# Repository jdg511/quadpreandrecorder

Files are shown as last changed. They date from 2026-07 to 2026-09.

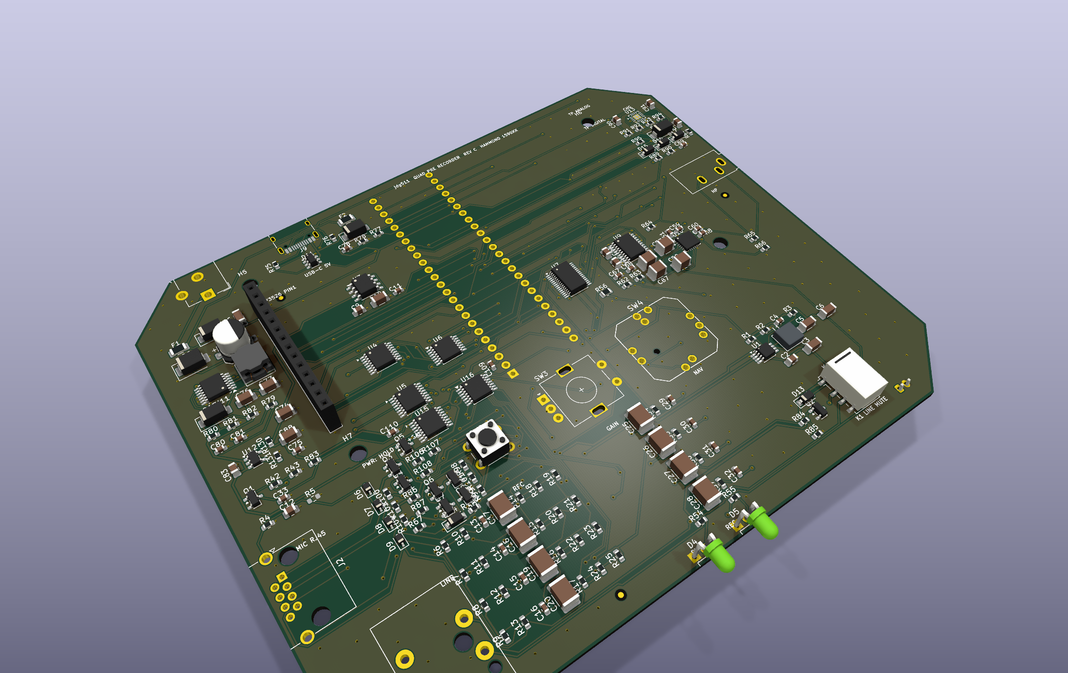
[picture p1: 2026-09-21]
hardware/exports/QuadPreRecorder-isometric.png

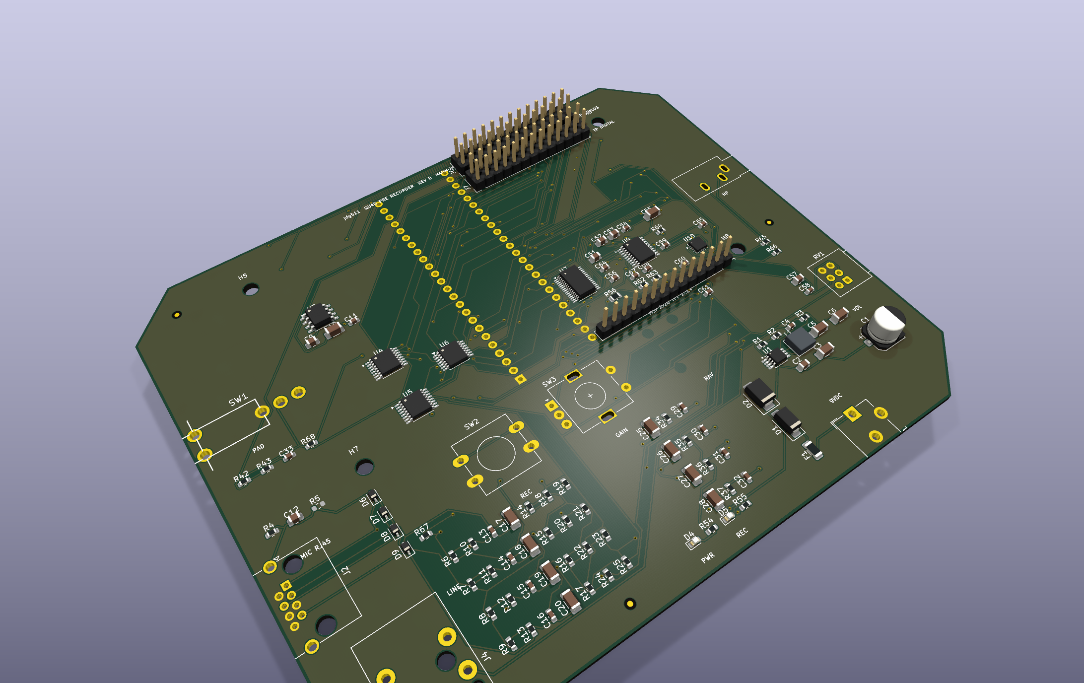
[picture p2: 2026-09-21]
hardware/review_outputs/noSW4-iso.png

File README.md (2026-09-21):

# Quad Preamp and Recorder

Compact four-channel ambisonic electret preamp, 192 kHz/24-bit recorder,
real-time binaural monitor, and touchscreen controller.

The hardware is derived from
[jdg511/Quadelectretpre](https://github.com/jdg511/Quadelectretpre) and is
redesigned as a mixed-signal two-layer PCB in a Hammond 1590XX enclosure.

## Project layout

- `hardware/` — KiCad project, fabrication package, design notes, and reviews.
- `tools/` — reproducible schematic, PCB, and fabrication-generation scripts.
- `firmware/` — recorder/DSP interface, pin map, file-naming rules, and
  implementation requirements. Production firmware is not included in Rev A.

## Revision status

The current design is **Rev C** (2026-09-08), routed for the compact
**Hammond 1590XX** (138 x 114 mm board, 145 x 121 x 39 mm enclosure). Rev C
takes the Rev B board and:

- adds a **USB-C** receptacle (J9) on the rear wall — 5 V power from any
  charger, power bank or computer port (TPS61175 boost + ADP7142 low-noise
  LDO make the 9 V analog rail), SD-card file transfer (MTP) and firmware
  updates; the 9 V barrel (J1) stays as an alternative input and moved to the
  rear-left wall;
- mutes the 1/4-inch line out with a signal relay (K1) while a computer is
  attached (ground-loop protection, on-screen warning with override);
- replaces the headphone pot with a **TPA6130A2** I2C-volume headphone amp
  (encoder / touchscreen control) and the pad toggle with a GPIO-driven
  level shifter (pad is a touchscreen control);
- changes the display to the LCDWiki **MSP3526** 3.5-inch IPS module with
  FT6336U **capacitive** touch (the MSP3520 named in Rev B is resistive).
- adds an internal **LiPo battery** (5000 mAh, 6-7 h) with a BQ24074 USB
  charger and a two-button soft-power gesture (hold RECORD + encoder push).

Walls: rear = SD slot + 9 V + USB-C, left = mic RJ45 (Amphenol RJHSE-5380),
right = headphones, front = line out; lid = display, record button, gain
encoder. Rev C3 (2026-09-12) removed the J6/J7 test headers (probe at
component pads or the TP3-TP14 pads), moved to a 4-layer SIG/GND/GND/SIG
stack, and made the mic input switchable from the screen: electret bias
off / 5 V / 9 V (one setting for all four channels) and, with the bias off,
the four RJ45 pairs become true balanced inputs for dynamic microphones
(two-op-amp instrumentation stage, +20.1 dB, SPICE-checked CMRR 58-67 dB
worst case across the audio band). The 9 V analog LDO is an ADP7142
(the TPS7A4701 it replaces had no distributor depth) and every BOM line
was re-checked for stock and price the same day. See
`hardware/reviews/audio-rules-check-revC3-fixes.md`, `hardware/mechanical.md`,
`hardware/connector-pinout.md` and `firmware/docs/REV-C-CONTROL-MODEL.md`.

ERC is clean and DRC (`--all-track-errors --schematic-parity
--severity-error`) reports 0 violations, 0 unconnected pads, 0 parity issues
on the routed board. The Gerbers, drills, BOM, placement CSVs, STEP and PDFs
in `hardware/manufacturing/` are regenerated from it
(`QuadPreRecorder-RevC-PCBWay-handoff.zip`). Rev B outputs are archived in
`hardware/manufacturing/revb-archive/`.

Still a human check before ordering: the physical Hammond 1590XX fit (wall
cutouts, button/shaft reach, the purchased MSP3526 module) — see
`hardware/enclosure-1590XX-desk-study.md` and
`hardware/reviews/rev-c-preorder-review.md`.

This is still new mixed-signal hardware, not a bench-proven production
revision. Read the prototype confirmations in `hardware/requirements.md` and
the order/bring-up notes in `hardware/manufacturing/README.md` before ordering.

## Rebuild

- `tools/route_pcb.ps1` regenerates the schematic/footprints/placement, runs
  Freerouting 1.9.0 (`tools/cache/freerouting19.jar`, single-threaded — the
  2.2.4 jar drops nets from its session export on this board), imports the
  route, adds the GND pours, and checks DRC. Allow ~35-60 minutes.
- `python tools/build_manufacturing.py` regenerates the complete PCBWay handoff
  with KiCad 10's command-line tools.

The checked-in routed board is the release artifact; rerouting is not required
to order it.

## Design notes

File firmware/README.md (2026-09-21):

# QuadPreRecorder firmware

**Illicit Apothecary** — firmware for the four-channel ambisonic electret
preamp and 192 kHz recorder.

Four electret capsules in a vertical tetrahedron → OPA1654 preamps → PCM1864
ADC → Teensy 4.1 → four mono 24-bit WAV files on microSD, plus a real-time
binaural monitor out of a PCM5102A.

---

## If you have never touched this before, read this bit

There are two things in this folder:

1. **The firmware** — C++ that runs on the Teensy 4.1 on your board.
2. **A simulator** — Python that runs on your computer and lets you *hear* the
   binaural monitor before the board exists.

You do not need to understand the C++ to use either one.

### Hearing the monitor today, with no hardware

```
cd sim
python3 simulate_binaural.py --scene orbit --out orbit.wav
```

Put on headphones and play `orbit.wav`. A click train circles your head twice.
That is the exact decode and HRTF maths the Teensy will run — same
coefficients, same sample rates. If you want to change how it sounds, change
it here first, where you get an answer in half a second instead of a reflash.

Other scenes: `--scene flyover`, `--scene corners`, `--scene static`.

### Running the firmware without a board

```
cd test/host
python3 run_tests.py
```

This compiles the **real firmware source** — the DSP and the recorder,
unmodified — for your computer and runs it. It checks that the monitor DSP
produces the same audio as the Python model (sample for sample), and that the
four-stream recorder survives a simulated microSD stall without losing
sample-alignment between the channels. See [test/README.md](test/README.md).

It cannot test anything electrical. That is what `bringup/` is for.

### Putting firmware on the board

Install [VS Code](https://code.visualstudio.com/) and the **PlatformIO IDE**
extension, then open this folder. The blue bar at the bottom has an
environment picker and an upload arrow. Pick an environment, press the arrow.

From a terminal instead:

```
pio run -e app -t upload      # the real firmware
pio device monitor            # watch what it says
```

**On a brand new board, do not flash `app` first.** Flash the bring-up tests
in order — `t01_power`, `t02_i2c`, `t03_controls`, `t04_sdbench`,
`t05_display`, `t06_audio` — and read [docs/BRINGUP.md](docs/BRINGUP.md).
Each test proves one subsystem and tells you, in plain language, which
component to look at when it fails. Debugging a bad solder joint through the
full firmware is miserable; debugging it through a fifty-line test is not.

---

## Environments

| Environment | What it is |
|---|---|
| `app` | The firmware. 192 kHz, four channels, dual-line I2S. |
| `app_96k_tdm` | Same firmware at 96 kHz over single-line TDM. Fallback if the 192 kHz path misbehaves on real silicon. |
| `t01_power` | Boots, blinks, checks every control pin's idle level. |
| `t02_i2c` | Scans I2C, configures the PCM1864, verifies registers. |
| `t03_controls` | Button, encoder direction and detents, pad switch. |
| `t04_sdbench` | **Run this before trusting any card.** Sustained four-stream write test with worst-case stall reporting. |
| `t05_display` | TFT colour/orientation, touch calibration targets. |
| `t06_audio` | Clocks, ADC lock, live four-channel levels, test tone, live monitor. |

## Layout

```
platformio.ini          build configuration, one environment per target
src/main.cpp            the application
bringup/                six standalone hardware tests
lib/qpr_board/          pin map (from the netlist) and build-time config
lib/qpr_pcm1864/        PCM1864 ADC driver
lib/qpr_sai/            SAI1 four-channel capture, SAI2 monitor output
lib/qpr_recorder/       four-stream WAV writer
lib/qpr_dsp/            decimator, ambisonic decode, binaural render, meters
lib/qpr_dsp/qpr_coeffs.h  GENERATED — do not edit, run sim/build_hrtf.py
lib/qpr_ui/             display, touch, front-panel controls
sim/                    the Python simulator and coefficient generator
test/host/              host test harness: runs the real firmware natively
docs/                   bring-up runbook, architecture, calibration
```

## Using it

**Front panel (Rev C board — see `docs/REV-C-CONTROL-MODEL.md`)**

- **RECORD button** — short press starts/stops. Long press (when stopped)
  clears the meters.
- **Encoder** — turn for gain, 1 dB per detent, all four channels together.
  By default that is all it does; Settings > Encoder can also enable
  **HP volume** and **Line trim** modes, which a short press then cycles
  through (long press = back to gain). Turning HP volume below the bottom
  step powers the headphone amp down (HP icon shows OFF).
- **PAD** — on-screen toggle, −9.7 dB ahead of the preamps (Rev C removed the
  panel switch). Folded into the displayed total gain and applied before the
  outputs un-mute at boot.
- **Touchscreen** — RECORD/STOP, HP on/off + volume, output trim ±, PAD,
  settings. Tapping the meters clears the peak holds.
- **Power** — on battery, hold RECORD and the encoder push together for
  2 s to switch on or off. Plugging in USB-C or the 9 V adapter switches it
  on by itself (the combo then puts it in standby). The screen shows the
  battery gauge, a plug when external power is present and a bolt while the
  internal LiPo is charging (USB only; about 7 h from empty).
- **USB-C** — powers the unit from any 5 V source, exposes the SD card to a
  computer (MTP) and takes firmware updates. While a *computer* is attached
  the 1/4-inch line out is muted by relay K1 and a banner explains why
  (ground loop); tap it to override. Chargers and power banks never mute.

**Both outputs are binaural.** There is one DSP chain and one DAC; the signal
splits in the analog domain after the reconstruction filter — one copy through
the mute relay to the 1/4 inch line jack, the other into the TPA6130A2
headphone amplifier (I2C volume, -59.5..+4 dB) and out the 1/8 inch jack. The
`OUT` trim on screen is digital and therefore moves both; HP volume moves only
the headphones. Press `o` on the serial console for a 1 kHz reference tone at
a known voltage to set line levels by.

**Serial console** (115200 baud) has everything the panel does, plus `s` for
a full status dump and `c` for the ADC's own view of the clocks. Press `?`.

**Files** land on the card as `FLU001.WAV`, `FRD001.WAV`, `BLD001.WAV`,
`BRU001.WAV` — one take, four mono 24-bit files at the capture rate. The next
take number is one higher than the highest number found on *any* of the four
prefixes, so an interrupted set can never be overwritten.

## Rev C3 hardware notes

The PCM1864's MICBIAS pin (5) is left unconnected and
its 1 uF cap is gone (capsules are biased from +9V_MIC). The driver should
power the mic bias down: page 3, register 0x15 (MIC_BIAS_CTRL), PDZ bit = 0.

## Mic mode (Rev C3, 2026-09-12): bias off / 5 V / 9 V and balanced inputs

Three Teensy GPIOs, all OUTPUT, all LOW at boot (the board defaults are
chosen so a Teensy that has not booted yet is safe):

| Pin | Net | High means |
|---:|---|---|
| 0 | MIC5_CTRL | +5V rail onto the mic bias filter (about 4.7 V at the capsules) |
| 1 | MIC9_CTRL | +9V rail onto the mic bias filter (9 V at the capsules) |
| 41 | COLD_CTRL | cold legs released into the differential stage (dynamic / balanced mode) |

The bias is one setting for all four channels. Settings > Microphone offers
exactly three choices and the firmware must drive the pins as a set:

| Setting | MIC5_CTRL | MIC9_CTRL | COLD_CTRL | PAD |
|---|---|---|---|---|
| Electret 9 V (default) | 0 | 1 | 0 | allowed |
| Electret 5 V | 1 | 0 | 0 | allowed |
| Dynamic (bias off, balanced) | 0 | 0 | 1 | forced OFF, greyed out |

Rules the firmware has to keep:

* Never set MIC5_CTRL and MIC9_CTRL high together (D24 would only protect
  the +5V rail; the 5 V FET would fight the 9 V one). Drive the new state
  as: both bias pins low, wait 50 ms, then raise the wanted one.
* Never set COLD_CTRL high while a bias pin is high, and never raise a bias
  pin while COLD_CTRL is high. Order when going to Dynamic: bias pins low,
  wait 200 ms for C66 (100 uF) to bleed through R104, then COLD_CTRL high.
  Order when leaving Dynamic: COLD_CTRL low first, wait 20 ms, then bias.
* The pad (Q1 / PAD_CTRL) only attenuates the hot leg. In Dynamic mode the
  cold leg is live, so an engaged pad would unbalance the pair by 9.7 dB
  and wreck the CMRR: force PAD off and disable the control while Dynamic
  is selected. Restore the user's pad choice when leaving Dynamic.
* Dynamic mics are 20-30 dB quieter than the electret capsules. Offer the
  gain range with an extra +20 dB of PGA (PCM1864 page 0, 0x01-0x04) in
  Dynamic mode and remember the two gain settings separately.
* Mute the outputs (DAC_MUTE, HP amp) for 300 ms around any mode change;
  the 4.7 uF input caps re-settle when the cold legs are switched.
* Store the mode in EEPROM with the other settings and re-apply it in the
  same order at boot, after the ADC is configured and before un-muting.

## The numbers that matter

| | |
|---|---|
| Capture | 192 kHz, 24-bit, 4 simultaneous channels |
| File payload | 2.304 MB/s total (576 kB/s per channel) |
| SD buffer slack | 128 ms per channel (3 × 24 KiB rings) |
| Monitor | 48 kHz stereo, exactly capture ÷ 4, no resampling |
| Binaural | 8 FIRs × 128 taps, ~25% of one Cortex-M7 |
| Clock source | one 786.432 MHz audio PLL feeds both SAI blocks |
| Gain range | −2 dB to +52 dB total (pad in), +8 to +52 dB (pad out); Dynamic mode adds +20 dB of PGA |

The capture and monitor rates come from the same PLL with integer dividers, so
the monitor is exactly one quarter of the capture rate forever. There is no
asynchronous sample-rate conversion anywhere and nothing to drift.

## What has and has not been proven

**Verified here, by running the actual code:**

- Every environment compiles clean for Teensy 4.1 and fits in flash and RAM.
- The real `qpr_dsp.cpp` was run natively and produces the same audio as the
  Python model to 4.5e-07, correlation 1.000000000 — both linear and 12 dB
  into the limiter. So tuning on the desktop describes the box.
- The real `qpr_recorder.cpp` was run against injected microSD stalls. A
  100 ms stall is absorbed at 78% buffer; a 400 ms stall loses exactly 273 ms
  (400 − 128) and loses it **collectively**, leaving all four files the same
  length and sample-aligned end to end.
- Everything it wrote opens in ffprobe as `pcm_s24le, 192000 Hz, mono`.
- The ambisonic maths passes its own self-test suite. The simulator produces
  correct localisation cues — ILD +7.4 dB, ITD 354 µs for a hard-left source.
- Every PCM1864 register value was checked against the TI datasheet.

Those tests found three real bugs: stale take numbering after `stop()`, and
the limiter's release coefficient losing precision in float32. Both fixed.

**Not verified, because it needs the board:** everything electrical — SAI
registers, eDMA, clock generation, I2C to the ADC, the display, the analog
path. The SAI sequences follow PJRC's proven IMXRT paths but with the sample
rate, word width and DMA element size changed, and no oscilloscope has been
near them. The 96 kHz TDM fallback is the least-exercised path in the project;
its frame-sync polarity is a judgement call, flagged in the source.

Read [docs/BRINGUP.md](docs/BRINGUP.md) before you power the board.

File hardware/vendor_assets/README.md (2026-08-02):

# Vendor CAD / mechanical assets

These files are third-party manufacturer or CAD-library assets collected for the
QuadPreRecorder KiCad mechanical-footprint pass. Keep the original vendor ZIPs
alongside extracted STEP/PDF files so the source package remains traceable.

| Ref | Project part | Files | Source / note |
| --- | --- | --- | --- |
| J1 | Same Sky / CUI Devices PJ-102AH | `PJ-102AH.step`, `PJ-102AH.pdf`, `PJ-102AH_SameSky_STEP_AP203.zip` | Same Sky official STEP generator and datasheet. The user-supplied SnapMagic ZIP `DCJ200-10-A-K1-K` is a GCT alternate, not the selected PJ-102AH part. |
| J4 | Neutrik NRJ6HF | `NRJ6HF.stp`, `NRJ6HF_datasheet.pdf` | Neutrik official product downloads. |
| J5 | Same Sky / CUI Devices SJ1-3533NG | `SJ1-3533NG.step`, `SJ1-353XNG.pdf`, `SJ1-3533NG_SameSky_STEP_AP203.zip` | Same Sky official STEP generator and SJ1-353XNG series datasheet. |
| RV1 | Alps Alpine RK097 family / RK0971221-F15-C0-A103 target | `RK0971221Z0X.step`, `RK0971221Z0X_reference_drawing.pdf`, `RK0971221Z0X_catalog.pdf`, `RK0971221Z0X_3dcad.zip` | Alps official RK0971221Z0X 3D CAD/reference package. Treat as family/base mechanical reference unless exact `RK0971221-F15-C0-A103` CAD is later obtained. |
| SW2 | Omron B3F-4050 | `B3F-4050.step`, `B3F_datasheet.pdf` | STEP downloaded from SnapMagic logged-in page; datasheet from Omron B3F series datasheet. |
| SW3 | Alps Alpine EC11E15244G1 | `EC11E15244G1.step`, `EC11E15244G1_reference_drawing.pdf`, `EC11E15244G1_catalog.pdf`, `EC11E15244G1_3dcad.zip` | Alps official EC11E15244G1 3D CAD/reference package. |

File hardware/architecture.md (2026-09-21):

# Hardware architecture

```mermaid
%%{init: {"flowchart": {"useMaxWidth": false, "nodeSpacing": 70, "rankSpacing": 110, "padding": 24}, "themeVariables": {"fontSize": "64px"}}}%%
flowchart LR
    MIC["RJ45/CAT6: four electret pairs + shield"] --> BIAS["Bias, RF protection, DC blocking"]
    BIAS --> PAD["Ganged four-channel -10 dB pad"]
    PAD --> PRE["OPA1654 quad JFET preamp, +20 dB"]
    PRE --> ADC["PCM1864 4-channel ADC/PGA, 192 kHz/24-bit"]
    ADC --> MCU["Teensy 4.1: meters, SDIO WAV writer, ambisonic DSP"]
    MCU --> SD["microSD: FLU/FRD/BLD/BRU numbered mono WAV files"]
    MCU --> TFT["2.8-inch ILI9341/FT6336G capacitive touchscreen"]
    MCU --> DAC["PCM5102A stereo DAC"]
    DAC --> LINE["1/4-inch binaural line out"]
    LINE -- "amplified duplicate" --> VOL["Dual audio-taper headphone volume"]
    VOL --> HP["TPA6132A2 + 1/8-inch binaural headphone out"]
```

## Throughput budget

Four packed 24-bit channels at 192 kHz require 18.432 Mbit/s, or 2.304 MB/s,
before filesystem overhead. Storing 32-bit words for DMA alignment increases
the internal/write-side stream to 3.072 MB/s. The Teensy 4.1 native SDIO port
has ample interface bandwidth, but the firmware must use large aligned buffers,
preallocation, and a qualified microSD card to avoid write-latency dropouts.

## Gain budget

The OPA1654 stage provides 20.1 dB. The PCM1864 PGA is set identically on all
four channels from -12 dB to +32 dB, producing 8 dB to 52 dB total gain. The
single encoder is digital, which avoids the tracking mismatch of a four-gang
analog potentiometer. The -10 dB pad shifts the effective range to -2 dB to
42 dB when enabled.

## Clock and data partition

- ADC: 192 kHz on two I2S data lines (PCM1864 DOUT + DOUT2 into Teensy SAI1
  quad input, 12.288 MHz BCK per line); single-line 256-BCK TDM is only
  viable at 96 kHz and remains the fallback mode.
- Monitor DSP: decimate to 48 kHz, apply calibrated tetrahedral decode and
  binaural FIR filters, then limit before DAC output.
- DAC: independent 48 kHz stereo I2S transmitter.
- Display/touch: SPI, updated below audio/SD interrupt priority.
- Control: I2C for PCM1864 registers; GPIO for record, pad sense, encoder, and
  headphone-amplifier enable.

## Grounding and shielding

The RJ45/CAT6 jack's metal shell is `CHASSIS`. It bonds directly to the metal
enclosure at the connector. `CHASSIS` couples to circuit ground through a
parallel 1 nF capacitor and 1 MOhm bleed resistor, with an optional 0 Ohm link
for EMC testing. Capsule returns are not tied to the cable jacket in the cable;
they join the quiet analog ground region on the PCB.

The two-layer layout uses a nearly continuous bottom ground plane. Switching
power, Teensy, display, and SD currents stay away from the input/preamp corner.
The ADC bridges the analog and digital placement regions without splitting its
ground reference plane.

The PCM1864 is the only variable-gain element. This is intentional: one encoder
changes a common digital register value, so the four channels do not suffer the
tracking error of a four-gang analog potentiometer.

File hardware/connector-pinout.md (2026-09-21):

# Connector pinout (Rev C, 2026-09-08)

Rev C changes from Rev B: an internal LiPo battery (J10) with a USB charger and a two-button soft-power latch; the 9 V barrel moved from the front wall to the
REAR-LEFT wall; a USB-C receptacle (J9) was added on the rear wall for 5 V
power, SD-card file transfer and firmware updates; the pad toggle (SW1) and
the headphone volume pot (RV1) are gone (both are screen/firmware controls
now); the display is the LCDWiki **MSP3526** 3.5-inch capacitive module; the
line output passes through a mute relay (K1). Everything else is unchanged.

## J2 — ambisonic microphone RJ45/CAT6 jack (left wall)

Shielded 8P8C jack, Amphenol RJHSE-5380. The mating cable is a standard
shielded CAT6 cord with an 8P8C plug. Viewed looking into the jack:

| Pin | Net | Cable function |
|---:|---|---|
| 1 | FLU_RAW | Front-left-up hot (signal, carries the bias) |
| 2 | FLU_RAWC | Front-left-up cold (return / balanced minus) |
| 3 | FRD_RAW | Front-right-down hot |
| 6 | FRD_RAWC | Front-right-down cold |
| 4 | BLD_RAW | Back-left-down hot |
| 5 | BLD_RAWC | Back-left-down cold |
| 7 | BRU_RAW | Back-right-up hot |
| 8 | BRU_RAWC | Back-right-up cold |
| SH (shell) | CHASSIS | Cable shield; bonds to the metal shell at both ends |

Rev C3 (2026-09-12): the four cold pins are no longer hard-wired to GND.
Each pair now lands on its own input (RAW = hot, RAWC = cold), both legs get
the same 100R / 100 pF / PESD12VL1BA RF protection, and a CD4053 switch
(U4/U5 spare section, U15) decides what the cold leg does:

* **Electret mode** (bias set to 5 V or 9 V, the power-up default): the
  switch grounds the cold leg on the board, so the capsule's bias current
  has a low-impedance return exactly as in Rev C. The bias rides on the
  hot leg through 4.7k.
* **Dynamic / balanced mode** (bias off): the switch opens and the cold leg
  feeds the second half of a two-op-amp instrumentation stage (U16 + the
  existing U6 unit), so the pair is a true balanced input: +20.1 dB, CMRR
  (SPICE, worst-case 0.1 % resistors, 300 ohm source) 67 dB from 100 Hz to
  1 kHz, 58 dB at 20 kHz, 56 dB at 50 Hz with the coupling caps at their
  10 % limits; input noise 18.8 nV/sqrt(Hz), EIN -109 dBu. Any passive dynamic mic wired pin
  2 hot / pin 3 cold onto one pair works; nothing on the board applies a
  voltage in this mode.

The mic bias itself is one global setting for all four channels (off, 5 V
or 9 V from the touchscreen; Q6/Q8 high-side switches into the R67/C66
filter). Never choose 5 V or 9 V with a dynamic mic plugged in.

Do not tie the shield to any cold leg inside the microphone. The PCB couples
CHASSIS to circuit ground through 1 MOhm and 1 nF; `R5` (DNP) can bond it
directly if EMC testing calls for it.

## J1 — 9 V DC barrel (rear-left wall)

CUI PJ-102AH, 5.5 x 2.1 mm, centre positive, regulated 9 V / 1 A adapter.
Pin 1 = +9V_IN, pins 2/3 = GND. Protected by a 750 mA PTC and OR'd with the
USB input through a Schottky. Either input alone runs the unit; with both
connected the barrel supplies the load.

## J9 — USB-C (rear wall)

HRO TYPE-C-31-M-12 16-pin USB 2.0 receptacle. 5 V only: CC1/CC2 carry 5.1 k
pull-downs (a 5 V sink), so any charger, power bank or computer port works
and no PD negotiation is needed. The board boosts 5 V to 10.45 V and then
regulates a clean 9 V analog rail, so the recorder runs fully from USB
(about 400-450 mA at 5 V).

| Pin(s) | Net | Function |
|---|---|---|
| A4, A9, B4, B9 | VBUS | 5 V in, 1.1 A PTC (F2) then OR-ing Schottky (D10) |
| A5 / B5 | USB_CC1 / USB_CC2 | 5.1 k to GND each |
| A6, B6 | USB_DP | D+ (through USBLC6-2SC6 ESD) to TP1 |
| A7, B7 | USB_DM | D- (through USBLC6-2SC6 ESD) to TP2 |
| A8, B8 | — | SBU, no connect |
| A1, A12, B1, B12 | GND | |
| SH | CHASSIS | Shell; same 1 MOhm / 1 nF bond as the RJ45 shell |

**Data path.** The Teensy 4.1's USB-device D+/D- are only available on its
micro-B connector and on two small pads on its underside (PJRC pinout card,
"USB Device": VUSB, D-, D+, next to pins 0/GND). Rev C brings J9's D+/D- to
two 2 mm pads on the board's BOTTOM side (TP1 = D+, TP2 = D-, just west of the
Teensy socket, about 18 mm from the SD end) so that two short wires (aim for
under 20 mm, kept together) join them to the Teensy pads before the Teensy is
plugged into its sockets. GND is shared through the socket pins. Never plug a
cable into the Teensy's own micro-B while J9 is in use — they are the same
two signals. Cut the Teensy's VIN-VUSB link (the board powers VIN from +5V).

**Firmware behaviour.** VBUS_SENSE (Teensy pin 15, 100 k / 47 k divider,
1.6 V at 5 V) tells the screen which supply is present. When the Teensy
enumerates as a USB device (a computer, not a charger, is attached) the
firmware energises the line-out mute relay K1 and shows a warning, because
computer ground + line-out ground = ground loop; a charger or power bank
never mutes. The user can override on screen. USB also carries MTP (SD card
appears as a drive) and Teensy Loader firmware updates.

## J3 — LCDWiki MSP3526 TFT / capacitive-touch socket

1 x 14 female socket (Sullins PPTC141LFBN-RC, 8.5 mm). The module's own male
header plugs into it; the module rides on 11 mm M3 standoffs (socket 8.5 mm
+ header body 2.5 mm — measure the real module before ordering standoffs).
Pin 1 is at the REAR end of the socket (board Y = 19.24), pin 14 toward the
front (Y = 52.26), socket at X = 25.0.

| Pin | Module name | Net | Pin | Module name | Net |
|---:|---|---|---:|---|---|
| 1 | VCC | +5V | 8 | LED | TFT_LED (100 Ohm from +5V) |
| 2 | GND | GND | 9 | SDO (MISO) | SPI_MISO |
| 3 | LCD_CS | TFT_CS (Teensy 10) | 10 | CTP_SCL | I2C_SCL (Teensy 19) |
| 4 | LCD_RST | TFT_RST (Teensy 7) | 11 | CTP_RST | CTP_RST (Teensy 14) |
| 5 | LCD_RS (D/C) | TFT_DC (Teensy 9) | 12 | CTP_SDA | I2C_SDA (Teensy 18) |
| 6 | SDI (MOSI) | SPI_MOSI (Teensy 11) | 13 | CTP_INT | TOUCH_IRQ (Teensy 22) |
| 7 | SCK | SPI_SCK (Teensy 13) | 14 | SD_CS | no connect |

Module facts (LCDWiki spec CR2023-MI2434 V1.0): 3.5-inch IPS 320 x 480,
ST7796U over 4-wire SPI, FT6336U capacitive touch over I2C, VCC 5.0 V with
on-board level conversion (3.3 V logic OK), backlight 95 mA, PCB 98.0 x 55.5
mm, mounting holes 92.0 x 49.5 mm (3.0 mm in from each edge, 3.2 mm), header
2.0 mm in from the left short edge. Verify the purchased module against this
before drilling the lid.

## J10 — battery (bottom side, front-right)

JST PH 2-pin (B2B-PH-K-S), pin 1 = VBAT (+), pin 2 = GND. Mates a 3.7 V
1S LiPo pouch, 906090 size (9 × 60 × 90 mm, 5000 mAh) **with its own
protection circuit (PCM)** and a JST-PH pigtail — check the pigtail's polarity
against the pin-1 marking, vendors are not consistent. The pouch lies on the
box floor under the right half of the board (x 80–140, y 15–105), clear of
the Teensy, held with foam tape. Charged from USB-C only (BQ24074, 0.74 A,
~7 h); the 9 V barrel runs the unit but does not charge. Runtime about
6–7 hours per charge at full brightness.

Power gesture on battery: hold RECORD + encoder push 2 s (on and off).

## TP1 / TP2 — USB data wire pads (bottom side)

TP1 = USB_DP, TP2 = USB_DM. 2.0 mm square pads at (56.5, 18.0) and
(56.5, 21.5), bottom side. Wire to the Teensy 4.1 underside "USB Device" D+
and D- pads (see J9).

## J6 / J7 test headers: removed in Rev C3 (2026-09-12)

The Rev B 2x13 analog and digital test headers are gone. They sat 6.5 mm apart
on the rear edge and forced all 20 analog stage nets and all 21 clock/bus nets
to cross the board side by side (audio-rule audit, check 2:
`hardware/reviews/audio-rules-check-revC2.md`). Probe any stage at its
component pads instead; every stage node has at least one 0603/1812 pad on
the top side of the channel rows. R68 (the 1 k PAD_DBG series protector)
went with them.

## TP3-TP14 probe pads (Rev C3, bottom side, 1.5 mm bare copper)

| Ref | Net | Position (mm) |
|---|---|---|
| TP8 | GND | 81.0, 36.5 |
| TP3 | ADC_MCLK | 84.5, 36.5 |
| TP4 | ADC_BCLK | 88.0, 36.5 |
| TP5 | ADC_LRCLK | 91.5, 36.5 |
| TP6 | ADC_TDM | 95.0, 36.5 |
| TP7 | ADC_DOUT2 | 98.5, 36.5 |
| TP13 | GND | 82.5, 42.2 |
| TP9 | DAC_BCLK | 86.5, 42.2 |
| TP10 | DAC_LRCLK | 90.5, 42.2 |
| TP11 | DAC_DIN | 94.5, 42.2 |
| TP12 | +3V3_DC | 84.0, 63.0 |
| TP14 | GND | 81.0, 59.5 |

The battery pouch lies under the right half of the board (x 80-140), so lift
it (or probe before fitting it) to reach the ADC and DAC rows.

## Teensy 4.1 pin map (Rev C)

| Pin | Net | Pin | Net |
|---:|---|---:|---|
| 2 | DAC_DIN | 22 | TOUCH_IRQ |
| 3 | DAC_LRCLK | 23 | ADC_MCLK |
| 4 | DAC_BCLK | 28 | REC_BUTTON |
| 5 | LINE_MUTE (K1 relay, high = mute) | 29 | GAIN_A |
| 6 | ADC_DOUT2 | 30 | GAIN_B |
| 7 | TFT_RST | 31 | GAIN_PUSH |
| 8 | ADC_TDM | 32 | PAD_CTRL (high = pad in) |
| 9 | TFT_DC | 33 | HP_ENABLE |
| 10 | TFT_CS | 34 | DAC_MUTE |
| 11 | SPI_MOSI | 35 | REC_LED |
| 12 | SPI_MISO | 36-40 | NAV_UP/DOWN/LEFT/RIGHT/PUSH (SW4, internal) |
| 13 | SPI_SCK | 14 | CTP_RST |
| 18 | I2C_SDA | 15 | VBUS_SENSE (analog, 1.6 V at 5 V) |
| 19 | I2C_SCL | 20 | ADC_LRCLK |
| 21 | ADC_BCLK | 24 | KEEP_ON (soft-power hold) |
| 16 | BAT_SENSE (VBAT/2) | 17 | CHG_STAT_N (charger /CHG) |
| 25 | PGOOD_N (charger /PGOOD) | 0 | MIC5_CTRL (high = 5 V mic bias) |
| 1 | MIC9_CTRL (high = 9 V mic bias) | 41 | COLD_CTRL (high = cold legs released, balanced/dynamic mode) |
| 26, 27 | unused | | |

I2C addresses on the shared bus: PCM1864 (ADR pin), FT6336U 0x38, TPA6130A2
0x60.

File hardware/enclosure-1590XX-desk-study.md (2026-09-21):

# Hammond 1590XX desk study — Rev B (2026-09-06), updated for Rev C (2026-09-08)

**Rev C update:** the 9 V barrel moved to the REAR-LEFT wall, a USB-C
receptacle sits on the REAR wall, the pad toggle (left) and volume pot
(right) are gone, and the display is the MSP3526 capacitive module on 11 mm
standoffs with its touch lens inside the lid window. The §3/§4 tables carry
the Rev C values; the Rev B rows are struck where they changed.

No 1590XX box was on hand when the Rev B board went order-ready, so this is
the paper half of the enclosure check, done against Hammond's dimensioned
drawing (`https://www.hammfg.com/files/parts/pdf/1590XX.pdf`) and the part
heights already established in the retired 1590F study
(`enclosure-stackup-and-templates.md`, same jacks / pot / switches). It is
enough to release the PCB; wall drilling still needs the real box and the
real parts.

## 1. Enclosure facts (Hammond 1590XX drawing)

- Outside 145.2 x 121.2 x 39.3 mm assembled; lid 2.0 mm thick with 4 x
  Ø4.1 screw holes. (The INSIDE LID view carries 137.07 / 121.78 and 97.7 /
  112.78 dimensions for the lid's inner rim and gasket land — use the box
  dimensions, not the lid, for anything that touches the PCB.)
- Cavity: 139.0 x 115.0 at the floor, drafting to 140.7 x 116.7 at the lid
  opening (~0.05 mm per side per mm of height). Inside height 35.2 mm floor
  to lid underside. Hammond's "max PCB 138 x 114" is the floor cavity minus
  1 mm.
- Four lid screws, 6-32 UNC, on a 135.0 x 111.0 pattern (5.1 mm in from the
  outer edges). Clear floor between the corner posts: 126.0 x 102.0. Post
  depth is not dimensioned — treat them as full-height columns until measured.
- No PCB standoffs or bosses. The board is carried by its wall hardware,
  which is what `tools/generate_pcb.py` assumes (no H1-H4).

## 2. Board outline vs the cavity and the posts

- 138 x 114 board: 0.5 mm per side at the floor, ~0.85 mm per side at the
  height it actually sits (section 3). OK.
- Corner posts: 135 x 111 screw pattern with 126 x 102 clear floor means each
  post is a ~Ø9 column (r ≈ 4.5) whose centre is ~1.5 mm inboard of the
  board edge in both axes. Distance from that centre to a 45° chamfer of
  size c is (c − 3)/√2:

  | Chamfer | Post-to-board clearance |
  |---|---|
  | 9 mm (as designed 2026-07-25) | **−0.26 mm** (interferes if posts are full height) |
  | 10 mm | +0.45 mm |
  | 11 mm | +1.16 mm (paper) / +0.5 mm measured on the STEP |
  | **12 mm (adopted 2026-09-06)** | **+1.0 mm measured on the STEP** |

  **Measured on Hammond's own STEP model (2026-09-06, later):** the posts
  are full height and their material ends **5.0 mm** along the board's
  corner diagonal, so 9 mm (clears to 4.5) interfered by 0.5 mm and 11 mm
  cleared by only 0.5 mm. `CORNER` in `tools/generate_pcb.py` is now
  **12.0** (1.0 mm clearance); 13 mm would clip J4's mounting pin at the
  front-left corner. The existing route needed no change (DRC 0/0/0 after
  re-import). Model probing also confirmed floor thickness 2.05 mm (inner
  floor at −33.15 from the rim), lid underside at +2.1, inside height 35.25.
  Interactive model: `enclosure-1590XX-fit-viewer.html` (Hammond STEP +
  board STEP + dimensioned placeholders for the parts without 3D models);
  Hammond's STEP is in `vendor_assets/Hammond-1590XX.step`. Nothing else lives in the corners — the nearest items are
  FID1/FID4 at (10, 8)/(12, 8) and J4's body at 8.3 mm from the left edge,
  which stays ~2.7 mm clear of the front-left post.

## 3. Height stack

Constraints (all heights above the board's top surface unless noted):

| Item | Height | Source |
|---|---|---|
| Teensy 4.1 (TEENSY41_PINS) in 2x Samtec SLW-124-01-G-S sockets, bottom side | ~11.7 mm below the board (4.57 socket + ~2.5 pin-header plastic + 1.6 PCB + ~2.9 tallest Teensy part); 13.0 if standard 8.5 mm sockets are used instead | Samtec / PJRC |
| C66 6.3 x 5.8 electrolytic, bottom | 5.8 below | BOM |
| J2 RJHSE-5380 RJ45 body | 13.7 above (tallest wall part) | Amphenol |
| SW3 EC11E15244G1 encoder, "H20mm" footprint | shaft tip ~20 above | KiCad footprint / Alps H dim — **verify** |
| SW2 B3F-5150 | plunger **7.3** above (CORRECTED 2026-09-09: this table and the schematic both said 17.5, which is wrong; the B3F-5xxx 12 mm series is a single 7.3 mm height) | Omron drawing |
| SW4 RKJXT1F42001 nav (Rev C2) | 17 x 17 x 10.5 mm body, shaft above that - **measure the real part**; replaced the SKQUCAA010 on 2026-09-11 | Alps / LCSC C160841 |
| TFT MSP3526 in the J3 socket on 11 mm standoffs (Rev C) | module PCB bottom 11.0 above (8.5 socket + 2.5 header body); lens top ≈ 11 + 1.6 + 2.5 + 0.5 + 0.8 ≈ 16.4-16.9 above — **verify** on the purchased module | LCDWiki spec V1.0 |
| USB-C J9 receptacle (Rev C) | 3.2 above, face 0.55 inside the board edge | HRO drawing |
| LiPo 906090 pouch on the floor (Rev C battery) | 9 mm above the floor under the RIGHT half (x 80..140, y 15..105); board underside is ~18.4 above the floor and the Teensy stack (x 58..79) reaches down to ~6.7 — the pouch must stay east of x 80 | pack drawing |
| J10 JST-PH (bottom, 121, 109.5) | 6 mm below the board; pouch lead exits toward it | JST |

With inside height 35.2:

- Bottom clearance ≥ 14 mm (Teensy + 1 mm) ⇒ board top ≥ 15.6 mm above the
  floor.
- RJ45 body must stay ≥ 1 mm under the lid underside ⇒ board top ≤ 20.5 mm
  above the floor.
- **Working window: board top 19.5-20 mm above the floor = 15-16 mm below
  the lid underside.** This is essentially the 1590F study's "15 mm below the
  rim" recipe, so its control-reach fixes carry over.

Reach vs a lid underside 15.5 mm above the board (2.0 mm lid):

| Part | Result | Action |
|---|---|---|
| J2 RJ45 (13.7) | 1.8 mm under the lid underside | OK; the wall cutout is a 16.5 x 13.5-ish rectangle — measure the real jack |
| SW2 B3F-5150 (**7.3**, corrected) | **8.2 mm SHORT of the underside**, not proud of it | The old "fit a ~4 mm keycap" plan was built on the wrong 17.5 mm figure and does not work. Options: a tall plunger cap, a lid-mounted button wired down to the pads, or a panel-mount switch. See `reviews/rev-c2-sourcing-report.md` section 3. |
| SW4 RKJXT1F42001 (Rev C2) | body 10.5, shaft above that | **The 2026-09-06 "no lid hole for SW4" decision is withdrawn.** That was forced by the SKQUCAA010's short stem with no knob available. The RKJXT has a proper knob shaft plus a rotary encoder, so it gets a lid hole after all: Ø8-9 at (91, 73.5), with a ~9-11 mm knob chosen once the real part is measured against the 15.5 mm lid gap. |
| SW3 encoder H20 | shaft ends ~2.5 mm outside the lid face — **too short for a knob set-screw** | swap to the 25 or 30 mm total-height EC11E variant (same footprint, BOM change only) or use a shaft extension. Confirm the H dimension on the Alps drawing for EC11E15244G1 first |
| TFT lens on 11 mm standoffs (≈16.4-16.9, Rev C) | 0.9-1.4 mm proud of the lid underside — i.e. inside the 2 mm lid window, lens face 0.6-1.1 mm below the outer lid face | intentional: near-flush touch surface. The lid window must clear the lens outline (85.5 x 56.0 cut for the 84.96 x 55.5 lens); the module PCB (98 x 55.5) stays 2.65 mm under the lid. Everything under the module must be < 11 mm: the tallest are the barrel jack (11.0, but it is outside the module's X range) and C1 (5.8) |
| Teensy stack | 19.5 − 1.6 − 11.7 ≈ 6 mm floor clearance | OK |
| microSD access | Teensy card slot is at the rear wall (design intent, `SD CARD SLOT THIS EDGE`); card plane ≈ 9-10 mm below the board underside ≈ 8-9 mm above the floor | cut a rear-wall slot at X ≈ 69; verify finger reach with the real Teensy — the card sits nearly flush with the Teensy edge, ~3.7 mm inside the wall's inner face. The Adafruit 6070 round extender needs a Ø30 mm hole and cannot fit a 35 mm-tall box with the PCB across it; if the direct slot is unreachable, use a slim flat-ribbon microSD extender through a rectangular rear-wall cutout |

## 4. Wall cutouts — what to transfer when the box arrives

Lateral positions come straight from the routed board (print
`exports/QuadPreRecorder-top.pdf` / `-bottom.pdf` at 100%, check the scale bar,
and transfer the real part centres — bushing/shell centres, not footprint
anchors; the July study lists which parts had that trap). Heights are board
top + the part's centreline height from its datasheet, with board top set
19.5-20 mm above the floor:

| Wall | Part | Board X or Y of the feature | Centreline above board (datasheet — **measure the real part**) |
|---|---|---|---|
| Left (x=0) | J2 RJ45 port | Y ≈ 69.3-85.8 fab extent, centre ≈ 77.5 | port spans ~1.5 to ~12 |
| ~~Left~~ | ~~SW1 toggle~~ | removed in Rev C (pad is on screen) | — |
| ~~Right~~ | ~~RV1 pot~~ | removed in Rev C (HP volume is on the encoder/screen) | — |
| Right (x=138) | J5 SJ1-3533NG nose | Y ≈ 41 | ~2.5-3 |
| Rear (y=0) | J1 PJ-102AH barrel (Rev C) | X ≈ 17.5 | ~6.5 (Ø ~6.5-7 hole; body 13-22 in X sits between the corner post and the display standoff H5) |
| Rear (y=0) | J9 USB-C (Rev C) | X ≈ 40 | centre ~1.6 above the board top; cut ~9.5 x 4.0 rounded (receptacle 8.94 x 3.26 face) |
| Front | J4 NRJ6HF bushing | X ≈ 16.2 | ~7.5-8.9 |
| Rear (y=0) | Teensy microSD slot | X ≈ 69 (below the board) | board underside − ~10 |
| Lid | SW2 / SW3 / SW4 / TFT window | (47, 73.5) / (69, 73.5) / **(91, 73.5), Ø8-9 for the RKJXT knob** / lens window 85.5 x 56.0 centred on (72.0, 35.75) | — |

Drill pilots first; open to final size only after a dry fit with the real
board and parts.

## 5. Physical checklist (with the box in hand)

1. Confirm the posts are full height (Hammond's STEP says they are) and that
   the bare board drops to ~15.5 mm below the rim without touching; the 12 mm
   chamfer should leave ~1 mm at each post.
2. Verify the 100 mm scale bar on the printed templates.
3. Dry-fit the bare PCB at depth; transfer any deviation to all wall heights.
4. Compare the purchased MSP3526 against its drawing (hole pattern 92.0 x
   49.5, header 2.0 mm from the left edge, pin length, lens 84.96 x 55.5,
   stack thickness) before cutting the lid window or buying standoffs.
5. Confirm the encoder height variant and how SW2 reaches the lid (its plunger
   is 7.3 mm, not the 17.5 mm this study used to claim, so it falls 8.2 mm
   short) before final lid drilling. SW4 DOES get a lid hole now that it is the
   RKJXT1F42001: size it to the knob, not the shaft.
6. Re-measure J4's bushing X on the current board before drilling the front
   wall. Rev C2 moved J4's anchor from x=22 to x=26 to clear the front-left
   corner post, so the "X ≈ 16.2" figure in section 4 predates that move.
7. Rev C: check the USB-C plug overmold clears the wall cutout (plug shells
   are ~6.5 mm long; the receptacle face is ~4 mm behind the outer wall
   face) and that a barrel plug seats fully at the rear-left corner.

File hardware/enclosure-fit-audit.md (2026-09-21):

**Rev C (2026-09-08) supersedes the wall table below:** SW1 (pad toggle) and
RV1 (volume pot) were removed; J1 (9 V barrel) moved to the REAR-LEFT wall at
X=17.5; J9 (USB-C) was added on the REAR wall at X=40; the display is the
MSP3526 (holes 92.0 x 49.5, socket J3 at X=25, Y 19.24-52.26). Current
positions: `mechanical.md`; enclosure reasoning: `enclosure-1590XX-desk-study.md`.

# Enclosure and panel-fit audit

Status: **Rev B / Hammond 1590XX — fully routed, DRC clean (2026-09-06).**
The design moved from the Hammond 1590F mechanical-fit prototype (Rev A) to
the compact 1590XX layout (Rev B) that `tools/generate_pcb.py` had carried
since 2026-07-25. On 2026-09-06 the last routing blocker was fixed (U7 moved
out of the Teensy socket's pin columns), the board was re-routed with
Freerouting 1.9.0, the GND pours were re-attached to the `GND` net, and the
PCBWay package was regenerated. What remains is the **physical** check
against a real 1590XX box — nothing below has been test-fitted yet.

Checked: 2026-09-06 (supersedes the 2026-07-24 1590F audit)

## Selected enclosure

Target metal enclosure: Hammond 1590XX.

- Official outside size: 145 x 121 x 39 mm.
- Official maximum PCB envelope: 138 x 114 mm.
- Rev B PCB outline: 138.0 x 114.0 mm — matches the 1590XX's PCB envelope
  exactly, with 12 mm chamfers cut at all four corners for the lid-screw
  posts.
- Reason: on 2026-09-05 the target enclosure was changed from the much
  larger 1590F (188 x 188 x 67 mm, 174 x 174 mm PCB envelope) to the compact
  1590XX. The generator script already had this Rev B layout built and dated
  2026-07-25; it just hadn't been reflected in any documentation or
  reconciled as the active design until now.

Reference:

- https://www.hammfg.com/part/1590XX

## Selected TFT

Target capacitive TFT module: LCDWiki MSP3520, 3.5-inch SPI module (ILI9341
or compatible controller) with FT6336G capacitive touch. (The 1590F-era
audit this replaces targeted the smaller 2.8-inch MSP2834 — Rev B uses the
larger 3.5-inch module instead.)

- Display: 3.5 inch, module 98.3 x 56.34 mm.
- Touch: capacitive, FT6336G over I2C.
- Mounting hole pattern: 93.3 x 51.34 mm at H5-H8, centered under the module.
- Connector: 14-pin, 2.54 mm header (J3).

Reference:

- https://www.lcdwiki.com/

## Current PCB panel-fit findings

Board outline: X=0.0 to 138.0 mm, Y=0.0 to 114.0 mm, corners chamfered 12 mm
(raised from 9 mm on 2026-09-06 after the desk study in
`enclosure-1590XX-desk-study.md`).
Positions below are read directly from the routed `QuadPreRecorder.kicad_pcb`
(2026-09-06); wall assignment is the design intent in `tools/generate_pcb.py`.

| Ref | Current routed placement | Status before physical stackup check |
|---|---|---|
| J2, ambisonic mic RJ45 (RJHSE-5380) | X=4.00, Y=74.00, Left wall, port ~flush | Present in copper, BOM and CPL. Re-audit clearance and shell/mating-plug fit against the real RJHSE-5380 part. |
| SW1, PAD -10dB toggle | X=2.20, Y=40.00, Left wall | Directionally correct; verify toggle bushing clearance against wall thickness. |
| RV1, dual-gang headphone volume | X=132.00, Y=82.00, Right wall | Directionally correct; verify shaft length and knob clearance. |
| J5, 1/8in headphone out | X=133.50, Y=41.00, Right wall | Directionally correct; verify jack nose and plug clearance. |
| J1, 9V barrel DC input | X=108.00, Y=105.80, Front wall | Directionally correct; verify barrel opening against wall thickness/cutout. |
| J4, 1/4in binaural line out | X=22.00, Y=97.00, Front wall, top side | Directionally correct; verify jack body and cable clearance. |
| J6 / J7 test headers | removed in Rev C3 (2026-09-12) | Nothing to fit. |
| SW2, record pushbutton | X=40.75, Y=71.00, top-mounted | Verify plunger height against lid standoffs. |
| SW3, master gain encoder | X=61.50, Y=71.00, top-mounted | Verify shaft length, nut/washer stack, and knob clearance. |
| SW4, TFT menu 5-way nav | X=91.00, Y=73.50, top-mounted, **internal only** | 2026-09-06: no lid hole — the 10 mm SKQU stem cannot reach the lid in the 1590XX and no extension is available; navigation is by the touch TFT + SW3 push. Reachable with the lid off. |
| TFT | H5-H8 at 93.3 x 51.34 mm pattern; J3 header at X=113.35, Y=63.00 | Verify the purchased MSP3520 module's mechanical drawing (or a physical sample) before drilling. |
| U8, Teensy 4.1 | X=60.00, Y=62.50, bottom side | SD/USB access at rear wall near X=69; verify clearance. |

Rev B has no H1-H4 board-mounting holes — the board is carried by its own
wall-mounted connectors and switches, not corner screws.

## KiCad validation after the Rev B re-route (2026-09-06)

- ERC: 0 errors, 0 warnings.
- DRC (`--all-track-errors --schematic-parity --severity-error`): 0
  violations, **0 unconnected pads**, 0 schematic-parity issues.
- Same-side courtyard overlaps: 0 (generator check).
- Panel orientation check (`tools/check_panel_orientation.py`): all pass.
- GND pours on both layers are on net `GND` (they were un-netted floating
  copper from 2026-09-05 to 2026-09-06 because `import_route.py` looked up
  `/GND`; fixed).
- Routing history: the 2026-09-05 board had 17 unconnected pads because U7
  (PCM1864) sat inside the Teensy socket's two THT pin columns; moving it to
  (83.5, 49.5) over its own decoupling caps cleared 16 of them, and switching
  from Freerouting 2.2.4 (whose .ses silently drops some nets) to 1.9.0
  cleared the rest.

## Remaining physical checks before manufacture

1. Import `manufacturing/QuadPreRecorder-RevB.step` into a mechanical CAD
   model of the Hammond 1590XX, or print `exports/QuadPreRecorder-top.pdf`
   and `-bottom.pdf` at 100% and test-fit the paper in the real box.
3. Confirm wall cutout centers and dimensions for J1, J2, J4, J5, and RV1
   using the real connector bodies, and the toggle bushing clearance for
   SW1.
4. Confirm lid standoff height so SW2, SW3, and the TFT reach through
   the top panel without being crushed.
5. Confirm the purchased MSP3520 module revision uses the expected 14-pin
   order and the 93.3 x 51.34 mm mounting pattern.
6. (J6/J7 test headers removed in Rev C3; nothing to route.)
7. Only then treat `manufacturing/QuadPreRecorder-RevB-PCBWay-handoff.zip`
   (regenerated 2026-09-06 from this board) as the order — see
   `manufacturing/README.md` and `reviews/rev-b-preorder-review.md`.

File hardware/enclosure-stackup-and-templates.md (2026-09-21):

# Hammond 1590F stackup study and drill templates — Rev A

**SUPERSEDED 2026-09-06.** The target enclosure changed from the Hammond 1590F to the compact Hammond 1590XX (Rev B), and the board outline changed from 174 x 174 mm to 138 x 114 mm with an entirely different wall layout (see `mechanical.md` and `enclosure-fit-audit.md` for the current Rev B placement). Everything below is a real physical stackup study done against an actual Hammond 1590F box and its drill templates — none of these measurements, corrections, or the companion PDF apply to the 1590XX. They are kept here only as a record of the method used, and as a reminder that a new stackup study against a real 1590XX box (with new drill templates) is required before drilling anything for Rev B. Do not use the `QuadPreRecorder-1590F-drill-templates.pdf` file for the current board.

---

## Original 1590F study (historical, retired 2026-09-06)

Date: 2026-07-25 (templates Rev 2, post-reroute). Companion file:
`QuadPreRecorder-1590F-drill-templates.pdf` (four 1:1 pages: left wall, right
wall, bottom wall, lid).

**TEMPLATES REV 2 — IMPORTANT.** Rev 1 of the PDF placed several wall features
on their footprint *anchor* (pin 1) instead of the true bushing/shell center,
and drew the bottom wall un-mirrored. Discard any Rev 1 prints. Corrections,
measured from the routed board's fab geometry: J2 DE-9 shell center 61.46 (was
67.0) — **NOTE: this is the OLD D-sub footprint; J2 is being replaced with an
Amphenol RJHSE-5380 shielded RJ45/CAT6 jack per the schematic, so this entire
J2 measurement is void until the PCB is regenerated with the new footprint and
re-measured against the RJHSE-5380's real shell geometry.** J6/J7 DB-25 shell
centers 138.38/48.38 (were 155/65 — 16.6 mm off),
RV1 shaft 164.5 (was 162.0), J4 bushing axis at board X 132.23 (was drawn at
the pad column, 7.2 mm off). The bottom wall now also carries J1 (9 V power,
moved off the left wall), and the left wall carries SW1, the pad toggle. The
lid pad-slide slot is gone.

**TEMPLATES REV 3 (2026-07-25, later the same day).** The record button (SW2)
and gain encoder (SW3) moved from the board's north edge to a control row
directly BELOW the TFT, and a new **SW4 ALPS SKQUCAA010 5-way navigation
switch** (TFT menus, Teensy pins 36–40) joined the row. Lid page 4 is redrawn
with true actuator centers measured from the routed board — Rev 2's lid page
had drawn SW2/SW3 on their footprint anchors (~6–7 mm off). Lid centers are
now: SW2 record (63.25, 95.5), SW3 gain (82.5, 95.5), SW4 nav (114.0, 95.5),
all Ø as printed. SW4's stem tops out ~6.5 mm below the lid; the plan of
record is a ~6.5 mm glued/3D-printed extension cap on its 3.2 mm square stem
(same reach-fix philosophy as the B3F-5150). Walls (pages 1–3) are unchanged.

**TEMPLATES REV 4 — external microSD access (no PCB change).** The recorder
writes to the Teensy 4.1's own card slot, which is buried under the board.
Plan of record: an **Adafruit 6070 round panel-mount microSD extender**
(~$9.50) — its 18 cm flex plugs into the Teensy's slot and its threaded
socket mounts through the **bottom wall at template u = 96.0, 34.0 mm below
the rim** (below the board, between J1 and J4). The 6070 accepts panels up to
16 mm; the wall is ~7.8 mm there. The template marks a pilot cross with a
NOMINAL Ø25 dashed circle — measure the real barrel before final drilling.
Two firmware notes: (1) cap the SDIO clock in SdFat if the extender is
marginal at full speed — even half speed leaves ~4x margin over the
3.07 MB/s recording budget; (2) card swaps are not hot-detected through the
extender, so re-mount the card from a menu action or on record-arm. Add the
6070 to the order list as an off-board part (it is not on the PCB BOM).

This is the desk-study half of the "physical enclosure stackup check" required
by `requirements.md` and `enclosure-fit-audit.md`. It uses the official Hammond
1590F drawing, the MSP2834 factory drawing, and manufacturer drawings for every
panel part. It does NOT replace holding the real box: the checklist at the end
still requires physical confirmation before drilling or ordering.

## 1. Enclosure facts (Hammond 1590F drawing, hammfg.com)

- Outer 188.0 x 188.0 mm, assembled height 67.0 (body 63.0 + lid stack 4.0).
- Floor thickness 2.5. Inside depth floor-to-rim ~60.5; floor-to-lid-underside
  62.0 (the lid underside sits ~1.5 above the rim plane).
- The cavity is heavily drafted: 178.5 sq at the rim tapering to 167.43 sq at
  the floor (~0.09 mm per side per mm of depth). Wall is ~4.75 thick at the rim
  and thickens toward the floor.
- 8 lid screws (6-32 UNC), centers 5.0 mm in from the outer edges (4 corners +
  4 mid-sides). They thread into bosses that intrude into the cavity; at the
  mouth the mid-side bosses narrow the opening to ~172.03 mm. Boss depth is not
  dimensioned by Hammond — measure it on the real box.

## 2. Where the 174.0 mm board can sit

Cavity width vs depth d below the rim: `W(d) = 178.5 − 0.183·d`.

| Side clearance | Max board-top depth |
|---|---|
| 0 (touching) | 24.6 mm |
| 0.25 mm | 21.9 mm |
| 0.50 mm | 19.1 mm |

So the board lives only in the top ~20 mm of the box. **Boss interference:**
the board (174.0) is wider than the mid-side boss opening (~172.03) and its
corners fall inside the corner-boss radius, so wherever bosses exist at board
depth the board needs four mid-side notches (~12 x 2 mm) and four corner
notches (~R6), OR the board must sit below the bosses. Measure how far the
bosses extend down; a 1/2-inch lid screw needs roughly 8–12 mm of boss.

## 3. Recommended stackup (board top 15.0 mm below the rim)

- Cavity width at board level 175.76 → 0.88 mm clearance per side.
- Board-top to lid-underside gap: **16.5 mm**.
- Floor standoffs under H1–H4: **43.9 mm** (stack spacers; H1–H4 land on the
  floor with ~3.7 mm margin to the sloped wall).
- TFT module standoffs (module-PCB underside above main-board top): **10.6 mm**
  puts the touch lens flush with the lid underside; window cut in the lid.
- If you change the 15.0 depth, every wall-template depth shifts by the same
  amount — the templates say this on each page.

Reach vs the lid underside (16.5 above the board):

| Part | Height above board | Result |
|---|---|---|
| SW3 EC11E encoder shaft tip | 24.5 | +8.0 through the lid — good for a knob (Ø8 hole; plain bushing, no nut) |
| SW3 bushing top | 11.5 | stays 5.0 below the lid — only the shaft penetrates |
| SW2 B3F-4050 plunger | 7.3 | **9.2 mm short — cannot be pressed** (finding C — RESOLVED: BOM is now B3F-5150, 17.5 mm plunger, ~1 mm into the Ø9 lid hole) |
| SW1 OS102011 slide actuator | 7.5 | **9.0 mm short — cannot be reached** (finding D — RESOLVED: SW1 is now an E-Switch 100SP1T1B1M7 toggle through the LEFT WALL, not the lid) |
| TFT lens on 10.6 standoffs | 16.5 | flush with lid underside |
| SW4 SKQUCAA010 nav stem tip | 10.0 | 6.5 short of the lid — fit a ~6.5 mm stem-extension cap through the Ø8 lid hole (Rev 3) |

## 4. Findings that needed action BEFORE ordering the PCB — ALL RESOLVED 2026-07-25

Status: **A, B, C and D are all fixed in the generators, the BOM, and the
rerouted board** (DRC clean, panel-orientation checker 8/8). The original
findings are kept below for the record; E and F remain bench checks.

**A (RESOLVED — H5–H8 now at 76.08 x 44.0 on the routed board).** The MSP2834 factory
drawing (QDtech V1.0) gives the module hole pattern as **76.08 x 44.0 mm**,
Ø3.2, with the pattern NOT vertically symmetric on the module (top holes 3.0
from the top edge, bottom holes 6.92 from the bottom edge). The board's H5–H8
are at **78 x 42** — off by ~1.9/2.0 mm, more than the screw slack. Move H5–H8
(and re-check J3's position/wiring to the module header) before ordering.

**B (SUPERSEDED — J2 is no longer a DE-9 at all).** This EU-vs-US DE-9 part-number
question (LD09S13A4GV00LF vs LD09S33E4GV00LF) is now moot: J2 has been changed to
a shielded 8P8C RJ45/CAT6 jack, Amphenol RJHSE-5380, per the schematic. The PCB
still has the old DSUB-9 footprint routed and must be regenerated with the
RJHSE-5380 footprint before ordering; new drill-template measurements for J2 are
needed once that's done, since the RJ45 jack's shell size/protrusion differs from
the D-sub.

**C (RESOLVED — BOM is now Omron B3F-5150).** The B3F-4050 plunger tops out
7.3 mm above the board against a 16.5 mm gap. Cleanest fix: swap SW2 to a
tall-plunger 12 mm switch in the same B3F family — **B3F-5150 (17.5 mm)** pokes
~1 mm into the Ø9 lid hole; add a keycap. Same footprint, no PCB change.

**D (RESOLVED — SW1 is now an E-Switch 100SP1T1B1M7REH right-angle toggle
through the left wall at board Y 96, with a custom project footprint; the lid
slot is deleted from the templates).** The old slide could not reach (7.5 vs 16.5 mm). Options:
treat the pad as a set-and-forget internal switch (open the lid to change it);
replace with a panel-mount mini toggle flown to the SW1 pads; or respin with a
tall-actuator slide. The lid template marks the slot DO-NOT-CUT.

**E. Board outline vs bosses** — see section 2; possible notches (PCB change if
the real box's bosses reach board depth).

**F. J3-to-module interconnect.** J3 is a male pin header and the MSP2834
ships with a male header (11.17 mm, on the module's back). Two males don't
mate, and at the 10.6 mm TFT standoff a soldered module header would collide
with the main board (−0.57 mm). Plan the interconnect explicitly: either fit
the module unpopulated and solder it onto J3's pins, or put a 14-pin female
socket on the board and check the mated stack height against 10.6 mm.

## 5. Findings to verify at the bench (no PCB change expected)

- **J4 nut engagement:** NRJ6HF bushing 8.9 long vs ~6.9 wall → ~2 mm of
  thread. Spot-face the wall outside ~1 mm if the nut won't seat, or run
  nutless (PCB-anchored).
- **D-sub shells:** mating shell projects 6.17 forward of the flange; with a
  ~5.5 mm wall the shells end near-flush with the outer face. Confirm cable
  plugs seat and jackscrews reach (2x Ø4 clearance holes are on the templates).
- **Barrel/phone jack recess:** J1 nose ends ~2 mm inside the wall — check the
  9 V plug seats; J5 nose ends ~1.5 mm inside — check headphone plugs seat.
- **RV1:** M7 bushing (5 mm) stays inside the wall — no nut, PCB-anchored;
  ~7 mm of shaft protrudes for the knob (Ø8 hole).

## 6. Physical checklist before drilling (with the real box in hand)

1. Verify the 100 mm calibration bar on every printed template page.
2. Measure boss depth below the rim at a corner and a mid-side; confirm the
   bare board drops to 15 mm depth without touching (notch if not).
3. Confirm rim-to-lid-underside offset (~1.5 mm) with the lid held on.
4. Dry-fit the bare PCB at depth; transfer any deviation to all wall depths.
5. Compare the purchased MSP2834 against the drawing (holes 76.08 x 44, lens
   69.2 x 50, thickness 5.9) before cutting the lid window.
6. Drill pilot holes first; open to final size only after re-checking against
   the assembled board.

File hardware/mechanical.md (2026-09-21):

# Mechanical reference (Rev C, 2026-09-08)

Everything below describes **Rev C**: the 138 x 114 mm two-layer board in the
**Hammond 1590XX** with 12 mm corner chamfers for the lid-screw posts
(validated against Hammond's STEP, see `enclosure-1590XX-desk-study.md`).
Rev C moved the 9 V barrel to the rear wall, added a USB-C receptacle on the
rear wall, removed the pad toggle (left wall) and the volume pot (right
wall), and changed the display to the LCDWiki MSP3526 capacitive module, and added an internal LiPo battery with USB charging and a two-button soft-power latch.

Coordinates use the KiCad datum at the board's upper-left as `(0, 0)`, X to
the right, Y downward. Frame convention: Y=0 faces the REAR wall (SD slot,
9 V barrel, USB-C), Y=114 the FRONT wall (line out), X=0 the LEFT wall
(mic), X=138 the RIGHT wall (phones).

The board has no corner mounting holes — it is carried by its wall-mounted
connectors (RJ45, 1/4-inch jack, 3.5 mm jack) and sits 19.5-20 mm above the
box floor (see the desk study for the height stack).

## Wall parts

| Ref | X (mm) | Y (mm) | Rot | Wall | Function |
|---|---:|---:|---:|---|---|
| J2 | 4.00 | 74.00 | 270 | Left | Ambisonic mic RJ45 (Amphenol RJHSE-5380), port ~flush with the wall |
| J5 | 133.50 | 41.00 | 270 | Right | 1/8 in binaural headphone out (CUI SJ1-3533NG) |
| J4 | 22.00 | 97.00 | 270 | Front (top side) | 1/4 in binaural line out (Neutrik NRJ6HF) |
| J1 | 17.50 | 8.20 | 180 | Rear-left | 9 V DC barrel (CUI PJ-102AH), nose 5.5 mm past the board edge |
| J9 | 40.00 | 4.20 | 180 | Rear | USB-C receptacle (HRO TYPE-C-31-M-12), face 0.55 mm inside the board edge, 3.2 mm tall |
| U8 | 60.00 | 62.50 | 0 | Bottom side | Teensy 4.1 on sockets (rows x = 60.0 and 75.24, 15.24 mm apart, corrected 2026-09-15); body x 58.7 to 76.5; SD slot + (unused) micro-B at the rear edge near X=68 |

Wall cutout centres are the part centres in the table plus the board's
height; see the desk-study wall-cutout table for sizes.

## Lid parts

| Ref | X (mm) | Y (mm) | Rot | Function |
|---|---:|---:|---:|---|
| SW2 | 40.75 | 71.00 | 0 | Record start/stop pushbutton (Omron B3F-5150), plunger at (47, 73.5) |
| SW3 | 61.50 | 71.00 | 0 | Gain encoder (Alps EC11E), shaft at (69, 73.5) — use the 25/30 mm-height variant |
| SW4 | 91.00 | 73.50 | 0 | 5-way nav (Alps SKQUCAA010), stem at (91, 73.5); internal only, no lid hole |
| Display | 23.0-121.0 | 8.0-63.5 | — | MSP3526 module envelope (98.0 x 55.5); touch lens 84.96 x 55.5 centred on the module |

## TFT mounting holes (M3, 3.2 mm)

| Ref | X (mm) | Y (mm) |
|---|---:|---:|
| H5 | 26.00 | 11.00 |
| H6 | 118.00 | 11.00 |
| H7 | 26.00 | 60.50 |
| H8 | 118.00 | 60.50 |

Pattern 92.0 x 49.5 mm, module centre (72.0, 35.75). The module plugs into
the J3 socket at X = 25.0, Y 19.24 (pin 1, rear) .. 52.26 (pin 14) and rides
on 11 mm standoffs (8.5 mm socket + 2.5 mm header body). With the board top
at 20 mm above the floor the touch lens ends ~36.9 mm up, i.e. inside the
2 mm lid window (lid underside 35.25, lid face 37.25) — a near-flush touch
surface. Verify the real module (pin length, hole pattern) before drilling.

## Internal parts worth knowing about

| Ref | X (mm) | Y (mm) | Side | Function |
|---|---:|---:|---|---|
| J3 | 25.00 | 19.24 | Top | Display socket 1x14 (pin 1) |
| TP1 / TP2 | 56.50 | 18.0 / 21.5 | Bottom | USB D+ / D- wire pads to the Teensy underside pads |
| U11 / L2 | 9.5 / 18.0 | 31.5 | Top | TPS61175 boost + 10 uH (left strip) |
| U12 | 9.50 | 50.50 | Top | ADP7142 9 V analog LDO (TSOT-23-5; was TPS7A4701 until 2026-09-12) |
| K1 | 113.00 | 103.50 | Top | Line-out mute relay (Omron G6K-2F-Y), front-right strip |
| U13 | 129.50 | 16.50 | Top | BQ24074 battery charger (rear-right strip) |
| J10 | 121.00 | 109.50 | Bottom | JST-PH battery connector, front-right |
| Q3 / Q4 | 30.00 | 67 / 71 | Top | Soft-power latch MOSFETs (RECORD + encoder push) |
| Battery | 80–140 | 15–105 | Box floor | 906090 LiPo pouch, 9 mm thick, under the right half (Teensy stack occupies x 58-77) |
| U10 | 112.00 | 56.00 | Top | TPA6130A2 headphone amp (I2C volume) |

Before drilling the Hammond box, print the top and bottom PDFs at 100%, fit
the bare PCB, and transfer the actual connector centres. The Rev C STEP
(`manufacturing/QuadPreRecorder-RevC.step`) is the source for CAD
interference checks; this table is not a panel template.

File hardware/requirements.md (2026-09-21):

# Requirements and assumptions (Rev C, 2026-09-08)

## Required behavior

- Capture four two-terminal electret capsules arranged as a vertical first-order
  ambisonic tetrahedron.
- Bring four signal/return pairs and one overall cable shield into one
  board-mounted 9-contact connector.
- Apply one matched -10 dB pad to all four channels, switched from the
  touchscreen/firmware (Rev C; Rev A/B used a panel toggle).
- Provide matched low-noise JFET-input gain with a maximum total gain between
  40 dB and 60 dB. One knob changes all four channels together.
- Convert four channels simultaneously at 192 kHz and 24 bits or better.
- Record four mono WAV files to microSD. Recording set `n` is named
  `FLUn.wav`, `FRDn.wav`, `BLDn.wav`, and `BRUn.wav`.
- Display four input meters and recorder state on a small TFT touchscreen.
- Decode the four-channel vertical-tetrahedral signal to stereo binaural audio
  in real time.
- Provide a board-mounted 1/4-inch stereo line output (with a relay mute
  that engages while a USB host is attached, to break ground loops) and a
  board-mounted 1/8-inch stereo headphone output with a digitally controlled
  headphone volume (encoder / touchscreen).
- Fit a standard Hammond enclosure on a two-layer PCB with board-mounted user
  connectors and controls.
- Run from either a 9 V barrel adapter or 5 V USB-C; expose the SD card over
  USB (MTP) and accept firmware updates over the same USB-C port.
- Run 5–6 hours from an internal rechargeable battery, charged over USB-C,
  switched on and off by holding RECORD and the encoder push together.
- Provide two internal test headers (analog and digital/control) for bench
  debugging. (Rev A specified these as panel-mounted DB-25 sockets; Rev B
  replaced them with internal 2x13, 2.54 mm headers — see the Rev B note
  below.)

## Decisions (Rev C column supersedes)

| Item | Rev A implementation |
|---|---|
| Microphone connector | Shielded 8P8C (RJ45/CAT6) jack, Amphenol RJHSE-5380, four twisted pairs plus shell |
| RJ45 pinout | Pins 1/2 FLU signal/return, 3/6 FRD signal/return, 4/5 BLD signal/return, 7/8 BRU signal/return; shell = CHASSIS (shield) |
| Capsule bias | Individually filtered +9 V bias through 4.7 kOhm; returns join quiet analog ground at the input |
| Pad | Four matched 68 kOhm/33 kOhm dividers selected by two CD4053B triple SPDT analog muxes; 9.7 dB nominal. Rev C: PAD_SELECT (0/9 V) driven by a 2N7002 level shifter from Teensy GPIO with a 10 k pull-up so power-up = direct |
| JFET stage | One OPA1654 quad FET-input op amp, 20 dB fixed analog gain |
| Gain control | PCM1864 four-channel PGA, programmed equally from one EC11 encoder; total range 8 dB to 52 dB including ADC PGA and fixed stage |
| ADC | PCM1864, four simultaneous channels, 192 kHz, 24-bit TDM output |
| Controller | Teensy 4.1 module, 600 MHz Cortex-M7, native 4-bit SDIO microSD, two I2S/TDM ports |
| DAC | PCM5102A stereo I2S DAC, operated at 48 kHz or higher |
| Headphones | Rev C: TPA6130A2 DirectPath stereo amplifier with I2C volume (-59.5..+4 dB, 64 steps) and software mute, fed from LINE_L/R; no pot. (Rev A/B: TPA6132A2 after a dual 10 kOhm pot) |
| Display | Rev C: LCDWiki MSP3526 3.5-inch IPS 320x480, ST7796U over SPI, FT6336U capacitive touch over I2C, 14-pin 2.54 mm header into a female socket on the board, 11 mm standoffs. (Rev B specified the MSP3520, whose touch is actually resistive/XPT2046) |
| Debug connectors | None (Rev C3). The Rev B internal 2x13 test headers J6/J7 were removed because they dragged every analog node across the board beside every clock; probe at component pads |
| Power | Rev C: 9 VDC centre-positive barrel (rear wall) OR 5 V USB-C (rear wall), Schottky OR'd into a TPS61175 boost (10.45 V, 1.2 MHz) feeding a TPS7A4701 ultralow-noise LDO for the 9 V analog rail and the TPS62160 5 V buck; low-noise 3.3 V analog LDO unchanged. USB draw ~400-450 mA at 5 V |
| Battery | 1S LiPo 906090 5000 mAh pouch with PCM on J10 (JST-PH), on the box floor under the right half. BQ24074 linear power-path charger from USB only: 0.74 A charge (ISET 1.2 k), 1.5 A input limit (ILIM 1.1 k, VIN-DPM), TS 10 k, no safety timer, thermal throttling. Battery feeds the boost through D14; ~6-7 h runtime |
| Soft power | RECORD + encoder push held together enable the TPS61175 (Q3/Q4 P-MOSFETs in series from VBAT to BOOST_EN); firmware latches KEEP_ON (Teensy 24) after 2 s; USB (D16) or barrel (D17) force the boost on. Switch nets are isolated from the Teensy inputs by D18/D19 so an unpowered Teensy cannot hold the latch |
| Line-out mute | Omron G6K-2F-Y DPDT signal relay between the reconstruction filter and J4; de-energised = audio passes, energised = jack grounded. Firmware mutes only while a USB host is enumerated (ground-loop protection) and shows a warning with an override |
| USB data | J9 D+/D- wired (two short wires) to the Teensy 4.1 underside USB-Device pads via TP1/TP2; MTP exposes the SD card, Teensy Loader updates firmware |
| Enclosure | Hammond 1590XX (since Rev B); Rev C walls: rear = SD slot + 9 V barrel + USB-C, left = mic RJ45, right = phones, front = line out; lid = display, record button, gain encoder |
| PCB | 138.0 x 114.0 mm, matching the 1590XX's official max PCB envelope, 12 mm corner chamfers; two copper layers; 1.6 mm FR-4; 1 oz copper; 0.20 mm minimum track; 0.15 mm minimum clearance; 0.40 mm finished via drill |

## Signal convention

The channel names are treated as physical capsule identities, not Ambisonic
B-format channels:

- `FLU`: front-left-up
- `FRD`: front-right-down
- `BLD`: back-left-down
- `BRU`: back-right-up

The exact tetrahedral A-format-to-B-format matrix, microphone polarity, capsule
azimuth/elevation, equalization, and binaural HRTF set are firmware calibration
data. Rev A preserves channel identity and simultaneous sampling so those
coefficients can be corrected without changing the PCB.

## Prototype confirmations required

- Confirm the microphone really presents four independent two-wire electret
  capsules. A balanced capsule or shared-return microphone requires a different
  input and bias network.
- Confirm each capsule's permitted bias voltage/current and polarity before
  connecting the microphone.
- Confirm the purchased LCDWiki MSP3526 display's 14-pin order, header
  position, pin length and 92.0 x 49.5 mm mounting-hole pattern before
  drilling the enclosure and ordering standoffs.
- Verify the soft-power latch: with no external power the unit must stay
  off until both buttons are held, and the BQ24074 case temperature while
  charging in the closed box.
- Verify the relay K1 NC/NO sense at bring-up (line out must pass audio with
  the coil de-energised) and the TPS61175 compensation with a load step.
- Confirm the two USB D+/D- wires to the Teensy underside pads enumerate at
  480 Mbit/s (fall back to full-speed in firmware if not).
- Confirm the mating CAT6 cable/plug (shielded, 8P8C) against the RJHSE-5380 jack before ordering the board.
- Benchmark the selected microSD card at four simultaneous 192 kHz/24-bit
  streams before a long recording session.
- Validate the real microphone geometry and binaural decoder with acoustic
  measurements; no fixed generic HRTF can guarantee an individualized result.

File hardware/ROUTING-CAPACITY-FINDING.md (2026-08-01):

# Rev 3 -> 4-layer conversion: status

**Date:** 2026-08-01

## Result

`QuadPreRecorder_rev3_4layer_routed.kicad_pcb` is a **4-layer board with 17 of
18 nets routed**, verified by `kicad-cli` DRC:

| Check | Result |
|---|---|
| Unconnected items | **1** (was 16) |
| DRC violations | 63 -- **all severity `warning`, zero errors** |
| Schematic parity | clean |
| Stackup (from pcbnew) | F.Cu / In1.Cu / In2.Cu / B.Cu |

The 63 warnings are 58 cosmetic silkscreen items and 2 hole-to-hole that were
already in the Rev 3 baseline, plus 3 `track_dangling` stubs left by the rip-up.

## Stackup

- **F.Cu** - signal (all original routing preserved)
- **In1.Cu** - solid GND plane
- **In2.Cu** - routing layer + GND pour
- **B.Cu** - signal (all original routing preserved)

Placement, footprints, board outline, Hammond 1590F fit and the Cat 6 jack (J2)
are **unchanged**. Only the stackup and the 18 nets differ.

## Why this was worth doing

On the 2-layer board these nets were forced into enormous detours. Same nets,
same placement, after adding the two inner layers:

| Net | 2-layer | 4-layer |
|---|---|---|
| ADC_TDM (192 kHz data) | 109.3 mm, 10 vias | **29.2 mm, 0 vias** |
| ADC_BCLK_IC | 108.5 mm, 9 vias | **49.3 mm, 2 vias** |
| ADC_DOUT2_IC | 103.7 mm, 9 vias | **49.9 mm, 2 vias** |
| ADC_MCLK_IC (24.6-49.2 MHz) | ~110 mm, 9 vias | **45.1 mm, 2 vias** |
| ADC_LDO | 126.2 mm, 9 vias | **23.8 mm, 2 vias** |
| GAIN_B | 116.9 mm, 5 vias | **47.2 mm, 1 via** |

Total: **847.5 mm over 17 nets with 34 vias**, versus roughly 1.6 m and ~120
vias on 2 layers. Every clock and data line now has a solid ground plane
directly beneath it.

## Cuts made (8 segments)

Two pads were physically stranded -- their only escape corridor was occupied by
another net, leaving 0.165 mm / 0.152 mm where 0.5 mm is required. Inner layers
do not help, because a 0.8 mm via cannot fit beside the pad either; the track
must escape laterally on the outer layer first.

- `+3V3_A` x=64.135 wall (1 seg) -- frees **U7.11 ADC_LDO**
- `HP_CPN` escape up the east side of U10 (4 segs) -- frees **U10.11 HP_CPP**
- `GND` diagonal at the U7 west neck (3 segs) -- safe, GND is carried by pours
  on F.Cu/B.Cu **and** the new solid In1.Cu plane

`HP_CPN` was rerouted (7.6 mm) and DRC confirms GND remains fully connected.

## The one open item: +3V3_A (U7 pin 8)

**This needs about a minute of hand-routing in KiCad.**

U7 pin 8 (`+3V3_A`) must run north-south past pin 11 (`ADC_LDO`), which must
escape west. **The two traces have to cross**, so one of them must change layer
in a ~1 mm corridor beside a 0.5 mm-pitch TSSOP. Only one via fits there, and
ADC_LDO has taken it.

Exhaustive search confirms no legal path for +3V3_A at 0.05 mm grid resolution
under a strict 0.15 mm clearance model. The margins are thin enough (a few
hundredths of a millimetre) that KiCad's interactive push-and-shove router,
which can place a via off-grid and nudge neighbours, will very likely succeed
where the grid-based search does not.

**To finish it:** open the board, select `+3V3_A`, and route from **U7 pin 8**
to the existing +3V3_A trace at **(64.294, 53.962)** -- about 3.7 mm south --
dropping to **In2.Cu** to cross under ADC_LDO's escape at y approximately 51.5.
Then re-run DRC; it should report 0 unconnected.

The 3 `track_dangling` warnings will also clear once this is routed (two of them
are the +3V3_A stubs themselves); the third is a 5.8 mm HP_CPN tail that can be
trimmed.

## Reproducing

`tools/autoroute/` contains the router (`arlib.py`), per-net driver (`step.py`),
exact analytic clearance validator (`validate.py`), minimal-cut search
(`autocut.py`) and the cut list (`ripup.py`). The geometry model was validated
against KiCad before use: pad positions 19/19 exact, board area exact, and net
connectivity reproducing KiCad's island count on all 16 nets.

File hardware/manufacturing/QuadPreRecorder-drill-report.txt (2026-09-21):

Drill report for QuadPreRecorder.kicad_pcb
Created on 2026-09-15T16:10:11

Copper Layer Stackup:
    =============================================================
    L1 :  F.Cu                      front
    L2 :  In1.Cu                    in1
    L3 :  In2.Cu                    in2
    L4 :  B.Cu                      back

Drill file 'QuadPreRecorder-PTH.drl' contains
    plated through holes:
    =============================================================
    T1  0.300mm  0.0118"  (185 holes))
    T2  0.400mm  0.0157"  (338 holes))
    T3  0.600mm  0.0236"  (4 holes)  (with 4 slots)
    T4  0.750mm  0.0295"  (2 holes))
    T5  0.890mm  0.0350"  (8 holes))
    T6  0.900mm  0.0354"  (4 holes))
    T7  1.000mm  0.0394"  (70 holes)  (with 3 slots)
    T8  1.100mm  0.0433"  (4 holes))
    T9  1.200mm  0.0472"  (10 holes))
    T10  1.500mm  0.0591"  (8 holes)  (with 2 slots)
    T11  1.570mm  0.0618"  (2 holes))
    T12  1.600mm  0.0630"  (3 holes))

    Total plated holes count 638

Drill file 'QuadPreRecorder-NPTH.drl' contains
    unplated through holes:
    =============================================================
    T1  0.650mm  0.0256"  (2 holes))
    T2  1.300mm  0.0512"  (1 hole)
    T3  2.000mm  0.0787"  (2 holes))
    T4  3.000mm  0.1181"  (1 hole)
    T5  3.200mm  0.1260"  (4 holes))
    T6  3.250mm  0.1280"  (2 holes))

    Total unplated holes count 12

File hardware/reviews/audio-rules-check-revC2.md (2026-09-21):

# Rev C2 audio-rule check against the routed board

Date: 2026-09-11
Board: `hardware/QuadPreRecorder.kicad_pcb` (Rev C2, routed, DRC 0 / ERC 0)
Tools: `tools/audio_audit.py`, `audio_audit2.py`, `audio_audit3.py`
Origin: the four checks raised by the pcbparts `misc/audio.md` design rules

## Verdict at a glance

| # | Check | Result |
|---|---|---|
| 1 | AGND / DGND pin handling on the three audio ICs | **PASS**, one layout defect (U10 exposed pad) |
| 2 | Clock / serial-audio to analog-signal separation | **FAIL**, and it is the worst problem on the board |
| 3 | Converter digital-rail filtering and decoupling | **FAIL**, decouplers are 2.4 to 11.7 mm from their pins, no ferrite beads anywhere |
| 4 | C0G in the signal path | **PARTIAL**, 12 signal-path caps are X7R or unspecified |

Nothing here is a reason to panic. Items 1, 3 and 4 are local edits. Item 2 is
the one that needs a real decision before anything gets fabricated.

---

## Check 1: AGND / DGND. PASS

Pin names confirmed from the symbol libraries, not assumed:

* PCM1864 (U7): pin 7 = AGND, pin 12 = DGND. Both on net `GND`.
* PCM5102A (U9): pin 3 = CPGND, pin 9 = AGND, pin 19 = DGND. All on net `GND`.
* TPA6130A2 (U10): pins 3, 9, 10, 13, 19 = GND, pin 21 = EP. All on net `GND`.
  Pins 15/16 = CPVSS correctly go to `HP_VSS`, not to ground.

This is exactly what the rule asks for: the pin labels describe blocks inside
the die, and every one of them returns to the single In1.Cu plane. No split,
no ground potential to worry about, no ESD-structure risk.

Plane access measured as distance from each ground pad to its nearest ground via:

```
U7   PCM1864       4 GND pads, worst 1.26 mm
U9   PCM5102A      7 GND pads, worst 0.96 mm
U10  TPA6130A2     6 GND pads, worst 2.55 mm   <-- the exposed pad
U2   TPS7A2033     1 GND pad,  0.88 mm
U3   TLE2426       1 GND pad,  1.20 mm
```

### Defect 1.1: U10's exposed pad has zero vias in it

The TPA6130A2 EP is 2.70 x 2.70 mm at (112.000, 56.000). Vias inside it: **0**.
The nearest ground via is 2.55 mm from the pad centre, which is 1.2 mm outside
the pad entirely.

On a WQFN DirectPath amp the exposed pad is both the main ground return for
the output stage and the only heat path off the die. Leaving it with no vias
means the amp's ground current has to leave sideways through the paste joint
and the pad's own copper, and the die runs hot into a 16 ohm load.

**Fix:** a 3x3 array of 0.30 mm drill / 0.60 mm annulus vias on a 0.9 mm pitch
centred on (112.0, 56.0). Cheap, no fab surcharge at that drill size, and
tented from the bottom so paste does not wick away. Nine vias is the usual
count for a 2.7 mm pad.

---

## Check 2: clock to analog separation. FAIL

This is the finding that matters.

### What was measured

Every routed segment on the 21 clock / serial-audio nets was compared against
every routed segment on the 38 analog nets. Perpendicular crossings were
discarded (they couple almost nothing); only runs within 25 degrees of parallel
were counted. The stackup matters here:

```
F.Cu      signal      0.21 mm to In1.Cu (a solid plane)   -> well referenced
In1.Cu    solid GND
In2.Cu    signal      1.07 mm to In1.Cu (across the core) -> poorly referenced
B.Cu      signal      0.21 mm to In2.Cu (a SIGNAL layer)  -> couples to In2
```

Because In1.Cu sits between them, F.Cu is shielded from both inner layers.
The exposed pair is **In2.Cu against B.Cu**, 0.21 mm apart with nothing in
between, and In2.Cu carries more routing than any other layer (41.8%).

### Result

```
total parallel clock-over-analog length, In2/B broadside : ~2100 mm
total parallel clock-to-analog length,   same layer      :  ~230 mm
366 parallel clock/analog net pairs
```

(The totals sum every overlapping segment pair, so they over-count where several
short segments track the same run. Treat them as a severity index, not a
literal length. The individual pairs below are the ones that matter.)

Worst offenders:

```
par_mm   gap_mm   aggressor      victim        mode
43.1     0.152    DAC_DIN        BLD_AC        same-layer
40.4     ~0.21    ADC_DOUT2      BLD_RAW       broadside In2/B
36.1     ~0.21    ADC_DOUT2      BRU_PRE       broadside In2/B
35.2     ~0.21    ADC_DOUT2      FRD_RAW       broadside In2/B
35.0     ~0.21    DAC_BCLK       FRD_RAW       broadside In2/B
33.6     0.202    DAC_DIN        FRD_ADC       same-layer
24.1     0.152    ADC_TDM_IC     BRU_ADC       same-layer
```

Also, on B.Cu the `ADC_LRCLK` track runs directly over the PCM1864's own
analog input pads (U7.1 through U7.6, including `ADC_MICBIAS` and `ADC_VREF`).
Those are shielded by In1.Cu so it is not fatal, but it is not where you want
the word clock.

### Why this is bad, in numbers

The victim nodes are high impedance. `_RAW` sits behind a 4.7k electret bias
resistor, so a few kilohms. `_AC` is loaded by the 1M bias resistor and the
68k/33k pad divider, so roughly 64k. Against that, 40 mm of 0.2 mm track
stacked 0.21 mm above another 0.2 mm track is on the order of 1.5 to 2 pF of
coupling.

Against maybe 10 pF of node capacitance to ground, a 3.3 V logic edge puts
roughly 2/(2+10) x 3.3 V, several hundred millivolts, onto a node carrying a
few millivolts of microphone signal. Even allowing a factor of ten for the
partial shielding from the In2.Cu ground pour and for my coupling estimate
being pessimistic, that is tens of millivolts of 12.288 MHz hash arriving at
the PGA input. A 192 kHz sampler folds that straight back into the audio band.

### The actual root cause: J6 and J7

The analog nets are absurdly long for what they are:

```
BRU_PRE  223.1 mm      BLD_RAW  196.8 mm
FRD_PRE  220.4 mm      BRU_ADC  181.6 mm
BRU_RAW  215.4 mm      FRD_AC   178.1 mm
BRU_AC   212.9 mm      FRD_RAW  176.9 mm
```

`BRU_PRE` is an op-amp output. It should be a few millimetres. It is 223 mm.

The reason is `J6`, the 2x13 analog test header at (82.0, 6.0). It brings all
five stages of all four channels (20 analog nets) to the top edge of the board,
while the analog circuitry lives at x 40 to 56, y 44 to 56. Every analog node
therefore makes a round trip across the board to reach it.

And `J7`, the digital test header carrying all 21 clock and bus nets, sits at
(82.0, 12.5): **6.5 mm away from J6**.

So the two headers force every sensitive analog node and every digital node
into the same corner, and make them travel the length of the board side by
side to get there. The analog nets span x 1.7 to 120.1 and y 1.1 to 108.2,
which is essentially the whole 138 x 114 mm board. Freerouting did not do
anything unreasonable; it was handed a netlist that demands this.

### Options, cheapest first

**A. Replace J6 with local test pads. Recommended.**
Drop the header and put a 1.5 mm test pad at each node, right where the node
already is. Zero added trace length, still probeable with a scope hook, and
roughly 1.9 m of analog copper disappears from the board. Cost: nothing, and
it frees the routing budget that option D below needs.

**B. Keep J6 but move it into the analog block** (somewhere around x 45, y 75,
under U4/U5/U6) and move J7 over to the digital side near the Teensy. Keeps
the convenience of one connector per domain, cuts most of the length, and puts
real distance between the two headers.

**C. Keep J6 where it is and isolate it.** Put a 1k series resistor in each of
the 20 test-point nets so the long run becomes a stub hanging off 1k instead
of part of the live node. 20 extra 0402s, roughly $0.60 in parts. This fixes
the antenna effect but not the fact that 20 analog runs still cross the board
alongside 21 digital ones, so it is a partial fix only.

**D. Make In2.Cu a solid ground plane and route on F.Cu and B.Cu only.**
This is the textbook mixed-signal 4-layer: SIG / GND / GND / SIG. Every trace
then has a reference plane 0.21 mm away, and there is no signal-to-signal
broadside adjacency anywhere on the board. It also fixes the separate problem
that In2.Cu currently has no usable reference plane at all (1.07 mm across
the core).

Feasibility: current routing is F 4.36 m, In2 5.01 m, B 2.62 m, total 12.0 m.
Two layers would need about 6 m each. B.Cu is only 21.9% utilised so there is
headroom, and doing option A first removes roughly 1.9 m of demand. Tight but
plausible. Worth one trial run of the pipeline before committing.

**E. Six layers.** Worth being straight with you here: when you asked about
going to 6 layers for AGND/DGND, the answer was no, and that is still correct,
splitting the ground plane would make things worse. But this measurement found
a *different* stackup problem, and 6 layers does address that one. A
SIG/GND/SIG/SIG/GND/SIG build gives all four signal layers a plane within
0.1 to 0.2 mm and puts the inner signal pair about 0.7 mm apart across the
centre core, instead of 0.21 mm.

Cost: 4-layer at this size is roughly $20 to $40 for five pieces from JLCPCB
or PCBWay. Six-layer is roughly $90 to $150 for the same five, with a longer
lead time and a stackup change that reopens the enclosure fit work.

My read: do A, then try D. If D will not route, then E is a legitimate
purchase rather than an over-spend. But do not buy layers before fixing J6,
because J6 is what is consuming them.

---

## Check 3: converter digital rails. FAIL

### 3.1 Decoupling capacitors are nowhere near their pins

Distance from each supply pin to the centre of its nearest same-net capacitor:

```
pin      net       function                nearest    distance
U7.8     +3V3_A    PCM1864 AVDD            C42 10uF     2.41 mm    (C41 100nF is 6.4 mm)
U7.13    +3V3_D    PCM1864 DVDD            C44 100nF    4.76 mm
U7.14    +3V3_D    PCM1864 IOVDD           C44 100nF    4.35 mm
U7.11    ADC_LDO   PCM1864 LDO out         C43 100nF    2.77 mm
U9.1     +3V3_A    PCM5102A AVDD           C54 100nF    5.77 mm
U9.8     +3V3_A    PCM5102A AVDD           C64 100nF    7.23 mm
U9.20    +3V3_D    PCM5102A DVDD           C63 100nF   11.72 mm
U9.18    DAC_LDO   PCM5102A LDOO           C53 1uF      7.56 mm
U10.12   +5V       TPA6130A2 VDD           C65 1uF      5.04 mm
U10.20   +5V       TPA6130A2 VDD_CP        C65 1uF      5.61 mm
```

The target is under 1.5 mm for a 100 nF, with its own via right beside the pad.
Every single one of these misses, and the DAC's DVDD pin misses by 8x.

Two things go wrong at that distance. The loop inductance roughly triples,
which drops the decoupler's series-resonant frequency and makes its impedance
climb steeply above about 20 MHz, so the IC's fast transient current is no
longer supplied locally. And that current instead travels several millimetres
through the rail and the plane, which is precisely the noise that check 2 is
already struggling to keep out of the analog nodes.

Also note U7.8: the 10 uF bulk cap is closer to the pin than the 100 nF. That
ordering should be reversed; small cap nearest, bulk behind it.

**Fix:** reposition each decoupler to within 1.5 mm of its pin, on the bottom
side directly beneath where possible, with its ground via at the cap pad. The
exact pad coordinates are now known and in `tools/audio_audit2.py` output, so
this can be scripted against `generate_pcb.py` rather than dragged by hand.

### 3.2 There is not a single ferrite bead on the board

`generate_schematic.py` defines an `FB` symbol at line 568 and never
instantiates it. Grep confirms zero bead parts in the BOM.

More to the point, `+3V3_D` is **the Teensy 4.1's own on-board 3.3 V
regulator output** (`3V3A`/`3V3B` on the module). That single rail feeds:

* the i.MX RT1062 running at 600 MHz
* the PCM1864's DVDD and IOVDD
* the PCM5102A's DVDD
* the I2C pull-ups and every button pull-up (R50, R51-53, R70-74, R94-97)

So the two converters' digital sections are hanging directly off the noisiest
node in the system, with no filtering at all between them.

`+3V3_A` is in much better shape: buck U1 to +5V, then LDO U2 (TPS7A2033) to
+3V3_A. That is the right topology and it should stay.

**Fix, in order of value:**

1. A ferrite bead in series with `+3V3_D` at each converter, with the 100 nF on
   the IC side of the bead. Something like a Murata BLM18PG221SN1D (220 ohm at
   100 MHz, 1.6 A, 0603), about $0.10 each. Two beads, one for U7 and one for
   U9. This alone confines each converter's switching loop to its own local cap.
2. Better still, feed both converters' digital rails from their own small LDO
   off +5V rather than from the Teensy. A second TPS7A2033 in SOT-23-5 plus two
   caps is about $1.20 and roughly 30 mm2. Given that this is a recorder whose
   entire reason to exist is the noise floor, that is cheap.

---

## Check 4: signal-path dielectrics. PARTIAL

Correct already:

```
C13-C16   100pF C0G    _MIC to CHASSIS        RF bypass
C21-C24   22pF  C0G    _PRE to _FB            op-amp feedback
C29-C32   10nF  C0G    _ADC to GND            anti-alias
C67 C68   2.2nF C0G    LINE_L/R to GND        reconstruction filter
```

Needs attention:

```
ref        value        path                        note
C17-C20    4.7uF 16V    _MIC -> _AC                 input coupling, dielectric unspecified
C25-C28    4.7uF 16V    _PRE -> _ADC_SRC            output coupling, dielectric unspecified
C57 C58    2.2uF X7R    LINE_L/R -> HP_IN_L/R       headphone input coupling
C86 C87    2.2uF X7R    HP_INP_L/R -> GND           headphone input reference
```

C17-C20 and C25-C28 are listed only as "4.7uF 16V" size 1206. At that value
and package they will be ordered as X5R or X7R by default, which is worth
fixing deliberately rather than by accident.

The real-world position: a 2.2 or 4.7 uF C0G does not exist in any sane package,
so C0G is not the answer here. What matters is how much signal voltage appears
*across* the cap, because Class II ceramic distortion scales with that. Three
practical routes:

1. **Oversize the ceramic.** Going from 4.7 uF to 22 uF X7R drops the signal
   voltage across the cap by about 5x at the low end, and distortion drops
   faster than linearly with it. Costs about $0.15 each and one package size.
   This is the lazy-but-effective option.
2. **PPS film.** Panasonic ECH-U or similar, 2.2 uF PPS is roughly $1.20 each
   and physically large (about 7 x 6 mm). Essentially zero voltage coefficient
   and no piezoelectric behaviour. Eight of these is about $10 and a real
   amount of board area you do not currently have.
3. **Bipolar electrolytic.** Nichicon MUSE ES 4.7 uF, about $0.50, small,
   well-behaved for coupling. The usual audio compromise.

For C57/C58/C86/C87 in the headphone path: the TPA6130A2's input impedance is
around 10k, so 2.2 uF gives a 7 Hz corner. Bumping those to 10 uF X7R (about
$0.10 each) puts the corner at 1.6 Hz and cuts the signal voltage across the
dielectric by more than 4x. Cheapest meaningful improvement in this section.

For C9/C10/C11 (the TLE2426 VREF rail) and C38/C39/C40 (MICBIAS and VREF):
these are bias rails, not signal path, so X7R is fine. They should still be
specified explicitly rather than left blank.

---

## Recommended order of work

1. **Decide the J6 question.** Everything in check 2 flows from it. Option A
   (local test pads) is my recommendation.
2. Reposition the decouplers (check 3.1). Scriptable against the pad
   coordinates now in hand.
3. Add the nine EP vias under U10 (check 1.1).
4. Add the two ferrite beads, or the dedicated digital LDO (check 3.2).
5. Specify the coupling-cap dielectrics (check 4).
6. Re-run the full pipeline, then re-run these three audit scripts and confirm
   the parallel-run numbers actually came down.

Steps 1 through 5 are all edits to `generate_schematic.py` and
`generate_pcb.py`, so they land in one rebuild.

## What is NOT wrong

Worth stating plainly, because the board is in good shape otherwise:

* Ground topology is correct. One net, one solid plane, 174/174 pads in a
  single connected cluster, per-pad fanout vias.
* AGND/DGND handling matches the rule exactly.
* The analog supply chain (buck to +5V, LDO to +3V3_A) is the right topology.
* PCM5102A configuration pins are all set correctly: SCK low for internal PLL,
  FMT low for I2S, DEMP low, FLT low.
* Series termination resistors (33R) are present on every clock and data line.
* DRC 0, ERC 0, 0 unconnected, 0 schematic parity issues.

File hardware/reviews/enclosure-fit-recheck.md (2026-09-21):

# Enclosure fit recheck, Rev C2 — 2026-09-11

Every part that penetrates a wall or the lid, measured off the routed board
rather than the hand-entered figures in `enclosure-1590XX-desk-study.md`, and
checked against real manufacturer drawings.

## The datum everything hangs off

From Hammond's STEP (see [[enclosure-fit-findings]]): cavity 139 x 115 at the
floor opening out to 140.7 x 116.7 at the rim over 33.15 mm. The board is
138 x 114 and sits 19.5-20 mm above the floor.

At that height the cavity is **140.0 mm wide**, so:

| | |
|---|---|
| board edge to INNER wall face | **1.00 mm** |
| wall thickness at board height | **2.60 mm** |
| **board edge to OUTER wall face** | **3.60 mm** |
| board top to LID UNDERSIDE | **15.50 mm** |
| board top to OUTER LID FACE | **17.50 mm** |

Positions below are board coordinates, read from `QuadPreRecorder.kicad_pcb`
by `tools/penetration_audit.py` and `tools/max_outward_move.py`.

## Verdict table

| Ref | What | Measured | Verdict |
|---|---|---|---|
| J1 | 9 V barrel, rear | mouth 5.50 mm past the board edge = **1.90 mm proud** of the outer wall | **FITS** |
| J2 | RJ45, left | face 4.25 mm past the edge = **0.65 mm proud** | **FITS** (see cutout note) |
| J4 | 1/4 in jack, front | nose 8.90 mm past the edge = **5.30 mm proud** | **FITS, but the nut does not** |
| J5 | 3.5 mm jack, right | nose 1.20 mm past the edge = **2.40 mm RECESSED** | **RISKY** |
| J9 | USB-C, rear | face 0.55 mm inside the edge = **4.15 mm RECESSED** | **FAILS** |
| SW2 | record button, lid | 7.3 mm vs 15.5 mm needed | **FAILS** |
| SW3 | gain encoder, lid | **24.5 mm** total = 7.0 mm of D-shaft proud | **FITS** (old study was wrong) |
| SW4 | 5-way nav encoder, lid | **17.4 mm** total, tip 0.1 mm below the outer lid face | **FAILS for a knob** |
| J3 | TFT lens, lid | 16.4-16.9 mm = 0.9-1.4 mm into the 2 mm lid window | **FITS** |
| D4/D5 | indicator LEDs, lid | 0603 flat on the board, 15.5 mm below the lid | **FAILS** (never solved) |
| U8 | Teensy microSD, rear | card plane ~9-10 mm below the board underside | needs a rear slot, unchanged |

## 1. J9 USB-C — the serious one

The receptacle's mating face sits 0.55 mm INSIDE the rear board edge, so it is
**4.15 mm behind the outer wall face**. A USB-C plug shell is ~6.5 mm long and
the receptacle cavity is 6.20 mm deep, so the shell has to travel 4.15 + 6.20 =
**10.35 mm** from the outer face. It only has 6.5 mm. **A cable cannot seat.**

Moving it out does not fix it on its own: the binding constraint is the
connector's own through-hole shield tabs (SH pads at y = 3.15, ø0.60 drill),
which allow a maximum outward move of **2.05 mm** before they run out of edge
clearance. That puts the face 2.10 mm behind the outer face — still short.

**Fix (verified, no collisions): move J9 -2.05 mm in y AND open the rear-wall
cutout to about 13 x 7.5 mm** instead of the 9.5 x 4.0 in the old study.
With the face 2.10 mm in, the shell needs 8.30 mm of travel, is 6.5 mm long,
so the plug's overmold (~12.4 x 6.65 mm) must enter **1.80 mm**. The wall is
2.60 mm thick, so it fits with 0.8 mm to spare.

If a big rectangular hole is unacceptable cosmetically, the alternative is a
panel-mount USB-C on a short pigtail to a header, which decouples the port
from the board entirely.

## 2. SW2 record button — no Omron fix exists

B3F-5150 is **7.3 mm** and that is the tallest 12 mm B3F Omron makes. The
tallest cap, B32-16x0, adds 4.2 mm for **11.5 mm total** — still 4.0 mm short
of the lid underside. The Omron family cannot reach; it has to be replaced.

The part must land 15-17 mm above the board. Options, cheapest first:

| Part | Mfr | Height | Life | Stock | Price 1/100 |
|---|---|---|---|---|---|
| **TS02-66-150-BK-160-LCR-D** | Same Sky | **15.0 mm** | 80 k | 3,418 Mouser | $0.13 / $0.097 |
| TL1105YF160Q | E-Switch | 16.3 mm | - | 33,463 Mouser | $0.31 / $0.234 |
| SKHHDHA010 | Alps Alpine | 17.0 mm | **500 k** | 1,958 Mouser | $0.35 |
| KH-6X6X17H-TJ | Kinghelm | 17.0 mm | - | 18,463 LCSC | $0.025 |
| 5ETH935 + 1SS09-16.0 | APEM/MEC | 16.0 mm | 10 M, IP67 | in stock | ~$3.70 |

All of the 6 x 6 parts share the standard 4-pin 6.5 x 4.5 mm grid on ø1.0 mm
holes, which is KiCad's `Button_Switch_THT:SW_PUSH_6mm` — one footprint covers
every height, so the choice can change late.

**Recommended: Same Sky TS02-66-150-BK-160-LCR-D.** Named manufacturer with a
real datasheet, 15.0 mm leaves 0.5 mm of over-travel under the lid, and it is
1/38th the cost of the APEM combination.

**Verified placement:** footprint `SW_PUSH_6mm` anchored at **(43.75, 71.25)**
puts the plunger at exactly **(47.00, 73.50)**, on the existing control-row
line with SW3 and SW4, and collides with nothing.

**Do guide the stem through the lid hole** (drill ~ø3.6-3.8 mm). A 15 mm stem
on four 1 mm pins is a lever; let the lid take the side load, not the solder
joints. That is the only thing the expensive APEM part really buys you.

## 3. SW3 gain encoder — a false alarm, it was always fine

The old study said the shaft ends ~2.5 mm outside the lid and was "too short
for a knob set-screw", and recommended buying a 25 or 30 mm variant.
**That was wrong and no part change is needed.**

`EC11E15244G1` is **24.5 mm above the PCB seating plane** (body 4.5 + boss 7 +
shaft 13), which leaves **7.0 mm of shaft proud of the outer lid face**. The
shaft is ø6 mm with a single flat, 4.5 mm across the flat, and the flat starts
14.5 mm above the board — 1 mm below the lid underside — so the whole exposed
7 mm is D-flatted. Any 6 mm D-bore or set-screw knob fits.

The "H20mm" in the KiCad footprint name is Alps' *actuator length* column, not
a height above the board. That is where the bad number came from.

## 4. SW4 nav encoder — fits the hole, but there is nothing to hold

Total height **17.4 mm**, so the shaft tip finishes **0.1 mm below the outer
lid face**. It fills the hole and stops. The shaft is ø2.5 mm with a 1.8 mm
flat and only ~6.9 mm of it stands above the body.

There is no taller variant. **RKJXT1F42002 does not exist** — checked against
Alps' product page, the Alps multi-control catalog, the RKJXT datasheet,
Mouser, DigiKey, LCSC and Octopart. It has been removed from the BOM, where
this file previously listed it as an alternate. Alps publishes no knob for
this part either; no catalogue knob goes below a ø3 mm bore.

**Fix: a custom cap.** ø2.5 mm bore with a 1.8 mm flat, ~5 mm of engagement on
the shaft, a disc or dome top 8-10 mm across standing 2-4 mm proud. 3D printed
is fine. That restores all three functions — tilt, press and twist — because
twisting the cap twists the shaft.

**Lid hole ~ø5.5 mm.** The lever tilts 9 degrees about the top of the body, so
at the lid (7 mm of lever arm) the shaft sweeps 7 x sin(9 deg) = 1.10 mm each
way. ø2.5 + 2 x 1.10 + clearance.

Worth noting: SW4's rotary ring duplicates SW3's, so even if the cap is only
ever used as a thumb pad, no function is lost.

## 5. J5 3.5 mm headphone jack — recessed, and it is not a panel part

The nose tip sits **2.40 mm behind the outer wall face**, so a plug gives away
2.4 mm of its travel before it even reaches the jack. The SJ1-3533NG has no
thread and no bushing — Same Sky does not list it as panel-mountable — so
there is nothing to clamp and nothing to take the insertion force but the
solder joints.

This is the classic cause of a plug that clicks into its detent but lands the
tip contact on the wrong conductor: intermittent, mono, or swapped channels,
and it varies by plug brand because moulded consumer plugs have fatter,
more sharply stepped handles than a slim Neutrik/Rean barrel.

**Fix (verified, no collisions): move J5 +2.40 mm in x.** The nose then
finishes flush with the outer wall face. Its binding pad allows up to 3.30 mm,
so there is margin. Wall hole ø6.5-7.0 mm to clear the ø6.00 mm nose.

## 6. J4 1/4 in jack — the jack fits, the nut does not

The nose stands 5.30 mm proud of the outer wall, which is plenty of 3/8-32
thread for a nut. The problem is what the nut has to clamp.

The bushing shoulder sits at the board edge, and from there to the outer wall
face is 1.00 mm of air plus 2.60 mm of wall = **3.60 mm**. Neutrik specifies
a **maximum panel thickness of < 3.0 mm**. Tightening a nut on that stack
either exceeds the spec or pulls the jack outward against its solder joints.

**Fix (verified, no collisions): move J4 +1.00 mm in y.** The bushing shoulder
then seats against the inner wall face and the nut clamps only the 2.60 mm
wall, inside spec, with the wall properly carrying plug insertion force
instead of the PCB. Its binding pad allows 2.50 mm, so 1.00 mm is safe.

Also note: **the nut is not supplied.** Order one — NRJ-NUT-B (plastic hex),
NRJ-NUT-MK (knurled ring), NRJ-NUT-MS (ring) or NRJ-NUT-MN (metal hex).
Panel hole is 11.2 mm per Neutrik, though that does not reconcile with a
3/8-32 thread (9.53 mm major) and is worth confirming before drilling.

## 7. D4/D5 indicator LEDs — never solved, and 0603 cannot be made to work

Two 0603 top-firing chip LEDs lie flat on the board 15.5 mm below the lid with
nothing between them and it. As drawn they are invisible from outside. There
is no mention of light pipes anywhere in the design.

**0603 is too small to couple into any light pipe long enough to cross the
gap.** Every rigid board-mount pipe in that length class is specified for a
PLCC-2 class emitter: VCC VBL wants 3.0 x 3.0 x 2.0 mm, Dialight 515 VBM wants
PLCC-2/PLCC-4, Bivar LPV3 has a 3.8 mm square window. Feeding a 3 mm entrance
face from a 1.3 mm2 emitter over 15 mm of polycarbonate gives a dim dot.

Three honest options, none free:

1. **3 mm THT LEDs in Bivar LTM-600 spacers (15.24 mm).** Cheapest optically
   and mechanically; the spacer uses the LED's own two lead holes so no extra
   mounting holes are needed. Lid drilled ~ø3.6 mm. LTM-600 was 0 stock at
   Mouser on 2026-09-11; LTM-500 (12.7 mm) is 5,365 in stock.
2. **Stay SMD: PLCC-2 LEDs + VCC VBL3D0700C (17.78 mm, $0.51/100).** Keeps the
   board reflow-only. Requires changing both LED footprints AND adding the
   pipe's press-fit holes.
3. **Move the indicators to the front wall** alongside J4, using right-angle
   THT LEDs. Avoids the lid entirely.

**All three need local re-placement.** D4/D5 sit in a tight cluster with R37,
R54, R55 and C28; a 3 mm THT LED at either position overlaps its own series
resistor. This is a small placement job plus a re-route, not a drop-in.

## 8. Build-sequence issue worth thinking about before drilling

Five of the six wall connectors protrude past the board edge by more than the
1.00 mm of clearance to the inner wall: J4 by 8.90, J1 by 5.50, J2 by 4.25,
J5 by 1.20 (2.40 after the fix above), J9 by 1.50 after its fix. That means
**the board cannot be lowered straight down into the box** with closed holes on
four walls — the connectors have to pass through as it descends.

The usual answers are to file the tall cutouts open to the rim on one wall, or
to make them generous and tilt the board in. Worth settling before any metal
is cut, because it changes how the holes are shaped.

## Change list

Board changes, all verified collision-free against the routed board:

| Ref | Change |
|---|---|
| J9 | move -2.05 mm in y; rear cutout becomes ~13 x 7.5 mm |
| J5 | move +2.40 mm in x |
| J4 | move +1.00 mm in y |
| SW2 | footprint 12 mm -> `Button_Switch_THT:SW_PUSH_6mm`, anchor (43.75, 71.25); part -> Same Sky TS02-66-150-BK-160-LCR-D |
| D4/D5 | LED package change plus local re-placement of R37/R54/R55/C28 |

No change: J1, J2, SW3, SW4 (part), J3.

Buy list additions: a Neutrik NRJ-NUT-x, a custom cap for SW4, LED spacers or
pipes, and the new SW2.

Lid drilling: SW2 ~ø3.6-3.8, SW4 ~ø5.5, SW3 per the knob, LEDs per the option
chosen. The J4 front-wall X in the desk study predates the Rev C2 move and
must be re-measured.

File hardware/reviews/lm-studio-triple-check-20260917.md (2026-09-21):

# Triple check by a local model (LM Studio), 2026-09-17

Jason asked for an independent look at the layout and components by the local model in LM Studio. This note records how it was run, everything the model raised that was worth checking, and what the real schematic and board data say about each item. Nothing here changes the board; two wording fixes went into the dossier and two items were added to the Rev D list.

## How it was run

Model: `qwen/qwen3.8-27b` on the StudioA machine, called through LM Studio's local API (the bridge tool's 60 s limit is too short). The model was given 17 packets cut from the review dossier (power tree and rail membership, set-point arithmetic, each IC's pin table, transistors and diodes, connectors, the Teensy map, the analog channel, decoupling and net lengths, the board and DRC, the BOM) and asked for ranked findings, with the instruction not to recall pinouts from memory because the pin tables had already been checked against the datasheets. Its thinking mode had to be bypassed (with it on, the 27B model spent its whole budget reasoning and never answered; `openai/gpt-oss-20b` answered fast but generically). Raw answers: `review_outputs/lm/out/*.txt`. Each run took 1 to 2.5 minutes per packet.
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

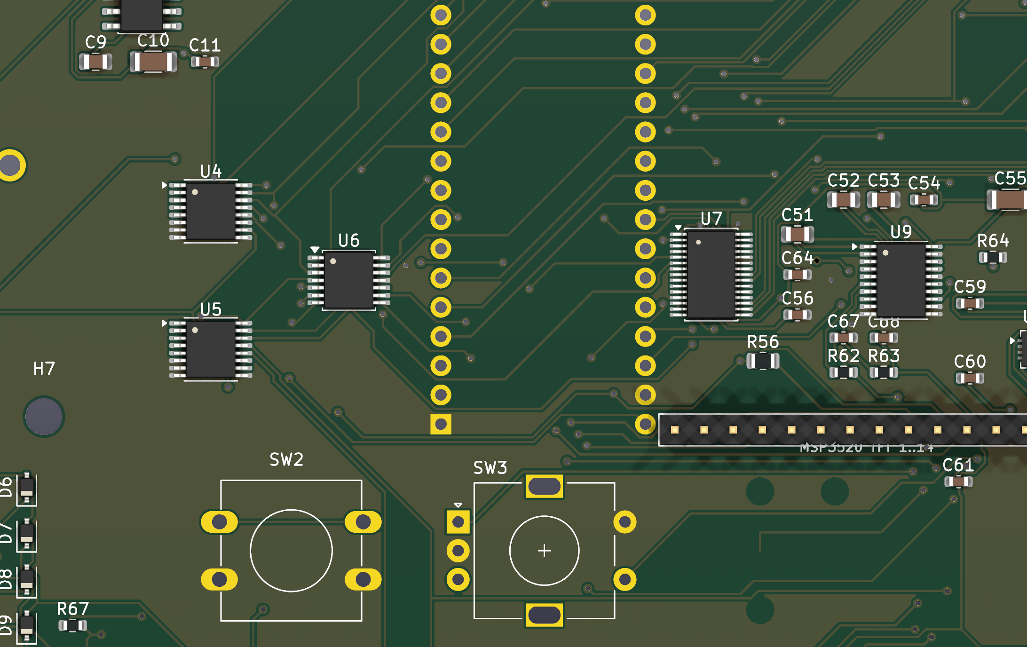
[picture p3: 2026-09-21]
hardware/review_outputs/noSW4-controlrow.png

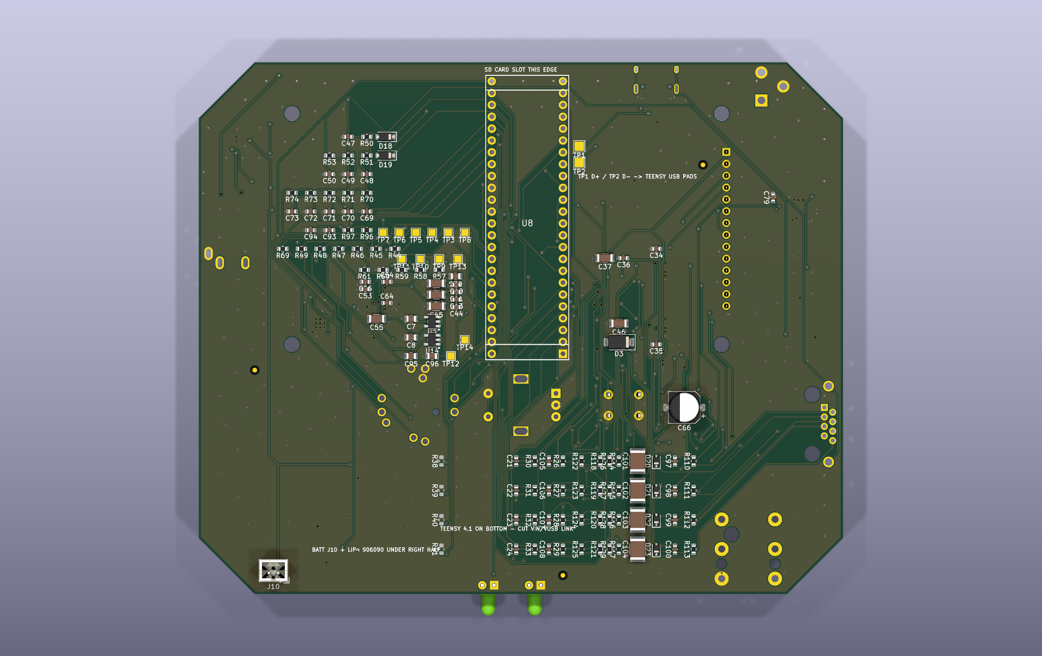
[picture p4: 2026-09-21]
hardware/exports/QuadPreRecorder-bottom.png

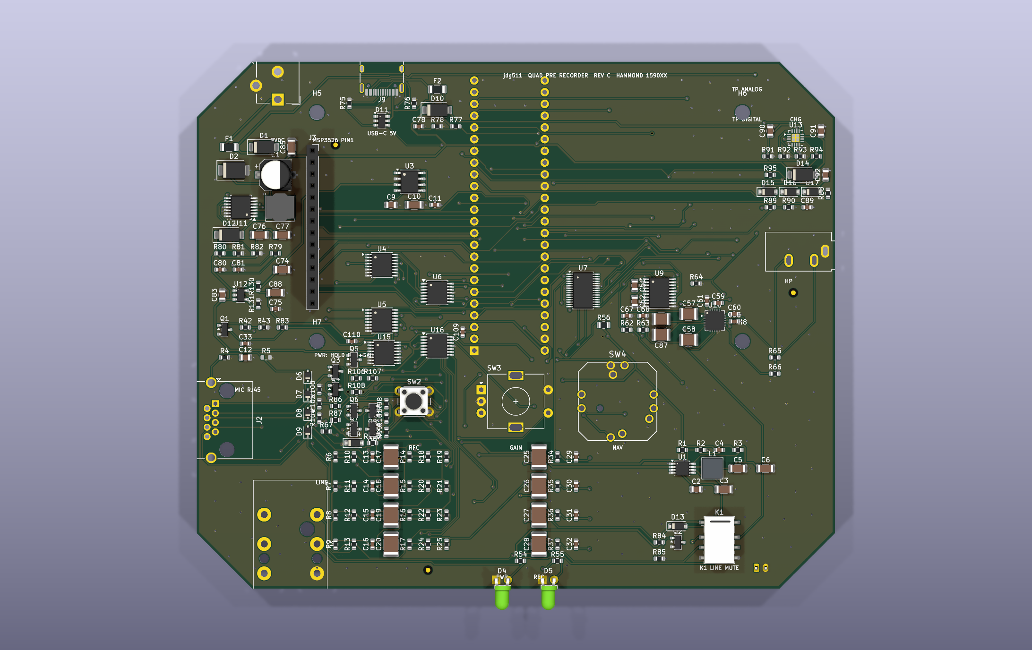
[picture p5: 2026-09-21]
hardware/exports/QuadPreRecorder-top.png

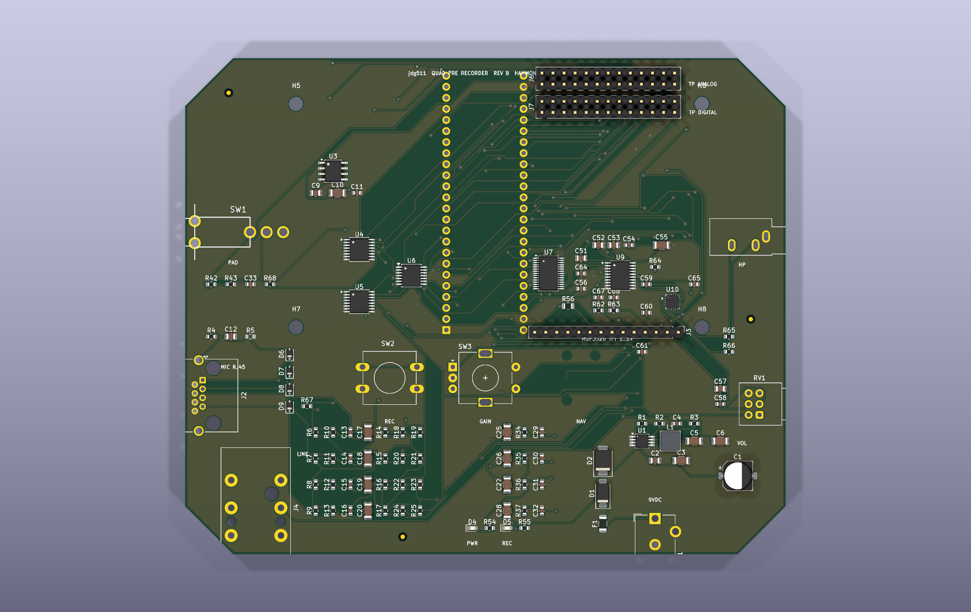
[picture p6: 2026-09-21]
hardware/review_outputs/noSW4-top.png

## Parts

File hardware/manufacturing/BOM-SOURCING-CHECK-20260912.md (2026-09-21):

# BOM sourcing check, Rev C3 mic-mode board (2026-09-12)

> **Update, same day (board `revc3mic4`).** Everything below section 0 is
> the morning check that found the problems; section 0 is what was done
> about them. The BOM now on disk already carries the new part numbers.

## 0. What changed after this check

**U12 is no longer the TPS7A4701.** The 9 V analog LDO is now the Analog
Devices **ADP7142AUJZ-R7** (TSOT-23-5, 200 mA, 11 uVrms, PSRR 88 dB at
10 kHz): Mouser 11 473 in stock at $4.17 (1) / $3.16 (10), LCSC C514356
4 725 at $3.20 (1) / $2.71 (10). The rail draws 25-40 mA, so the 1 A part
was never needed. Feedback divider R130 130k / R131 20k (new lines, both
deep-stock Yageo), C83 changed to 2.2 uF X7R on the LDO input. The
board was re-placed and re-routed for the new footprint; DRC/ERC clean.
Mouser tags the ADP7142 "Restricted Availability", which on that site
means export paperwork on large orders, not a stock problem; LCSC has
no such flag. Note for the parts drawer: a TPS7A4700RGWT bought earlier
only fits the old VQFN footprint, not this board.

**Every dead or zero-stock MPN in sections 2-3 was replaced in the
generators** (`tools/passive_catalog.py`, `generate_schematic.py`), so
PCBWay gets numbers that exist rather than a substitution list:

| Line | Was | Now (in stock 2026-09-12) |
|---|---|---|
| 100 nF 0603 (24 pcs) | Murata GRM188R71H104KA93D | Samsung CL10B104KB8NNNC (LCSC C1591, Basic, 1.06 M at $0.011; Mouser 0 today, Yageo CC0603KRX7R9BB104 is the listed alternate) |
| 100 nF 0805 (C2) | Murata GRM21BR71H104KA01L | Samsung CL21B104KCFNNNE (LCSC 599 k) |
| 1 uF 0805 (C7, C9, C39, C95) | Murata GRM21BR71H105KA12L | Yageo CC0805KKX7R9BB105 (Mouser 295 k, LCSC 807 k) |
| 1 uF 0603 (C53, C59-C61, C65) | Murata GRM188R71E105KA12D | Yageo CC0603KRX7R8BB105 (LCSC 120 k) |
| 10 nF 0603 X7R | Murata GRM188R71H103KA01D | Samsung CL10B103KB8NNNC (Mouser 833 k, LCSC 2.5 M) |
| 10 nF C0G (C29-C32) | Murata GRM1885C1H103JA01D | TDK C1608C0G1H103JT000N (LCSC 16 k; the Murata J successor is the alternate) |
| 2.2 nF C0G (C67, C68) | Murata GRM1885C1H222JA01D | Samsung CL10C222JB8NNNC (LCSC 17 k) |
| 10 uF 1206 (12 pcs) | Samsung CL31B106KAHNNNE (0 at Mouser) | unchanged: LCSC has 976 k of it; Murata GRM31CR71E106KA12L (LCSC 199 k) is the alternate, both are 0 at Mouser |
| 10 uF 0805 (C90-C92) | Samsung CL21B106KAYQNNE | Murata GRM21BZ71E106KE15L (LCSC 93 k; 25 V) |
| 47 uF 1206 (C10) | Murata GRM31CR61A476ME15L | Taiyo Yuden EMK316BBJ476ML-T (Mouser 208 k, LCSC 119 k) |
| 2N7002 (5 pcs) | Nexperia 2N7002,215 | Nexperia 2N7002NXAKR (Mouser 672 k) |
| BAT54 (D24) | Nexperia BAT54,215 | Diodes BAT54-7-F (Mouser 90 k) |
| SS14 (D3) | Diodes SS14-13-F | onsemi SS14 (Mouser 190 k) |
| 2 A PTC (F2) | Littelfuse 1206L200/12WR | Littelfuse 1206L200PR (Mouser 9 k) |
| LEDs D4 / D5 | Gui guang / Everlight | Kingbright WP7113QBC/D (blue) / WP7113ID (red) |

The 33k 0.1 % (R19-R25) stays Yageo RT0603BRD0733KL: 133 k at LCSC
(C705768), and the catalog now names Vishay TNPW060333K0BEEA (188 k at
Mouser) as the alternate.

**Best price, line by line.** `QuadPreRecorder-best-source-20260912.csv`
lists, for every BOM line, the cheaper of Mouser and LCSC at the 5-board
quantity with live stock. Summary: LCSC wins on 60 lines (every
capacitor and resistor, the film caps, the 0.1 % sets, the small diodes,
TPS7A2033, AO3401A, USB-C, and the ICs U1, U7, U9, U10, U11, U13, the
OPA1654s and the ADP7142 are all 10-60 % cheaper there); Mouser is
cheaper or the only stockist on 30 lines (connectors, relay, encoders,
switches, inductors, the SMA/SMB diodes, the two LEDs, the 33k 0.1 %
alternate). Parts total for five boards at the best source: about
**$405** ($229 LCSC + $175 Mouser, K1 included), plus five Teensy 4.1
(~$32-34 each), five displays (~$18) and batteries. Buying everything at
Mouser instead would be about $920 for the lines it stocks, $442 of that
being the film caps ($59 at LCSC). Three lines are neither: J3 (Sullins
socket, DigiKey only, any 1x14 female header will do), K1 (Mouser has it
under the hyphenated number G6K-2F-Y-DC5) and U8 (PJRC / SparkFun).
PCBWay sources from both, so the note in `PCBWAY-ORDER-NOTES-REVC.txt`
tells them which lines to take from LCSC.

Thin spots worth a spare order: U7 PCM1864DBTR has 100 at LCSC (25
needed; Mouser 1 856 as fallback), the 2.2 uF PMLCAP has 429 (20 needed),
the 22 pF C0G Murata GCM1885C2A220JA16D has 370 at Mouser (LCSC 52 k).

Checked every MPN in `QuadPreRecorder-BOM.csv` against Mouser (live API,
exact-MPN match, stock and unit price at the 5-board quantity) and
cross-checked the risky lines against LCSC/JLC and DigiKey. Per-line results
are in `QuadPreRecorder-BOM-stock-check-20260912.csv`. The 4 new 100k
resistors (R126-R129) added after this check use the same Yageo
RC0603FR-07100KL line that is already in the BOM (3.7 M in stock).

## Verdict

Nothing blocks a PCBWay turnkey order, but one part is thin everywhere and a
handful of MPNs are dead numbers that PCBWay would have to substitute. The
order notes already allow generic R/C substitutes; the specific asks below
keep them from guessing.

## 1. The one real risk: U12 TPS7A4701RGWR (9 V analog LDO)

| Source | Stock | Price |
|---|---|---|
| Mouser | 0 (RGWT tube version also 0) | $5.92 |
| DigiKey | full reel only (3000 min), no cut tape shown | $5.95 |
| LCSC | 48 pcs | $12.28 |

It is TI's low-noise 1 A LDO and it has been supply-constrained for a while.
For 5 boards LCSC's 48 pieces are enough, but they can vanish in a week.
Options, best first: (a) buy 6 from LCSC now (~$75) and tell PCBWay U12 is
consigned; (b) let PCBWay source it and accept a possible hold; (c) a
drop-in does not exist in this footprint; the nearest electrical equivalents
(LT3045, TPS7A49) are different packages and would be a re-spin.

## 2. Dead or unavailable MPNs on generic lines (let PCBWay substitute)

These are all commodity parts. Mouser lists the exact numbers as obsolete or
zero stock; equivalents are everywhere. Add the substitutes to the BOM before
upload so PCBWay does not ask.

| Line | BOM MPN | Problem | Use instead |
|---|---|---|---|
| 100 nF 0603 (24 pcs) | Murata GRM188R71H104KA93D | obsolete, 0 | any 0.1 uF 50 V X7R 0603 (e.g. Samsung CL10B104KB8NNNC, Yageo CC0603KRX7R9BB104) |
| 100 nF 0805 (C2) | Murata GRM21BR71H104KA01L | obsolete | any 0.1 uF 50 V X7R 0805 |
| 1 uF 0805 (C7, C9, C39, C95) | Murata GRM21BR71H105KA12L | obsolete | any 1 uF 50 V X7R 0805 |
| 1 uF 0603 (C53, C59-C61, C65, C83) | Murata GRM188R71E105KA12D | obsolete | any 1 uF 25 V X7R 0603 (C59-C61 are U10's charge-pump caps: keep 25 V or better) |
| 10 nF 0603 (C48, C49, C93, C94) | Murata GRM188R71H103KA01D | factory special order | any 10 nF 50 V X7R 0603 |
| 10 nF C0G (C29-C32, ADC inputs) | Murata GRM1885C1H103JA01D | 0 | Murata GRM1885C1H103JA01J (21 k in stock, $0.13); must stay C0G |
| 2.2 nF C0G (C67, C68, DAC filter) | Murata GRM1885C1H222JA01D | 0 | Murata GRM1885C1H222JA01J (28 k, $0.10); must stay C0G |
| 2.2 uF 0805 (C51, C52) | Murata GRM21BR71E225KE11L | 0 | Murata GRM21BR71E225KE11K (16 k, $0.15) |
| 47 uF 1206 (C10, VREF) | Murata GRM31CR61A476ME15L | 0 | GRM31CR61A476ME15K (11 pcs) or any 47 uF 10 V X5R 1206 |
| 10 uF 1206 (12 pcs) | Samsung CL31B106KAHNNNE | 0 at Mouser | CL31B106KAHNNNF or any 10 uF 25 V X7R 1206 |
| 10 uF 0805 (C90-C92) | Samsung CL21B106KAYQNNE | 0 at Mouser | CL21B106KOQNNNE (134 k, $0.30) |
| 33k 0.1 % (R19, R21, R23, R25) | Yageo RT0603BRD0733KL | 0 at Mouser, 142 k at LCSC | fine via LCSC; Vishay TNPW060333K0BEEA (188 k at Mouser) if not. Keep 0.1 %, keep the four from one lot |
| 10R, 5.1k 0603 | Yageo RC0603FR-0710RL / -075K1L | 0 at Mouser | any 1 % 0603 |
| 2N7002 (Q1, Q2, Q5, Q7, Q9) | Nexperia 2N7002,215 | 0 at Mouser | Nexperia 2N7002NXAKR (672 k) or Diodes 2N7002-7-F |
| BAT54 (D24) | Nexperia BAT54,215 | 0 at Mouser | Diodes BAT54-7-F (90 k, $0.19) |
| PESD12VL1BA (D6-D9, D20-D23) | Nexperia PESD12VL1BA,115 | "restricted" at Mouser, 20 k at LCSC | fine via LCSC. If substituted, insist on <= 30 pF: the UMW/BORN clones on LCSC are 30 pF, acceptable; do not accept a generic 12 V TVS |
| SS14 (D3) | Diodes SS14-13-F | not at Mouser | onsemi SS14 (190 k) or Vishay SS14-E3/61T |
| 2 A PTC (F2) | Littelfuse 1206L200/12WR | number not found | Littelfuse 1206L200PR (9 k, $0.65) |
| LEDs D4, D5 | Gui guang 3A4BUD / Everlight 1254-10SURT | obscure / 3000 min | any blue and any red LED of the same footprint; allow substitutes |
| 9 V barrel J1 | CUI PJ-102AH | 0 at Mouser, 1.7 k at LCSC | fine via LCSC |
| 22 pF C0G (C4, C21-C24, C105-C108) | Murata GCM1885C2A220JA16D | 370 left at Mouser | enough for 5 boards (45 needed); GCM1885C2A220JA16J is the successor |

## 3. Parts PCBWay can only get from LCSC (fine, but say so)

| Line | MPN | LCSC | Stock | Price |
|---|---|---|---|---|
| C17-C20, C25-C28, C101-C104 (4.7 uF 35 V PMLCAP 1812) | Rubycon 35MU475KC44532 | C3778321 | 8264 | $1.05 (Mouser: 0 stock and $7.37) |
| C57, C58, C86, C87 (2.2 uF 25 V PMLCAP 1210) | Rubycon 25MU225MB23225 | C3778570 | 429 | $0.75 (Mouser: 0 and $5.38) |
| J9 USB-C | HRO TYPE-C-31-M-12 | C165948 | 245 k | $0.19 |
| U2, U14 TPS7A2033PDBVR | TI | C2862740 | 47 k | $0.22 (Mouser 0) |
| Q3, Q4, Q6, Q8 AO3401A | AOS | C15127 (basic) | 597 k | $0.09 |
| U4, U5, U15 CD4053BPWR | TI | C106760 | 876 | $0.43 (Mouser 3184, $0.67 either way) |

The film caps are the biggest single cost line on the board (60 pieces for
5 boards, about $63 from LCSC versus $442 if someone bought them at Mouser).
Make sure the quote shows them sourced from LCSC.

## 4. Key ICs, all available

| Ref | MPN | Mouser stock | Mouser unit (qty 5-10) | LCSC |
|---|---|---|---|---|
| U7 | PCM1864DBTR | 1856 | $6.32 | 100 |
| U9 | PCM5102APWR | 69 | $3.81 | 8916 |
| U10 | TPA6130A2RTJR | 265 | $1.24 | 2870 |
| U11 | TPS61175PWPR | 53 | $4.49 | 7886 |
| U13 | BQ24074RGTR | 1342 | $2.43 | 720 |
| U6, U16 | OPA1654AIPWR | 1335 | $2.75 | 1182 |
| U3 | TLE2426IDR | 1886 | $2.87 | not stocked (SOIC-8 only at Mouser/DigiKey) |
| U1 | TPS62160DGKR | 163 | $1.80 | 1240 |
| K1 | Omron G6K-2F-Y DC5 | 3464 (as "G6K-2F-Y-DC5") | $4.98 | |
| SW3, SW4 | Alps EC11E15244G1 / RKJXT1F42001 | 785 / 1258 | $4.91 / $9.05 | |
| J2, J4, J5 | Amphenol RJHSE-5380 / Neutrik NRJ6HF / Same Sky SJ1-3533NG | 6190 / 11473 / 7539 | $1.66 / $0.90 / $1.68 | |
| U8 | PJRC Teensy 4.1 | not at Mouser (SparkFun DEV-20360 = Teensy 4.1 w/ headers, 40 in stock, $33.60) | | |

## 5. Cost picture (5 boards, parts only)

Mouser extended price on the lines it could quote: about $910, but $550 of
that is the film caps at Mouser's price; buying those from LCSC brings the
parts total to roughly $420-450 for five boards, i.e. $85-90 per board
before the Teensy (~$32), display (~$18) and battery. Add PCBWay's board,
stencil and assembly charges (rough guess $250-350 for five two-sided
boards) and the five populated units land somewhere around $900-1100 all
in. Treat that as a sanity number, not a quote.

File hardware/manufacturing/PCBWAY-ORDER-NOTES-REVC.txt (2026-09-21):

=============================================================
PCBWAY ORDER - PASTE-READY NOTES  (Rev C3, Hammond 1590XX, 4-layer)
Generated 2026-09-15 from the re-routed board (DRC 0/0/0, ERC 0/0; final
pre-order check and the Teensy socket correction are in
reviews/audio-rules-check-revC3-fixes.md Addenda 5 and 6, the full review
in reviews/QuadPreRecorder-RevC3-review-dossier.md). Any package dated
2026-09-13 or earlier is VOID: its Teensy socket footprint was wrong.
The Gerber set has all FOUR copper layers (F, In1, In2, B).
=============================================================

Upload file:
  hardware\manufacturing\QuadPreRecorder-RevC-PCBWay-handoff.zip
  (or just QuadPreRecorder-RevC-Gerbers.zip for a bare-board quote)

Use the "Quick Order (Upload files & checkout)" button on the PCB
Instant Quote page. The zip auto-detects 4 layers and 138 x 114 mm.

-------------------------------------------------------------
AFTER UPLOAD, CHECK / CHANGE THESE
-------------------------------------------------------------
  Layers .................. 4  (F.Cu signal / In1 GND plane / In2 GND plane / B.Cu signal)
  Stackup ................. PCBWay standard 4-layer 1.6 mm: 35 um Cu,
                            ~0.21 mm prepreg / ~1.07 mm core / ~0.21 mm prepreg.
                            No impedance control needed. The board file
                            carries this stackup explicitly.
  Size .................... 138 x 114 mm (12 mm chamfered corners)
  Quantity ................ 5 (PCBWay minimum for assembly)
  Material / thickness .... FR-4, 1.6 mm
  Copper .................. 1 oz outer, 1 oz inner (planes)
  Min track / spacing ..... 8 / 6 mil is plenty (board is 0.20 / 0.15 mm;
                            supply rails 0.30 mm)
  Min hole ................ 0.3 mm (185 vias are 0.60 mm pad / 0.30 mm drill:
                            the decoupling, thermal and escape vias; the
                            other 338 are 0.80/0.40)
  Solder mask / silk ...... Green / white
  Surface finish .......... HASL lead-free (defaults to leaded) or ENIG
  Via process ............. Tenting vias (default). PLEASE keep the 0.3 mm
                            vias inside the exposed pads of U10 (nine), U11
                            (five) and U13 (two) tented on the BOTTOM side
                            only (paste side open). A handful more 0.3 mm vias
                            sit inside 0603 capacitor pads next to U7 and
                            U9 (decoupling fanout): same treatment, bottom
                            tented, no plugging needed.
  Assembly Service ........ tick the checkbox
     - Turnkey (PCBWay supplies parts by MPN)
     - Board type: Single pieces
     - Assembly side(s): BOTH SIDES   <- defaults to Top only!
     - Quantity: 5
     - "Accept alternatives/substitutes?" -> NO for the ICs
       (U1, U4-U7, U9-U16) and the relay K1; generic R/C
       substitutes are fine, EXCEPT the 0.1 % resistors (R18-R33,
       R118-R125) which set the balanced-input CMRR

-------------------------------------------------------------
PASTE INTO "Detailed information of assembly"
-------------------------------------------------------------
Two-sided assembly, 293 placements (180 top, 113 bottom), mixed SMT
and through-hole. BOM and centroid files: QuadPreRecorder-BOM.csv and
QuadPreRecorder-CPL-PCBWay.csv (KiCad coordinate convention, Y negative
= downward). DNP: R5, R38-R41 (listed in BOM as DNP, not in CPL).

U8 (BOTTOM side) is a socketed sub-assembly - see
QuadPreRecorder-BOM-extras.csv: solder TWO Samtec SLW-124-01-G-S
low-profile 1x24 female socket strips into the U8 footprint (the two
24-pin rows, 15.24 mm apart; corrected 2026-09-15, the earlier package had them 17.78 mm apart), then plug a PJRC TEENSY41_PINS (Teensy
4.1 with pins pre-soldered) into the sockets with its microSD slot
toward the board edge marked "SD CARD SLOT THIS EDGE". BEFORE plugging
it in: (a) cut the small VIN-VUSB link pad on the Teensy's underside,
(b) solder two ~20 mm wires from the Teensy's underside "USB Device"
D+ and D- pads to the board's bottom-side pads TP1 (D+) and TP2 (D-)
next to the socket. If you cannot source PJRC parts, quote the
sockets only and we will supply and wire the Teensy ourselves.
TEENSY41_NE_PINS (no Ethernet chip) is acceptable.

J3 is a 1x14 2.54 mm FEMALE socket (Sullins PPTC141LFBN-RC) - do NOT
solder a display to it. We would like you to quote and ship LOOSE
(not fitted) the off-board items in QuadPreRecorder-BOM-extras.csv:
LCDWiki MSP3526 3.5in CAPACITIVE-touch IPS TFT module (not the
resistive MSP3520), 4x M3x11 standoffs + screws, a 9 VDC 1 A regulated
adapter with 5.5x2.1 mm CENTER-POSITIVE plug (US), a USB-C cable, one
push-on knob for a 6 mm 18-spline knurled shaft, and one Omron B32
keycap for the B3F-5150. If any of these are unavailable, quote the
rest and we will supply them.

J9 is an HRO TYPE-C-31-M-12 USB-C receptacle (16-pin, through-hole
shell tabs) - equivalent 16-pin TYPE-C-31-M-12 style parts are fine.
K1 is an Omron G6K-2F-Y DC5 signal relay - please do not substitute a
different pinout. J10 is a JST B2B-PH-K-S battery connector on the
BOTTOM side; the LiPo battery itself is customer-supplied (do not
fit). U13 (BQ24074) and U10 (TPA6130A2) have exposed pads - please reflow, not hand-solder; U10's pad has a 3x3 via array
(tent the bottom). C17-C20, C25-C28, C101-C104 (Rubycon 35MU475KC44532) and C57/C58/C86/C87 (Rubycon 25MU225MB23225) are PMLCAP
film chips, NOT ceramics: do not substitute MLCCs. They are cheapest from LCSC (C3778321 / C3778570); the 16 V siblings
16MU475MC14532 / 16MU225MB23225 are acceptable alternates. Please do not
substitute the electret ESD diodes with high-capacitance TVS parts,
and do not substitute the Neutrik, Alps, CUI or Amphenol connectors/
controls with look-alikes ("accept substitutes" = NO for those);
generic R/C substitutes of equal value/package/rating are fine.
Keep each four-resistor 0.1% set (matched channel resistors) from one
lot. Verify pin-1 orientation of U1, U4-U7, U9-U12 and the relay K1
polarity (coil pin 1 = +) against the assembly PDFs
(QuadPreRecorder-assembly-top.pdf / -bottom.pdf).
Fiducials: three 1 mm fiducials per side (not in BOM/CPL).

Sourcing notes (checked 2026-09-12, see BOM-SOURCING-CHECK-20260912.md
and QuadPreRecorder-best-source-20260912.csv for the cheapest in-stock
source of every line): every MPN in this BOM was in stock at Mouser
and/or LCSC on that date, none is a reel-only or end-of-life number.
U12 is now the Analog Devices ADP7142AUJZ-R7 (TSOT-23-5; Mouser 11k,
LCSC C514356) - the old TPS7A4701 is gone from this revision. Please buy
the Rubycon PMLCAP film caps, the Yageo 0.1 % resistors and the
TPS7A2033 / AO3401A / USB-C parts from LCSC (C3778321, C3778570, C705768,
C2862740, C15127, C165948 etc.); the ICs U7, U9, U11, U13 and the OPA1654s
are also cheaper at LCSC than at Mouser. For the C0G lines (C29-C32
10 nF, C67/C68 2.2 nF, 22 pF lines) any substitute must also be C0G/NP0.
D4/D5 (Kingbright 3 mm LEDs) may be swapped for any blue / red LED in
the same footprint.

REMINDERS: Assembly side(s) = BOTH SIDES (form defaults to Top only).
Assembly minimum is 5 boards - the quote is for five populated units.

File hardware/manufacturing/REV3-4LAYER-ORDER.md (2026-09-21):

# Rev 3 (4-layer) — PCBWay order package

**Date:** 2026-08-01 (BOM MPN fix: 2026-08-23)
**Upload this:** `manufacturing/QuadPreRecorder-Rev3-4Layer-PCBWay-v2.zip`
**Board source:** `hardware/QuadPreRecorder_rev3_4layer_routed.kicad_pcb`

## 2026-08-23 — BOM MPN fix (PCBWay request)

PCBWay support (Aug 9) rejected the quote because the MPN column in the BOM
was blank on the generic-passive lines. Every BOM line now carries a specific,
verified, in-production manufacturer part number:

- **1% resistors** → Yageo RC0603FR-07 series (exact per-value MPNs).
- **0.1% precision resistors** (R18–R33 gain set) → Vishay TNPW0603...BEEA
  thin-film, 25 ppm/°C — confirmed in stock at Mouser.
- **MLCCs** → Samsung CL-series X7R/C0G (several legacy Murata GRM parts are
  now factory-obsolete), plus Murata GRM1885C1H103JA01D (10nF C0G),
  Murata GRM188Z71E225KE43D (2.2uF 0603), TDK C2012X7R1H684K125AB (680nF
  0805), Yageo CC0603KRX7R8BB684 (680nF 0603).
- **Electrolytics** → Panasonic EEE-FK1E101P (C1, 100uF 25V) and
  EEE-FK1C101P (C66, 100uF 16V), both low-ESR FK series.
- **J6/J7 debug headers** → Sullins PRPC013DAAN-RC (2x13, 2.54 mm, THT).

Two documented spec deviations (noted in the BOM Description column):

1. **C12** (1nF 1kV, 0805): specified C0G, supplied as **X7R**
   (KEMET C0805C102KDRACTU). 1 kV C0G is not manufactured in 0805 by anyone;
   X7R is the industry standard at this rating. EMI/chassis cap, not in the
   audio path.
2. **C10** (47uF 10V, 1206): specified X7R, supplied as **X5R**
   (Samsung CL31A476MPHNNNE, JLC basic part). X7R does not exist at
   47uF/1206; X5R is standard for bulk rail decoupling.

DNP alignment: the PCBWay-format BOM now matches the KiCad export —
**R5, R38–R41 are DNP** (do not populate).

The audio-critical constraints are unchanged: C0G stays C0G everywhere else,
and the 0.1% gain-set resistors remain 0.1% thin-film.

## Verification status

| Check | Result |
|---|---|
| Unconnected items | **0** |
| DRC errors | **0** |
| DRC warnings | 59 — 58 silkscreen (cosmetic), 1 dangling track stub |
| ERC | **0 violations** |
| Schematic parity | **clean** |
| Copper layers (from gerber job) | **4** — L1 Top / L2 In1 / L3 In2 / L4 Bot |
| Drill | 381 holes, 14 tool sizes, 0.30–3.25 mm |
| Placement | 180 components — 113 top, 67 bottom |
| BOM | 74 line items, **every line has a specific MPN** |

The one remaining warning is a 5.8 mm dangling tail on `HP_CPN`. It is
load-bearing — removing it splits the net — so it stays. Electrically it is a
short stub on the headphone charge-pump net and is harmless.

## Stackup

- **L1 F.Cu** — signal
- **L2 In1.Cu** — solid GND plane (unbroken)
- **L3 In2.Cu** — signal + GND pour
- **L4 B.Cu** — signal

Placement, board outline, Hammond 1590F fit and the Cat 6 jack (J2) are
unchanged from the mechanical work already validated.

## PCBWay order settings

| Setting | Value |
|---|---|
| Layers | **4** |
| Material | FR-4 |
| Board size | 138.15 × 114.15 mm |
| Thickness | 1.6 mm |
| Copper weight | 1 oz outer / 1 oz inner |
| Min track / clearance | 0.20 mm / 0.15 mm |
| Min via | 0.80 mm pad / 0.30 mm drill |
| Surface finish | HASL lead-free (or ENIG if you want flatter pads for the QFNs) |
| Solder mask / silkscreen | your choice |
| Assembly | **two-sided full SMT** |

**Do not use** `QuadPreRecorder-RevA-PCBWay-handoff.zip`, the 2-layer
`rev3-gerbers`, or the original `QuadPreRecorder-Rev3-4Layer-PCBWay.zip`
(blank MPNs) — all predate the v2 package.

## Flag on the order

`EC11E15244G1` (gain encoder) was 0-stock at Mouser. Let PCBWay source it, or
approve an EC11E-family substitute with the same footprint.

## Two things to confirm with PCBWay

1. **Stackup.** The gerbers declare 4 copper layers but not layer thicknesses —
   PCBWay will apply their standard 1.6 mm 4-layer stackup. That is fine here;
   nothing in this design is impedance-controlled.
2. **Mixed plating.** The drill file is tagged `MixedPlating,1,4` (all holes
   plated through, no blind/buried vias). Standard 4-layer process.

## Fixed during this pass

A pre-existing fabrication hazard was found and removed: a 0.30 mm via had been
placed **inside** J7 pad 23's 1.00 mm drill hole (same net, so the via was
redundant — the through-hole pad already connects all layers). Overlapping
drills risk drill breakage and would likely have been queried by the fab.

Three GND stitching vias were added at (70.85, 48.70), (69.40, 47.00) and
(67.55, 49.55), tying U7's ground pins to the In1 plane — one of them sits
0.20 mm from U7 pin 26. This replaces a GND trace that had to be cut to free the
ADC's pin escapes, and is a lower-impedance ground than the trace it replaces.

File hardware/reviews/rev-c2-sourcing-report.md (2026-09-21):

# Rev C2 sourcing and control-height report

2026-09-08. Sources: LCSC/JLCPCB parametric DB, Mouser API, DigiKey API, manufacturer
datasheets. Prices USD, qty 1 unless noted.

---

## 0. STATUS 2026-09-09: both blocking footprint errors are FIXED

Verified after the change: **ERC 0 violations, DRC 0 violations, 0 schematic
parity issues.** Board otherwise unchanged.

**D1, D10, D12, D14** — was `SS34-E3/57T`, which is SMC/DO-214AB on an SMA
footprint. Now **Diodes Inc B340A-13-F**, a genuine 40 V 3 A Schottky in
DO-214AC/SMA. Active, 28,006 in stock at Mouser, $0.51 qty1 / $0.241 qty10.
Alternate: LangJie SS34 in SMA (LCSC C7450457, 16k stock, $0.029).
Note: I also checked ROHM RB050L-60TE25 as a candidate and rejected it — it is
NRND with zero stock.

**D15-D19** — was `BAT54W-7-F`, a 3-lead SC-70/SOT-323 part on a 2-lead SOD-123
footprint, and down to ~65 pieces in stock worldwide against 5 per board.
Now **1N4148W-7-F**. This is not merely a package fix; silicon is the better
part for this circuit, for three reasons:

1. **Leakage.** D18/D19 block VBAT (3.7 V) from an unpowered Teensy pin through
   a 1 M pull-up, and D15-D17 feed BOOST_EN through the 1 M pull-down R88. A
   Schottky leaks about 1 uA, which across 1 M is roughly a volt of error and
   can hold the soft-power latch on. Silicon leaks about 25 nA, some 40x
   better, so the unit actually powers off.
2. **Isolation margin.** An unpowered Teensy clamps its pins to ~0.5 V. A
   Schottky's 0.3 V drop can begin conducting at that clamp voltage. Silicon's
   higher drop cannot.
3. **Forward drop is irrelevant here.** These carry microamps into a
   high-impedance enable pin. Even at 0.45 V of drop, BOOST_EN still reaches
   ~2.85 V against a ~1.3 V threshold.

It also consolidates with D13, which was already a 1N4148W. Alternate:
ST(Semtech) 1N4148W (LCSC C81598, Basic library, 3.5 M stock).

---

## 1. HISTORICAL: the two footprint mismatches (now fixed, see section 0)

These are wrong in the schematic today. Parts ordered against them will not fit the board.

### 1.1 D1, D10, D12, D14 (4 placements) - SS34 in the wrong package

- BOM says `SS34-E3/57T` (Vishay). That part is **SMC / DO-214AB**.
- Board footprint is `Diode_SMD:D_SMA` (**DO-214AC**).
- Confirmed against both DigiKey and LCSC (C13354, "SMC(DO-214AB)").
- Fix: change the MPN to an SMA-package SS34, or change the footprint. An SMA SS34
  is abundant, e.g. LCSC C8678 (MDD, SMA/DO-214AC, $0.035, 5.2M stock, JLC Basic).

### 1.2 D15, D16, D17, D18, D19 (5 placements) - BAT54W wrong package AND wrong pin count

- BOM says `BAT54W-7-F`. That part is **SC-70 / SOT-323, 3 leads**.
- Board footprint is `Diode_SMD:D_SOD-123`, **2 leads**.
- This is a lead-count mismatch, not just a size difference.
- Also genuinely scarce: 65 at Mouser, 0 at DigiKey (3,000 min order), 92 at LCSC,
  and the design needs 5 per board.
- Fix: re-select the part outright. A 2-lead SOD-123 Schottky is the obvious swap.

These five diodes are the soft-power latch isolation diodes, which are exactly the
part the whole two-button power-on scheme depends on. Worth getting right.

---

## 2. Parts that are obsolete, restricted, or unbuyable

| Ref | Part | Status |
|---|---|---|
| SW4 | Alps SKQUCAA010 | **OBSOLETE.** Zero stock, no price, not in the JLCPCB library. Must be replaced. |
| D6-D9 | Nexperia PESD12VL1BA,115 | **"The factory is currently not accepting orders for this product."** Restricted availability, zero stock. SOD-323 second sources exist on LCSC (UMW C2687119, $0.033, 58k stock) but verify clamping/capacitance, these sit on the mic inputs. |
| U12 | TI TPS7A4701RGWR | Zero stock at Mouser, not in the JLCPCB library at all. Single-sourced. This is the ultra-low-noise analog LDO, so substitution is not casual. |
| Q1, Q2 | Nexperia 2N7002,215 | Zero stock at Mouser for that orderable code. Trivially second-sourced (JLC C8545 Basic, 2.1M stock). |
| J6, J7 | "2x13 0.1in pin header", mfr "Generic" | That is a description, not a part number. Nothing can be ordered against it. |
| D3 | SS14-13-F | Could not verify on any distributor through these tools. Well-formed Diodes Inc code, so likely a coverage gap rather than a bad MPN, but unconfirmed. |
| F2 | 1206L200/12WR | Could not verify. Note 2 A hold in a 1206 body is at the top of the 1206L family range, so confirm the code exists. |

Low-stock-at-Mouser but fine at LCSC: U2 (0 vs 53k), U11 (58 vs 7.9k), U9 (69 vs 9.4k),
U1 (163 vs 980). Buy those three from LCSC.

---

## 3. The control height problem, solved

### The geometry

Board top sits 19.5-20 mm above the enclosure floor. Inside height is 35.25 mm.

- Board top to lid **underside**: **15.5 mm**
- Board top to lid **outer face**: **17.5 mm** (lid is 2.0 mm)

### The documentation was wrong

`enclosure-1590XX-desk-study.md` states SW2 (Omron B3F-5150) has a "plunger 17.5 mm
above" the board and is therefore flush with the outer lid face. **It is 7.3 mm.**
Confirmed on Mouser and on the Omron B3F datasheet. The real B3F-5150 falls 8.2 mm
short of even touching the lid underside. Correct that document.

### The root finding

**No tactile switch and no 5-way switch on the market puts its actuator 15.5 mm above
a PCB.** Surveyed the entire LCSC tactile catalogue (12,685 parts): the tallest is
8.5 mm. Omron's tallest 12x12 (B3F-4055) is 7.3 mm, same as the current part.

The ONLY board-mounted control that natively spans this gap is a **long-shaft rotary
encoder**. Everything else needs a cap, a knob, or a lid-mounted carrier.

That reframes the question. The three controls cannot all be solved by picking taller
switches, because taller switches do not exist. They are solved by deciding how to
bridge 15.5 mm.

### Recommended set

**SW3 + SW4 collapse into ONE part.**

| | Part | Detail |
|---|---|---|
| **SW3+SW4** | **Alps RKJXT1F42001** | 4-direction stick + centre push + **rotary encoder**, all in one. 17.0 x 17.0 x 10.5 mm. 30 detents / 15 pulses. Centre push travel 0.3 mm. 9 deg stick throw. THT. **$9.05 qty1, $8.60 qty10, 1,280 in stock at Mouser, Active.** LCSC C160841, 4,832 in stock, $5.21. |

This is literally the "5-way encoder/controller" originally asked for. It replaces the
obsolete SW4 and the $4.91 EC11E15244G1 with a single active, well-stocked part at
roughly the same combined cost, frees board area, and removes one panel hole.

It stands 10.5 mm tall, so it needs a knob about 9-11 mm tall to reach and pass the
lid. Alps designs this family expecting a customer knob, which is how it works in car
head units. 3D printed is fine for a prototype.

**Alternative if you want the encoder and the nav kept separate:**

| | Part | Detail |
|---|---|---|
| SW3 | **Bourns PEC11R-4220F-S0024** | 20 mm flatted 6 mm shaft, with push switch. Body 10 mm above PCB. **$2.29 qty1, $1.85 qty10, 11,274 in stock, Active.** Mouser 652-PEC11R-4220F-S24. Half the price of the Alps EC11E and 10x the stock. Shaft clears the lid with room for a standard knob. Family offers 12.5 / 15 / 17.5 / 20 / 25 mm shafts, so the height can be tuned exactly. |
| SW4 | Alps SKRHACE010 | 4-direction + centre push, 7.5 x 7.5 mm SMD, 1M cycles, $3.44 qty1, 1,287 Mouser / 1,176 LCSC. Short, so still needs a knob or a lid carrier. |

**SW2 (record button)** needs a bridge either way:
- Omron **B3F-4055**, 12 x 12 mm, 7.3 mm, **1,000,000 cycles** (vs 100k on most),
  $0.50 Mouser / $0.129 LCSC, 163k stock. Then a ~10 mm cap.
- Or a lid-mounted panel momentary, wired to the board. More robust, looks right on
  audio gear, no custom cap needed.

### The option worth considering instead

Put all three controls on a **small carrier PCB mounted to the lid underside**, ribbon
to the main board. Every height problem disappears at once, because each switch then
only has to clear 2 mm of lid instead of 15.5 mm. It also lets you use cheap, short,
in-stock parts for everything. Costs one extra small PCB (about $5 for five at PCBWay)
plus a ribbon cable. This is how commercial gear solves exactly this gap.

---

## 4. RESOLVED 2026-09-08: every passive now has an exact MPN plus an alternate

**Before: 54 lines / 184 placements unorderable (77% of the board). Now: 0.**

95 of 97 BOM lines carry a real primary MPN, a second-source AltMPN from a
different manufacturer, and an LCSC code. The only two blanks are TP1/TP2,
which are bare copper test pads, not purchasable parts.

How it was done, so it stays fixed: the placeholders came from three generic
helper functions in `tools/generate_schematic.py`, not from per-part data, so
editing the `.kicad_sch` would have been wiped on the next regeneration. The
fix is a new **`tools/passive_catalog.py`** holding 45 entries (19 resistor 1%,
4 resistor 0.1%, 20 ceramic, 2 electrolytic), each with primary, alternate and
LCSC code. The helpers now look up that table and **raise on an unknown value**
rather than falling back to a placeholder, so a newly added part can never
silently reintroduce an unorderable line.

`Part` gained `alt_mpn` and `lcsc` fields, emitted as AltMPN and LCSC schematic
properties. Hand-off file: `hardware/manufacturing/QuadPreRecorder-BOM-with-alternates.csv`.

Verified after the change: ERC 0 violations, DRC 0 violations, 0 schematic
parity issues, board unchanged.

### Four entries needed an engineering judgement call. Please confirm each.

1. **C12, "1nF 1kV C0G" 0805 — no manufacturer makes this.** Primary keeps the
   1 kV rating and accepts X7R (Yageo CC0805KRX7RCBB102). If C0G matters more
   than 1 kV, use CC0805JKNPOBBN102 (500 V NP0). Genuine 1 kV C0G exists only
   in 1206, which needs a footprint change.
2. **C5/C6, "22uF 10V" 1206 — now the 16 V part** (Taiyo Yuden EMK316BB7226ML-T).
   X7R 22 µF in 1206 tops out at 10 V from Murata, and 10 V is not enough
   headroom if these sit near the boost or battery node.
3. **C10, "47uF 10V" 1206 is X5R, not X7R.** No X7R 47 µF exists in 1206 from
   anyone. Tolerance is also +/-20%.
4. **R30-R33, 90.9k 0.1% — buy from Mouser/DigiKey, not LCSC.** Thinnest line
   on the board. Do NOT accept 91k as a substitute, it is a different value.

Also fixed: **J6/J7** had manufacturer "Generic" and MPN "2x13 0.1in pin
header", which is a description. Now CONNFLY DS1021-2x13SF11-B (LCSC C7430409)
with HCTL PZ254-2-13-Z-8.5 as the alternate.

---

## 4b. Original finding (historical): 54 lines, 184 placements, none orderable

Every resistor and capacitor on the board carries a placeholder, not a part number:
"GRM series X7R/C0G", "RC0603FR series, 1%", "TNPW0603 series, 0.1%", "EEE-FK series".
That is 77% of all placements. PCBWay turnkey sources by MPN, so as written they cannot
quote most of the board. Full resolved table is in the session notes; highlights:

**Errors found while resolving:**

- **C1 placeholder family is wrong.** Panasonic EEE-FK has no 100uF/25V in a 6.3 mm
  can at all; the FK part is an 8.0 mm can with an 8.3 x 8.3 mm land and does not fit
  the `CP_Elec_6.3x5.8` footprint. Use **EEE-FT1E101AP** (FT series, genuinely
  6.3 x 5.8 mm, lower ESR).
- **C12 "1nF 1kV C0G 0805" cannot exist.** No manufacturer makes that combination in
  0805. Pick one: keep 1 kV and accept X7R (Yageo CC0805KRX7RCBB102, $0.054, 310k
  stock), keep C0G and drop to 500 V, or move to 1206.
- **C10 "47uF 10V 1206" must be X5R.** No X7R 47uF exists in 1206 from anyone.
- **C5/C6 22uF at exactly 10 V.** If these sit near the boost or battery node, 10 V is
  not enough headroom. 16 V versions exist.
- **C4/C21-C24**: the canonical Murata 22pF part is NRND. Use GCM1885C2A220JA16D.

**Cost concentration:** twelve 1206 10uF caps are $3.75 of the $11.46 passive total
(33%), and the sixteen 0.1% resistors are $2.65 (23%).

**Cost-optimised passive set: $8.13/board instead of $11.46**, with no spec loss:
swap the Vishay TNPW 0.1% set to the Yageo RT0603BRD 0.1% set (better ratio tracking
too, since all four values then come from one family) and the Murata 1206 10uF to
Samsung CL31B106KAHNNNE.

---

## 5. Not on the BOM at all

None of these appear in the BOM, and several are the most expensive items on the build.

| Item | Est. cost | Note |
|---|---|---|
| Teensy 4.1 | ~$31.50 | Largest single line item. PJRC direct, no distributor carries it under that MPN. |
| MSP3526 3.5in capacitive TFT module | ~$20-30 | LCDWiki / import. Still unverified against the design. |
| LiPo pouch, 3500 mAh class, flat, with PCM | ~$16 | Must be a flat pouch. |
| Hammond 1590XX enclosure | ~$25-30 | |
| Knob for the encoder / multi-control | ~$2-8 | Or printed. |
| Cap for the record button | ~$1 | Or printed. |
| 11 mm standoffs + M3 hardware for the TFT | ~$4 | |
| CAT6 cable and plug for the ambisonic mic | ~$5-10 | The mic side of J2. Nothing on the BOM covers it. |
| Stencil | ~$7 | Order with the PCBs. |
| 4-layer PCB, 138 x 114 mm, qty 5 | ~$60-110 | Needs a real PCBWay quote. |

---

## 6. Cost summary

| Group | Per board |
|---|---|
| Priced BOM lines with real MPNs (34 of 41) | $60.22 qty1 / $46.50 qty10 |
| Passives (54 placeholder lines resolved) | $11.46, or $8.13 optimised |
| Teensy 4.1 | ~$31.50 |
| **Board electronics subtotal** | **~$103 qty1, ~$86 qty10** |
| Plus TFT, battery, enclosure, hardware, cable | ~$75-95 |
| **Rough all-in per unit, qty 1** | **~$180-200** |

Not included: the 7 unpriced lines, PCB fabrication, PCBWay assembly labour and their
sourcing markup.

Caveats: LCSC-sourced lines are reel-break prices, not true one-off quotes. The D1/D10/
D12/D14 and D15-D19 costs are against parts that do not fit the current footprints.

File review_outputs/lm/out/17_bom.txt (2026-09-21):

BLOCKER: U8 Teensy 4.1 stock is 0 at the listed source (PJRC/Mouser/SparkFun). The BOM lists 1 unit per board, so 5 boards require 5 units. If stock is truly zero, the build cannot proceed. Verify current PJRC stock or switch to a distributor with inventory.

SHOULD FIX: J3 MSP3526 TFT socket has empty Unit $ and Stock fields in the table. The off-board extras list an "LCDWiki MSP3526 module" but the BOM row for J3 (the socket) is incomplete. If the socket is not purchased, the display cannot be installed. Confirm if J3 is populated or if the module plugs directly into a different connector.

SHOULD FIX: C17-C20, C25-C28, C101-C104 (12x 4.7uF 35V Film) have only 6901 stock at LCSC. For 5 boards, you need 60 units. Stock is sufficient, but the margin is low if there are returns or defects. Consider sourcing from a second distributor if possible.

NOTE: R5 (0R Chassis Link) and R38-R41 (100k) are marked DNP. Ensure the assembly house knows to skip these. No cost impact, but prevents confusion during pick-and-place.

NOTE: U13 BQ24074RGT (Battery Charger) has 417 stock at LCSC. For 5 boards, you need 5 units. Stock is sufficient.

NOTE: U7 PCM1864DBT (DAC) has 100 stock at LCSC. For 5 boards, you need 5 units. Stock is sufficient.

NOTE: K1 G6K-2F-Y 5VDC Relay has 3464 stock at Mouser. For 5 boards, you need 5 units. Stock is sufficient.

NOTE: SW4 TFT Menu Nav Encoder has 1258 stock at Mouser. For 5 boards, you need 5 units. Stock is sufficient.

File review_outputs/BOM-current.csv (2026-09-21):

Reference | Value | Footprint | Manufacturer | MPN | AltMPN | LCSC
C1 | 100uF 25V | Capacitor_SMD:CP_Elec_6.3x5.8 | Panasonic | EEE-FT1E101AP | Lelon VZS101M1ETR-0606 | C178590
C2 | 100nF 25V | Capacitor_SMD:C_0805_2012Metric | Murata | GRM21BR71H104KA01L | Samsung CL21B104KCFNNNE | C77082
C3,C76,C77,C85 | 10uF 25V | Capacitor_SMD:C_1206_3216Metric | Samsung | CL31B106KAHNNNE | Murata GRM31CR71E106KA12L | C14860
C4,C21-C24 | 22pF C0G | Capacitor_SMD:C_0603_1608Metric | Murata | GCM1885C2A220JA16D | FOJAN FCC0603N220J500CT | C408549
C5,C6 | 22uF 10V | Capacitor_SMD:C_1206_3216Metric | Taiyo Yuden | EMK316BB7226ML-T | Murata GRM31CZ71C226ME15L | C385906
C7,C9 | 1uF 10V | Capacitor_SMD:C_0805_2012Metric | Murata | GRM21BR71H105KA12L | Yageo CC0805KKX7R9BB105 | C77083
C8 | 4.7uF 10V | Capacitor_SMD:C_0805_2012Metric | Murata | GRM21BZ71E475KE15L | Samsung CL21B475KAFNNNE | C437556
C10 | 47uF 10V | Capacitor_SMD:C_1206_3216Metric | Murata | GRM31CR61A476ME15L | Taiyo Yuden EMK316BBJ476ML-T | C94034
C11,C33-C36,C40,C41,C43,C44,C47,C50,C54,C56,C63,C64,C69-C73,C75,C78,C89 | 100nF | Capacitor_SMD:C_0603_1608Metric | Murata | GRM188R71H104KA93D | Samsung CL10B104KB8NNNC | C77055
C12 | 1nF 1kV C0G | Capacitor_SMD:C_0805_2012Metric | Yageo | CC0805KRX7RCBB102 | Murata GRM31C5C3A102JWA3L | C309495
C13-C16 | 100pF C0G | Capacitor_SMD:C_0603_1608Metric | Murata | GRM1885C1H101JA01D | Samsung CL10C101JB8NNNC | C71664
C17-C20,C25-C28 | 4.7uF 16V | Capacitor_SMD:C_1206_3216Metric | Murata | GRM31CR71H475KA12L | Samsung CL31B475KBHNNNE | C77096
C29-C32 | 10nF C0G | Capacitor_SMD:C_0603_1608Metric | Murata | GRM1885C1H103JA01D | TDK C1608C0G1H103JT000N | C85973
C37,C74,C88 | 10uF 16V | Capacitor_SMD:C_1206_3216Metric | Samsung | CL31B106KAHNNNE | Murata GRM31CR71E106KA12L | C14860
C38,C39,C53 | 1uF | Capacitor_SMD:C_0805_2012Metric | Murata | GRM21BR71H105KA12L | Yageo CC0805KKX7R9BB105 | C77083
C42,C45,C46,C55,C62 | 10uF | Capacitor_SMD:C_1206_3216Metric | Samsung | CL31B106KAHNNNE | Murata GRM31CR71E106KA12L | C14860
C48,C49,C93,C94 | 10nF | Capacitor_SMD:C_0603_1608Metric | Murata | GRM188R71H103KA01D | Samsung CL10B103KB8NNNC | C77053
C51,C52 | 2.2uF | Capacitor_SMD:C_0805_2012Metric | Murata | GRM21BR71E225KE11L | Samsung CL21B225KAFNNNE | C77081
C57,C58,C86,C87 | 2.2uF X7R | Capacitor_SMD:C_0805_2012Metric | Murata | GRM21BR71E225KE11L | Samsung CL21B225KAFNNNE | C77081
C59-C61,C65 | 1uF | Capacitor_SMD:C_0603_1608Metric | Murata | GRM188R71E105KA12D | Yageo CC0603KRX7R8BB105 | C86020
C66 | 100uF 16V | Capacitor_SMD:CP_Elec_6.3x5.8 | Panasonic | EEE-FK1C101P | Lelon VZL101M1CTR-0606 | C128532
C67,C68 | 2.2nF C0G | Capacitor_SMD:C_0603_1608Metric | Murata | GRM1885C1H222JA01D | Samsung CL10C222JB8NNNC | C77033
C79 | 47nF | Capacitor_SMD:C_0603_1608Metric | Yageo | CC0603KRX7R9BB473 | Samsung CL10B473KB8NNNC | C107093
C80 | 4.7nF C0G | Capacitor_SMD:C_0603_1608Metric | Murata | GRM1885C1H472JA01D | TDK CGA3EAC0G2A472JT000E | C85980
C81 | 47pF C0G | Capacitor_SMD:C_0603_1608Metric | Murata | GCM1885C2A470JA16D | FH 0603CG470J500NT | C126580
C83 | 1uF 16V | Capacitor_SMD:C_0603_1608Metric | Murata | GRM188R71E105KA12D | Yageo CC0603KRX7R8BB105 | C86020
C90-C92 | 10uF 10V | Capacitor_SMD:C_0805_2012Metric | Samsung | CL21B106KAYQNNE | Murata GRM21BZ71E106KE15L | C3039694
D1,D10,D12,D14 | B340A 40V 3A | Diode_SMD:D_SMA | Diodes Incorporated | B340A-13-F | LangJie SS34 SMA | C7450457
D2 | SMBJ12A | Diode_SMD:D_SMB | Littelfuse | SMBJ12A
D3 | SS14 | Diode_SMD:D_SMA | Diodes Incorporated | SS14-13-F
D4 | POWER BLUE | LED_SMD:LED_0603_1608Metric | Lite-On | LTST-C190TBKT
D5 | RECORD RED | LED_SMD:LED_0603_1608Metric | Lite-On | LTST-C190KRKT
D6-D9 | PESD12VL1BA | Diode_SMD:D_SOD-323 | Nexperia | PESD12VL1BA,115
D11 | USBLC6-2SC6 | Package_TO_SOT_SMD:SOT-23-6 | STMicroelectronics | USBLC6-2SC6
D13,D15-D19 | 1N4148W | Diode_SMD:D_SOD-123 | Diodes Incorporated | 1N4148W-7-F | ST(Semtech) 1N4148W | C81598
F1 | 750mA PTC | Fuse:Fuse_1206_3216Metric | Littelfuse | 1206L075/13.2WR
F2 | 2A PTC | Fuse:Fuse_1206_3216Metric | Littelfuse | 1206L200/12WR
J1 | 9V DC IN | Connector_BarrelJack:BarrelJack_CUI_PJ-102AH_Horizontal | CUI Devices | PJ-102AH
J2 | AMBISONIC MIC RJ45 | Connector_RJ:RJ45_Amphenol_RJHSE5380 | Amphenol ICC | RJHSE-5380
J3 | MSP3526 TFT 3.5IN 14PIN SOCKET | Connector_PinSocket_2.54mm:PinSocket_1x14_P2.54mm_Vertical | Sullins Connector Solutions | PPTC141LFBN-RC
J4 | 1/4in BINAURAL LINE OUT | Connector_Audio:Jack_6.35mm_Neutrik_NRJ6HF_Horizontal | Neutrik | NRJ6HF
J5 | 1/8in BINAURAL HEADPHONE OUT | Connector_Audio:Jack_3.5mm_CUI_SJ1-3533NG_Horizontal | CUI Devices | SJ1-3533NG
J6 | ANALOG TEST HEADER 2x13 | Connector_PinHeader_2.54mm:PinHeader_2x13_P2.54mm_Vertical | CONNFLY | DS1021-2x13SF11-B | HCTL PZ254-2-13-Z-8.5 | C7430409
J7 | DIGITAL TEST HEADER 2x13 | Connector_PinHeader_2.54mm:PinHeader_2x13_P2.54mm_Vertical | CONNFLY | DS1021-2x13SF11-B | HCTL PZ254-2-13-Z-8.5 | C7430409
J9 | USB-C POWER + DATA | Connector_USB:USB_C_Receptacle_HRO_TYPE-C-31-M-12 | HRO | TYPE-C-31-M-12
J10 | BATTERY 1S LiPo | Connector_JST:JST_PH_B2B-PH-K_1x02_P2.00mm_Vertical | JST | B2B-PH-K-S
K1 | G6K-2F-Y 5VDC | Relay_SMD:Relay_DPDT_Omron_G6K-2F-Y | Omron | G6K-2F-Y DC5
L1 | 2.2uH 1.5A | Inductor_SMD:L_Abracon_ASPIAIG-F4020 | Abracon | ASPIAIG-F4020-2R2M-T
L2 | 10uH 2A | Inductor_SMD:L_Bourns_SRN6045TA | Bourns | SRN6045TA-100M
Q1,Q2 | 2N7002 | Package_TO_SOT_SMD:SOT-23 | Nexperia | 2N7002,215
Q3,Q4 | AO3401A | Package_TO_SOT_SMD:SOT-23 | Alpha & Omega | AO3401A
R1 | 680k | Resistor_SMD:R_0603_1608Metric | Yageo | RC0603FR-07680KL | UNI-ROYAL 0603WAF6803T5E | C25822
R2 | 130k | Resistor_SMD:R_0603_1608Metric | Yageo | RC0603FR-07130KL | UNI-ROYAL 0603WAF1303T5E | C22795
R3,R38-R41,R43,R64,R77,R85,R94,R95 | 100k | Resistor_SMD:R_0603_1608Metric | Yageo | RC0603FR-07100KL | UNI-ROYAL 0603WAF1003T5E | C25803
R4,R14-R17,R86-R90 | 1M | Resistor_SMD:R_0603_1608Metric | Yageo | RC0603FR-071ML | UNI-ROYAL 0603WAF1004T5E | C22935
R5 | 0R CHASSIS LINK | Resistor_SMD:R_0603_1608Metric | Yageo | RC0603FR-070RL | UNI-ROYAL 0603WAF0000T5E | C21189
R6-R9 | 4.7k ELECTRET BIAS | Resistor_SMD:R_0603_1608Metric | Yageo | RC0603FR-074K7L | UNI-ROYAL 0603WAF4701T5E | C23162
R10-R13 | 100R RF | Resistor_SMD:R_0603_1608Metric | Yageo | RC0603FR-07100RL | UNI-ROYAL 0603WAF1000T5E | C22775
R18,R20,R22,R24 | 68k 0.1% | Resistor_SMD:R_0603_1608Metric | Yageo | RT0603BRD0768KL | Panasonic ERA3AEB683V | C705793
R19,R21,R23,R25 | 33k 0.1% | Resistor_SMD:R_0603_1608Metric | Yageo | RT0603BRD0733KL | Vishay TNPW060333K0BEEA | C705768
R26-R29 | 10k 0.1% | Resistor_SMD:R_0603_1608Metric | Yageo | RT0603BRD0710KL | Vishay TNPW060310K0BEEA | C95204
R30-R33 | 90.9k 0.1% | Resistor_SMD:R_0603_1608Metric | Yageo | RT0603BRD0790K9L | Vishay TNPW060390K9BEEA | C728600
R34-R37,R42,R61,R84 | 100R | Resistor_SMD:R_0603_1608Metric | Yageo | RC0603FR-07100RL | UNI-ROYAL 0603WAF1000T5E | C22775
R44,R45 | 4.7k | Resistor_SMD:R_0603_1608Metric | Yageo | RC0603FR-074K7L | UNI-ROYAL 0603WAF4701T5E | C23162
R46-R49,R57-R59,R69 | 33R | Resistor_SMD:R_0603_1608Metric | Yageo | RC0603FR-0733RL | UNI-ROYAL 0603WAF330JT5E | C23140
R50-R53,R60,R70-R74,R79,R81,R83,R96,R97 | 10k | Resistor_SMD:R_0603_1608Metric | Yageo | RC0603FR-0710KL | UNI-ROYAL 0603WAF1002T5E | C25804
R54 | 2.2k | Resistor_SMD:R_0603_1608Metric | Yageo | RC0603FR-072K2L | UNI-ROYAL 0603WAF2201T5E | C4190
R55,R68 | 1k | Resistor_SMD:R_0603_1608Metric | Yageo | RC0603FR-071KL | UNI-ROYAL 0603WAF1001T5E | C21190
R56 | 100R TFT BACKLIGHT | Resistor_SMD:R_0805_2012Metric | Yageo | RC0805FR-07100RL
R62,R63 | 470R | Resistor_SMD:R_0603_1608Metric | Yageo | RC0603FR-13470RL | UNI-ROYAL 0603WAF4700T5E | C23179
R65,R66 | 10R | Resistor_SMD:R_0603_1608Metric | Yageo | RC0603FR-0710RL | FOJAN FRC0603F10R0TS | C2906983
R67 | 100R MIC BIAS FILTER | Resistor_SMD:R_0603_1608Metric | Yageo | RC0603FR-07100RL | UNI-ROYAL 0603WAF1000T5E | C22775
R75,R76 | 5.1k | Resistor_SMD:R_0603_1608Metric | Yageo | RC0603FR-075K1L | UNI-ROYAL 0603WAF5101T5E | C23186
R78 | 47k | Resistor_SMD:R_0603_1608Metric | Yageo | RC0603FR-0747KL | UNI-ROYAL 0603WAF4702T5E | C25819
R80 | 75k | Resistor_SMD:R_0603_1608Metric | Yageo | RC0603FR-0775KL | UNI-ROYAL 0603WAF7502T5E | C23242
R82 | 80.6k | Resistor_SMD:R_0603_1608Metric | Yageo | RC0603FR-0780K6L | Panasonic ERJ3EKF8062V | C403361
R91 | 1.1k ILIM | Resistor_SMD:R_0603_1608Metric | Yageo | RC0603FR-071K1L | UNI-ROYAL 0603WAF1101T5E | C22764
R92 | 1.2k ISET | Resistor_SMD:R_0603_1608Metric | Yageo | RC0603FR-071K2L | UNI-ROYAL 0603WAF1201T5E | C22765
R93 | 10k TS | Resistor_SMD:R_0603_1608Metric | Yageo | RC0603FR-0710KL | UNI-ROYAL 0603WAF1002T5E | C25804
SW2 | RECORD START/STOP | Button_Switch_THT:SW_PUSH-12mm | Omron | B3F-5150
SW3 | MASTER GAIN | Rotary_Encoder:RotaryEncoder_Alps_EC11E-Switch_Vertical_H20mm | Alps Alpine | EC11E15244G1
SW4 | TFT MENU NAV | QuadPreRecorder:SW_Nav5_ALPS_RKJXT1F42001 | Alps Alpine | RKJXT1F42001 |  | C160841
TP1 | USB D+ WIRE TO TEENSY | TestPoint:TestPoint_Pad_2.0x2.0mm
TP2 | USB D- WIRE TO TEENSY | TestPoint:TestPoint_Pad_2.0x2.0mm
U1 | TPS62160DGK | Package_SO:VSSOP-8_3x3mm_P0.65mm | Texas Instruments | TPS62160DGKR
U2 | TPS7A2033PDBV | Package_TO_SOT_SMD:SOT-23-5 | Texas Instruments | TPS7A2033PDBVR
U3 | TLE2426ID | Package_SO:SOIC-8_3.9x4.9mm_P1.27mm | Texas Instruments | TLE2426IDR
U4,U5 | CD4053BPW | Package_SO:TSSOP-16_4.4x5mm_P0.65mm | Texas Instruments | CD4053BPWR
U6 | OPA1654 | Package_SO:TSSOP-14_4.4x5mm_P0.65mm | Texas Instruments | OPA1654AIPWR
U7 | PCM1864DBT | Package_SO:TSSOP-30_4.4x7.8mm_P0.5mm | Texas Instruments | PCM1864DBTR
U8 | Teensy 4.1 | QuadPreRecorder:Teensy41_Socket | PJRC | TEENSY41
U9 | PCM5102A | Package_SO:TSSOP-20_4.4x6.5mm_P0.65mm | Texas Instruments | PCM5102APWR
U10 | TPA6130A2RTJ | Package_DFN_QFN:WQFN-20-1EP_4x4mm_P0.5mm_EP2.7x2.7mm | Texas Instruments | TPA6130A2RTJR
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

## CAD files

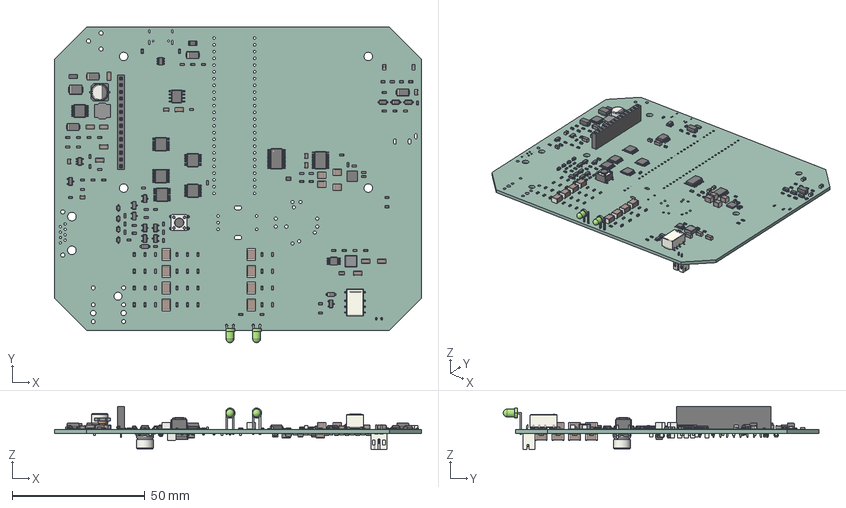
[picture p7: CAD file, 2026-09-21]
hardware/manufacturing/QuadPreRecorder-RevC.step
138.0 x 118.7 x 16.2 mm
R_0603_1608Metric x 122
C_0603_1608Metric x 59
SOT-23 x 9
SOIC-8_3.9x4.9mm_P1.27mm
LED_D3.0mm_Horizontal_O1.27mm_Z6.0mm x 2
C_0805_2012Metric x 14
WQFN-20-1EP_4x4mm_P0.5mm_EP2.7x2.7mm
SW_PUSH_6mm
TSSOP-14_4.4x5mm_P0.65mm x 2
C_1812_4532Metric x 12
Relay_DPDT_Omron_G6K-2F-Y
TSSOP-16_4.4x5mm_P0.65mm x 3
C_1206_3216Metric x 15
D_SOD-323 x 8
Fuse_1206_3216Metric x 2
D_SOD-123 x 7
CP_Elec_63x58 x 2
D_SMA x 5
PinSocket_1x14_P2.54mm_Vertical
SOT-23-6
TSSOP-30_4.4x7.8mm_P0.5mm
L_Bourns_SRN6045TA
C_1210_3225Metric x 4
TSOT-23-5
TSSOP-20_4.4x6.5mm_P0.65mm
L_Abracon_ASPIAIG-F4020
VSSOP-8_3x3mm_P0.65mm
D_SMB
Texas_HTSSOP-14-1EP_4.4x5mm_P0.65mm_EP3.4x5mm_Mask3.155x3.255mm
R_0805_2012Metric
SOT-23-5 x 2
JST_B2B_PH_K
QuadPreRecorder_PCB

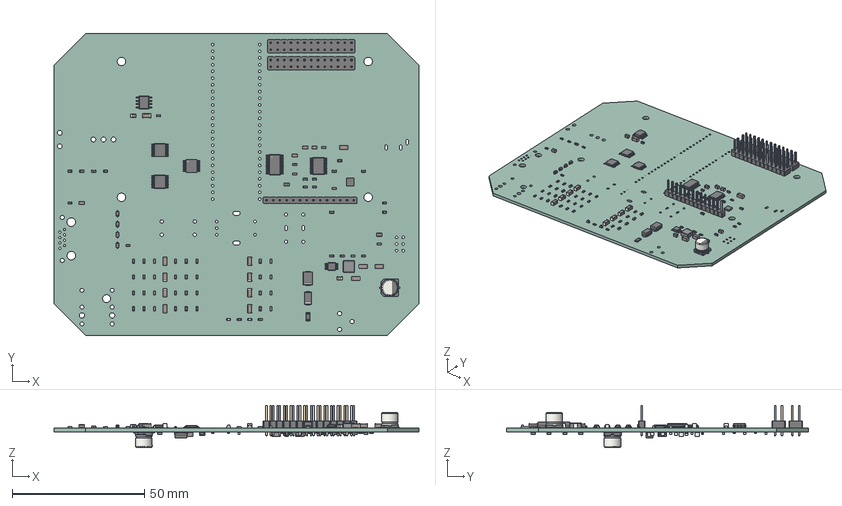
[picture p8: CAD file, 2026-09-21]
hardware/review_outputs/QuadPreRecorder-RevB-12mm.step
138.0 x 114.0 x 16.0 mm
R_0603_1608Metric x 68
D_SOD-323 x 4
C_1206_3216Metric x 18
C_0805_2012Metric x 11
D_SMB
C_0603_1608Metric x 42
SOIC-8_3.9x4.9mm_P1.27mm
TSSOP-30_4.4x7.8mm_P0.5mm
LED_0603_1608Metric x 2
VSSOP-8_3x3mm_P0.65mm
TSSOP-16_4.4x5mm_P0.65mm x 2
CP_Elec_63x58 x 2
WQFN_16_1EP_3x3mm_P05mm_EP16x16mm
TSSOP-14_4.4x5mm_P0.65mm
L_Abracon_ASPIAIG-F4020
PinHeader_1x14_P254mm_Vertical
PinHeader_2x13_P254mm_Vertical x 2
Fuse_1206_3216Metric
R_0805_2012Metric
D_SMA x 2
TSSOP-20_4.4x6.5mm_P0.65mm
SOT-23-5
QuadPreRecorder_PCB

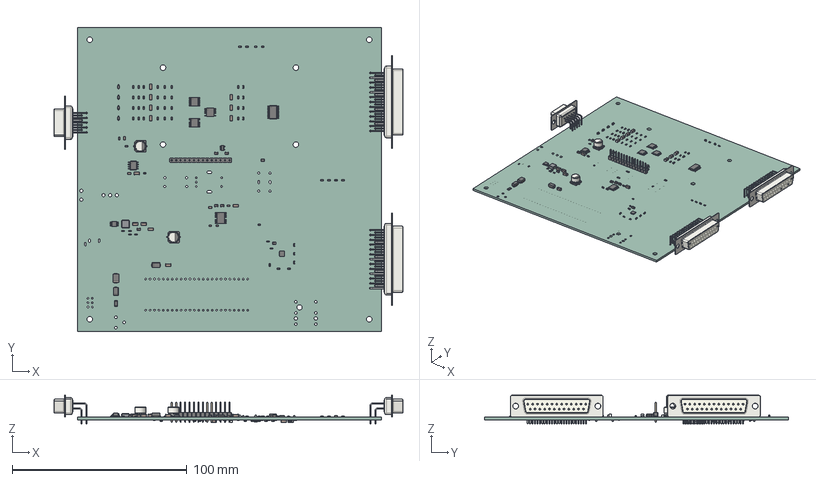
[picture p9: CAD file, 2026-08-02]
hardware/snapshots/hardware_snapshot_step1_before_via_resize_20260801_083059/manufacturing/QuadPreRecorder-RevA.step
199.8 x 174.0 x 16.4 mm
C_1206_3216Metric x 18
R_0603_1608Metric x 68
PinHeader_1x14_P254mm_Vertical
C_0603_1608Metric x 42
D_SOD-323 x 4
R_0805_2012Metric
D_SMB
DSUB-25_Socket_Horizontal_P2.77x2.84mm_EdgePinOffset9.40mm x 2
CP_Elec_63x58 x 2
C_0805_2012Metric x 11
LED_0603_1608Metric x 2
D_SMA x 2
TSSOP-30_4.4x7.8mm_P0.5mm
Fuse_1206_3216Metric
TSSOP-16_4.4x5mm_P0.65mm x 2
SOIC-8_3.9x4.9mm_P1.27mm
WQFN_16_1EP_3x3mm_P05mm_EP16x16mm
TSSOP-14_4.4x5mm_P0.65mm
SOT-23-5
DSUB-9_Socket_Horizontal_P2.77x2.84mm_EdgePinOffset9.40mm
VSSOP-8_3x3mm_P0.65mm
TSSOP-20_4.4x6.5mm_P0.65mm
L_Abracon_ASPIAIG-F4020
QuadPreRecorder_PCB

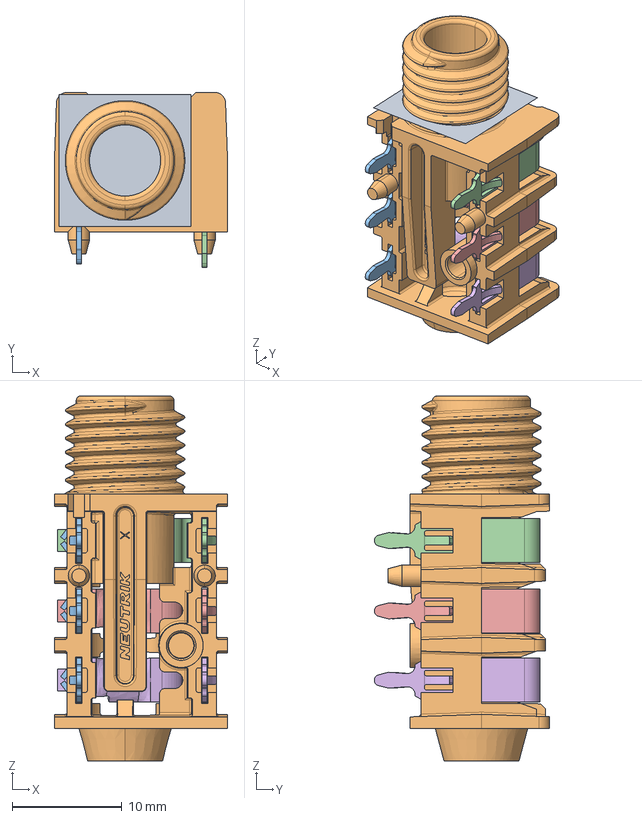
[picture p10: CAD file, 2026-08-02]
hardware/snapshots/hardware_snapshot_step1_before_via_resize_20260801_083059/vendor_assets/NRJ6HF.stp
15.8 x 16.0 x 33.2 mm

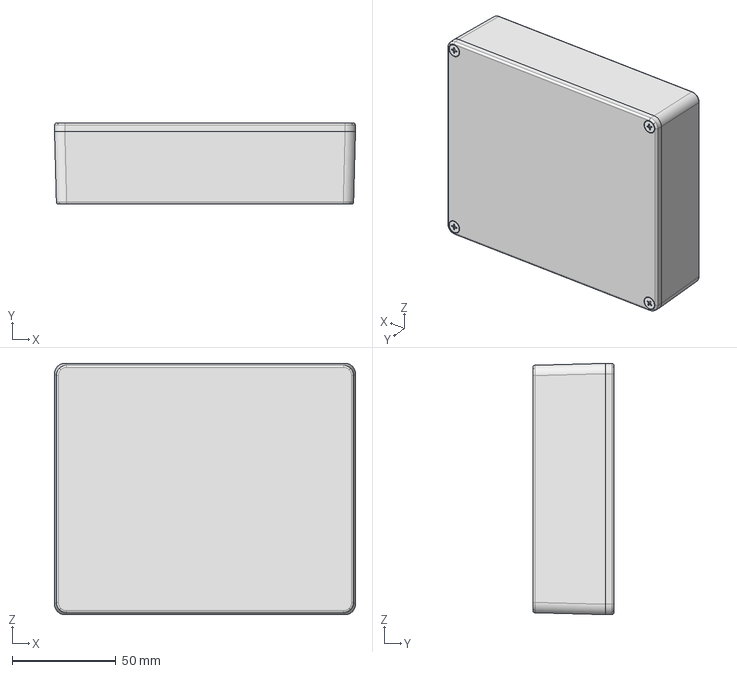
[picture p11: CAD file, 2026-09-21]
hardware/vendor_assets/Hammond-1590XX.step
145.2 x 39.3 x 121.2 mm

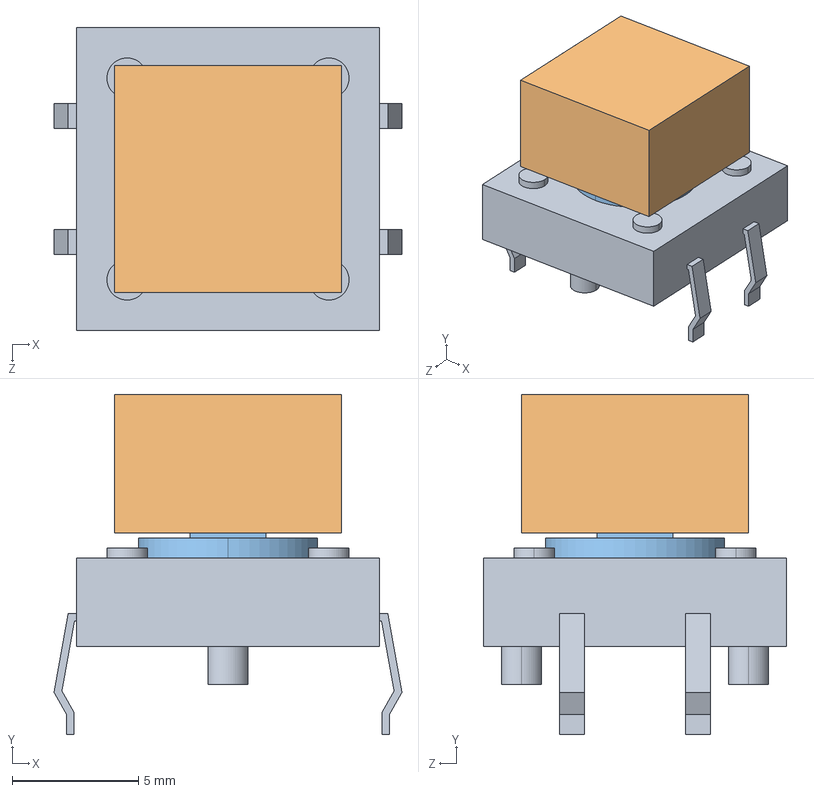
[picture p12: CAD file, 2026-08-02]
hardware/snapshots/hardware_snapshot_step1_before_via_resize_20260801_083059/vendor_assets/B3F-4050.step
13.8 x 13.5 x 12.0 mm
B3F_4050_BASE
B32_1200
B3F_4050_BUTTON

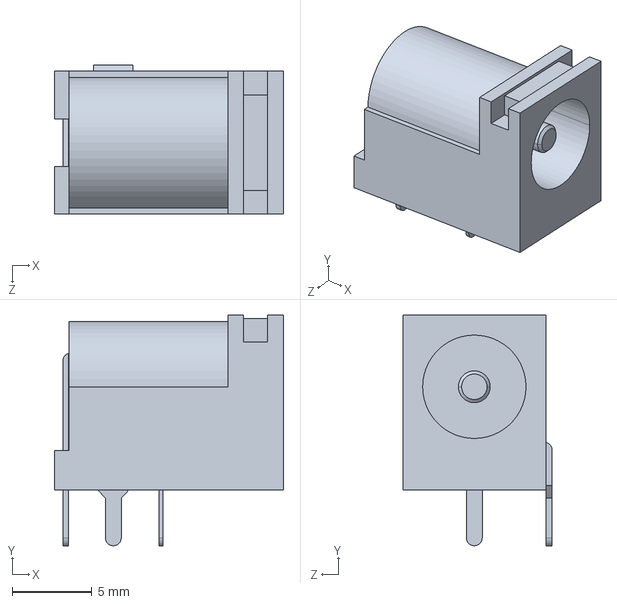
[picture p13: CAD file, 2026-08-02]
hardware/snapshots/hardware_snapshot_step1_before_via_resize_20260801_083059/vendor_assets/PJ-102AH.step
14.4 x 14.5 x 9.40 mm

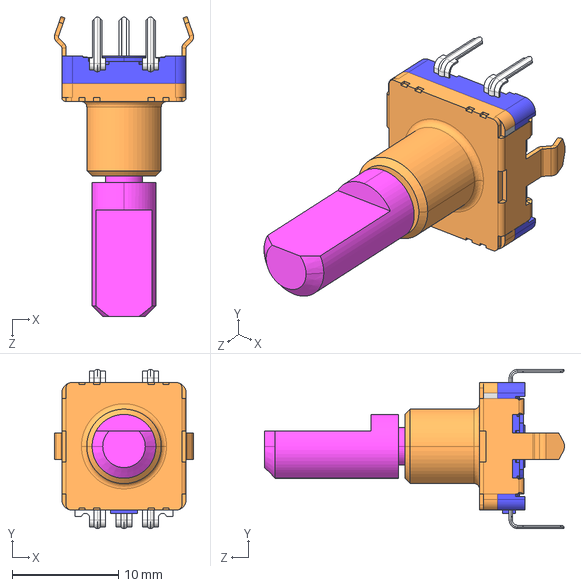
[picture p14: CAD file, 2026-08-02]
hardware/snapshots/hardware_snapshot_step1_before_via_resize_20260801_083059/vendor_assets/EC11E15244G1.step
13.1 x 15.0 x 28.2 mm

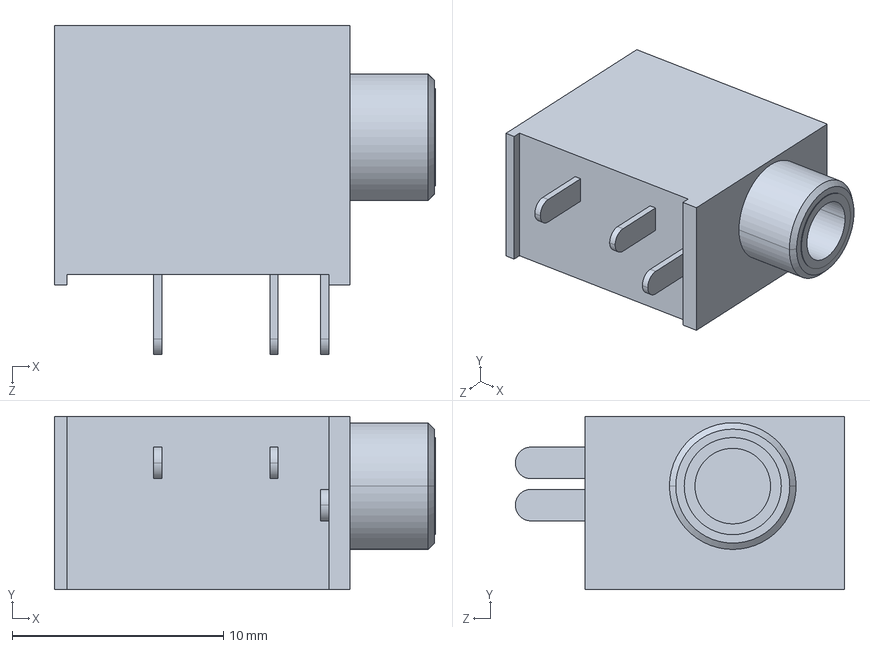
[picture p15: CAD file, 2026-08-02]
hardware/snapshots/hardware_snapshot_step1_before_via_resize_20260801_083059/vendor_assets/SJ1-3533NG.step
18.1 x 8.20 x 15.6 mm

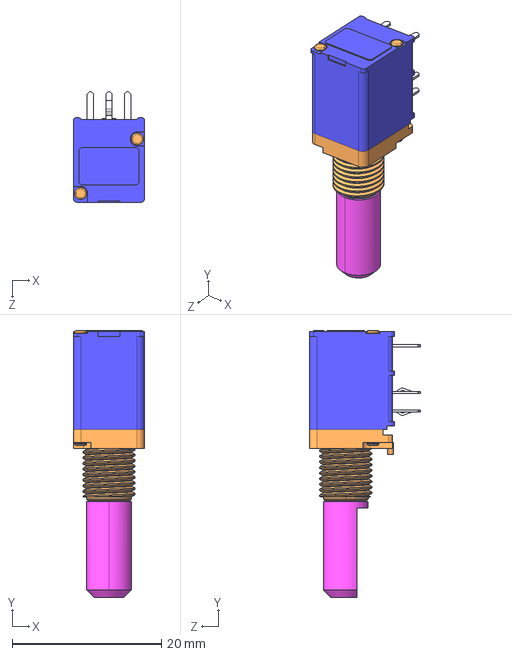
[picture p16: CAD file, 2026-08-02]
hardware/vendor_assets/RK0971221Z0X.step
9.50 x 35.8 x 14.8 mm

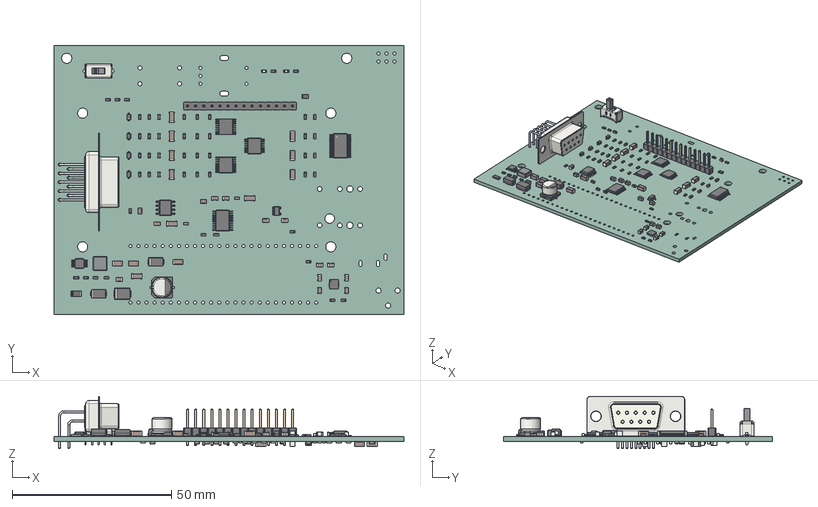
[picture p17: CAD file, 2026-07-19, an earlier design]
hardware/manufacturing/QuadPreRecorder-RevA.step
110.0 x 84.5 x 16.4 mm
R_0603_1608Metric x 64
D_SMA x 2
Fuse_1206_3216Metric
C_0603_1608Metric x 30
SOT-23-5
TSSOP-14_4.4x5mm_P0.65mm
LED_0603_1608Metric x 2
C_1206_3216Metric x 18
R_0805_2012Metric
TSSOP-20_4.4x6.5mm_P0.65mm
PinHeader_1x14_P254mm_Vertical
WQFN_16_1EP_3x3mm_P05mm_EP16x16mm
C_0805_2012Metric x 16
TSSOP-30_4.4x7.8mm_P0.5mm
D_SOD-323 x 4
SOIC-8_3.9x4.9mm_P1.27mm
DSUB-9_Socket_Horizontal_P2.77x2.84mm_EdgePinOffset9.40mm
VSSOP-8_3x3mm_P0.65mm
D_SMB
TSSOP-16_4.4x5mm_P0.65mm x 2
SW_Slide_SPDT_Straight_CK_OS102011MS2Q
CP_Elec_63x58
L_Abracon_ASPIAIG-F4020
QuadPreRecorder_PCB

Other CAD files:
hardware/manufacturing/revb-archive/QuadPreRecorder-RevB.step

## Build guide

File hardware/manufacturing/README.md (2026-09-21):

# PCBWay handoff — QuadPreRecorder Rev C3 (Hammond 1590XX, 4 layers)

Package regenerated 2026-09-12 from the fully routed Rev C3 board with
`tools/build_manufacturing.py` (KiCad 10.0.4 CLI). ERC: 0 errors / 0
warnings. DRC (`--all-track-errors --schematic-parity --severity-error`):
**0 violations, 0 unconnected pads, 0 schematic-parity issues.**

Rev C = Rev B + USB-C power/data (J9, rear wall), 9 V barrel moved to the
rear-left wall (J1), boost + low-noise LDO analog supply (U11/U12), relay
line-out mute (K1), TPA6130A2 I2C headphone amp (U10, no pot), GPIO-driven
pad (Q1, no toggle), the LCDWiki **MSP3526 capacitive** display in a
socket (J3), and an internal LiPo battery (J10, BQ24074 charger U13) with a
two-button soft-power latch (Q3/Q4). Rev B outputs are archived in `revb-archive/`.

Rev C2 (2026-09-08/11) made it a 4-layer board and fixed the enclosure fit.
Rev C3 (2026-09-12) is the audio-audit fix pass
(`../reviews/audio-rules-check-revC3-fixes.md`): the J6/J7 test headers are
gone, In2.Cu is a second solid GND plane (SIG/GND/GND/SIG), the converters'
digital rail has its own LDO (U14, +3V3_DC), every converter decoupler sits
under its pin, U10's exposed pad has its via array, and the eight
channel-coupling caps plus the four headphone-input caps are Rubycon PMLCAP
film instead of X7R.

What is still a **human** check before you click order: the board has never
been test-fitted in a real 1590XX box, and three Rev C circuits want a bench
look (see "Before ordering" at the end and
`../reviews/rev-c-preorder-review.md`).

## Order configuration

| Setting | Value |
|---|---|
| Board size | 138.0 x 114.0 mm, 12 mm corner chamfers (Hammond 1590XX max PCB envelope) |
| Layers | 4: F.Cu signal / In1.Cu solid GND / In2.Cu solid GND / B.Cu signal |
| Stackup | Standard 1.6 mm 4-layer: 35 um Cu, ~0.21 mm prepreg / ~1.07 mm core / ~0.21 mm prepreg (written into the board file; no impedance control) |
| Material | FR-4 |
| Finished thickness | 1.6 mm |
| Copper | 1 oz outer and inner |
| Minimum track / clearance (actual) | 0.20 mm / 0.15 mm (supply rails 0.30 mm) — PCBWay standard floor is 0.10 / 0.10 |
| Minimum via (actual) | 0.60 mm pad / 0.30 mm drill (0.15 mm annular) for the 185 decoupling/thermal/escape vias; 0.80 / 0.40 elsewhere (338); PCBWay floor 0.30 / 0.15 / 0.15 |
| Copper-to-edge | ≥ 0.65 mm (rule-area keepouts; PCBWay asks ≥ 0.30 mm) |
| Surface finish | Lead-free HASL for lowest cost; ENIG is an acceptable upgrade |
| Solder mask / silkscreen | Green / white |
| Assembly | Two-sided mixed SMT and through-hole: 293 placements (180 top, 113 bottom) |
| Stencil | Both sides — U8 (Teensy 4.1 sockets), TP1/TP2 and the bottom-side passives are on the back |

Upload `QuadPreRecorder-RevC-Gerbers.zip` as the PCB file (or the full
`QuadPreRecorder-RevC-PCBWay-handoff.zip`). Upload `QuadPreRecorder-BOM.csv`
and `QuadPreRecorder-CPL-PCBWay.csv` to the assembly quote, and attach
`QuadPreRecorder-BOM-extras.csv` (the U8 socket sub-assembly, the USB wire
step, and the loose off-board parts you want PCBWay to quote and ship with
the boards). `PCBWAY-ORDER-NOTES-REVC.txt` has the paste-ready order text.

The Gerber archive includes top/bottom paste layers, an IPC-D-356 electrical
netlist, Excellon PTH/NPTH drills with maps, and the job file. Three 1 mm
global fiducials are present on each assembly side and intentionally omitted
from the BOM/CPL. Placement CSVs use KiCad's coordinate convention (Y grows
downward, so "Mid Y" is negative) — PCBWay's importer handles this; confirm
the placement preview during quoting.

## Assembly instructions

- `R5` is DNP (do not populate). It is the optional direct CHASSIS-to-GND link.
- `R38`-`R41` are DNP.
- `U8` (Teensy 4.1) is on the bottom. `J4` (6.35 mm line jack) is on the
  **top** side at the front wall.
- `U8` is a **socketed sub-assembly** (see `QuadPreRecorder-BOM-extras.csv`):
  solder two Samtec **SLW-124-01-G-S** low-profile 1x24 sockets into the U8
  footprint (bottom side, rows 15.24 mm apart; corrected 2026-09-15), then plug a PJRC
  **TEENSY41_PINS** (Teensy 4.1 with the outer 2x24 pins pre-soldered) into
  them, microSD slot toward the rear wall (Y=0 edge, silkscreen "SD CARD SLOT
  THIS EDGE"). **Before** plugging it in: cut the Teensy's underside VIN-VUSB
  link pad, and solder two ~20 mm wires from the Teensy's underside "USB
  Device" D+ / D- pads to the board's bottom-side pads **TP1 (D+)** and **TP2
  (D-)** next to the socket. The Teensy is customer-supplied if PCBWay cannot
  source PJRC parts.
- `J3` is a 1x14, 2.54 mm **female socket** (Sullins PPTC141LFBN-RC). The
  LCDWiki **MSP3526** module plugs into it later, on 11 mm M3 standoffs over
  H5-H8; it is requested from PCBWay as a **loose, off-board** part. Do not
  solder a display at assembly.
- `J9` is an HRO TYPE-C-31-M-12 USB-C receptacle (16-pin, through-hole shell
  tabs). `K1` is an Omron G6K-2F-Y DC5 signal relay — keep the exact part
  (pinout and coil polarity matter; coil pin 1 = +).
- `J10` (JST-PH, bottom side) takes the customer-supplied 3.7 V 5000 mAh
  906090 LiPo pouch (with PCM). Do not fit a battery at assembly. `U13`
  (BQ24074, QFN with exposed pad) is the charger.
- There are no test headers (J6/J7 were removed in Rev C3). Twelve bare 1.5 mm probe pads `TP3`-`TP14` sit on the **bottom** (ADC clocks at x=124, DAC clocks north of R57-R59, +3V3_DC and three grounds); they are not in the BOM or CPL.
- `U10` (TPA6130A2, WQFN) has a 3x3 array of 0.3 mm vias in its exposed pad. Keep them tented on the bottom side so paste does not wick through.
- `C17`-`C20`, `C25`-`C28`, `C57`, `C58`, `C86`, `C87` are Rubycon **PMLCAP film** chips (1812 / 1210), not MLCCs. Do not substitute ceramics. LCSC C3778321 / C3778570 are the cheap source; the 16 V siblings (16MU475MC14532 / 16MU225MB23225, DigiKey/Mouser) are acceptable alternates.
- Through-hole panel parts: J1 (CUI PJ-102AH barrel, rear-left), J2 (RJHSE-5380
  RJ45, left), J4 (Neutrik NRJ6HF, front), J5 (CUI SJ1-3533NG, right), SW2
  (12 mm tactile), SW3 (Alps EC11E encoder), SW4 (Alps SKQUCAA010 5-way nav,
  internal only).
- Use the exact listed ICs (U1, U4-U7, U9-U13). Generic resistors/capacitors
  may be substituted with the same value, package, voltage rating, dielectric
  and tolerance. Keep each four-part 0.1% resistor set from one lot.
- Do not substitute the electret ESD parts with high-capacitance TVS diodes.
- Verify pin 1/orientation for U1, U4-U7, U9-U13 and K1 before reflow.
- The STEP export uses the stock KiCad 3D models; several connectors have no
  model and appear as bare footprints. Check the real panel parts during
  enclosure layout.

## Parts not standardized by the PCB

- Display: LCDWiki MSP3526 (ST7796U + FT6336U capacitive, 5 V). H5-H8 are on
  the 92.0 x 49.5 mm pattern from the LCDWiki drawing; the socket J3 sits
  2.0 mm inside the module's left edge. Compare the purchased module (pin
  order, header position, pin length, hole pattern) before drilling the lid
  or buying standoffs.
- The board targets the Hammond 1590XX (138 x 114 mm PCB envelope). Check
  `QuadPreRecorder-RevC.step` against the real box before drilling any wall
  (`../enclosure-1590XX-desk-study.md`, `../enclosure-1590XX-fit-viewer.html`).
- The mating microphone cable is a shielded CAT6 cord with an 8P8C (RJ45)
  plug; it must preserve the pinout in `connector-pinout.md`.
- A metal enclosure must bond to the RJ45 jack shell (SH pin) and the USB-C
  shell (both on the CHASSIS net) at the connector.

## Power and safety note

Power from a regulated centre-positive 9 VDC / 1 A barrel supply, a 5 V USB-C
source (any charger, power bank or computer port; ~450 mA plus up to 0.74 A
of battery charging), or the internal 1S LiPo (6-7 h). Any combination may
be connected at once; only USB charges the battery. On battery, hold RECORD
and the encoder push for 2 s to switch on or off. Use only a pouch with its
own protection circuit and check the pigtail polarity against J10 pin 1. The Teensy's VIN-VUSB link **must** be cut (the board
powers VIN). Never plug a cable into the Teensy's own micro-B while J9 is in
use — they carry the same D+/D-.

## Required Rev C bring-up

1. Power from the barrel without U8, TFT or microphone: verify VBOOST_IN,
   +10.45 V (U11), +9 V (U12), +5 V, +3.3 V analog and the 4.5 V reference.
   Scope the 10.45 V rail with a 0 → 200 mA load step (no ringing).
2. Repeat from USB-C 5 V only (a charger). Check the input current (~450 mA
   without a battery). Then plug in the LiPo: VBAT rises, /CHG low, U13 warm
   but not hot (it throttles at 125 °C junction); unplug USB and confirm the
   unit stays up on the battery only while RECORD + encoder push are held
   (until firmware asserts KEEP_ON).
3. Fit U8 (wires to TP1/TP2, VUSB link cut) and verify the +3.3 V digital
   rail, I2C to U7 (ADC), U10 (0x60) and the touch controller (0x38), and USB
   enumeration through J9.
4. Configure U7 for four-channel TDM and verify all clocks (192 kHz 4-ch TDM
   pushes BCK to 49.152 MHz; 96 kHz TDM or 192 kHz via 2x I2S are the safe
   modes — `../reviews/rev-a-final-review.md`, A.1).
5. Confirm relay K1: line out passes audio with the coil OFF and is silent
   with LINE_MUTE high. Confirm PAD_CTRL high inserts the pad (−9.7 dB).
6. Inject the same low-level sine into all four inputs; measure gain, pad,
   polarity, noise, crosstalk and clipping.
7. Verify sustained four-file SD writes on the exact microSD card, then MTP
   access to the same card from a computer over J9.
8. Fit the headphone path: TPA6130A2 volume steps, mute, /SD, into a dummy
   load first.
9. Only then connect the electret microphone after confirming its bias
   polarity and current.

## Before ordering — open items (2026-09-08)

1. **Physical 1590XX fit has not been checked.** Print
   `../exports/QuadPreRecorder-top.pdf` / `-bottom.pdf` at 100%, sit the paper
   in the real box, and check the J1/J9 (rear), J2 (left), J5 (right), J4
   (front) wall positions, the lid window for the MSP3526 lens, SW2/SW3
   reach (SW4 gets no lid hole), and the SD slot at the rear wall.
2. Confirm the purchased MSP3526 module (pin order, header position, pin
   length → standoff height, 92.0 x 49.5 holes).
3. Confirm the CAT6 cable/plug against the RJHSE-5380 jack.
4. Decide surface finish and quantity; get the assembly quote. PCBWay turnkey
   buys by MPN from global distributors, so the Neutrik, Alps, CUI, Amphenol,
   Omron and HRO parts are normally sourceable — keep "accept substitutes"
   set to NO for them.
5. microSD access: the Teensy's own slot faces the rear wall; if it is not
   finger-reachable through the wall slot, files can also be pulled over
   USB-C (MTP) — the extender is no longer needed.

Pre-order review: `../reviews/rev-c-preorder-review.md`.

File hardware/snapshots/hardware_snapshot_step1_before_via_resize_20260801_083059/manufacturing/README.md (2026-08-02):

# PCBWay handoff — QuadPreRecorder Rev A

Mechanical note: this handoff targets a Hammond 1590F mechanical-fit prototype.
The board-mounted panel parts have been moved to real board edges, but the
physical enclosure stackup still needs a human check against the STEP export,
the actual Hammond box, the connector shells, the lid standoffs, and the
purchased TFT module before ordering.

## Order configuration

| Setting | Value |
|---|---|
| Board size | 174.0 x 174.0 mm |
| Layers | 2 |
| Material | FR-4 |
| Finished thickness | 1.6 mm |
| Copper | 1 oz outer layers |
| Minimum track / clearance | 0.20 mm / 0.15 mm |
| Minimum finished via drill | 0.40 mm |
| Surface finish | Lead-free HASL for lowest cost; ENIG is an acceptable upgrade |
| Solder mask / silkscreen | Green / white |
| Assembly | Two-sided mixed SMT and through-hole assembly |
| Stencil | Both sides if PCBWay assembles U8 and J4 on the bottom |

Upload `QuadPreRecorder-RevA-Gerbers.zip` as the PCB file. Upload
`QuadPreRecorder-BOM.csv` and `QuadPreRecorder-CPL-PCBWay.csv` to the assembly
quote.

Current export caveat: after the Hammond 1590F mechanical-fit rework, the
Gerbers, drills, BOM, placement CSVs, schematic PDF, assembly PDFs, STEP,
connector pinout, mechanical notes, ERC/DRC reports, and
`QuadPreRecorder-RevA-PCBWay-handoff.zip` were refreshed from the corrected
KiCad board with KiCad 10.0.4 CLI. ERC is clean. DRC has no shorts, no
clearance/edge/hole/mask errors, no unconnected pads, and no schematic-parity
issues.

The Gerber archive also includes top/bottom paste layers and an IPC-D-356
electrical netlist. Three 1 mm global fiducials are present on each assembly
side and intentionally omitted from the BOM/CPL.

## Assembly instructions

- `R5` is DNP (do not populate). It is the optional direct CHASSIS-to-GND link.
- `U8` (Teensy 4.1) and `J4` (6.35 mm line jack) are mounted on the bottom.
- `U8` must be a genuine PJRC Teensy 4.1. It may be customer-supplied to PCBWay.
  If serviceability is preferred, install two low-profile 1x24 female headers
  instead and insert the module after assembly; record that substitution on the
  order because the CPL lists the module itself.
- `J3` is only the 1x14, 2.54 mm display header. The target module is the
  LCDWiki MSP2834 ILI9341/FT6336G capacitive-touch TFT, user-supplied and
  installed after the exact module revision and pin order are verified.
- `J6` and `J7` are right-angle DB-25 external debug sockets. `J6` carries
  analog stage nodes; `J7` carries clocks, serial buses, and control/status
  signals. Pin 25 is an extra ground/reference pin on both connectors.
- Use the exact listed ICs. Generic resistors/capacitors may be substituted with
  the same value, package, voltage rating, dielectric, and tolerance. Keep each
  four-part 0.1% resistor set from one manufacturer lot.
- Do not substitute the electret ESD parts with high-capacitance TVS diodes.
- Verify pin 1/orientation for U1, U4-U7, U9, and U10 before reflow.
- The PCB has intentional dense silkscreen. PCBWay may clip ink away from pads;
  use the assembly PDFs for reference designators.
- The STEP export includes the local vendor models for J1, J4, J5, RV1, SW2,
  and SW3. Still check those real parts directly during enclosure layout,
  especially the panel protrusion and cable-clearance geometry.

## Parts not standardized by the PCB

- The display mounting pattern is a nominal 78 x 42 mm rectangle. Low-cost
  2.8-inch TFT modules vary; compare the purchased module before drilling.
- The board targets Hammond 1590F, not the original 1590BB2-sized envelope.
  Check the STEP file and the real DB-25 cable exit path before drilling.
- The DE-9 cable plug must mate with the board's female socket and preserve the
  exact pinout in `../connector-pinout.md`.
- A metal enclosure must bond to the DE-9 shell/pin 5 at the connector. The four
  capsule returns are circuit ground, not shield conductors.

## Power and safety note

Use a regulated, center-positive 9 VDC supply rated for at least 1 A. Do not
connect the 9 V barrel input and Teensy USB power at the same time unless the
Teensy VIN-to-VUSB link is cut. USB data remains usable after that separation.

## Required Rev A bring-up

1. Power without U8, TFT, or microphone and verify +5 V, +3.3 V analog, and the
   4.5 V virtual reference.
2. Fit U8 and verify the +3.3 V digital rail and I2C communication with U7.
3. Configure U7 for four-channel, 192 kHz, 24-bit, 4-slot TDM and verify all
   clocks with an oscilloscope.
4. Inject the same low-level sine into all four inputs; measure gain, pad amount,
   polarity, noise, crosstalk, and clipping.
5. Verify sustained four-file SD writes on the exact microSD card.
6. Fit the DAC/headphone path, verify mute/enable sequencing, and test first
   into a dummy load.
7. Only then connect the electret microphone after confirming its bias polarity
   and current.

Rev A has clean automated ERC/parity reports and DRC is electrically and
fabrication clean. (An earlier note about headphone-cluster courtyard overlaps
referred to the pre-1590F compact layout; the current board was re-checked on
2026-07-25 and has zero courtyard overlaps.) It has not yet completed this
physical validation — see `../enclosure-stackup-and-templates.md` for the
desk-study results, the required PCB/BOM changes (H5-H8 TFT hole pattern, J2
DE-9 part number, SW2/SW1 lid reach), and the printable drill templates.

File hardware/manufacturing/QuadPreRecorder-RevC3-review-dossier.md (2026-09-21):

# QuadPreRecorder Rev C3 (board `revc3teensy-final`, 2026-09-15): design review dossier

Generated 2026-09-15 from the exact files in the PCBWay handoff zip of 2026-09-15 (`hardware/QuadPreRecorder.kicad_sch` and `.kicad_pcb`, backup `QuadPreRecorder.kicad_pcb.revc3teensy-final-20260915`; the 2026-09-13 board and zip are void, see section 4). Every table below is read straight out of those files by the analyzers, then cross-checked against the board's pad-to-net data, so what you are reviewing is what will be built.

## 0. How to use this

The document is long on purpose. Sections 1 to 3 are the design as intended (in words and numbers), sections 4 to 9 are the design as drawn (every pin of every IC, transistor, diode and connector with the net it lands on and what is at the other end of that net), sections 10 to 13 are the arithmetic (set points, corners, currents), and sections 14 to 19 are the board, the checks, the parts and the bring-up list. If you only have an hour: read section 1, then check sections 4, 6 and 10 against the datasheets. Those are where a wrong pin or a wrong resistor would hide.

Files that go with this dossier: `QuadPreRecorder-schematic.pdf` (the schematic as drawn), `QuadPreRecorder-assembly-top.pdf` / `-bottom.pdf` (reference designators on the board), `QuadPreRecorder-top.png` / `-bottom.png` / `-isometric.png` (renders), and the PCBWay files delivered on 2026-09-15 (the 2026-09-13 set is void: it carried the wrong Teensy socket).

## 1. What the board is, in one page

A four-channel ambisonic microphone preamplifier and 192 kHz / 24-bit recorder for a Hammond 1590XX box. Four capsules (electret with on-board bias, or dynamic/balanced with the bias off) come in on one shielded RJ45. Each channel is a two-op-amp instrumentation stage (OPA1654, +20.1 dB, switchable -9.7 dB pad) into a PCM1864 four-channel ADC. A Teensy 4.1 records four mono WAVs to microSD over native SDIO, drives a 3.5-inch capacitive touch TFT, and decodes a real-time binaural monitor mix out of a PCM5102A DAC to a relay-muted 1/4-inch line jack and a TPA6130A2 I2C-volume headphone amp. Power is 9 V barrel, USB-C 5 V, or an internal 1S LiPo (BQ24074 charger), all boosted to 10.45 V and then regulated to a low-noise 9 V analog rail, a 5 V buck rail and two 3.3 V LDO rails for the converters.

| Item | Value |
|---|---|
| Board | 138.0 x 114.0 mm, 12 mm chamfered corners, 4 layers (F.Cu signal / In1.Cu GND / In2.Cu GND / B.Cu signal), 1.6 mm FR-4 |
| Schematic | 312 components, 93 unique parts, 213 nets, 1 DNP line, 0 missing MPN |
| PCB | 322 footprints (188 top / 134 bottom), 292 SMD + 12 THT, 523 vias, 3050 track segments, 10.6 m of track, 20 zones |
| Assembly | 293 placements (180 top, 113 bottom); BOM 95 lines, all with manufacturer part numbers; DNP R5, R38-R41 |
| Checks | ERC 0 errors / 0 warnings. DRC 0 violations / 0 unconnected / 0 parity at error severity; 220 cosmetic warnings (section 15). GND: 184 pads, one cluster |
| Firmware pins | Teensy 4.1: see section 8 |

## 2. Power tree (design intent, with the numbers to check)

```
J1 9 V barrel --F1 750 mA PTC--> +9V_FUSED --D1 B340A--+
                                                       |
J9 USB-C VBUS --F2 2 A PTC--> VBUS_FUSED --D10 B340A---+--> VBOOST_IN (5..9 V) --> U11 TPS61175 boost --> +10V5 (10.45 V)
                    |                                  |                                                   |
                    +--> U13 BQ24074 charger --> BAT_SYS --D14 B340A--+                +----------------------+----------------------+
                             |                                                         |                                             |
                    J10 1S LiPo (VBAT) ---> U13 (power path)                U12 ADP7142 LDO --> +9V (9.0 V analog)      U1 TPS62160 buck --> +5V (5.0 V)
                                                                                       |                                    |         |         |
                                                                          preamps U6/U16, U3 VREF (4.5 V),     U2 TPS7A2033 --> +3V3_A   U14 TPS7A2033 --> +3V3_DC   D3 SS14 --> TEENSY_VIN
                                                                          CD4053 U4/U5/U15, Q6 9 V mic bias     (PCM1864 AVDD, PCM5102A AVDD)  (PCM1864 DVDD/IOVDD, PCM5102A DVDD)  (Teensy 4.1, whose own
                                                                          +9V_MIC (R67/C66 filter)             Q8 5 V mic bias, TPA6130A2, relay K1, TFT VCC/backlight   regulator makes +3V3_D)
```

| Rail | Source | Set by | Nominal | Feeds |
|---|---|---|---|---|
| VBOOST_IN | D1 / D10 / D14 OR-ing (barrel, USB, battery) | diodes | 4.4 to 8.7 V | U11 boost only (plus D2 SMBJ12A clamp, C1 100 uF, C85 10 uF) |
| +10V5 | U11 TPS61175 boost | R80 75k / R81 10k on 1.229 V ref | 10.45 V | U12 LDO input, U1 buck input |
| +9V | U12 ADP7142 LDO | R130 130k / R131 20k on 1.2 V ref | 9.00 V | U6, U16 (op-amps), U3 (VREF), U4/U5/U15 (CD4053), Q6 (9 V mic bias), R106/R83 pull-ups |
| VREF | U3 TLE2426 rail splitter from +9V | fixed 1/2 | 4.50 V | analog mid-rail for every channel (1M, 33k, 90.9k, 100k returns) |
| +9V_MIC | Q6 (9 V) or Q8+D24 (5 V) into R67 100R / C66 100 uF | firmware | 9.0 / ~4.7 / 0 V | R6-R9 4.7k electret bias per channel, R104 100k bleed |
| +5V | U1 TPS62160 buck from +10V5 | R1 680k / R2 130k on 0.8 V ref | 4.98 V | U2, U14, D3 -> Teensy VIN, U10 headphone amp, K1 relay, Q8 5 V bias, J3 TFT VCC, R56 backlight, D4 power LED |
| +3V3_A | U2 TPS7A2033 (fixed 3.3 V) from +5V | fixed | 3.30 V | PCM1864 AVDD (pin 8), PCM5102A AVDD (pins 1, 8) |
| +3V3_DC | U14 TPS7A2033 (fixed 3.3 V) from +5V | fixed | 3.30 V | PCM1864 DVDD/IOVDD (13, 14), PCM5102A DVDD (20), TP12 |
| +3V3_D | Teensy 4.1 on-module regulator | Teensy | 3.30 V | every pull-up to the Teensy (I2C, buttons, nav, charger status) |
| TEENSY_VIN | +5V through D3 SS14 | diode | ~4.7 V | Teensy VIN (its VIN-VUSB link must be CUT) |
| ADC_LDO, DAC_LDO, ADC_VREF | PCM1864 / PCM5102A internal regulators | chips | 1.8 V class | decoupling only (C43/C62, C53, C39/C40) |
| VBAT / BAT_SYS | J10 battery / U13 power-path output | charger | 3.0-4.2 V / 4.4 V | U13, D14, R89/R90 gauge, Q3/Q4 soft-power latch |

## 3. Rail membership, as drawn

Every component pin that touches each supply rail, from the schematic netlist. Use this to spot a part on the wrong rail.

- **+10V5** (11 pins): C2.1, C3.1, C76.1, C77.1, C83.1, D12.1, R80.1, U1.2/3, U12.1/3
- **+9V** (21 pins): C34.1, C35.1, C36.1, C37.1, C74.1, C75.1, C88.1, C109.1, C110.1, Q6.2, R83.1, R98.1, R106.1, R130.1, U3.3, U4.16, U5.16, U6.4, U12.5, U15.16, U16.4
- **VREF** (27 pins): C10.1, C11.1, C105.2, C106.2, C107.2, C108.2, R14.2, R15.2, R16.2, R17.2, R19.2, R21.2, R23.2, R25.2, R114.2, R115.2, R116.2, R117.2, R122.2, R123.2, R124.2, R125.2, R126.2, R127.2, R128.2, R129.2, U3.1
- **+9V_MIC** (7 pins): C66.1, R6.1, R7.1, R8.1, R9.1, R67.2, R104.1
- **+5V** (25 pins): C4.1, C5.1, C6.1, C7.1, C61.1, C65.1, C95.1, D3.2, D13.1, J3.1, K1.1, L1.2, Q8.2, R1.1, R3.1, R54.1, R56.1, R101.1, U1.6, U2.1/3, U10.20/12, U14.1/3
- **+3V3_A** (10 pins): C8.1, C41.1, C42.1, C54.1, C55.1, C64.1, U2.5, U7.8, U9.1/8
- **+3V3_DC** (9 pins): C44.1, C45.1, C56.1, C96.1, TP12.1, U7.13/14, U9.20, U14.5
- **+3V3_D** (16 pins): R44.1, R45.1, R50.1, R51.1, R52.1, R53.1, R70.1, R71.1, R72.1, R73.1, R74.1, R94.1, R95.1, R96.1, R97.1, U8.3V3A
- **TEENSY_VIN** (3 pins): C46.1, D3.1, U8.VIN
- **VBOOST_IN** (8 pins): C1.1, C85.1, D1.1, D2.1, D10.1, D14.1, L2.1, U11.3
- **VBUS** (7 pins): D11.5, F2.1, J9.A4/A9/B4/B9, R77.1
- **VBUS_FUSED** (6 pins): C90.1, D10.2, D16.2, F2.2, U13.5/13
- **VBAT** (8 pins): C92.1, J10.1, Q3.2, R86.1, R87.1, R89.1, U13.2/3
- **BAT_SYS** (4 pins): C91.1, D14.2, U13.10/11
- **CHASSIS** (21 pins): C12.1, C13.2, C14.2, C15.2, C16.2, C97.2, C98.2, C99.2, C100.2, D6.2, D7.2, D8.2, D9.2, D20.2, D21.2, D22.2, D23.2, J2.SH, J9.SH, R4.1, R5.1

- **GND**: 183 pins on 137 components (not listed).

## 4. Integrated circuits, pin by pin

For every pin: the schematic net, what else sits on that net, and the net the PCB pad actually carries. The two net columns must agree on every row (they do: the parity check passed). The notes give the datasheet pin function to compare against; where I was not certain of a datasheet pin name I said so rather than guess.

### U11 TPS61175PWP (TPS61175PWPR) - Texas_HTSSOP-14-1EP_4.4x5mm_P0.65mm_EP3.4x5mm_Mask3.155x3.255mm

*TPS61175PWP boost. Datasheet (TI SLVS892): 1/2 SW, 3 VIN, 4 EN (abs max 20 V, VIH 1.2 V), 5 SS, 6 SYNC (tie to AGND when unused), 7 AGND, 8 COMP, 9 FB (1.229 V), 10 FREQ, 11 NC (must be grounded), 12-14 PGND, pad = AGND. As wired: every row matches; SYNC and NC are grounded as the datasheet asks.*

| Pin | Symbol pin name | Schematic net | Other ends of that net | PCB pad net |
|---:|---|---|---|---|
| 1 | SW | BOOST_SW | D12.2 (A), L2.2 | BOOST_SW |
| 2 | SW | BOOST_SW | D12.2 (A), L2.2 | BOOST_SW |
| 3 | VIN | VBOOST_IN | C1.1, C85.1, D1.1 (K), D2.1 (A1), D10.1 (K), D14.1 (K), L2.1 | VBOOST_IN |
| 4 | EN | BOOST_EN | D15.1 (K), D16.1 (K), D17.1 (K), Q4.3 (D), R88.1 | BOOST_EN |
| 5 | SS | BOOST_SS | C79.1 | BOOST_SS |
| 6 | SYNC | GND | C1.2, C2.2, C3.2, C5.2, C6.2, C7.2, C8.2, C9.2, C10.2, C11.2, C12.2, C29.2, C30.2, C31.2, ... (+162 more) | GND |
| 7 | AGND | GND | C1.2, C2.2, C3.2, C5.2, C6.2, C7.2, C8.2, C9.2, C10.2, C11.2, C12.2, C29.2, C30.2, C31.2, ... (+162 more) | GND |
| 8 | COMP | BOOST_COMP | C81.1, R79.1 | BOOST_COMP |
| 9 | FB | BOOST_FB | R80.2, R81.1 | BOOST_FB |
| 10 | FREQ | BOOST_FREQ | R82.1 | BOOST_FREQ |
| 11 | NC | GND | C1.2, C2.2, C3.2, C5.2, C6.2, C7.2, C8.2, C9.2, C10.2, C11.2, C12.2, C29.2, C30.2, C31.2, ... (+162 more) | GND |
| 12 | PGND | GND | C1.2, C2.2, C3.2, C5.2, C6.2, C7.2, C8.2, C9.2, C10.2, C11.2, C12.2, C29.2, C30.2, C31.2, ... (+162 more) | GND |
| 13 | PGND | GND | C1.2, C2.2, C3.2, C5.2, C6.2, C7.2, C8.2, C9.2, C10.2, C11.2, C12.2, C29.2, C30.2, C31.2, ... (+162 more) | GND |
| 14 | PGND | GND | C1.2, C2.2, C3.2, C5.2, C6.2, C7.2, C8.2, C9.2, C10.2, C11.2, C12.2, C29.2, C30.2, C31.2, ... (+162 more) | GND |
| 15 | EP | GND | C1.2, C2.2, C3.2, C5.2, C6.2, C7.2, C8.2, C9.2, C10.2, C11.2, C12.2, C29.2, C30.2, C31.2, ... (+162 more) | GND |

### U12 ADP7142AUJZ (ADP7142AUJZ-R7) - TSOT-23-5

*ADP7142AUJZ LDO. Datasheet (ADI, Table 5): 1 VIN, 2 GND, 3 EN (may be tied to VIN), 4 SENSE/ADJ, 5 VOUT; VOUT = 1.2 V x (1 + R130/R131) = 9.00 V; 2.2 uF in/out minimum (C83 in, C74/C88 out). Matches.*

| Pin | Symbol pin name | Schematic net | Other ends of that net | PCB pad net |
|---:|---|---|---|---|
| 1 | VIN | +10V5 | C2.1, C3.1, C76.1, C77.1, C83.1, D12.1 (K), R80.1, U1.2 (VIN), U1.3 (EN) | +10V5 |
| 2 | GND | GND | C1.2, C2.2, C3.2, C5.2, C6.2, C7.2, C8.2, C9.2, C10.2, C11.2, C12.2, C29.2, C30.2, C31.2, ... (+168 more) | GND |
| 3 | EN | +10V5 | C2.1, C3.1, C76.1, C77.1, C83.1, D12.1 (K), R80.1, U1.2 (VIN), U1.3 (EN) | +10V5 |
| 4 | SENSE/ADJ | LDO_FB | R130.2, R131.1 | LDO_FB |
| 5 | VOUT | +9V | C34.1, C35.1, C36.1, C37.1, C74.1, C75.1, C88.1, C109.1, C110.1, Q6.2 (S), R83.1, R98.1, R106.1, R130.1, ... (+6 more) | +9V |

### U1 TPS62160DGK (TPS62160DGKR) - VSSOP-8_3x3mm_P0.65mm

*TPS62160DGK buck. Datasheet (TI SLVSAM2): 1 PGND, 2 VIN, 3 EN, 4 AGND, 5 FB (0.8 V), 6 VOS (output sense), 7 SW, 8 PG. As wired: EN tied to VIN (always on), VOS to +5V, FB from R1/R2. Matches. Note: the part has an internal 25 pF feed-forward cap VOS-FB; the external C4 22 pF across R1 is extra and harmless.*

| Pin | Symbol pin name | Schematic net | Other ends of that net | PCB pad net |
|---:|---|---|---|---|
| 1 | PGND | GND | C1.2, C2.2, C3.2, C5.2, C6.2, C7.2, C8.2, C9.2, C10.2, C11.2, C12.2, C29.2, C30.2, C31.2, ... (+167 more) | GND |
| 2 | VIN | +10V5 | C2.1, C3.1, C76.1, C77.1, C83.1, D12.1 (K), R80.1, U12.1 (VIN), U12.3 (EN) | +10V5 |
| 3 | EN | +10V5 | C2.1, C3.1, C76.1, C77.1, C83.1, D12.1 (K), R80.1, U12.1 (VIN), U12.3 (EN) | +10V5 |
| 4 | AGND | GND | C1.2, C2.2, C3.2, C5.2, C6.2, C7.2, C8.2, C9.2, C10.2, C11.2, C12.2, C29.2, C30.2, C31.2, ... (+167 more) | GND |
| 5 | FB | BUCK_FB | C4.2, R1.2, R2.1 | BUCK_FB |
| 6 | VOS | +5V | C4.1, C5.1, C6.1, C7.1, C61.1, C65.1, C95.1, D3.2 (A), D13.1 (K), J3.1 (Pin_1), K1.1, L1.2, Q8.2 (S), R1.1, ... (+10 more) | +5V |
| 7 | SW | BUCK_SW | L1.1 | BUCK_SW |
| 8 | PG | BUCK_PG | R3.2 | BUCK_PG |

### U2 TPS7A2033PDBV (TPS7A2033PDBVR) - SOT-23-5

*TPS7A2033PDBV 3.3 V LDO. Datasheet (TI): 1 IN, 2 GND, 3 EN (may be tied to IN), 4 NC, 5 OUT. Matches; 1 uF in (C7), 4.7 uF out (C8).*

| Pin | Symbol pin name | Schematic net | Other ends of that net | PCB pad net |
|---:|---|---|---|---|
| 1 | IN | +5V | C4.1, C5.1, C6.1, C7.1, C61.1, C65.1, C95.1, D3.2 (A), D13.1 (K), J3.1 (Pin_1), K1.1, L1.2, Q8.2 (S), R1.1, ... (+9 more) | +5V |
| 2 | GND | GND | C1.2, C2.2, C3.2, C5.2, C6.2, C7.2, C8.2, C9.2, C10.2, C11.2, C12.2, C29.2, C30.2, C31.2, ... (+168 more) | GND |
| 3 | EN | +5V | C4.1, C5.1, C6.1, C7.1, C61.1, C65.1, C95.1, D3.2 (A), D13.1 (K), J3.1 (Pin_1), K1.1, L1.2, Q8.2 (S), R1.1, ... (+9 more) | +5V |
| 4 | NC | NO_CONNECT | (nothing else: single-pin net) | - |
| 5 | OUT | +3V3_A | C8.1, C41.1, C42.1, C54.1, C55.1, C64.1, U7.8 (AVDD), U9.1 (CPVDD), U9.8 (AVDD) | +3V3_A |

### U14 TPS7A2033PDBV (TPS7A2033PDBVR) - SOT-23-5

*Same part as U2 for the converter digital rail. Matches; C95 in, C96 out.*

| Pin | Symbol pin name | Schematic net | Other ends of that net | PCB pad net |
|---:|---|---|---|---|
| 1 | IN | +5V | C4.1, C5.1, C6.1, C7.1, C61.1, C65.1, C95.1, D3.2 (A), D13.1 (K), J3.1 (Pin_1), K1.1, L1.2, Q8.2 (S), R1.1, ... (+9 more) | +5V |
| 2 | GND | GND | C1.2, C2.2, C3.2, C5.2, C6.2, C7.2, C8.2, C9.2, C10.2, C11.2, C12.2, C29.2, C30.2, C31.2, ... (+168 more) | GND |
| 3 | EN | +5V | C4.1, C5.1, C6.1, C7.1, C61.1, C65.1, C95.1, D3.2 (A), D13.1 (K), J3.1 (Pin_1), K1.1, L1.2, Q8.2 (S), R1.1, ... (+9 more) | +5V |
| 4 | NC | NO_CONNECT | (nothing else: single-pin net) | - |
| 5 | OUT | +3V3_DC | C44.1, C45.1, C56.1, C96.1, TP12.1, U7.13 (DVDD), U7.14 (IOVDD), U9.20 (DVDD) | +3V3_DC |

### U3 TLE2426ID (TLE2426IDR) - SOIC-8_3.9x4.9mm_P1.27mm

*TLE2426ID rail splitter. Datasheet: 1 OUT, 2 COMMON, 3 IN, 4-7 NC, 8 NR (noise-reduction cap C9 1 uF). Matches.*

| Pin | Symbol pin name | Schematic net | Other ends of that net | PCB pad net |
|---:|---|---|---|---|
| 1 | OUT | VREF | C10.1, C11.1, C105.2, C106.2, C107.2, C108.2, R14.2, R15.2, R16.2, R17.2, R19.2, R21.2, R23.2, R25.2, ... (+12 more) | VREF |
| 2 | COMMON | GND | C1.2, C2.2, C3.2, C5.2, C6.2, C7.2, C8.2, C9.2, C10.2, C11.2, C12.2, C29.2, C30.2, C31.2, ... (+168 more) | GND |
| 3 | IN | +9V | C34.1, C35.1, C36.1, C37.1, C74.1, C75.1, C88.1, C109.1, C110.1, Q6.2 (S), R83.1, R98.1, R106.1, R130.1, ... (+6 more) | +9V |
| 4 | NC | NO_CONNECT | (nothing else: single-pin net) | - |
| 5 | NC | NO_CONNECT | (nothing else: single-pin net) | - |
| 6 | NC | NO_CONNECT | (nothing else: single-pin net) | - |
| 7 | NC | NO_CONNECT | (nothing else: single-pin net) | - |
| 8 | NOISE_REDUCTION | VREF_NR | C9.1 | VREF_NR |

### U13 BQ24074RGT (BQ24074RGTR) - VQFN-16-1EP_3x3mm_P0.5mm_EP1.68x1.68mm

*BQ24074RGT charger. Datasheet (TI, RGT): 1 TS, 2/3 BAT, 4 CE (low = charging enabled), 5 EN2, 6 EN1, 7 /PGOOD, 8 VSS, 9 /CHG, 10/11 OUT, 12 ILIM, 13 IN, 14 TMR (GND = safety timers off), 15 ITERM (open = 10 %), 16 ISET, pad VSS. As wired: CE = GND (charging on), EN2 = VBUS_FUSED (high when USB present), EN1 = GND -> input limit set by R91 (1610/1.1k = 1.46 A), TMR = GND, ITERM open, ISET R92 1.2k -> 890/1.2k = 0.74 A. Matches the design intent exactly.*

| Pin | Symbol pin name | Schematic net | Other ends of that net | PCB pad net |
|---:|---|---|---|---|
| 1 | TS | CHG_TS | R93.1 | CHG_TS |
| 2 | BAT | VBAT | C92.1, J10.1 (Pin_1), Q3.2 (S), R86.1, R87.1, R89.1 | VBAT |
| 3 | BAT | VBAT | C92.1, J10.1 (Pin_1), Q3.2 (S), R86.1, R87.1, R89.1 | VBAT |
| 4 | ~{CE} | GND | C1.2, C2.2, C3.2, C5.2, C6.2, C7.2, C8.2, C9.2, C10.2, C11.2, C12.2, C29.2, C30.2, C31.2, ... (+164 more) | GND |
| 5 | EN2 | VBUS_FUSED | C90.1, D10.2 (A), D16.2 (A), F2.2 | VBUS_FUSED |
| 6 | EN1 | GND | C1.2, C2.2, C3.2, C5.2, C6.2, C7.2, C8.2, C9.2, C10.2, C11.2, C12.2, C29.2, C30.2, C31.2, ... (+164 more) | GND |
| 7 | ~{PGOOD} | PGOOD_N | R95.2, U8.25 (D25) | PGOOD_N |
| 8 | VSS | GND | C1.2, C2.2, C3.2, C5.2, C6.2, C7.2, C8.2, C9.2, C10.2, C11.2, C12.2, C29.2, C30.2, C31.2, ... (+164 more) | GND |
| 9 | ~{CHG} | CHG_STAT_N | R94.2, U8.17 (D17) | CHG_STAT_N |
| 10 | OUT | BAT_SYS | C91.1, D14.2 (A) | BAT_SYS |
| 11 | OUT | BAT_SYS | C91.1, D14.2 (A) | BAT_SYS |
| 12 | ILIM | CHG_ILIM | R91.1 | CHG_ILIM |
| 13 | IN | VBUS_FUSED | C90.1, D10.2 (A), D16.2 (A), F2.2 | VBUS_FUSED |
| 14 | TMR | GND | C1.2, C2.2, C3.2, C5.2, C6.2, C7.2, C8.2, C9.2, C10.2, C11.2, C12.2, C29.2, C30.2, C31.2, ... (+164 more) | GND |
| 15 | ITERM | NO_CONNECT | (nothing else: single-pin net) | - |
| 16 | ISET | CHG_ISET | R92.1 | CHG_ISET |
| 17 | VSS | GND | C1.2, C2.2, C3.2, C5.2, C6.2, C7.2, C8.2, C9.2, C10.2, C11.2, C12.2, C29.2, C30.2, C31.2, ... (+164 more) | GND |

### U6 OPA1654 (OPA1654AIPWR) - TSSOP-14_4.4x5mm_P0.65mm

*OPA1654 quad, TSSOP-14: 1 OUT A, 2 -IN A, 3 +IN A, 4 V+, 5 +IN B, 6 -IN B, 7 OUT B, 8 OUT C, 9 -IN C, 10 +IN C, 11 V-, 12 +IN D, 13 -IN D, 14 OUT D. Hot-leg amplifiers (A2). Units A/B/C/D = FLU/FRD/BLD/BRU. Matches.*

| Pin | Symbol pin name | Schematic net | Other ends of that net | PCB pad net |
|---:|---|---|---|---|
| 1 |  | FLU_PRE | C21.1, C25.1, R30.1 | FLU_PRE |
| 2 | - | FLU_FB | C21.2, R26.1, R30.2 | FLU_FB |
| 3 | + | FLU_PAD | U4.14 (A) | FLU_PAD |
| 4 | V+ | +9V | C34.1, C35.1, C36.1, C37.1, C74.1, C75.1, C88.1, C109.1, C110.1, Q6.2 (S), R83.1, R98.1, R106.1, R130.1, ... (+6 more) | +9V |
| 5 | + | FRD_PAD | U4.15 (B) | FRD_PAD |
| 6 | - | FRD_FB | C22.2, R27.1, R31.2 | FRD_FB |
| 7 |  | FRD_PRE | C22.1, C26.1, R31.1 | FRD_PRE |
| 8 |  | BLD_PRE | C23.1, C27.1, R32.1 | BLD_PRE |
| 9 | - | BLD_FB | C23.2, R28.1, R32.2 | BLD_FB |
| 10 | + | BLD_PAD | U5.14 (A) | BLD_PAD |
| 11 | V- | GND | C1.2, C2.2, C3.2, C5.2, C6.2, C7.2, C8.2, C9.2, C10.2, C11.2, C12.2, C29.2, C30.2, C31.2, ... (+168 more) | GND |
| 12 | + | BRU_PAD | U5.15 (B) | BRU_PAD |
| 13 | - | BRU_FB | C24.2, R29.1, R33.2 | BRU_FB |
| 14 |  | BRU_PRE | C24.1, C28.1, R33.1 | BRU_PRE |

### U16 OPA1654 (OPA1654AIPWR) - TSSOP-14_4.4x5mm_P0.65mm

*OPA1654 quad, same pinout. Cold-leg amplifiers (A1), units A/B/C/D = FLU/FRD/BLD/BRU. Matches.*

| Pin | Symbol pin name | Schematic net | Other ends of that net | PCB pad net |
|---:|---|---|---|---|
| 1 |  | FLU_CPRE | R26.2, R118.2 | FLU_CPRE |
| 2 | - | FLU_CFB | C105.1, R118.1, R122.1 | FLU_CFB |
| 3 | + | FLU_ACC | C101.2, R114.1, R126.1 | FLU_ACC |
| 4 | V+ | +9V | C34.1, C35.1, C36.1, C37.1, C74.1, C75.1, C88.1, C109.1, C110.1, Q6.2 (S), R83.1, R98.1, R106.1, R130.1, ... (+6 more) | +9V |
| 5 | + | FRD_ACC | C102.2, R115.1, R127.1 | FRD_ACC |
| 6 | - | FRD_CFB | C106.1, R119.1, R123.1 | FRD_CFB |
| 7 |  | FRD_CPRE | R27.2, R119.2 | FRD_CPRE |
| 8 |  | BLD_CPRE | R28.2, R120.2 | BLD_CPRE |
| 9 | - | BLD_CFB | C107.1, R120.1, R124.1 | BLD_CFB |
| 10 | + | BLD_ACC | C103.2, R116.1, R128.1 | BLD_ACC |
| 11 | V- | GND | C1.2, C2.2, C3.2, C5.2, C6.2, C7.2, C8.2, C9.2, C10.2, C11.2, C12.2, C29.2, C30.2, C31.2, ... (+168 more) | GND |
| 12 | + | BRU_ACC | C104.2, R117.1, R129.1 | BRU_ACC |
| 13 | - | BRU_CFB | C108.1, R121.1, R125.1 | BRU_CFB |
| 14 |  | BRU_CPRE | R29.2, R121.2 | BRU_CPRE |

### U4 CD4053BPW (CD4053BPWR) - TSSOP-16_4.4x5mm_P0.65mm

*CD4053B triple SPDT. Datasheet (TI): 1 BY, 2 BX, 3 CY, 4 C common, 5 CX, 6 INH, 7 VEE, 8 VSS, 9 sel C, 10 sel B, 11 sel A, 12 AX, 13 AY, 14 A common, 15 B common, 16 VDD. Common connects to Y when the select is HIGH, X when LOW. As wired: A: common 14 = FLU_PAD, AY 13 = FLU_AC (direct, select high = default), AX 12 = FLU_ATT (pad). B: common 15 = FRD_PAD, BY 1 = FRD_AC, BX 2 = FRD_ATT. C: common 4 = FLU_MICC, CY 3 = GND (grounded when COLD_SEL high = electret default), CX 5 = NC (released). INH, VEE = GND, VDD = +9V. Matches.*

| Pin | Symbol pin name | Schematic net | Other ends of that net | PCB pad net |
|---:|---|---|---|---|
| 1 | B1 | FRD_AC | C18.2, R15.1, R20.1 | FRD_AC |
| 2 | B0 | FRD_ATT | R20.2, R21.1 | FRD_ATT |
| 3 | C1 | GND | C1.2, C2.2, C3.2, C5.2, C6.2, C7.2, C8.2, C9.2, C10.2, C11.2, C12.2, C29.2, C30.2, C31.2, ... (+165 more) | GND |
| 4 | C | FLU_MICC | C97.1, C101.1, R110.2 | FLU_MICC |
| 5 | C0 | NO_CONNECT | (nothing else: single-pin net) | - |
| 6 | INH | GND | C1.2, C2.2, C3.2, C5.2, C6.2, C7.2, C8.2, C9.2, C10.2, C11.2, C12.2, C29.2, C30.2, C31.2, ... (+165 more) | GND |
| 7 | VEE | GND | C1.2, C2.2, C3.2, C5.2, C6.2, C7.2, C8.2, C9.2, C10.2, C11.2, C12.2, C29.2, C30.2, C31.2, ... (+165 more) | GND |
| 8 | VSS | GND | C1.2, C2.2, C3.2, C5.2, C6.2, C7.2, C8.2, C9.2, C10.2, C11.2, C12.2, C29.2, C30.2, C31.2, ... (+165 more) | GND |
| 9 | S3 | COLD_SEL | Q5.3 (D), R106.2, U5.9 (S3), U15.9 (S3), U15.10 (S2) | COLD_SEL |
| 10 | S2 | PAD_SELECT | C33.1, Q1.3 (D), R83.2, U5.10 (S2), U5.11 (S1) | PAD_SELECT |
| 11 | S1 | PAD_SELECT | C33.1, Q1.3 (D), R83.2, U5.10 (S2), U5.11 (S1) | PAD_SELECT |
| 12 | A0 | FLU_ATT | R18.2, R19.1 | FLU_ATT |
| 13 | A1 | FLU_AC | C17.2, R14.1, R18.1 | FLU_AC |
| 14 | A | FLU_PAD | U6.3 (+) | FLU_PAD |
| 15 | B | FRD_PAD | U6.5 (+) | FRD_PAD |
| 16 | VDD | +9V | C34.1, C35.1, C36.1, C37.1, C74.1, C75.1, C88.1, C109.1, C110.1, Q6.2 (S), R83.1, R98.1, R106.1, R130.1, ... (+6 more) | +9V |

### U5 CD4053BPW (CD4053BPWR) - TSSOP-16_4.4x5mm_P0.65mm

*Second CD4053B: A = BLD pad, B = BRU pad, C = BLD cold-leg ground. Matches the same pattern.*

| Pin | Symbol pin name | Schematic net | Other ends of that net | PCB pad net |
|---:|---|---|---|---|
| 1 | B1 | BRU_AC | C20.2, R17.1, R24.1 | BRU_AC |
| 2 | B0 | BRU_ATT | R24.2, R25.1 | BRU_ATT |
| 3 | C1 | GND | C1.2, C2.2, C3.2, C5.2, C6.2, C7.2, C8.2, C9.2, C10.2, C11.2, C12.2, C29.2, C30.2, C31.2, ... (+165 more) | GND |
| 4 | C | BLD_MICC | C99.1, C103.1, R112.2 | BLD_MICC |
| 5 | C0 | NO_CONNECT | (nothing else: single-pin net) | - |
| 6 | INH | GND | C1.2, C2.2, C3.2, C5.2, C6.2, C7.2, C8.2, C9.2, C10.2, C11.2, C12.2, C29.2, C30.2, C31.2, ... (+165 more) | GND |
| 7 | VEE | GND | C1.2, C2.2, C3.2, C5.2, C6.2, C7.2, C8.2, C9.2, C10.2, C11.2, C12.2, C29.2, C30.2, C31.2, ... (+165 more) | GND |
| 8 | VSS | GND | C1.2, C2.2, C3.2, C5.2, C6.2, C7.2, C8.2, C9.2, C10.2, C11.2, C12.2, C29.2, C30.2, C31.2, ... (+165 more) | GND |
| 9 | S3 | COLD_SEL | Q5.3 (D), R106.2, U4.9 (S3), U15.9 (S3), U15.10 (S2) | COLD_SEL |
| 10 | S2 | PAD_SELECT | C33.1, Q1.3 (D), R83.2, U4.10 (S2), U4.11 (S1) | PAD_SELECT |
| 11 | S1 | PAD_SELECT | C33.1, Q1.3 (D), R83.2, U4.10 (S2), U4.11 (S1) | PAD_SELECT |
| 12 | A0 | BLD_ATT | R22.2, R23.1 | BLD_ATT |
| 13 | A1 | BLD_AC | C19.2, R16.1, R22.1 | BLD_AC |
| 14 | A | BLD_PAD | U6.10 (+) | BLD_PAD |
| 15 | B | BRU_PAD | U6.12 (+) | BRU_PAD |
| 16 | VDD | +9V | C34.1, C35.1, C36.1, C37.1, C74.1, C75.1, C88.1, C109.1, C110.1, Q6.2 (S), R83.1, R98.1, R106.1, R130.1, ... (+6 more) | +9V |

### U15 CD4053BPW (CD4053BPWR) - TSSOP-16_4.4x5mm_P0.65mm

*Third CD4053B: B section grounds FRD_MICC (common 15, BY 1 = GND, BX 2 = NC, sel B 10 = COLD_SEL), C section grounds BRU_MICC (common 4, CY 3 = GND, CX 5 = NC, sel C 9 = COLD_SEL). A section unused (sel A = GND, AY = GND, AX/common NC). Matches.*

| Pin | Symbol pin name | Schematic net | Other ends of that net | PCB pad net |
|---:|---|---|---|---|
| 1 | B1 | GND | C1.2, C2.2, C3.2, C5.2, C6.2, C7.2, C8.2, C9.2, C10.2, C11.2, C12.2, C29.2, C30.2, C31.2, ... (+162 more) | GND |
| 2 | B0 | NO_CONNECT | (nothing else: single-pin net) | - |
| 3 | C1 | GND | C1.2, C2.2, C3.2, C5.2, C6.2, C7.2, C8.2, C9.2, C10.2, C11.2, C12.2, C29.2, C30.2, C31.2, ... (+162 more) | GND |
| 4 | C | BRU_MICC | C100.1, C104.1, R113.2 | BRU_MICC |
| 5 | C0 | NO_CONNECT | (nothing else: single-pin net) | - |
| 6 | INH | GND | C1.2, C2.2, C3.2, C5.2, C6.2, C7.2, C8.2, C9.2, C10.2, C11.2, C12.2, C29.2, C30.2, C31.2, ... (+162 more) | GND |
| 7 | VEE | GND | C1.2, C2.2, C3.2, C5.2, C6.2, C7.2, C8.2, C9.2, C10.2, C11.2, C12.2, C29.2, C30.2, C31.2, ... (+162 more) | GND |
| 8 | VSS | GND | C1.2, C2.2, C3.2, C5.2, C6.2, C7.2, C8.2, C9.2, C10.2, C11.2, C12.2, C29.2, C30.2, C31.2, ... (+162 more) | GND |
| 9 | S3 | COLD_SEL | Q5.3 (D), R106.2, U4.9 (S3), U5.9 (S3) | COLD_SEL |
| 10 | S2 | COLD_SEL | Q5.3 (D), R106.2, U4.9 (S3), U5.9 (S3) | COLD_SEL |
| 11 | S1 | GND | C1.2, C2.2, C3.2, C5.2, C6.2, C7.2, C8.2, C9.2, C10.2, C11.2, C12.2, C29.2, C30.2, C31.2, ... (+162 more) | GND |
| 12 | A0 | NO_CONNECT | (nothing else: single-pin net) | - |
| 13 | A1 | GND | C1.2, C2.2, C3.2, C5.2, C6.2, C7.2, C8.2, C9.2, C10.2, C11.2, C12.2, C29.2, C30.2, C31.2, ... (+162 more) | GND |
| 14 | A | NO_CONNECT | (nothing else: single-pin net) | - |
| 15 | B | FRD_MICC | C98.1, C102.1, R111.2 | FRD_MICC |
| 16 | VDD | +9V | C34.1, C35.1, C36.1, C37.1, C74.1, C75.1, C88.1, C109.1, C110.1, Q6.2 (S), R83.1, R98.1, R106.1, R130.1, ... (+6 more) | +9V |

### U7 PCM1864DBT (PCM1864DBTR) - TSSOP-30_4.4x7.8mm_P0.5mm

*PCM1864DBT ADC. Datasheet (TI): 1 VINL2, 2 VINR2, 3 VINL1, 4 VINR1, 5 MICBIAS (may be left open), 6 VREF (1 uF), 7 AGND, 8 AVDD (0.1 + 10 uF), 9 XO, 10 XI (crystal/1.8 V clock, unused), 11 LDO (0.1 + 10 uF), 12 DGND, 13 DVDD, 14 IOVDD, 15 SCKI (3.3 V master clock), 16 LRCK, 17 BCK, 18 DOUT, 19 GPIO3, 20 GPIO2, 21 GPIO1, 22 GPIO0 (DOUT2 in I2C mode), 23 SDA, 24 SCL, 25 MS/AD (I2C address), 26 MD0 (low = I2C), 27 VINL4, 28 VINR4, 29 VINL3, 30 VINR3. As wired: channel map is ADC1-L = FLU, ADC1-R = FRD, ADC2-L = BLD, ADC2-R = BRU; AD and MD0 low = I2C mode, address 0x4A. Matches.*

| Pin | Symbol pin name | Schematic net | Other ends of that net | PCB pad net |
|---:|---|---|---|---|
| 1 | VINL2/VIN1M | BLD_ADC | C31.1, R36.2, R40.1 | BLD_ADC |
| 2 | VINR2/VIN2M | BRU_ADC | C32.1, R37.2, R41.1 | BRU_ADC |
| 3 | VINL1/VIN1P | FLU_ADC | C29.1, R34.2, R38.1 | FLU_ADC |
| 4 | VINR1/VIN2P | FRD_ADC | C30.1, R35.2, R39.1 | FRD_ADC |
| 5 | Mic_Bias | NO_CONNECT | (nothing else: single-pin net) | - |
| 6 | VREF | ADC_VREF | C39.1, C40.1 | ADC_VREF |
| 7 | AGND | GND | C1.2, C2.2, C3.2, C5.2, C6.2, C7.2, C8.2, C9.2, C10.2, C11.2, C12.2, C29.2, C30.2, C31.2, ... (+165 more) | GND |
| 8 | AVDD | +3V3_A | C8.1, C41.1, C42.1, C54.1, C55.1, C64.1, U2.5 (OUT), U9.1 (CPVDD), U9.8 (AVDD) | +3V3_A |
| 9 | XO | NO_CONNECT | (nothing else: single-pin net) | - |
| 10 | XI | NO_CONNECT | (nothing else: single-pin net) | - |
| 11 | LDO | ADC_LDO | C43.1, C62.1 | ADC_LDO |
| 12 | DGND | GND | C1.2, C2.2, C3.2, C5.2, C6.2, C7.2, C8.2, C9.2, C10.2, C11.2, C12.2, C29.2, C30.2, C31.2, ... (+165 more) | GND |
| 13 | DVDD | +3V3_DC | C44.1, C45.1, C56.1, C96.1, TP12.1, U9.20 (DVDD), U14.5 (OUT) | +3V3_DC |
| 14 | IOVDD | +3V3_DC | C44.1, C45.1, C56.1, C96.1, TP12.1, U9.20 (DVDD), U14.5 (OUT) | +3V3_DC |
| 15 | SCKI | ADC_MCLK_IC | R46.2 | ADC_MCLK_IC |
| 16 | LRCK | ADC_LRCLK_IC | R47.2 | ADC_LRCLK_IC |
| 17 | BCK | ADC_BCLK_IC | R48.2 | ADC_BCLK_IC |
| 18 | DOUT | ADC_TDM_IC | R49.1 | ADC_TDM_IC |
| 19 | GPIO3/INTC | NO_CONNECT | (nothing else: single-pin net) | - |
| 20 | GPIO2/INTB/DMCLK | NO_CONNECT | (nothing else: single-pin net) | - |
| 21 | GPIO1/INTA/DMIN | NO_CONNECT | (nothing else: single-pin net) | - |
| 22 | MISO/GPIO0/DMIN2 | ADC_DOUT2_IC | R69.1 | ADC_DOUT2_IC |
| 23 | MOSI/SDA | I2C_SDA | J3.12 (Pin_12), R44.2, U8.18 (D18/SDA), U10.7 (SDA) | I2C_SDA |
| 24 | MC/SCL | I2C_SCL | J3.10 (Pin_10), R45.2, U8.19 (D19/SCL), U10.8 (SCL) | I2C_SCL |
| 25 | MS/AD | GND | C1.2, C2.2, C3.2, C5.2, C6.2, C7.2, C8.2, C9.2, C10.2, C11.2, C12.2, C29.2, C30.2, C31.2, ... (+165 more) | GND |
| 26 | MD0 | GND | C1.2, C2.2, C3.2, C5.2, C6.2, C7.2, C8.2, C9.2, C10.2, C11.2, C12.2, C29.2, C30.2, C31.2, ... (+165 more) | GND |
| 27 | VINL4/VIN4M | NO_CONNECT | (nothing else: single-pin net) | - |
| 28 | VINR4/VIN3M | NO_CONNECT | (nothing else: single-pin net) | - |
| 29 | VINL3/VIN4P | NO_CONNECT | (nothing else: single-pin net) | - |
| 30 | VINR3/VIN3P | NO_CONNECT | (nothing else: single-pin net) | - |

### U9 PCM5102A (PCM5102APWR) - TSSOP-20_4.4x6.5mm_P0.65mm

*PCM5102A DAC. Datasheet (TI): 1 CPVDD, 2 CAPP, 3 CPGND, 4 CAPM, 5 VNEG, 6 OUTL, 7 OUTR, 8 AVDD, 9 AGND, 10 DEMP, 11 FLT, 12 SCK, 13 BCK, 14 DIN, 15 LRCK, 16 FMT, 17 XSMT, 18 LDOO, 19 DGND, 20 DVDD. As wired: DEMP = GND (off), FLT = GND (normal latency), SCK = GND (no master clock: the chip runs its BCK PLL, which TI allows when SCK is grounded), FMT = GND (I2S), XSMT from Teensy 34 with 10k pull-down, CAPP-CAPM 2.2 uF, VNEG 2.2 uF, LDOO 1 uF. Matches.*

| Pin | Symbol pin name | Schematic net | Other ends of that net | PCB pad net |
|---:|---|---|---|---|
| 1 | CPVDD | +3V3_A | C8.1, C41.1, C42.1, C54.1, C55.1, C64.1, U2.5 (OUT), U7.8 (AVDD) | +3V3_A |
| 2 | CAPP | DAC_CAPP | C51.1 | DAC_CAPP |
| 3 | CPGND | GND | C1.2, C2.2, C3.2, C5.2, C6.2, C7.2, C8.2, C9.2, C10.2, C11.2, C12.2, C29.2, C30.2, C31.2, ... (+162 more) | GND |
| 4 | CAPM | DAC_CAPM | C51.2 | DAC_CAPM |
| 5 | VNEG | DAC_VNEG | C52.1 | DAC_VNEG |
| 6 | OUTL | DAC_L | R62.1 | DAC_L |
| 7 | OUTR | DAC_R | R63.1 | DAC_R |
| 8 | AVDD | +3V3_A | C8.1, C41.1, C42.1, C54.1, C55.1, C64.1, U2.5 (OUT), U7.8 (AVDD) | +3V3_A |
| 9 | AGND | GND | C1.2, C2.2, C3.2, C5.2, C6.2, C7.2, C8.2, C9.2, C10.2, C11.2, C12.2, C29.2, C30.2, C31.2, ... (+162 more) | GND |
| 10 | DEMP | GND | C1.2, C2.2, C3.2, C5.2, C6.2, C7.2, C8.2, C9.2, C10.2, C11.2, C12.2, C29.2, C30.2, C31.2, ... (+162 more) | GND |
| 11 | FLT | GND | C1.2, C2.2, C3.2, C5.2, C6.2, C7.2, C8.2, C9.2, C10.2, C11.2, C12.2, C29.2, C30.2, C31.2, ... (+162 more) | GND |
| 12 | SCK | GND | C1.2, C2.2, C3.2, C5.2, C6.2, C7.2, C8.2, C9.2, C10.2, C11.2, C12.2, C29.2, C30.2, C31.2, ... (+162 more) | GND |
| 13 | BCK | DAC_BCLK_IC | R57.2 | DAC_BCLK_IC |
| 14 | DIN | DAC_DIN_IC | R58.2 | DAC_DIN_IC |
| 15 | LRCK | DAC_LRCLK_IC | R59.2 | DAC_LRCLK_IC |
| 16 | FMT | GND | C1.2, C2.2, C3.2, C5.2, C6.2, C7.2, C8.2, C9.2, C10.2, C11.2, C12.2, C29.2, C30.2, C31.2, ... (+162 more) | GND |
| 17 | XSMT | DAC_MUTE_IC | R60.1, R61.2 | DAC_MUTE_IC |
| 18 | LDOO | DAC_LDO | C53.1 | DAC_LDO |
| 19 | DGND | GND | C1.2, C2.2, C3.2, C5.2, C6.2, C7.2, C8.2, C9.2, C10.2, C11.2, C12.2, C29.2, C30.2, C31.2, ... (+162 more) | GND |
| 20 | DVDD | +3V3_DC | C44.1, C45.1, C56.1, C96.1, TP12.1, U7.13 (DVDD), U7.14 (IOVDD), U14.5 (OUT) | +3V3_DC |

### U10 TPA6130A2RTJ (TPA6130A2RTJR) - WQFN-20-1EP_4x4mm_P0.5mm_EP2.7x2.7mm

*TPA6130A2RTJ headphone amp. Datasheet (TI): 1 LEFTINM, 2 LEFTINP, 3 GND, 4 RIGHTINP, 5 RIGHTINM, 6 /SD (active low, VIH 1.3 V, 5 V tolerant), 7 SDA, 8 SCL (5 V tolerant, work with 3.3 V pull-ups), 9/10 GND, 11 HPRIGHT, 12 VDD, 13 GND, 14 HPLEFT, 15/16 CPVSS, 17 CPN, 18 CPP, 19 GND, 20 VDD, pad GND. I2C address 0x60. As wired: single-ended drive into INM with INP AC-grounded through matched caps, 1 uF charge-pump caps, SD from Teensy 33 with 100k pull-down. Matches.*

| Pin | Symbol pin name | Schematic net | Other ends of that net | PCB pad net |
|---:|---|---|---|---|
| 1 | LEFTINM | HP_IN_L | C57.2 | HP_IN_L |
| 2 | LEFTINP | HP_INP_L | C86.1 | HP_INP_L |
| 3 | GND | GND | C1.2, C2.2, C3.2, C5.2, C6.2, C7.2, C8.2, C9.2, C10.2, C11.2, C12.2, C29.2, C30.2, C31.2, ... (+163 more) | GND |
| 4 | RIGHTINP | HP_INP_R | C87.1 | HP_INP_R |
| 5 | RIGHTINM | HP_IN_R | C58.2 | HP_IN_R |
| 6 | ~{SD} | HP_ENABLE | R64.1, U8.33 (D33) | HP_ENABLE |
| 7 | SDA | I2C_SDA | J3.12 (Pin_12), R44.2, U7.23 (MOSI/SDA), U8.18 (D18/SDA) | I2C_SDA |
| 8 | SCL | I2C_SCL | J3.10 (Pin_10), R45.2, U7.24 (MC/SCL), U8.19 (D19/SCL) | I2C_SCL |
| 9 | GND | GND | C1.2, C2.2, C3.2, C5.2, C6.2, C7.2, C8.2, C9.2, C10.2, C11.2, C12.2, C29.2, C30.2, C31.2, ... (+163 more) | GND |
| 10 | GND | GND | C1.2, C2.2, C3.2, C5.2, C6.2, C7.2, C8.2, C9.2, C10.2, C11.2, C12.2, C29.2, C30.2, C31.2, ... (+163 more) | GND |
| 11 | HPRIGHT | HP_OUT_R | R66.1 | HP_OUT_R |
| 12 | VDD | +5V | C4.1, C5.1, C6.1, C7.1, C61.1, C65.1, C95.1, D3.2 (A), D13.1 (K), J3.1 (Pin_1), K1.1, L1.2, Q8.2 (S), R1.1, ... (+9 more) | +5V |
| 13 | GND | GND | C1.2, C2.2, C3.2, C5.2, C6.2, C7.2, C8.2, C9.2, C10.2, C11.2, C12.2, C29.2, C30.2, C31.2, ... (+163 more) | GND |
| 14 | HPLEFT | HP_OUT_L | R65.1 | HP_OUT_L |
| 15 | CPVSS | HP_VSS | C60.1 | HP_VSS |
| 16 | CPVSS | HP_VSS | C60.1 | HP_VSS |
| 17 | CPN | HP_CPN | C59.2 | HP_CPN |
| 18 | CPP | HP_CPP | C59.1 | HP_CPP |
| 19 | GND | GND | C1.2, C2.2, C3.2, C5.2, C6.2, C7.2, C8.2, C9.2, C10.2, C11.2, C12.2, C29.2, C30.2, C31.2, ... (+163 more) | GND |
| 20 | VDD_CP | +5V | C4.1, C5.1, C6.1, C7.1, C61.1, C65.1, C95.1, D3.2 (A), D13.1 (K), J3.1 (Pin_1), K1.1, L1.2, Q8.2 (S), R1.1, ... (+9 more) | +5V |
| 21 | EP | GND | C1.2, C2.2, C3.2, C5.2, C6.2, C7.2, C8.2, C9.2, C10.2, C11.2, C12.2, C29.2, C30.2, C31.2, ... (+163 more) | GND |

### U8 Teensy 4.1 (TEENSY41) - Teensy41_Socket

*Teensy 4.1 module (socketed). Pin map in section 8.*

| Pin | Symbol pin name | Schematic net | Other ends of that net | PCB pad net |
|---:|---|---|---|---|
| 0 | D0/RX1 | MIC5_CTRL | R102.1 | MIC5_CTRL |
| 1 | D1/TX1 | MIC9_CTRL | R99.1 | MIC9_CTRL |
| 2 | D2/OUT2 | DAC_DIN | R58.1, TP11.1 | DAC_DIN |
| 3 | D3/LRCLK2 | DAC_LRCLK | R59.1, TP10.1 | DAC_LRCLK |
| 4 | D4/BCLK2 | DAC_BCLK | R57.1, TP9.1 | DAC_BCLK |
| 5 | D5 | LINE_MUTE | R84.1 | LINE_MUTE |
| 6 | D6 | ADC_DOUT2 | R69.2, TP7.1 | ADC_DOUT2 |
| 7 | D7/OUT1A | TFT_RST | J3.4 (Pin_4) | TFT_RST |
| 8 | D8/IN1 | ADC_TDM | R49.2, TP6.1 | ADC_TDM |
| 9 | D9 | TFT_DC | J3.5 (Pin_5) | TFT_DC |
| 10 | D10/CS | TFT_CS | J3.3 (Pin_3) | TFT_CS |
| 11 | D11/MOSI | SPI_MOSI | J3.6 (Pin_6) | SPI_MOSI |
| 12 | D12/MISO | SPI_MISO | J3.9 (Pin_9) | SPI_MISO |
| 13 | D13/SCK | SPI_SCK | J3.7 (Pin_7) | SPI_SCK |
| 14 | D14 | CTP_RST | J3.11 (Pin_11) | CTP_RST |
| 15 | D15 | VBUS_SENSE | C78.1, R77.2, R78.1 | VBUS_SENSE |
| 16 | D16 | BAT_SENSE | C89.1, R89.2, R90.1 | BAT_SENSE |
| 17 | D17 | CHG_STAT_N | R94.2, U13.9 (~{CHG}) | CHG_STAT_N |
| 18 | D18/SDA | I2C_SDA | J3.12 (Pin_12), R44.2, U7.23 (MOSI/SDA), U10.7 (SDA) | I2C_SDA |
| 19 | D19/SCL | I2C_SCL | J3.10 (Pin_10), R45.2, U7.24 (MC/SCL), U10.8 (SCL) | I2C_SCL |
| 20 | D20/LRCLK1 | ADC_LRCLK | R47.1, TP5.1 | ADC_LRCLK |
| 21 | D21/BCLK1 | ADC_BCLK | R48.1, TP4.1 | ADC_BCLK |
| 22 | D22 | TOUCH_IRQ | J3.13 (Pin_13) | TOUCH_IRQ |
| 23 | D23/MCLK1 | ADC_MCLK | R46.1, TP3.1 | ADC_MCLK |
| 24 | D24 | KEEP_ON | D15.2 (A) | KEEP_ON |
| 25 | D25 | PGOOD_N | R95.2, U13.7 (~{PGOOD}) | PGOOD_N |
| 26 | D26 | NAV_ENC_A | C93.1, R96.2, SW4.8 (E_A) | NAV_ENC_A |
| 27 | D27 | NAV_ENC_B | C94.1, R97.2, SW4.7 (E_B) | NAV_ENC_B |
| 28 | D28 | REC_BUTTON | C47.1, D18.2 (A), R50.2 | REC_BUTTON |
| 29 | D29 | GAIN_A | C48.1, R51.2, SW3.A (A) | GAIN_A |
| 30 | D30 | GAIN_B | C49.1, R52.2, SW3.B (B) | GAIN_B |
| 31 | D31 | GAIN_PUSH | C50.1, D19.2 (A), R53.2 | GAIN_PUSH |
| 32 | D32 | PAD_CTRL | R42.1 | PAD_CTRL |
| 33 | D33 | HP_ENABLE | R64.1, U10.6 (~{SD}) | HP_ENABLE |
| 34 | D34 | DAC_MUTE | R61.1 | DAC_MUTE |
| 35 | D35 | REC_LED | R55.1 | REC_LED |
| 36 | D36 | NAV_UP | C69.1, R70.2, SW4.C (C/UP) | NAV_UP |
| 37 | D37 | NAV_DOWN | C70.1, R71.2, SW4.A (A/DOWN) | NAV_DOWN |
| 38 | D38 | NAV_LEFT | C71.1, R72.2, SW4.D (D/LEFT) | NAV_LEFT |
| 39 | D39 | NAV_RIGHT | C72.1, R73.2, SW4.B (B/RIGHT) | NAV_RIGHT |
| 40 | D40 | NAV_PUSH | C73.1, R74.2, SW4.5 (PUSH) | NAV_PUSH |
| 41 | D41 | COLD_CTRL | R107.1 | COLD_CTRL |
| 3V3A | 3V3 | +3V3_D | R44.1, R45.1, R50.1, R51.1, R52.1, R53.1, R70.1, R71.1, R72.1, R73.1, R74.1, R94.1, R95.1, R96.1, ... (+1 more) | +3V3_D |
| 3V3B | 3V3 | NO_CONNECT | (nothing else: single-pin net) | - |
| GND1 | GND | GND | C1.2, C2.2, C3.2, C5.2, C6.2, C7.2, C8.2, C9.2, C10.2, C11.2, C12.2, C29.2, C30.2, C31.2, ... (+166 more) | GND |
| GND2 | GND | GND | C1.2, C2.2, C3.2, C5.2, C6.2, C7.2, C8.2, C9.2, C10.2, C11.2, C12.2, C29.2, C30.2, C31.2, ... (+166 more) | GND |
| GND3 | GND | GND | C1.2, C2.2, C3.2, C5.2, C6.2, C7.2, C8.2, C9.2, C10.2, C11.2, C12.2, C29.2, C30.2, C31.2, ... (+166 more) | GND |
| VIN | VIN | TEENSY_VIN | C46.1, D3.1 (K) | TEENSY_VIN |

### Datasheet cross-check summary

Pin functions were compared against the current manufacturer datasheets on 2026-09-15 (TI: TPS61175, TPS62160, TPS7A20, BQ24074, PCM1864, PCM5102A, TPA6130A2, CD4053B; ADI: ADP7142). Every power, ground, feedback, enable, mode and I/O pin of U1, U2, U3, U4, U5, U7, U9, U10, U11, U12, U13, U14, U15 lands where the datasheet says it should; the CD4053 common/X/Y assignment and select polarity give 'direct' and 'cold leg grounded' as the power-up defaults; the BQ24074 strapping (CE low, EN2 high, EN1 low, TMR low, ITERM open) implements the 0.74 A / 1.46 A / no-timer intent in the design notes; PCM5102A mode pins give I2S, normal filter, no de-emphasis, BCK-PLL clocking; PCM1864 is in I2C mode at 0x4A with GPIO0 as the second data line. OPA1654 units use the standard quad pinout. Transistor and diode pin orders are checked in section 5. **The Teensy 4.1 socket footprint (U8) failed this check** and is the one real error the review found; see the box below and section 16.

> **Teensy 4.1 socket, found 2026-09-15 (this is what stopped the order).** The project footprint `Teensy41_Socket` was compared against PJRC's dimension drawing (`dimensions_teensy41.png`), the PJRC pinout card and the XenGi `Teensy4.1` symbol (pins 1-48 numbered DIP-style). Two errors, both dating from Rev B, never caught because no board was built: (1) the two socket rows were drawn 17.78 mm apart; the module's rows are 15.24 mm (0.6 in) apart on a 17.78 mm wide body, so the module could not have been plugged in; (2) the right row, USB end first, was drawn VIN, GND, 23 ... 13, 41 ... 33, GND, 3V3 but the module is VIN, GND, **3V3**, 23 ... 13, **GND**, 41 ... 33, so 22 of the 24 right-row pads sat one position off: ADC_MCLK would have landed on the Teensy's 3.3 V pin, every right-side signal on the neighbouring pin, and +3V3_D on I/O 33. The left row (GND, 0 to 12, 3V3, 24 to 32) was correct. The schematic, netlist and BOM are unaffected: only pad positions changed. Fix: `tools/generate_footprints.py` corrected (rows 15.24 mm, right order VIN GND 3V3B 23-13 GND3 41-33, outline 17.78 wide), the second 3.3 V pin (3V3B) made a no-connect in `tools/generate_schematic.py` (both 3.3 V pins are the same regulator output inside the module), and the board fully re-routed through the Rev C3 pipeline (`tools/full_route_body.ps1`, Freerouting 1.9) because moving the right pin row 2.54 mm inward took away the corridor six long control lines used; then the Rev C3 post passes, DRC at every severity, audio audits and a rebuilt fab package. Sections 8 and 13 below describe the corrected board.

## 5. Transistors and diodes

SOT-23 pin order matters: KiCad's 2N7002 symbol is 1 = G, 2 = S, 3 = D, and the AO3401A symbol is 1 = G, 2 = S, 3 = D. Both match the Nexperia 2N7002 and AOS AO3401A datasheets (gate pin 1, source pin 2, drain pin 3). For the diodes, KiCad pin 1 = cathode (K) and pin 2 = anode (A).

| Ref | Part | Pin 1 | Pin 2 | Pin 3 | Role |
|---|---|---|---|---|---|
| Q6 | AO3401A AO3401A | G: MIC9_G [MIC9_G] | S: +9V [+9V] | D: BIAS_SRC [BIAS_SRC] | 9 V mic-bias high-side P-FET (+9V -> BIAS_SRC) |
| Q7 | 2N7002 2N7002NXAKR | G: MIC9_CTRL_G [MIC9_CTRL_G] | S: GND [GND] | D: MIC9_G [MIC9_G] | Gate driver for Q6 (MIC9_CTRL high -> Q6 on) |
| Q8 | AO3401A AO3401A | G: MIC5_G [MIC5_G] | S: +5V [+5V] | D: BIAS5 [BIAS5] | 5 V mic-bias high-side P-FET (+5V -> BIAS5 -> D24 -> BIAS_SRC) |
| Q9 | 2N7002 2N7002NXAKR | G: MIC5_CTRL_G [MIC5_CTRL_G] | S: GND [GND] | D: MIC5_G [MIC5_G] | Gate driver for Q8 (MIC5_CTRL high -> Q8 on) |
| Q3 | AO3401A AO3401A | G: REC_SW [REC_SW] | S: VBAT [VBAT] | D: PWR_LATCH_MID [PWR_LATCH_MID] | Soft-power latch, RECORD side (P-FET, source VBAT) |
| Q4 | AO3401A AO3401A | G: GAIN_SW [GAIN_SW] | S: PWR_LATCH_MID [PWR_LATCH_MID] | D: BOOST_EN [BOOST_EN] | Soft-power latch, encoder-push side (P-FET, in series with Q3, drain -> BOOST_EN) |
| Q5 | 2N7002 2N7002NXAKR | G: COLD_CTRL_G [COLD_CTRL_G] | S: GND [GND] | D: COLD_SEL [COLD_SEL] | Cold-leg mode level shifter: COLD_CTRL high -> COLD_SEL low = cold legs released (dynamic/balanced mode) |
| Q1 | 2N7002 2N7002NXAKR | G: PAD_CTRL_G [PAD_CTRL_G] | S: GND [GND] | D: PAD_SELECT [PAD_SELECT] | Pad select level shifter: Teensy PAD_CTRL high -> pulls PAD_SELECT (0/9 V) low = -9.7 dB pad in |
| Q2 | 2N7002 2N7002NXAKR | G: LINE_MUTE_G [LINE_MUTE_G] | S: GND [GND] | D: LINE_MUTE_K [LINE_MUTE_K] | Relay coil driver: LINE_MUTE high -> K1 energised -> line jack tips grounded |

Diodes (K = cathode = pin 1, A = anode = pin 2):

| Ref | Part | Pin 1 (K) net | Pin 2 (A) net | Current flows | Role |
|---|---|---|---|---|---|
| D1 | B340A 40V 3A B340A-13-F | VBOOST_IN [VBOOST_IN] | +9V_FUSED [+9V_FUSED] | +9V_FUSED -> VBOOST_IN | barrel -> VBOOST_IN OR-ing |
| D2 | SMBJ12A SMBJ12A | VBOOST_IN [VBOOST_IN] | GND [GND] | GND -> VBOOST_IN | SMBJ12A TVS clamp on VBOOST_IN |
| D3 | SS14 SS14 | TEENSY_VIN [TEENSY_VIN] | +5V [+5V] | +5V -> TEENSY_VIN | +5V -> Teensy VIN (blocks USB back-feed) |
| D4 | POWER BLUE WP7113QBC/D | GND [GND] | PWR_LED_A [PWR_LED_A] | PWR_LED_A -> GND | blue power LED (front wall) |
| D5 | RECORD RED WP7113ID | GND [GND] | REC_LED_A [REC_LED_A] | REC_LED_A -> GND | red record LED (front wall) |
| D10 | B340A 40V 3A B340A-13-F | VBOOST_IN [VBOOST_IN] | VBUS_FUSED [VBUS_FUSED] | VBUS_FUSED -> VBOOST_IN | USB -> VBOOST_IN OR-ing |
| D11 | USBLC6-2SC6 | 1=USB_DP, 2=GND, 3=USB_DM, 4=USB_DM, 5=VBUS, 6=USB_DP | | | USBLC6-2SC6 USB ESD array |
| D12 | B340A 40V 3A B340A-13-F | +10V5 [+10V5] | BOOST_SW [BOOST_SW] | BOOST_SW -> +10V5 | boost rectifier (SW -> +10V5) |
| D13 | 1N4148W 1N4148W-7-F | +5V [+5V] | LINE_MUTE_K [LINE_MUTE_K] | LINE_MUTE_K -> +5V | relay flyback across K1 coil |
| D14 | B340A 40V 3A B340A-13-F | VBOOST_IN [VBOOST_IN] | BAT_SYS [BAT_SYS] | BAT_SYS -> VBOOST_IN | charger OUT / battery -> VBOOST_IN OR-ing |
| D15 | 1N4148W 1N4148W-7-F | BOOST_EN [BOOST_EN] | KEEP_ON [KEEP_ON] | KEEP_ON -> BOOST_EN | KEEP_ON -> BOOST_EN |
| D16 | 1N4148W 1N4148W-7-F | BOOST_EN [BOOST_EN] | VBUS_FUSED [VBUS_FUSED] | VBUS_FUSED -> BOOST_EN | USB present -> BOOST_EN |
| D17 | 1N4148W 1N4148W-7-F | BOOST_EN [BOOST_EN] | +9V_FUSED [+9V_FUSED] | +9V_FUSED -> BOOST_EN | barrel present -> BOOST_EN |
| D18 | 1N4148W 1N4148W-7-F | REC_SW [REC_SW] | REC_BUTTON [REC_BUTTON] | REC_BUTTON -> REC_SW | isolates REC_SW from the Teensy REC_BUTTON input |
| D19 | 1N4148W 1N4148W-7-F | GAIN_SW [GAIN_SW] | GAIN_PUSH [GAIN_PUSH] | GAIN_PUSH -> GAIN_SW | isolates GAIN_SW from GAIN_PUSH |
| D24 | BAT54 BAT54-7-F | BIAS_SRC [BIAS_SRC] | BIAS5 [BIAS5] | BIAS5 -> BIAS_SRC | BAT54: 5 V bias -> BIAS_SRC, blocks 9 V from the +5V rail |

Input ESD diodes D6-D9 (hot legs) and D20-D23 (cold legs) are Nexperia PESD12VL1BA (12 V bidirectional, low capacitance) from each RAW/RAWC input to CHASSIS:

| Ref | Pin 1 | Pin 2 |
|---|---|---|
| D6 | FLU_RAW [FLU_RAW] | CHASSIS [CHASSIS] |
| D7 | FRD_RAW [FRD_RAW] | CHASSIS [CHASSIS] |
| D8 | BLD_RAW [BLD_RAW] | CHASSIS [CHASSIS] |
| D9 | BRU_RAW [BRU_RAW] | CHASSIS [CHASSIS] |
| D20 | FLU_RAWC [FLU_RAWC] | CHASSIS [CHASSIS] |
| D21 | FRD_RAWC [FRD_RAWC] | CHASSIS [CHASSIS] |
| D22 | BLD_RAWC [BLD_RAWC] | CHASSIS [CHASSIS] |
| D23 | BRU_RAWC [BRU_RAWC] | CHASSIS [CHASSIS] |

## 6. Connectors, switches, relay

### J2 AMBISONIC MIC RJ45 (RJHSE-5380)

| Pin | Pin name | Net | Other ends | PCB pad net |
|---|---|---|---|---|
| 1 |  | FLU_RAW | D6.1 (A1), R10.1 | FLU_RAW |
| 2 |  | FLU_RAWC | D20.1 (A1), R110.1 | FLU_RAWC |
| 3 |  | FRD_RAW | D7.1 (A1), R11.1 | FRD_RAW |
| 4 |  | BLD_RAW | D8.1 (A1), R12.1 | BLD_RAW |
| 5 |  | BLD_RAWC | D22.1 (A1), R112.1 | BLD_RAWC |
| 6 |  | FRD_RAWC | D21.1 (A1), R111.1 | FRD_RAWC |
| 7 |  | BRU_RAW | D9.1 (A1), R13.1 | BRU_RAW |
| 8 |  | BRU_RAWC | D23.1 (A1), R113.1 | BRU_RAWC |
| SH |  | CHASSIS | C12.1, C13.2, C14.2, C15.2, C16.2, C97.2, C98.2, C99.2, C100.2, D6.2 (A2), D7.2 (A2), D8.2 (A2), D9.2 (A2), D20.2 (A2), ... (+6 more) | CHASSIS |

### J9 USB-C POWER + DATA (TYPE-C-31-M-12)

| Pin | Pin name | Net | Other ends | PCB pad net |
|---|---|---|---|---|
| A1 | GND | GND | C1.2, C2.2, C3.2, C5.2, C6.2, C7.2, C8.2, C9.2, C10.2, C11.2, C12.2, C29.2, C30.2, C31.2, ... (+165 more) | GND |
| A12 | GND | GND | C1.2, C2.2, C3.2, C5.2, C6.2, C7.2, C8.2, C9.2, C10.2, C11.2, C12.2, C29.2, C30.2, C31.2, ... (+165 more) | GND |
| A4 | VBUS | VBUS | D11.5 (VBUS), F2.1, R77.1 | VBUS |
| A5 | CC1 | USB_CC1 | R75.1 | USB_CC1 |
| A6 | D+ | USB_DP | D11.1 (I/O1), D11.6 (I/O1), TP1.1 | USB_DP |
| A7 | D- | USB_DM | D11.3 (I/O2), D11.4 (I/O2), TP2.1 | USB_DM |
| A8 | SBU1 | __unnamed_0 | (nothing else: single-pin net) | - |
| A9 | VBUS | VBUS | D11.5 (VBUS), F2.1, R77.1 | VBUS |
| B1 | GND | GND | C1.2, C2.2, C3.2, C5.2, C6.2, C7.2, C8.2, C9.2, C10.2, C11.2, C12.2, C29.2, C30.2, C31.2, ... (+165 more) | GND |
| B12 | GND | GND | C1.2, C2.2, C3.2, C5.2, C6.2, C7.2, C8.2, C9.2, C10.2, C11.2, C12.2, C29.2, C30.2, C31.2, ... (+165 more) | GND |
| B4 | VBUS | VBUS | D11.5 (VBUS), F2.1, R77.1 | VBUS |
| B5 | CC2 | USB_CC2 | R76.1 | USB_CC2 |
| B6 | D+ | USB_DP | D11.1 (I/O1), D11.6 (I/O1), TP1.1 | USB_DP |
| B7 | D- | USB_DM | D11.3 (I/O2), D11.4 (I/O2), TP2.1 | USB_DM |
| B8 | SBU2 | __unnamed_1 | (nothing else: single-pin net) | - |
| B9 | VBUS | VBUS | D11.5 (VBUS), F2.1, R77.1 | VBUS |
| SH | SHIELD | CHASSIS | C12.1, C13.2, C14.2, C15.2, C16.2, C97.2, C98.2, C99.2, C100.2, D6.2 (A2), D7.2 (A2), D8.2 (A2), D9.2 (A2), D20.2 (A2), ... (+6 more) | CHASSIS |

### J1 9V DC IN (PJ-102AH)

| Pin | Pin name | Net | Other ends | PCB pad net |
|---|---|---|---|---|
| 1 |  | +9V_IN | F1.1 | +9V_IN |
| 2 |  | GND | C1.2, C2.2, C3.2, C5.2, C6.2, C7.2, C8.2, C9.2, C10.2, C11.2, C12.2, C29.2, C30.2, C31.2, ... (+167 more) | GND |
| 3 |  | GND | C1.2, C2.2, C3.2, C5.2, C6.2, C7.2, C8.2, C9.2, C10.2, C11.2, C12.2, C29.2, C30.2, C31.2, ... (+167 more) | GND |

### J10 BATTERY 1S LiPo (B2B-PH-K-S)

| Pin | Pin name | Net | Other ends | PCB pad net |
|---|---|---|---|---|
| 1 | Pin_1 | VBAT | C92.1, Q3.2 (S), R86.1, R87.1, R89.1, U13.2 (BAT), U13.3 (BAT) | VBAT |
| 2 | Pin_2 | GND | C1.2, C2.2, C3.2, C5.2, C6.2, C7.2, C8.2, C9.2, C10.2, C11.2, C12.2, C29.2, C30.2, C31.2, ... (+168 more) | GND |

### J3 MSP3526 TFT 3.5IN 14PIN SOCKET (PPTC141LFBN-RC)

| Pin | Pin name | Net | Other ends | PCB pad net |
|---|---|---|---|---|
| 1 | Pin_1 | +5V | C4.1, C5.1, C6.1, C7.1, C61.1, C65.1, C95.1, D3.2 (A), D13.1 (K), K1.1, L1.2, Q8.2 (S), R1.1, R3.1, ... (+10 more) | +5V |
| 2 | Pin_2 | GND | C1.2, C2.2, C3.2, C5.2, C6.2, C7.2, C8.2, C9.2, C10.2, C11.2, C12.2, C29.2, C30.2, C31.2, ... (+168 more) | GND |
| 3 | Pin_3 | TFT_CS | U8.10 (D10/CS) | TFT_CS |
| 4 | Pin_4 | TFT_RST | U8.7 (D7/OUT1A) | TFT_RST |
| 5 | Pin_5 | TFT_DC | U8.9 (D9) | TFT_DC |
| 6 | Pin_6 | SPI_MOSI | U8.11 (D11/MOSI) | SPI_MOSI |
| 7 | Pin_7 | SPI_SCK | U8.13 (D13/SCK) | SPI_SCK |
| 8 | Pin_8 | TFT_LED | R56.2 | TFT_LED |
| 9 | Pin_9 | SPI_MISO | U8.12 (D12/MISO) | SPI_MISO |
| 10 | Pin_10 | I2C_SCL | R45.2, U7.24 (MC/SCL), U8.19 (D19/SCL), U10.8 (SCL) | I2C_SCL |
| 11 | Pin_11 | CTP_RST | U8.14 (D14) | CTP_RST |
| 12 | Pin_12 | I2C_SDA | R44.2, U7.23 (MOSI/SDA), U8.18 (D18/SDA), U10.7 (SDA) | I2C_SDA |
| 13 | Pin_13 | TOUCH_IRQ | U8.22 (D22) | TOUCH_IRQ |
| 14 | Pin_14 | __unnamed_27 | (nothing else: single-pin net) | - |

### J4 1/4in BINAURAL LINE OUT (NRJ6HF)

| Pin | Pin name | Net | Other ends | PCB pad net |
|---|---|---|---|---|
| R |  | LINE_JACK_R | K1.6 | LINE_JACK_R |
| S |  | GND | C1.2, C2.2, C3.2, C5.2, C6.2, C7.2, C8.2, C9.2, C10.2, C11.2, C12.2, C29.2, C30.2, C31.2, ... (+168 more) | GND |
| T |  | LINE_JACK_L | K1.3 | LINE_JACK_L |

### J5 1/8in BINAURAL HEADPHONE OUT (SJ1-3533NG)

| Pin | Pin name | Net | Other ends | PCB pad net |
|---|---|---|---|---|
| R |  | HP_JACK_R | R66.2 | HP_JACK_R |
| S |  | GND | C1.2, C2.2, C3.2, C5.2, C6.2, C7.2, C8.2, C9.2, C10.2, C11.2, C12.2, C29.2, C30.2, C31.2, ... (+168 more) | GND |
| T |  | HP_JACK_L | R65.2 | HP_JACK_L |

### K1 G6K-2F-Y 5VDC (G6K-2F-Y DC5)

| Pin | Pin name | Net | Other ends | PCB pad net |
|---|---|---|---|---|
| 1 |  | +5V | C4.1, C5.1, C6.1, C7.1, C61.1, C65.1, C95.1, D3.2 (A), D13.1 (K), J3.1 (Pin_1), L1.2, Q8.2 (S), R1.1, R3.1, ... (+10 more) | +5V |
| 2 |  | LINE_L | C57.1, C67.1, R62.2 | LINE_L |
| 3 |  | LINE_JACK_L | J4.T | LINE_JACK_L |
| 4 |  | GND | C1.2, C2.2, C3.2, C5.2, C6.2, C7.2, C8.2, C9.2, C10.2, C11.2, C12.2, C29.2, C30.2, C31.2, ... (+167 more) | GND |
| 5 |  | GND | C1.2, C2.2, C3.2, C5.2, C6.2, C7.2, C8.2, C9.2, C10.2, C11.2, C12.2, C29.2, C30.2, C31.2, ... (+167 more) | GND |
| 6 |  | LINE_JACK_R | J4.R | LINE_JACK_R |
| 7 |  | LINE_R | C58.1, C68.1, R63.2 | LINE_R |
| 8 |  | LINE_MUTE_K | D13.2 (A), Q2.3 (D) | LINE_MUTE_K |

### SW2 RECORD START/STOP (TS02-66-150-BK-160-LCR-D)

| Pin | Pin name | Net | Other ends | PCB pad net |
|---|---|---|---|---|
| 1 | 1 | REC_SW | D18.1 (K), Q3.1 (G), R86.2 | REC_SW |
| 2 | 2 | GND | C1.2, C2.2, C3.2, C5.2, C6.2, C7.2, C8.2, C9.2, C10.2, C11.2, C12.2, C29.2, C30.2, C31.2, ... (+168 more) | GND |

### SW3 MASTER GAIN (EC11E15244G1)

| Pin | Pin name | Net | Other ends | PCB pad net |
|---|---|---|---|---|
| A | A | GAIN_A | C48.1, R51.2, U8.29 (D29) | GAIN_A |
| B | B | GAIN_B | C49.1, R52.2, U8.30 (D30) | GAIN_B |
| C | C | GND | C1.2, C2.2, C3.2, C5.2, C6.2, C7.2, C8.2, C9.2, C10.2, C11.2, C12.2, C29.2, C30.2, C31.2, ... (+167 more) | GND |
| S1 | S1 | GAIN_SW | D19.1 (K), Q4.1 (G), R87.2 | GAIN_SW |
| S2 | S2 | GND | C1.2, C2.2, C3.2, C5.2, C6.2, C7.2, C8.2, C9.2, C10.2, C11.2, C12.2, C29.2, C30.2, C31.2, ... (+167 more) | GND |

### SW4 TFT MENU NAV (RKJXT1F42001)

| Pin | Pin name | Net | Other ends | PCB pad net |
|---|---|---|---|---|
| 5 | PUSH | NAV_PUSH | C73.1, R74.2, U8.40 (D40) | NAV_PUSH |
| 6 | COM | GND | C1.2, C2.2, C3.2, C5.2, C6.2, C7.2, C8.2, C9.2, C10.2, C11.2, C12.2, C29.2, C30.2, C31.2, ... (+167 more) | GND |
| 7 | E_B | NAV_ENC_B | C94.1, R97.2, U8.27 (D27) | NAV_ENC_B |
| 8 | E_A | NAV_ENC_A | C93.1, R96.2, U8.26 (D26) | NAV_ENC_A |
| 9 | E_C | GND | C1.2, C2.2, C3.2, C5.2, C6.2, C7.2, C8.2, C9.2, C10.2, C11.2, C12.2, C29.2, C30.2, C31.2, ... (+167 more) | GND |
| 10 | NC | __unnamed_26 | (nothing else: single-pin net) | - |
| A | A/DOWN | NAV_DOWN | C70.1, R71.2, U8.37 (D37) | NAV_DOWN |
| B | B/RIGHT | NAV_RIGHT | C72.1, R73.2, U8.39 (D39) | NAV_RIGHT |
| C | C/UP | NAV_UP | C69.1, R70.2, U8.36 (D36) | NAV_UP |
| D | D/LEFT | NAV_LEFT | C71.1, R72.2, U8.38 (D38) | NAV_LEFT |

K1 sense to verify at bring-up (Omron G6K-2F-Y drawing): coil 1 (+) / 8 (-); contacts 2/7 NC, 3/6 COM, 4/5 NO. As wired: COM 3/6 = jack tips, NC 2/7 = LINE_L/R (audio passes with the coil off), NO 4/5 = GND (tips grounded when energised).

## 7. Every net, with its pins

212 nets. Power and ground nets are summarised in section 3; everything else is listed here so a wrong label is easy to spot. Format: `NET: ref.pin, ref.pin, ...`.

- `+9V_FUSED` (3): D1.2, D17.2, F1.2
- `+9V_IN` (2): F1.1, J1.1
- `ADC_BCLK` (3): R48.1, TP4.1, U8.21
- `ADC_BCLK_IC` (2): R48.2, U7.17
- `ADC_DOUT2` (3): R69.2, TP7.1, U8.6
- `ADC_DOUT2_IC` (2): R69.1, U7.22
- `ADC_LDO` (3): C43.1, C62.1, U7.11
- `ADC_LRCLK` (3): R47.1, TP5.1, U8.20
- `ADC_LRCLK_IC` (2): R47.2, U7.16
- `ADC_MCLK` (3): R46.1, TP3.1, U8.23
- `ADC_MCLK_IC` (2): R46.2, U7.15
- `ADC_TDM` (3): R49.2, TP6.1, U8.8
- `ADC_TDM_IC` (2): R49.1, U7.18
- `ADC_VREF` (3): C39.1, C40.1, U7.6
- `BAT_SENSE` (4): C89.1, R89.2, R90.1, U8.16
- `BIAS5` (2): D24.2, Q8.3
- `BIAS_SRC` (3): D24.1, Q6.3, R67.1
- `BLD_AC` (4): C19.2, R16.1, R22.1, U5.13
- `BLD_ACC` (4): C103.2, R116.1, R128.1, U16.10
- `BLD_ADC` (4): C31.1, R36.2, R40.1, U7.1
- `BLD_ADC_SRC` (2): C27.2, R36.1
- `BLD_ATT` (3): R22.2, R23.1, U5.12
- `BLD_CFB` (4): C107.1, R120.1, R124.1, U16.9
- `BLD_CPRE` (3): R28.2, R120.2, U16.8
- `BLD_FB` (4): C23.2, R28.1, R32.2, U6.9
- `BLD_MIC` (4): C15.1, C19.1, R8.2, R12.2
- `BLD_MICC` (4): C99.1, C103.1, R112.2, U5.4
- `BLD_PAD` (2): U5.14, U6.10
- `BLD_PRE` (4): C23.1, C27.1, R32.1, U6.8
- `BLD_RAW` (3): D8.1, J2.4, R12.1
- `BLD_RAWC` (3): D22.1, J2.5, R112.1
- `BOOST_COMP` (3): C81.1, R79.1, U11.8
- `BOOST_COMP_C` (2): C80.1, R79.2
- `BOOST_EN` (6): D15.1, D16.1, D17.1, Q4.3, R88.1, U11.4
- `BOOST_FB` (3): R80.2, R81.1, U11.9
- `BOOST_FREQ` (2): R82.1, U11.10
- `BOOST_SS` (2): C79.1, U11.5
- `BOOST_SW` (4): D12.2, L2.2, U11.1, U11.2
- `BRU_AC` (4): C20.2, R17.1, R24.1, U5.1
- `BRU_ACC` (4): C104.2, R117.1, R129.1, U16.12
- `BRU_ADC` (4): C32.1, R37.2, R41.1, U7.2
- `BRU_ADC_SRC` (2): C28.2, R37.1
- `BRU_ATT` (3): R24.2, R25.1, U5.2
- `BRU_CFB` (4): C108.1, R121.1, R125.1, U16.13
- `BRU_CPRE` (3): R29.2, R121.2, U16.14
- `BRU_FB` (4): C24.2, R29.1, R33.2, U6.13
- `BRU_MIC` (4): C16.1, C20.1, R9.2, R13.2
- `BRU_MICC` (4): C100.1, C104.1, R113.2, U15.4
- `BRU_PAD` (2): U5.15, U6.12
- `BRU_PRE` (4): C24.1, C28.1, R33.1, U6.14
- `BRU_RAW` (3): D9.1, J2.7, R13.1
- `BRU_RAWC` (3): D23.1, J2.8, R113.1
- `BUCK_FB` (4): C4.2, R1.2, R2.1, U1.5
- `BUCK_PG` (2): R3.2, U1.8
- `BUCK_SW` (2): L1.1, U1.7
- `CHG_ILIM` (2): R91.1, U13.12
- `CHG_ISET` (2): R92.1, U13.16
- `CHG_STAT_N` (3): R94.2, U8.17, U13.9
- `CHG_TS` (2): R93.1, U13.1
- `COLD_CTRL` (2): R107.1, U8.41
- `COLD_CTRL_G` (3): Q5.1, R107.2, R108.1
- `COLD_SEL` (6): Q5.3, R106.2, U4.9, U5.9, U15.9, U15.10
- `CTP_RST` (2): J3.11, U8.14
- `DAC_BCLK` (3): R57.1, TP9.1, U8.4
- `DAC_BCLK_IC` (2): R57.2, U9.13
- `DAC_CAPM` (2): C51.2, U9.4
- `DAC_CAPP` (2): C51.1, U9.2
- `DAC_DIN` (3): R58.1, TP11.1, U8.2
- `DAC_DIN_IC` (2): R58.2, U9.14
- `DAC_L` (2): R62.1, U9.6
- `DAC_LDO` (2): C53.1, U9.18
- `DAC_LRCLK` (3): R59.1, TP10.1, U8.3
- `DAC_LRCLK_IC` (2): R59.2, U9.15
- `DAC_MUTE` (2): R61.1, U8.34
- `DAC_MUTE_IC` (3): R60.1, R61.2, U9.17
- `DAC_R` (2): R63.1, U9.7
- `DAC_VNEG` (2): C52.1, U9.5
- `FLU_AC` (4): C17.2, R14.1, R18.1, U4.13
- `FLU_ACC` (4): C101.2, R114.1, R126.1, U16.3
- `FLU_ADC` (4): C29.1, R34.2, R38.1, U7.3
- `FLU_ADC_SRC` (2): C25.2, R34.1
- `FLU_ATT` (3): R18.2, R19.1, U4.12
- `FLU_CFB` (4): C105.1, R118.1, R122.1, U16.2
- `FLU_CPRE` (3): R26.2, R118.2, U16.1
- `FLU_FB` (4): C21.2, R26.1, R30.2, U6.2
- `FLU_MIC` (4): C13.1, C17.1, R6.2, R10.2
- `FLU_MICC` (4): C97.1, C101.1, R110.2, U4.4
- `FLU_PAD` (2): U4.14, U6.3
- `FLU_PRE` (4): C21.1, C25.1, R30.1, U6.1
- `FLU_RAW` (3): D6.1, J2.1, R10.1
- `FLU_RAWC` (3): D20.1, J2.2, R110.1
- `FRD_AC` (4): C18.2, R15.1, R20.1, U4.1
- `FRD_ACC` (4): C102.2, R115.1, R127.1, U16.5
- `FRD_ADC` (4): C30.1, R35.2, R39.1, U7.4
- `FRD_ADC_SRC` (2): C26.2, R35.1
- `FRD_ATT` (3): R20.2, R21.1, U4.2
- `FRD_CFB` (4): C106.1, R119.1, R123.1, U16.6
- `FRD_CPRE` (3): R27.2, R119.2, U16.7
- `FRD_FB` (4): C22.2, R27.1, R31.2, U6.6
- `FRD_MIC` (4): C14.1, C18.1, R7.2, R11.2
- `FRD_MICC` (4): C98.1, C102.1, R111.2, U15.15
- `FRD_PAD` (2): U4.15, U6.5
- `FRD_PRE` (4): C22.1, C26.1, R31.1, U6.7
- `FRD_RAW` (3): D7.1, J2.3, R11.1
- `FRD_RAWC` (3): D21.1, J2.6, R111.1
- `GAIN_A` (4): C48.1, R51.2, SW3.A, U8.29
- `GAIN_B` (4): C49.1, R52.2, SW3.B, U8.30
- `GAIN_PUSH` (4): C50.1, D19.2, R53.2, U8.31
- `GAIN_SW` (4): D19.1, Q4.1, R87.2, SW3.S1
- `HP_CPN` (2): C59.2, U10.17
- `HP_CPP` (2): C59.1, U10.18
- `HP_ENABLE` (3): R64.1, U8.33, U10.6
- `HP_INP_L` (2): C86.1, U10.2
- `HP_INP_R` (2): C87.1, U10.4
- `HP_IN_L` (2): C57.2, U10.1
- `HP_IN_R` (2): C58.2, U10.5
- `HP_JACK_L` (2): J5.T, R65.2
- `HP_JACK_R` (2): J5.R, R66.2
- `HP_OUT_L` (2): R65.1, U10.14
- `HP_OUT_R` (2): R66.1, U10.11
- `HP_VSS` (3): C60.1, U10.15, U10.16
- `I2C_SCL` (5): J3.10, R45.2, U7.24, U8.19, U10.8
- `I2C_SDA` (5): J3.12, R44.2, U7.23, U8.18, U10.7
- `KEEP_ON` (2): D15.2, U8.24
- `LDO_FB` (3): R130.2, R131.1, U12.4
- `LINE_JACK_L` (2): J4.T, K1.3
- `LINE_JACK_R` (2): J4.R, K1.6
- `LINE_L` (4): C57.1, C67.1, K1.2, R62.2
- `LINE_MUTE` (2): R84.1, U8.5
- `LINE_MUTE_G` (3): Q2.1, R84.2, R85.1
- `LINE_MUTE_K` (3): D13.2, K1.8, Q2.3
- `LINE_R` (4): C58.1, C68.1, K1.7, R63.2
- `MIC5_CTRL` (2): R102.1, U8.0
- `MIC5_CTRL_G` (3): Q9.1, R102.2, R103.1
- `MIC5_G` (3): Q8.1, Q9.3, R101.2
- `MIC9_CTRL` (2): R99.1, U8.1
- `MIC9_CTRL_G` (3): Q7.1, R99.2, R100.1
- `MIC9_G` (3): Q6.1, Q7.3, R98.2
- `NAV_DOWN` (4): C70.1, R71.2, SW4.A, U8.37
- `NAV_ENC_A` (4): C93.1, R96.2, SW4.8, U8.26
- `NAV_ENC_B` (4): C94.1, R97.2, SW4.7, U8.27
- `NAV_LEFT` (4): C71.1, R72.2, SW4.D, U8.38
- `NAV_PUSH` (4): C73.1, R74.2, SW4.5, U8.40
- `NAV_RIGHT` (4): C72.1, R73.2, SW4.B, U8.39
- `NAV_UP` (4): C69.1, R70.2, SW4.C, U8.36
- `PAD_CTRL` (2): R42.1, U8.32
- `PAD_CTRL_G` (3): Q1.1, R42.2, R43.1
- `PAD_SELECT` (7): C33.1, Q1.3, R83.2, U4.10, U4.11, U5.10, U5.11
- `PGOOD_N` (3): R95.2, U8.25, U13.7
- `PWR_LATCH_MID` (2): Q3.3, Q4.2
- `PWR_LED_A` (2): D4.2, R54.2
- `REC_BUTTON` (4): C47.1, D18.2, R50.2, U8.28
- `REC_LED` (2): R55.1, U8.35
- `REC_LED_A` (2): D5.2, R55.2
- `REC_SW` (4): D18.1, Q3.1, R86.2, SW2.1
- `SPI_MISO` (2): J3.9, U8.12
- `SPI_MOSI` (2): J3.6, U8.11
- `SPI_SCK` (2): J3.7, U8.13
- `TFT_CS` (2): J3.3, U8.10
- `TFT_DC` (2): J3.5, U8.9
- `TFT_LED` (2): J3.8, R56.2
- `TFT_RST` (2): J3.4, U8.7
- `TOUCH_IRQ` (2): J3.13, U8.22
- `USB_CC1` (2): J9.A5, R75.1
- `USB_CC2` (2): J9.B5, R76.1
- `USB_DM` (5): D11.3, D11.4, J9.A7, J9.B7, TP2.1
- `USB_DP` (5): D11.1, D11.6, J9.A6, J9.B6, TP1.1
- `VBUS_SENSE` (4): C78.1, R77.2, R78.1, U8.15
- `VREF_NR` (2): C9.1, U3.8
- `__unnamed_0` (1): J9.A8
- `__unnamed_1` (1): J9.B8
- `__unnamed_10` (1): U5.5
- `__unnamed_11` (1): U15.2
- `__unnamed_12` (1): U15.5
- `__unnamed_13` (1): U15.12
- `__unnamed_14` (1): U15.14
- `__unnamed_15` (1): U7.5
- `__unnamed_16` (1): U7.9
- `__unnamed_17` (1): U7.10
- `__unnamed_18` (1): U7.19
- `__unnamed_19` (1): U7.20
- `__unnamed_2` (1): U2.4
- `__unnamed_20` (1): U7.21
- `__unnamed_21` (1): U7.27
- `__unnamed_22` (1): U7.28
- `__unnamed_23` (1): U7.29
- `__unnamed_24` (1): U7.30
- `__unnamed_25` (1): U8.3V3B
- `__unnamed_26` (1): SW4.10
- `__unnamed_27` (1): J3.14
- `__unnamed_3` (1): U14.4
- `__unnamed_4` (1): U3.4
- `__unnamed_5` (1): U3.5
- `__unnamed_6` (1): U3.6
- `__unnamed_7` (1): U3.7
- `__unnamed_8` (1): U13.15
- `__unnamed_9` (1): U4.5

## 8. Teensy 4.1 pin map (U8)

| Teensy pin | Net | Direction | Function |
|---|---|---|---|
| 0 | MIC5_CTRL | out | high = 5 V electret bias (via R102 -> Q9 -> Q8) |
| 1 | MIC9_CTRL | out | high = 9 V electret bias (via R99 -> Q7 -> Q6). Never both high; both low = bias off |
| 2 | DAC_DIN | out (I2S) | PCM5102A data (R58 33R) |
| 3 | DAC_LRCLK | out (I2S) | PCM5102A LRCK (R59 33R) |
| 4 | DAC_BCLK | out (I2S) | PCM5102A BCK (R57 33R) |
| 5 | LINE_MUTE | out | high = relay K1 energised = line out muted (via R84 -> Q2) |
| 6 | ADC_DOUT2 | in (I2S) | PCM1864 second data line (GPIO0 as DOUT2, R69 33R) |
| 7 | TFT_RST | out | TFT reset (J3 pin 4) |
| 8 | ADC_TDM | in (I2S) | PCM1864 DOUT (R49 33R) |
| 9 | TFT_DC | out | TFT data/command (J3 pin 5) |
| 10 | TFT_CS | out | TFT chip select (J3 pin 3) |
| 11 | SPI_MOSI | out | TFT SDI (J3 pin 6) |
| 12 | SPI_MISO | in | TFT SDO (J3 pin 9) |
| 13 | SPI_SCK | out | TFT SCK (J3 pin 7) |
| 14 | CTP_RST | out | touch controller reset (J3 pin 11) |
| 15 | VBUS_SENSE | analog in | USB VBUS / 3.13 (100k/47k): 5 V -> 1.60 V |
| 16 | BAT_SENSE | analog in | VBAT / 2 (1M/1M): 4.2 V -> 2.10 V |
| 17 | CHG_STAT_N | in | charger /CHG (open drain, R94 100k pull-up), low = charging |
| 18 | I2C_SDA | I2C | PCM1864, TPA6130A2 (0x60), FT6336U touch; R44 4.7k pull-up |
| 19 | I2C_SCL | I2C | same bus; R45 4.7k pull-up |
| 20 | ADC_LRCLK | out (I2S) | PCM1864 LRCK (R47 33R) |
| 21 | ADC_BCLK | out (I2S) | PCM1864 BCK (R48 33R) |
| 22 | TOUCH_IRQ | in | FT6336U interrupt (J3 pin 13) |
| 23 | ADC_MCLK | out | PCM1864 SCK master clock (R46 33R) |
| 24 | KEEP_ON | out | high holds BOOST_EN through D15 (soft-power latch) |
| 25 | PGOOD_N | in | charger /PGOOD (R95 100k pull-up), low = USB power good |
| 26 | NAV_ENC_A | in | SW4 encoder phase A (R96 10k / C93 10n) |
| 27 | NAV_ENC_B | in | SW4 encoder phase B (R97 10k / C94 10n) |
| 28 | REC_BUTTON | in | SW2 record button through D18 (R50 10k / C47 100n), active low |
| 29 | GAIN_A | in | SW3 encoder phase A (R51 10k / C48 10n) |
| 30 | GAIN_B | in | SW3 encoder phase B (R52 10k / C49 10n) |
| 31 | GAIN_PUSH | in | SW3 push through D19 (R53 10k / C50 100n), active low |
| 32 | PAD_CTRL | out | high = -9.7 dB pad engaged (via R42 -> Q1). Firmware must keep it LOW in dynamic-mic mode |
| 33 | HP_ENABLE | out | TPA6130A2 /SD: high = headphone amp on (R64 100k pull-down) |
| 34 | DAC_MUTE | out | PCM5102A XSMT: high = un-mute (R61 100R, R60 10k pull-DOWN) |
| 35 | REC_LED | out | red LED D5 through R55 1k |
| 36 | NAV_UP | in | SW4 (R70 10k / C69 100n), active low |
| 37 | NAV_DOWN | in | SW4 (R71 / C70) |
| 38 | NAV_LEFT | in | SW4 (R72 / C71) |
| 39 | NAV_RIGHT | in | SW4 (R73 / C72) |
| 40 | NAV_PUSH | in | SW4 centre push (R74 / C73) |
| 41 | COLD_CTRL | out | high = cold legs released = dynamic/balanced mode (via R107 -> Q5). Low/boot = electret mode (cold legs grounded) |
| VIN | TEENSY_VIN | power | +5V through D3 (cut the VIN-VUSB link on the module) |
| 3.3V (3V3A, left row) | +3V3_D | power out | Teensy regulator output: all pull-ups |
| 3.3V (3V3B, right row, next to VIN/GND) | no connect | power out | same regulator output inside the module; left NC since 2026-09-15 (see section 16) |
| GND (x3) | GND | power |  |
| USB D+/D- pads | TP1 / TP2 | wires | underside USB-device pads wired to TP1 (D+) and TP2 (D-) |

Teensy pins with a net that are not in the table above: 3V3A=+3V3_D, GND1=GND, GND2=GND, GND3=GND.

## 9. The analog channel, stage by stage (values as drawn, one channel; the other three are identical)

Reference allocation is regular: channel n = FLU(1), FRD(2), BLD(3), BRU(4). Hot leg parts: R(5+n) bias, R(9+n) 100R, C(12+n) 100p, C(16+n) 4u7, R(13+n) 1M, R(18+2(n-1)) 68k / R(19+2(n-1)) 33k pad, R(26+n-1) 10k, R(30+n-1) 90.9k, C(20+n) 22p, C(24+n) 4u7, R(34+n-1) 100R, C(28+n) 10n, R(38+n-1) 100k DNP. Cold leg: R(109+n) 100R, C(96+n) 100p, C(100+n) 4u7, R(113+n) 1M, R(125+n) 100k, R(117+n) 10k, R(121+n) 90.9k, C(104+n) 22p.

| Stage | Parts (FLU) | Function | Number to check |
|---|---|---|---|
| Bias feed | R6 4.7k from +9V_MIC to FLU_MIC | electret phantom (2-wire) | 9 V / 4.7k = 1.9 mA max into a shorted capsule; typical capsule 0.5 mA at ~6.5 V |
| RF stop | R10 100R + C13 100p to CHASSIS (hot), R110 100R + C97 100p (cold), D6/D20 PESD | keeps RF off the pair, symmetrical both legs | corner 1/(2 pi 100 x 100p) = 16 MHz |
| Coupling | C17 4.7 uF PMLCAP (hot), C101 4.7 uF (cold) | blocks the bias / mic DC | into 1M: 0.034 Hz; into the 92k hot load: 0.37 Hz (both far below audio) |
| Input bias | R14 1M hot -> VREF; R114 1M + R126 100k cold -> VREF | both inputs sit at VREF = 4.5 V | hot sees 1M parallel 101k = 92k, cold 1M parallel 100k = 91k (balanced within 1 %) |
| Pad | R18 68k / R19 33k 0.1 % to VREF, switched by U4 (A section) | direct or -9.7 dB | 33/(68+33) = 0.327 = -9.7 dB; select high (default) = direct |
| Cold-leg ground | U4 C section (pins 4/3), COLD_SEL pin 9 | electret mode grounds FLU_MICC | CD4053 on-resistance ~120 R at 9 V |
| A1 (cold amp) | U16 unit A: + = FLU_ACC, out = FLU_CPRE, R118 10k CFB-CPRE, R122 90.9k CFB-VREF, C105 22p across R122 | non-inverting gain 1 + 10k/90.9k = 1.11 | C105 gives the zero that tracks A2's pole |
| A2 (hot amp) | U6 unit A: + = FLU_PAD, out = FLU_PRE, R26 10k FB-CPRE, R30 90.9k PRE-FB, C21 22p across R30 | Vout = (1 + 90.9/10)(hot - cold) = 10.09 x = +20.08 dB | -3 dB at 1/(2 pi 90.9k x 22p) = 80 kHz; SPICE: 20.06 dB, 71 kHz |
| Output coupling | C25 4.7 uF PMLCAP -> R34 100R -> C29 10 nF C0G -> PCM1864 VINL1 | re-biases to the ADC's own AVDD/2 | RC corner 1/(2 pi 100 x 10n) = 159 kHz (anti-alias); R38 100k DNP |

Full-scale check: PCM1864 input is 2.1 Vrms (single-ended, 0 dB PGA), which with the 10.09x (+20.08 dB) gain is 0.21 Vrms at the capsule. The op-amp itself, on a 9 V single supply centred at 4.5 V, swings about 4.4 V peak = 3.1 Vrms (OPA1654 rail-to-rail output, ~100 mV from each rail), which is 0.31 Vrms referred to the input; so the ADC reaches full scale (0.21 Vrms in) before the op-amp clips (0.31 Vrms in), and hot electret levels need the -9.7 dB pad.

### Mic-mode logic (all four channels together)

| Screen setting | Teensy 1 MIC9_CTRL | Teensy 0 MIC5_CTRL | Teensy 41 COLD_CTRL | Q6 | Q8 | +9V_MIC | COLD_SEL (U4/U5/U15 pin 9) | Cold legs | Pad allowed |
|---|---|---|---|---|---|---|---|---|---|
| Boot / unknown | low | low | low | off | off | 0 V (bleeds through R104) | high (R106 to +9V) | grounded | yes |
| Electret 9 V | high | low | low | on | off | 9.0 V | high | grounded | yes |
| Electret 5 V | low | high | low | off | on | ~4.7 V (D24 drop) | high | grounded | yes |
| Dynamic / balanced | low | low | high | off | off | 0 V | low (Q5 pulls it down) | released into A1 | NO (firmware lockout) |

Sequencing rule for firmware: when leaving a bias mode, drop MIC9/MIC5 first, wait for +9V_MIC to bleed (R104 100k x C66 100 uF = 10 s time constant; read it back is not possible, so wait or accept a thump), then raise COLD_CTRL. Never raise a bias with COLD_CTRL high.

## 10. Arithmetic on every set point (check these against the datasheets)

| What | Parts | Formula | Result | Datasheet / expectation |
|---|---|---|---|---|
| Boost output +10V5 | R80 75k, R81 10k | 1.229 x (1 + 75/10) | 10.45 V | TPS61175 Vfb 1.229 V; input 4.4-9 V OK (must be below output) |
| Boost frequency | R82 80.6k | TPS61175 curve | ~1.2 MHz | datasheet table: 80.6k ~ 1.2 MHz |
| Boost soft start | C79 47 nF | ~ | ~ms | standard value |
| Boost compensation | R79 10k, C80 4.7n, C81 47p | type II | zero 3.4 kHz, pole 340 kHz | verify load step on the bench |
| LDO output +9V | R130 130k, R131 20k | 1.2 x (1 + 130/20) | 9.00 V | ADP7142 Vref 1.2 V; dropout at 40 mA << 1.45 V headroom |
| LDO dissipation | 10.45 - 9.0 = 1.45 V x 25-40 mA | | 36-58 mW | TSOT 170 C/W -> +6-10 C |
| Buck output +5V | R1 680k, R2 130k, C4 22p | 0.8 x (1 + 680/130) | 4.98 V | TPS62160 Vfb 0.8 V; C4 feed-forward per datasheet |
| Buck PG pull-up | R3 100k to +5V | | | BUCK_PG unused elsewhere |
| 3.3 V LDOs | U2, U14 fixed | | 3.30 V | TPS7A2033: EN tied to IN, 1 uF in / 4.7 uF out (C7/C8, C95/C96) |
| VREF | U3 TLE2426 | +9V / 2 | 4.50 V | C9 1 uF on NR pin, C10 47 uF + C11 100 nF on OUT |
| Mic bias filter | R67 100R, C66 100 uF | 1/(2 pi RC) | 16 Hz | 1.9 mA x 4 max through 100R = 0.76 V drop worst case, typical 0.2 V |
| Mic bias bleed | R104 100k, C66 100 uF | tau | 10 s | bias falls to 1 V in ~22 s after switching off |
| Electret bias current | R6-R9 4.7k | (9 - Vcap)/4.7k | ~0.5-0.9 mA | capsule FET typical 0.5 mA |
| VBUS sense | R77 100k, R78 47k | 5 x 47/147 | 1.60 V | Teensy ADC 3.3 V max |
| Battery sense | R89 1M, R90 1M, C89 100n | 4.2 / 2 | 2.10 V | 2 uA drain; RC 0.05 s |
| Charger current | R92 1.2k ISET | 890 / 1.2k | 0.74 A | BQ24074 K_ISET = 890 |
| Charger input limit | R91 1.1k ILIM | 1610 / 1.1k | 1.46 A | EN2 (pin 5) = VBUS_FUSED = high, EN1 (pin 6) = GND -> 'set by ILIM resistor' row of the BQ24074 truth table (verified against the datasheet 2026-09-15) |
| Charger TS | R93 10k to GND | | always in range | pack PCM provides protection |
| Charger timer / termination | TMR pin 14 = GND, ITERM pin 15 open | | timers off, ITERM = 10 % of ISET (74 mA) | matches the design note; CE (pin 4) = GND = charging enabled |
| Power LED | R54 2.2k from +5V, D4 blue Vf 3.0 | (5 - 3)/2.2k | 0.9 mA | dim but visible; raise R54 current if needed |
| Record LED | R55 1k from Teensy pin 35, D5 red Vf 2.0 | (3.3 - 2)/1k | 1.3 mA | Teensy 4 mA/pin guideline |
| TFT backlight | R56 100R from +5V | | ~20 mA class | module has its own LED driver? verify; 95 mA spec at full brightness |
| Relay coil | K1 5 V, 21 mA; Q2 2N7002; D13 flyback | | | Q2 Rds 2 R at 3.3 V gate: fine |
| I2C pull-ups | R44/R45 4.7k to +3V3_D | | 0.7 mA per line | three slaves: PCM1864, TPA6130A2 (0x60), FT6336U (0x38) |
| ADC clock terminations | R46-R49, R69, R57-R59 33R | | | series at the driver |
| DAC output filter | R62/R63 470R, C67/C68 2.2n C0G | 1/(2 pi 470 x 2.2n) | 154 kHz | TI recommended |
| Headphone input | C57/C58 2.2 uF PMLCAP into TPA6130A2 20k | 1/(2 pi 20k x 2.2u) | 3.6 Hz | C86/C87 match on INP |
| Headphone output | R65/R66 10R | | | isolation into the 3.5 mm jack |
| Soft power pull-ups | R86/R87 1M to VBAT, R88 1M to GND | | ~4 uA off-state | D15-D19 1N4148W (25 nA leakage) |
| Line-out relay sense | K1 NC = pass | | | verify at bring-up |

## 11. Digital audio and control buses

| Bus | Master | Slave(s) | Nets | Rate / notes |
|---|---|---|---|---|
| ADC I2S/TDM | Teensy SAI1 (MCLK 23, BCLK 21, LRCLK 20) | PCM1864 SCK/BCK/LRCK; data back on DOUT (pin 18 -> Teensy 8) and DOUT2 (GPIO0 pin 22 -> Teensy 6) | ADC_MCLK/BCLK/LRCLK/TDM/DOUT2, 33R each | 192 kHz, 2x I2S (four channels on two data lines); PCM1864 is the I2S slave |
| DAC I2S | Teensy (BCLK 4, LRCLK 3, DIN 2) | PCM5102A | DAC_BCLK/LRCLK/DIN, 33R each | 48 kHz binaural; PCM5102A generates its own internal clock (no MCLK) |
| I2C | Teensy 18/19 | PCM1864 (addr by MD0/MD1 = pins 25/26 = GND: 0x4A), TPA6130A2 (0x60), FT6336U touch (0x38) | I2C_SDA/SCL, 4.7k to +3V3_D | 400 kHz OK |
| SPI | Teensy 11/12/13 | ST7796U TFT (CS 10, DC 9, RST 7) | SPI_MOSI/MISO/SCK, TFT_* | display only |

PCM1864 mode/address pins as drawn: MD0/ADR1 (25) = GND, MD1/ADR0 (26) = GND -> software (I2C) control mode, address 0x4A (0x94 write). GPIO0 (22) is used as DOUT2; GPIO1-3 (19-21) are no connect. Section 4 lists each pin.

PCM5102A hard-wired mode pins: FLT (11) = GND (normal latency filter), DEMP (12) = GND (de-emphasis off), FMT (16) = GND (I2S), XSMT (17) driven by Teensy 34 with a 10k pull-DOWN (muted until firmware un-mutes).

## 12. Decoupling, pad to pad (mm)

Distance from each supply pin's pad to the nearest same-net capacitor pad, measured on the board.

| IC pin | Rail | Nearest caps (distance mm) |
|---|---|---|
| U7.8 | +3V3_A | C41 (1.4), C42 (5.4) |
| U7.13 | +3V3_DC | C44 (1.5), C45 (5.0) |
| U7.14 | +3V3_DC | C44 (1.4), C45 (5.0) |
| U7.6 | ADC_VREF | C40 (1.6), C39 (3.0) |
| U7.11 | ADC_LDO | C43 (1.4), C62 (5.1) |
| U9.1 | +3V3_A | C54 (1.3), C64 (4.7) |
| U9.8 | +3V3_A | C64 (1.3), C55 (3.6) |
| U9.20 | +3V3_DC | C56 (1.3), C45 (18.0) |
| U9.18 | DAC_LDO | C53 (1.3) |
| U9.5 | DAC_VNEG | C52 (2.8) |
| U10.12 | +5V | C65 (1.5), C61 (5.4) |
| U10.20 | +5V | C61 (1.7), C65 (5.0) |
| U10.15 | HP_VSS | C60 (1.6) |
| U10.16 | HP_VSS | C60 (2.5) |
| U6.4 | +9V | C37 (8.0), C36 (8.5) |
| U16.4 | +9V | C109 (8.7), C35 (10.0) |
| U3.3 | +9V | C34 (14.0), C36 (15.6) |
| U4.16 | +9V | C36 (3.4), C34 (4.0) |
| U5.16 | +9V | C35 (7.7), C110 (12.2) |
| U15.16 | +9V | C35 (4.1), C110 (10.6) |
| U12.1 | +10V5 | C83 (3.4), C76 (12.6) |
| U12.3 | +10V5 | C83 (2.9), C76 (14.4) |
| U12.5 | +9V | C88 (4.9), C75 (6.8) |
| U1.2 | +10V5 | C2 (6.4), C3 (10.8) |
| U1.3 | +10V5 | C2 (5.9), C3 (10.5) |
| U1.6 | +5V | C4 (6.7), C5 (8.4) |
| U11.3 | VBOOST_IN | C1 (7.9), C85 (14.6) |
| U2.1 | +5V | C7 (4.9), C95 (8.0) |
| U2.3 | +5V | C7 (4.7), C95 (9.6) |
| U2.5 | +3V3_A | C8 (3.4), C55 (9.4) |
| U14.1 | +5V | C95 (5.3), C7 (7.2) |
| U14.3 | +5V | C7 (5.9), C95 (6.5) |
| U14.5 | +3V3_DC | C96 (3.3), C45 (8.9) |
| U13.5 | VBUS_FUSED | C90 (5.2) |
| U13.13 | VBUS_FUSED | C90 (6.3) |
| U13.10 | BAT_SYS | C91 (4.1) |
| U13.11 | BAT_SYS | C91 (4.0) |
| U13.2 | VBAT | C92 (12.2) |
| U13.3 | VBAT | C92 (11.8) |

Reading: the converters (U7, U9, U10) have their 100 nF within 1.3-1.7 mm (placed under the pins). The buck U1 has its 100 nF 6 mm and 10 uF 10 mm from VIN (acceptable, on the Rev D list). The op-amps see their 100 nF at 8-9 mm on a planed 9 V LDO rail (fine for audio bandwidth). U13 charger: C90 5-6 mm from IN, C91/C92 on OUT/BAT.

## 13. Board: stackup, placement, mechanical

Stackup (in the board file): F.Cu 35 um / 0.21 mm prepreg / In1.Cu 35 um GND / 1.065 mm core / In2.Cu 35 um GND / 0.21 mm prepreg / B.Cu 35 um. All routing is on F.Cu and B.Cu; In1/In2 are solid GND (93 % fill each, one region) with rule areas that forbid tracks and vias on them. Copper-to-edge keepout 0.65 mm. Design rules: 0.20 mm track / 0.15 mm clearance, 0.30 mm supply tracks, vias 0.6/0.3 (185) and 0.8/0.4 (338).

Mounting / wall items (from the board): 4 x 3.2 mm corner holes, 2 x 3.25 mm (display standoffs?), 1 x 3.0 mm, 2 x 0.65 NPTH (J4 pegs), 3 fiducials per side.

### Placement table (every placed part: side, centre in mm from the board's top-left, rotation)

| Ref | Value | Side | X | Y | Rot | Footprint |
|---|---|---|---:|---:|---:|---|
| C1 | 100uF 25V | Top | 17.0000 | 24.5000 | 0.00 | CP_Elec_6.3x5.8 |
| C2 | 100nF 25V | Top | 108.0000 | 92.5000 | 0.00 | C_0805_2012Metric |
| C3 | 10uF 25V | Top | 114.0000 | 92.5000 | 0.00 | C_1206_3216Metric |
| C4 | 22pF C0G | Top | 113.0000 | 84.0000 | 0.00 | C_0603_1608Metric |
| C5 | 22uF 10V | Top | 117.0000 | 88.0000 | 0.00 | C_1206_3216Metric |
| C6 | 22uF 10V | Top | 123.0000 | 88.0000 | 0.00 | C_1206_3216Metric |
| C7 | 1uF 10V | Bottom | 92.5000 | 55.0000 | 0.00 | C_0805_2012Metric |
| C8 | 4.7uF 10V | Bottom | 92.5000 | 59.0000 | 0.00 | C_0805_2012Metric |
| C9 | 1uF 10V | Top | 42.0000 | 31.0000 | 0.00 | C_0805_2012Metric |
| C10 | 47uF 10V | Top | 47.0000 | 31.0000 | 0.00 | C_1206_3216Metric |
| C11 | 100nF | Top | 51.5000 | 31.0000 | 0.00 | C_0603_1608Metric |
| C12 | 1nF 1kV C0G | Top | 10.5000 | 64.0000 | 0.00 | C_0805_2012Metric |
| C13 | 100pF C0G | Top | 38.0000 | 85.5000 | 90.00 | C_0603_1608Metric |
| C14 | 100pF C0G | Top | 38.0000 | 91.8000 | 90.00 | C_0603_1608Metric |
| C15 | 100pF C0G | Top | 38.0000 | 98.1000 | 90.00 | C_0603_1608Metric |
| C16 | 100pF C0G | Top | 38.0000 | 104.4000 | 90.00 | C_0603_1608Metric |
| C17 | 4.7uF 35V FILM | Top | 42.0000 | 85.5000 | 90.00 | C_1812_4532Metric |
| C18 | 4.7uF 35V FILM | Top | 42.0000 | 91.8000 | 90.00 | C_1812_4532Metric |
| C19 | 4.7uF 35V FILM | Top | 42.0000 | 98.1000 | 90.00 | C_1812_4532Metric |
| C20 | 4.7uF 35V FILM | Top | 42.0000 | 104.4000 | 90.00 | C_1812_4532Metric |
| C21 | 22pF C0G | Bottom | 70.0000 | 85.5000 | 90.00 | C_0603_1608Metric |
| C22 | 22pF C0G | Bottom | 70.0000 | 91.8000 | 90.00 | C_0603_1608Metric |
| C23 | 22pF C0G | Bottom | 70.0000 | 98.1000 | 90.00 | C_0603_1608Metric |
| C24 | 22pF C0G | Bottom | 70.0000 | 104.4000 | 90.00 | C_0603_1608Metric |
| C25 | 4.7uF 35V FILM | Top | 74.0000 | 85.5000 | 90.00 | C_1812_4532Metric |
| C26 | 4.7uF 35V FILM | Top | 74.0000 | 91.8000 | 90.00 | C_1812_4532Metric |
| C27 | 4.7uF 35V FILM | Top | 74.0000 | 98.1000 | 90.00 | C_1812_4532Metric |
| C28 | 4.7uF 35V FILM | Top | 74.0000 | 104.4000 | 90.00 | C_1812_4532Metric |
| C29 | 10nF C0G | Top | 82.0000 | 85.5000 | 90.00 | C_0603_1608Metric |
| C30 | 10nF C0G | Top | 82.0000 | 91.8000 | 90.00 | C_0603_1608Metric |
| C31 | 10nF C0G | Top | 82.0000 | 98.1000 | 90.00 | C_0603_1608Metric |
| C32 | 10nF C0G | Top | 82.0000 | 104.4000 | 90.00 | C_0603_1608Metric |
| C33 | 100nF | Top | 10.5000 | 61.0000 | 0.00 | C_0603_1608Metric |
| C34 | 100nF | Bottom | 40.0000 | 40.0000 | 0.00 | C_0603_1608Metric |
| C35 | 100nF | Bottom | 40.0000 | 60.5000 | 0.00 | C_0603_1608Metric |
| C36 | 100nF | Bottom | 47.0000 | 42.0000 | 0.00 | C_0603_1608Metric |
| C37 | 10uF 16V | Bottom | 51.0000 | 42.0000 | 0.00 | C_1206_3216Metric |
| C39 | 1uF | Bottom | 83.0000 | 45.9000 | 0.00 | C_0805_2012Metric |
| C40 | 100nF | Bottom | 82.8000 | 47.7000 | 0.00 | C_0603_1608Metric |
| C41 | 100nF | Bottom | 82.8000 | 49.3000 | 0.00 | C_0603_1608Metric |
| C42 | 10uF | Bottom | 87.1000 | 47.4000 | 0.00 | C_1206_3216Metric |
| C43 | 100nF | Bottom | 82.8000 | 50.9000 | 0.00 | C_0603_1608Metric |
| C44 | 100nF | Bottom | 82.8000 | 52.5000 | 0.00 | C_0603_1608Metric |
| C45 | 10uF | Bottom | 87.1000 | 52.3000 | 0.00 | C_1206_3216Metric |
| C46 | 10uF | Bottom | 48.0000 | 56.0000 | 0.00 | C_1206_3216Metric |
| C47 | 100nF | Bottom | 106.0000 | 16.0000 | 0.00 | C_0603_1608Metric |
| C48 | 10nF | Bottom | 102.0000 | 24.0000 | 0.00 | C_0603_1608Metric |
| C49 | 10nF | Bottom | 106.0000 | 24.0000 | 0.00 | C_0603_1608Metric |
| C50 | 100nF | Bottom | 110.0000 | 24.0000 | 0.00 | C_0603_1608Metric |
| C51 | 2.2uF | Top | 94.7000 | 48.4000 | -90.00 | C_0805_2012Metric |
| C52 | 2.2uF | Top | 94.7000 | 51.9000 | -90.00 | C_0805_2012Metric |
| C53 | 1uF | Bottom | 102.3300 | 48.6500 | 0.00 | C_0603_1608Metric |
| C54 | 100nF | Bottom | 97.7000 | 47.0800 | 180.00 | C_0603_1608Metric |
| C55 | 10uF | Bottom | 99.9000 | 55.0000 | 0.00 | C_1206_3216Metric |
| C56 | 100nF | Bottom | 102.3000 | 47.0800 | 0.00 | C_0603_1608Metric |
| C57 | 2.2uF 25V FILM | Top | 106.4000 | 54.6000 | 0.00 | C_1210_3225Metric |
| C58 | 2.2uF 25V FILM | Top | 106.4000 | 60.2000 | 0.00 | C_1210_3225Metric |
| C59 | 1uF | Top | 112.7500 | 52.2000 | 0.00 | C_0603_1608Metric |
| C60 | 1uF | Top | 116.2500 | 54.6000 | 0.00 | C_0603_1608Metric |
| C61 | 1uF | Top | 110.3000 | 51.7500 | 90.00 | C_0603_1608Metric |
| C62 | 10uF | Bottom | 87.1000 | 49.8500 | 0.00 | C_1206_3216Metric |
| C64 | 100nF | Bottom | 97.7000 | 51.6200 | 180.00 | C_0603_1608Metric |
| C65 | 1uF | Top | 116.2500 | 56.2000 | 0.00 | C_0603_1608Metric |
| C66 | 100uF 16V | Bottom | 34.0000 | 74.0000 | 0.00 | CP_Elec_6.3x5.8 |
| C67 | 2.2nF C0G | Top | 93.0000 | 55.0000 | 0.00 | C_0603_1608Metric |
| C68 | 2.2nF C0G | Top | 96.5000 | 55.0000 | 0.00 | C_0603_1608Metric |
| C69 | 100nF | Bottom | 102.0000 | 32.0000 | 0.00 | C_0603_1608Metric |
| C70 | 100nF | Bottom | 106.0000 | 32.0000 | 0.00 | C_0603_1608Metric |
| C71 | 100nF | Bottom | 110.0000 | 32.0000 | 0.00 | C_0603_1608Metric |
| C72 | 100nF | Bottom | 114.0000 | 32.0000 | 0.00 | C_0603_1608Metric |
| C73 | 100nF | Bottom | 118.0000 | 32.0000 | 0.00 | C_0603_1608Metric |
| C74 | 10uF 16V | Top | 18.5000 | 45.0000 | 0.00 | C_1206_3216Metric |
| C75 | 100nF | Top | 17.0000 | 53.5000 | 0.00 | C_0603_1608Metric |
| C76 | 10uF 25V | Top | 13.5000 | 37.5000 | 0.00 | C_1206_3216Metric |
| C77 | 10uF 25V | Top | 18.5000 | 37.5000 | 0.00 | C_1206_3216Metric |
| C78 | 100nF | Top | 48.0000 | 14.0000 | 0.00 | C_0603_1608Metric |
| C79 | 47nF | Bottom | 15.0000 | 29.0000 | 90.00 | C_0603_1608Metric |
| C80 | 4.7nF C0G | Top | 5.0000 | 45.0000 | 0.00 | C_0603_1608Metric |
| C81 | 47pF C0G | Top | 9.0000 | 45.0000 | 0.00 | C_0603_1608Metric |
| C83 | 2.2uF | Top | 5.5000 | 50.5000 | 90.00 | C_0805_2012Metric |
| C85 | 10uF 25V | Top | 20.5000 | 18.5000 | 90.00 | C_1206_3216Metric |
| C86 | 2.2uF 25V FILM | Top | 100.4000 | 55.7000 | 180.00 | C_1210_3225Metric |
| C87 | 2.2uF 25V FILM | Top | 100.4000 | 59.1000 | 180.00 | C_1210_3225Metric |
| C88 | 10uF 16V | Top | 17.0000 | 50.0000 | 0.00 | C_1206_3216Metric |
| C89 | 100nF | Top | 132.0000 | 31.5000 | 0.00 | C_0603_1608Metric |
| C90 | 10uF 10V | Top | 124.0000 | 15.0000 | 90.00 | C_0805_2012Metric |
| C91 | 10uF 10V | Top | 135.0000 | 15.0000 | 90.00 | C_0805_2012Metric |
| C92 | 10uF 10V | Top | 136.0000 | 24.5000 | 90.00 | C_0805_2012Metric |
| C93 | 10nF | Bottom | 110.0000 | 36.0000 | 0.00 | C_0603_1608Metric |
| C94 | 10nF | Bottom | 114.0000 | 36.0000 | 0.00 | C_0603_1608Metric |
| C95 | 1uF 10V | Bottom | 92.5000 | 63.0000 | 0.00 | C_0805_2012Metric |
| C96 | 4.7uF 10V | Bottom | 88.0000 | 63.0000 | 0.00 | C_0805_2012Metric |
| C97 | 100pF C0G | Bottom | 36.0000 | 85.5000 | 90.00 | C_0603_1608Metric |
| C98 | 100pF C0G | Bottom | 36.0000 | 91.8000 | 90.00 | C_0603_1608Metric |
| C99 | 100pF C0G | Bottom | 36.0000 | 98.1000 | 90.00 | C_0603_1608Metric |
| C100 | 100pF C0G | Bottom | 36.0000 | 104.4000 | 90.00 | C_0603_1608Metric |
| C101 | 4.7uF 35V FILM | Bottom | 44.0000 | 85.5000 | 90.00 | C_1812_4532Metric |
| C102 | 4.7uF 35V FILM | Bottom | 44.0000 | 91.8000 | 90.00 | C_1812_4532Metric |
| C103 | 4.7uF 35V FILM | Bottom | 44.0000 | 98.1000 | 90.00 | C_1812_4532Metric |
| C104 | 4.7uF 35V FILM | Bottom | 44.0000 | 104.4000 | 90.00 | C_1812_4532Metric |
| C105 | 22pF C0G | Bottom | 63.0000 | 85.5000 | 90.00 | C_0603_1608Metric |
| C106 | 22pF C0G | Bottom | 63.0000 | 91.8000 | 90.00 | C_0603_1608Metric |
| C107 | 22pF C0G | Bottom | 63.0000 | 98.1000 | 90.00 | C_0603_1608Metric |
| C108 | 22pF C0G | Bottom | 63.0000 | 104.4000 | 90.00 | C_0603_1608Metric |
| C109 | 100nF | Top | 57.5000 | 58.5000 | 90.00 | C_0603_1608Metric |
| C110 | 100nF | Top | 33.5000 | 60.5000 | 0.00 | C_0603_1608Metric |
| D1 | B340A 40V 3A | Top | 14.5000 | 18.5000 | 0.00 | D_SMA |
| D2 | SMBJ12A | Top | 8.0000 | 23.5000 | 0.00 | D_SMB |
| D3 | SS14 | Bottom | 48.0000 | 60.0000 | 0.00 | D_SMA |
| D4 | POWER BLUE | Top | 64.7300 | 112.1000 | 0.00 | LED_D3.0mm_Horizontal_O1.27mm_Z6.0mm |
| D5 | RECORD RED | Top | 74.7300 | 112.1000 | 0.00 | LED_D3.0mm_Horizontal_O1.27mm_Z6.0mm |
| D6 | PESD12VL1BA | Top | 24.0000 | 68.0000 | 90.00 | D_SOD-323 |
| D7 | PESD12VL1BA | Top | 24.0000 | 72.0000 | 90.00 | D_SOD-323 |
| D8 | PESD12VL1BA | Top | 24.0000 | 76.0000 | 90.00 | D_SOD-323 |
| D9 | PESD12VL1BA | Top | 24.0000 | 80.0000 | 90.00 | D_SOD-323 |
| D10 | B340A 40V 3A | Top | 52.0000 | 10.5000 | 0.00 | D_SMA |
| D11 | USBLC6-2SC6 | Top | 40.0000 | 12.8000 | 0.00 | SOT-23-6 |
| D12 | B340A 40V 3A | Top | 7.0000 | 37.5000 | 0.00 | D_SMA |
| D13 | 1N4148W | Top | 104.0000 | 100.5000 | 0.00 | D_SOD-123 |
| D14 | B340A 40V 3A | Top | 131.0000 | 24.5000 | 0.00 | D_SMA |
| D15 | 1N4148W | Top | 123.5000 | 28.2000 | 0.00 | D_SOD-123 |
| D16 | 1N4148W | Top | 128.3000 | 28.2000 | 0.00 | D_SOD-123 |
| D17 | 1N4148W | Top | 133.1000 | 28.2000 | 0.00 | D_SOD-123 |
| D18 | 1N4148W | Bottom | 98.0000 | 16.0000 | 0.00 | D_SOD-123 |
| D19 | 1N4148W | Bottom | 98.0000 | 20.0000 | 0.00 | D_SOD-123 |
| D20 | PESD12VL1BA | Bottom | 40.0000 | 85.5000 | 90.00 | D_SOD-323 |
| D21 | PESD12VL1BA | Bottom | 40.0000 | 91.8000 | 90.00 | D_SOD-323 |
| D22 | PESD12VL1BA | Bottom | 40.0000 | 98.1000 | 90.00 | D_SOD-323 |
| D23 | PESD12VL1BA | Bottom | 40.0000 | 104.4000 | 90.00 | D_SOD-323 |
| D24 | BAT54 | Top | 34.0000 | 82.5000 | 0.00 | D_SOD-123 |
| F1 | 750mA PTC | Top | 7.0000 | 18.5000 | 0.00 | Fuse_1206_3216Metric |
| F2 | 2A PTC | Top | 52.0000 | 6.0000 | 0.00 | Fuse_1206_3216Metric |
| J1 | 9V DC IN | Top | 17.5000 | 8.2000 | 180.00 | BarrelJack_CUI_PJ-102AH_Horizontal |
| J2 | AMBISONIC MIC RJ45 | Top | 4.0000 | 74.0000 | -90.00 | RJ45_Amphenol_RJHSE5380 |
| J3 | MSP3526 TFT 3.5IN 14PIN SOCKET | Top | 25.0000 | 19.2400 | 0.00 | PinSocket_1x14_P2.54mm_Vertical |
| J4 | 1/4in BINAURAL LINE OUT | Top | 26.0000 | 98.0000 | -90.00 | Jack_6.35mm_Neutrik_NRJ6HF_Horizontal |
| J5 | 1/8in BINAURAL HEADPHONE OUT | Top | 135.9000 | 41.0000 | -90.00 | Jack_3.5mm_CUI_SJ1-3533NG_Horizontal |
| J9 | USB-C POWER + DATA | Top | 40.0000 | 2.6000 | 180.00 | USB_C_Receptacle_HRO_TYPE-C-31-M-12 |
| J10 | BATTERY 1S LiPo | Bottom | 121.0000 | 109.5000 | 0.00 | JST_PH_B2B-PH-K_1x02_P2.00mm_Vertical |
| K1 | G6K-2F-Y 5VDC | Top | 113.0000 | 103.5000 | 0.00 | Relay_DPDT_Omron_G6K-2F-Y |
| L1 | 2.2uH 1.5A | Top | 111.5000 | 88.0000 | 0.00 | L_Abracon_ASPIAIG-F4020 |
| L2 | 10uH 2A | Top | 18.0000 | 31.5000 | 0.00 | L_Bourns_SRN6045TA |
| Q1 | 2N7002 | Top | 6.0000 | 58.0000 | 0.00 | SOT-23 |
| Q2 | 2N7002 | Top | 104.0000 | 104.0000 | 0.00 | SOT-23 |
| Q3 | AO3401A | Top | 30.0000 | 67.0000 | 0.00 | SOT-23 |
| Q4 | AO3401A | Top | 30.0000 | 71.0000 | 0.00 | SOT-23 |
| Q5 | 2N7002 | Top | 34.0000 | 64.5000 | 0.00 | SOT-23 |
| Q6 | AO3401A | Top | 34.0000 | 75.5000 | 0.00 | SOT-23 |
| Q7 | 2N7002 | Top | 34.0000 | 79.5000 | 0.00 | SOT-23 |
| Q8 | AO3401A | Top | 38.0000 | 75.5000 | 180.00 | SOT-23 |
| Q9 | 2N7002 | Top | 38.0000 | 79.5000 | 180.00 | SOT-23 |
| R1 | 680k | Top | 105.0000 | 84.0000 | 0.00 | R_0603_1608Metric |
| R2 | 130k | Top | 109.0000 | 84.0000 | 0.00 | R_0603_1608Metric |
| R3 | 100k | Top | 117.0000 | 84.0000 | 0.00 | R_0603_1608Metric |
| R4 | 1M | Top | 6.0000 | 64.0000 | 0.00 | R_0603_1608Metric |
| R6 | 4.7k ELECTRET BIAS | Top | 30.0000 | 85.5000 | 90.00 | R_0603_1608Metric |
| R7 | 4.7k ELECTRET BIAS | Top | 30.0000 | 91.8000 | 90.00 | R_0603_1608Metric |
| R8 | 4.7k ELECTRET BIAS | Top | 30.0000 | 98.1000 | 90.00 | R_0603_1608Metric |
| R9 | 4.7k ELECTRET BIAS | Top | 30.0000 | 104.4000 | 90.00 | R_0603_1608Metric |
| R10 | 100R RF | Top | 34.0000 | 85.5000 | 90.00 | R_0603_1608Metric |
| R11 | 100R RF | Top | 34.0000 | 91.8000 | 90.00 | R_0603_1608Metric |
| R12 | 100R RF | Top | 34.0000 | 98.1000 | 90.00 | R_0603_1608Metric |
| R13 | 100R RF | Top | 34.0000 | 104.4000 | 90.00 | R_0603_1608Metric |
| R14 | 1M | Top | 46.0000 | 85.5000 | 90.00 | R_0603_1608Metric |
| R15 | 1M | Top | 46.0000 | 91.8000 | 90.00 | R_0603_1608Metric |
| R16 | 1M | Top | 46.0000 | 98.1000 | 90.00 | R_0603_1608Metric |
| R17 | 1M | Top | 46.0000 | 104.4000 | 90.00 | R_0603_1608Metric |
| R18 | 68k 0.1% | Top | 50.0000 | 85.5000 | 90.00 | R_0603_1608Metric |
| R19 | 33k 0.1% | Top | 54.0000 | 85.5000 | 90.00 | R_0603_1608Metric |
| R20 | 68k 0.1% | Top | 50.0000 | 91.8000 | 90.00 | R_0603_1608Metric |
| R21 | 33k 0.1% | Top | 54.0000 | 91.8000 | 90.00 | R_0603_1608Metric |
| R22 | 68k 0.1% | Top | 50.0000 | 98.1000 | 90.00 | R_0603_1608Metric |
| R23 | 33k 0.1% | Top | 54.0000 | 98.1000 | 90.00 | R_0603_1608Metric |
| R24 | 68k 0.1% | Top | 50.0000 | 104.4000 | 90.00 | R_0603_1608Metric |
| R25 | 33k 0.1% | Top | 54.0000 | 104.4000 | 90.00 | R_0603_1608Metric |
| R26 | 10k 0.1% | Bottom | 60.0000 | 85.5000 | 90.00 | R_0603_1608Metric |
| R27 | 10k 0.1% | Bottom | 60.0000 | 91.8000 | 90.00 | R_0603_1608Metric |
| R28 | 10k 0.1% | Bottom | 60.0000 | 98.1000 | 90.00 | R_0603_1608Metric |
| R29 | 10k 0.1% | Bottom | 60.0000 | 104.4000 | 90.00 | R_0603_1608Metric |
| R30 | 90.9k 0.1% | Bottom | 66.0000 | 85.5000 | 90.00 | R_0603_1608Metric |
| R31 | 90.9k 0.1% | Bottom | 66.0000 | 91.8000 | 90.00 | R_0603_1608Metric |
| R32 | 90.9k 0.1% | Bottom | 66.0000 | 98.1000 | 90.00 | R_0603_1608Metric |
| R33 | 90.9k 0.1% | Bottom | 66.0000 | 104.4000 | 90.00 | R_0603_1608Metric |
| R34 | 100R | Top | 78.0000 | 85.5000 | 90.00 | R_0603_1608Metric |
| R35 | 100R | Top | 78.0000 | 91.8000 | 90.00 | R_0603_1608Metric |
| R36 | 100R | Top | 78.0000 | 98.1000 | 90.00 | R_0603_1608Metric |
| R37 | 100R | Top | 78.0000 | 104.4000 | 90.00 | R_0603_1608Metric |
| R42 | 100R | Top | 10.5000 | 57.5000 | 0.00 | R_0603_1608Metric |
| R43 | 100k | Top | 14.5000 | 57.5000 | 0.00 | R_0603_1608Metric |
| R44 | 4.7k | Bottom | 96.0000 | 40.0000 | 0.00 | R_0603_1608Metric |
| R45 | 4.7k | Bottom | 100.0000 | 40.0000 | 0.00 | R_0603_1608Metric |
| R46 | 33R | Bottom | 104.0000 | 40.0000 | 0.00 | R_0603_1608Metric |
| R47 | 33R | Bottom | 108.0000 | 40.0000 | 0.00 | R_0603_1608Metric |
| R48 | 33R | Bottom | 112.0000 | 40.0000 | 0.00 | R_0603_1608Metric |
| R49 | 33R | Bottom | 116.0000 | 40.0000 | 0.00 | R_0603_1608Metric |
| R50 | 10k | Bottom | 102.0000 | 16.0000 | 0.00 | R_0603_1608Metric |
| R51 | 10k | Bottom | 102.0000 | 20.0000 | 0.00 | R_0603_1608Metric |
| R52 | 10k | Bottom | 106.0000 | 20.0000 | 0.00 | R_0603_1608Metric |
| R53 | 10k | Bottom | 110.0000 | 20.0000 | 0.00 | R_0603_1608Metric |
| R54 | 2.2k | Top | 70.0000 | 108.0000 | 0.00 | R_0603_1608Metric |
| R55 | 1k | Top | 78.0000 | 108.0000 | 0.00 | R_0603_1608Metric |
| R56 | 100R TFT BACKLIGHT | Top | 88.0000 | 57.0000 | 0.00 | R_0805_2012Metric |
| R57 | 33R | Bottom | 86.5000 | 44.5000 | 0.00 | R_0603_1608Metric |
| R58 | 33R | Bottom | 90.5000 | 44.5000 | 0.00 | R_0603_1608Metric |
| R59 | 33R | Bottom | 94.5000 | 44.5000 | 0.00 | R_0603_1608Metric |
| R60 | 10k | Bottom | 98.5000 | 44.5000 | 0.00 | R_0603_1608Metric |
| R61 | 100R | Bottom | 102.5000 | 44.5000 | 0.00 | R_0603_1608Metric |
| R62 | 470R | Top | 93.0000 | 58.0000 | 0.00 | R_0603_1608Metric |
| R63 | 470R | Top | 96.5000 | 58.0000 | 0.00 | R_0603_1608Metric |
| R64 | 100k | Top | 108.0000 | 48.0000 | 0.00 | R_0603_1608Metric |
| R65 | 10R | Top | 125.0000 | 64.0000 | 0.00 | R_0603_1608Metric |
| R66 | 10R | Top | 125.0000 | 67.5000 | 0.00 | R_0603_1608Metric |
| R67 | 100R MIC BIAS FILTER | Top | 28.0000 | 80.0000 | 0.00 | R_0603_1608Metric |
| R69 | 33R | Bottom | 120.0000 | 40.0000 | 0.00 | R_0603_1608Metric |
| R70 | 10k | Bottom | 102.0000 | 28.0000 | 0.00 | R_0603_1608Metric |
| R71 | 10k | Bottom | 106.0000 | 28.0000 | 0.00 | R_0603_1608Metric |
| R72 | 10k | Bottom | 110.0000 | 28.0000 | 0.00 | R_0603_1608Metric |
| R73 | 10k | Bottom | 114.0000 | 28.0000 | 0.00 | R_0603_1608Metric |
| R74 | 10k | Bottom | 118.0000 | 28.0000 | 0.00 | R_0603_1608Metric |
| R75 | 5.1k | Top | 33.0000 | 9.0000 | 90.00 | R_0603_1608Metric |
| R76 | 5.1k | Top | 47.0000 | 9.0000 | 90.00 | R_0603_1608Metric |
| R77 | 100k | Top | 56.0000 | 14.0000 | 0.00 | R_0603_1608Metric |
| R78 | 47k | Top | 52.0000 | 14.0000 | 0.00 | R_0603_1608Metric |
| R79 | 10k | Top | 17.0000 | 41.5000 | 0.00 | R_0603_1608Metric |
| R80 | 75k | Top | 5.0000 | 41.5000 | 0.00 | R_0603_1608Metric |
| R81 | 10k | Top | 9.0000 | 41.5000 | 0.00 | R_0603_1608Metric |
| R82 | 80.6k | Top | 13.0000 | 41.5000 | 0.00 | R_0603_1608Metric |
| R83 | 10k | Top | 18.5000 | 57.5000 | 0.00 | R_0603_1608Metric |
| R84 | 100R | Top | 100.0000 | 104.0000 | 0.00 | R_0603_1608Metric |
| R85 | 100k | Top | 100.0000 | 107.5000 | 0.00 | R_0603_1608Metric |
| R86 | 1M | Top | 30.0000 | 74.5000 | 0.00 | R_0603_1608Metric |
| R87 | 1M | Top | 30.0000 | 77.5000 | 0.00 | R_0603_1608Metric |
| R88 | 1M | Top | 136.5000 | 28.5000 | 90.00 | R_0603_1608Metric |
| R89 | 1M | Top | 124.0000 | 31.5000 | 0.00 | R_0603_1608Metric |
| R90 | 1M | Top | 128.0000 | 31.5000 | 0.00 | R_0603_1608Metric |
| R91 | 1.1k ILIM | Top | 123.5000 | 20.5000 | 0.00 | R_0603_1608Metric |
| R92 | 1.2k ISET | Top | 127.0000 | 20.5000 | 0.00 | R_0603_1608Metric |
| R93 | 10k TS | Top | 130.5000 | 20.5000 | 0.00 | R_0603_1608Metric |
| R94 | 100k | Top | 134.0000 | 20.5000 | 0.00 | R_0603_1608Metric |
| R95 | 100k | Top | 124.0000 | 24.5000 | 0.00 | R_0603_1608Metric |
| R96 | 10k | Bottom | 102.0000 | 36.0000 | 0.00 | R_0603_1608Metric |
| R97 | 10k | Bottom | 106.0000 | 36.0000 | 0.00 | R_0603_1608Metric |
| R98 | 100k | Top | 41.0000 | 74.0000 | 90.00 | R_0603_1608Metric |
| R99 | 100R | Top | 41.0000 | 80.2000 | 90.00 | R_0603_1608Metric |
| R100 | 100k | Top | 26.5000 | 70.9000 | 90.00 | R_0603_1608Metric |
| R101 | 100k | Top | 41.0000 | 77.1000 | 90.00 | R_0603_1608Metric |
| R102 | 100R | Top | 38.0000 | 82.5000 | 0.00 | R_0603_1608Metric |
| R103 | 100k | Top | 26.5000 | 74.0000 | 90.00 | R_0603_1608Metric |
| R104 | 100k BLEED | Top | 26.5000 | 77.1000 | 90.00 | R_0603_1608Metric |
| R106 | 10k | Top | 34.5000 | 68.5000 | 0.00 | R_0603_1608Metric |
| R107 | 100R | Top | 38.0000 | 68.5000 | 0.00 | R_0603_1608Metric |
| R108 | 100k | Top | 34.5000 | 71.5000 | 0.00 | R_0603_1608Metric |
| R110 | 100R RF | Bottom | 32.0000 | 85.5000 | 90.00 | R_0603_1608Metric |
| R111 | 100R RF | Bottom | 32.0000 | 91.8000 | 90.00 | R_0603_1608Metric |
| R112 | 100R RF | Bottom | 32.0000 | 98.1000 | 90.00 | R_0603_1608Metric |
| R113 | 100R RF | Bottom | 32.0000 | 104.4000 | 90.00 | R_0603_1608Metric |
| R114 | 1M | Bottom | 48.0000 | 85.5000 | 90.00 | R_0603_1608Metric |
| R115 | 1M | Bottom | 48.0000 | 91.8000 | 90.00 | R_0603_1608Metric |
| R116 | 1M | Bottom | 48.0000 | 98.1000 | 90.00 | R_0603_1608Metric |
| R117 | 1M | Bottom | 48.0000 | 104.4000 | 90.00 | R_0603_1608Metric |
| R118 | 10k 0.1% | Bottom | 52.0000 | 85.5000 | 90.00 | R_0603_1608Metric |
| R119 | 10k 0.1% | Bottom | 52.0000 | 91.8000 | 90.00 | R_0603_1608Metric |
| R120 | 10k 0.1% | Bottom | 52.0000 | 98.1000 | 90.00 | R_0603_1608Metric |
| R121 | 10k 0.1% | Bottom | 52.0000 | 104.4000 | 90.00 | R_0603_1608Metric |
| R122 | 90.9k 0.1% | Bottom | 56.0000 | 85.5000 | 90.00 | R_0603_1608Metric |
| R123 | 90.9k 0.1% | Bottom | 56.0000 | 91.8000 | 90.00 | R_0603_1608Metric |
| R124 | 90.9k 0.1% | Bottom | 56.0000 | 98.1000 | 90.00 | R_0603_1608Metric |
| R125 | 90.9k 0.1% | Bottom | 56.0000 | 104.4000 | 90.00 | R_0603_1608Metric |
| R126 | 100k | Bottom | 50.0000 | 85.5000 | 90.00 | R_0603_1608Metric |
| R127 | 100k | Bottom | 50.0000 | 91.8000 | 90.00 | R_0603_1608Metric |
| R128 | 100k | Bottom | 50.0000 | 98.1000 | 90.00 | R_0603_1608Metric |
| R129 | 100k | Bottom | 50.0000 | 104.4000 | 90.00 | R_0603_1608Metric |
| R130 | 130k | Top | 13.3000 | 48.6000 | 90.00 | R_0603_1608Metric |
| R131 | 20k | Top | 13.3000 | 52.4000 | 90.00 | R_0603_1608Metric |
| SW2 | RECORD START/STOP | Top | 43.7500 | 71.2500 | 0.00 | SW_PUSH_6mm |
| SW3 | MASTER GAIN | Top | 61.5000 | 71.0000 | 0.00 | RotaryEncoder_Alps_EC11E-Switch_Vertical_H20mm |
| SW4 | TFT MENU NAV | Top | 91.0000 | 73.5000 | 0.00 | SW_Nav5_ALPS_RKJXT1F42001 |
| U1 | TPS62160DGK | Top | 105.0000 | 88.0000 | 0.00 | VSSOP-8_3x3mm_P0.65mm |
| U2 | TPS7A2033PDBV | Bottom | 88.0000 | 55.6000 | 0.00 | SOT-23-5 |
| U3 | TLE2426ID | Top | 46.0000 | 26.0000 | 0.00 | SOIC-8_3.9x4.9mm_P1.27mm |
| U4 | CD4053BPW | Top | 40.0000 | 44.0000 | 0.00 | TSSOP-16_4.4x5mm_P0.65mm |
| U5 | CD4053BPW | Top | 40.0000 | 56.0000 | 0.00 | TSSOP-16_4.4x5mm_P0.65mm |
| U6 | OPA1654 | Top | 52.0000 | 50.0000 | 0.00 | TSSOP-14_4.4x5mm_P0.65mm |
| U7 | PCM1864DBT | Top | 83.5000 | 49.5000 | 0.00 | TSSOP-30_4.4x7.8mm_P0.5mm |
| U8 | Teensy 4.1 | Bottom | 60.0000 | 62.5000 | 0.00 | Teensy41_Socket |
| U9 | PCM5102A | Top | 100.0000 | 50.0000 | 0.00 | TSSOP-20_4.4x6.5mm_P0.65mm |
| U10 | TPA6130A2RTJ | Top | 112.0000 | 56.0000 | 0.00 | WQFN-20-1EP_4x4mm_P0.5mm_EP2.7x2.7mm |
| U11 | TPS61175PWP | Top | 9.5000 | 31.5000 | 180.00 | Texas_HTSSOP-14-1EP_4.4x5mm_P0.65mm_EP3.4x5mm_Mask3.155x3.255mm |
| U12 | ADP7142AUJZ | Top | 9.5000 | 50.5000 | 0.00 | TSOT-23-5 |
| U13 | BQ24074RGT | Top | 129.5000 | 16.5000 | 0.00 | VQFN-16-1EP_3x3mm_P0.5mm_EP1.68x1.68mm |
| U14 | TPS7A2033PDBV | Bottom | 88.0000 | 59.5000 | 0.00 | SOT-23-5 |
| U15 | CD4053BPW | Top | 40.5000 | 63.0000 | 0.00 | TSSOP-16_4.4x5mm_P0.65mm |
| U16 | OPA1654 | Top | 52.0000 | 61.5000 | 0.00 | TSSOP-14_4.4x5mm_P0.65mm |

(Y in the CPL is negative-down per KiCad; shown here as positive distance from the top edge. Test points TP1-TP14 and fiducials are not placements.)

### Test points (bottom side)

| TP | Net | Position |
|---|---|---|
| TP1 | USB_DP | (56.5, 18.0) B.Cu |
| TP2 | USB_DM | (56.5, 21.5) B.Cu |
| TP3 | ADC_MCLK | (84.5, 36.5) B.Cu |
| TP4 | ADC_BCLK | (88.0, 36.5) B.Cu |
| TP5 | ADC_LRCLK | (91.5, 36.5) B.Cu |
| TP6 | ADC_TDM | (95.0, 36.5) B.Cu |
| TP7 | ADC_DOUT2 | (98.5, 36.5) B.Cu |
| TP8 | GND | (81.0, 36.5) B.Cu |
| TP9 | DAC_BCLK | (86.5, 42.2) B.Cu |
| TP10 | DAC_LRCLK | (90.5, 42.2) B.Cu |
| TP11 | DAC_DIN | (94.5, 42.2) B.Cu |
| TP12 | +3V3_DC | (84.0, 63.0) B.Cu |
| TP13 | GND | (82.5, 42.2) B.Cu |
| TP14 | GND | (81.0, 59.5) B.Cu |

## 14. Longest and most exposed nets

| Net | Length (mm) | Segments | Vias | Layers |
|---|---:|---:|---:|---|
| +5V | 364.0 | 126 | 10 | B.Cu 162, F.Cu 202 |
| CHASSIS | 250.9 | 77 | 4 | B.Cu 159, F.Cu 92 |
| VBAT | 234.1 | 54 | 6 | B.Cu 118, F.Cu 116 |
| VREF | 219.2 | 94 | 2 | B.Cu 141, F.Cu 79 |
| +9V | 205.9 | 74 | 4 | B.Cu 59, F.Cu 146 |
| I2C_SCL | 182.6 | 52 | 3 | B.Cu 62, F.Cu 120 |
| +10V5 | 180.8 | 44 | 4 | B.Cu 28, F.Cu 153 |
| BOOST_EN | 173.3 | 30 | 3 | B.Cu 54, F.Cu 120 |
| VBOOST_IN | 169.2 | 36 | 0 | F.Cu 169 |
| +3V3_D | 164.6 | 64 | 5 | B.Cu 73, F.Cu 92 |
| +9V_FUSED | 160.4 | 17 | 2 | B.Cu 31, F.Cu 130 |
| GAIN_SW | 157.2 | 38 | 2 | B.Cu 103, F.Cu 54 |
| GND | 154.5 | 186 | 302 | B.Cu 39, F.Cu 116 |
| NAV_ENC_A | 150.3 | 37 | 3 | B.Cu 136, F.Cu 14 |
| I2C_SDA | 144.6 | 45 | 3 | B.Cu 50, F.Cu 95 |
| REC_SW | 137.6 | 25 | 2 | B.Cu 93, F.Cu 45 |
| GAIN_B | 135.8 | 18 | 1 | B.Cu 89, F.Cu 46 |
| NAV_DOWN | 122.1 | 33 | 1 | B.Cu 114, F.Cu 8 |
| NAV_ENC_B | 121.2 | 22 | 2 | B.Cu 82, F.Cu 39 |
| TFT_LED | 116.4 | 38 | 5 | B.Cu 41, F.Cu 75 |
| NAV_PUSH | 115.4 | 23 | 0 | B.Cu 115 |
| NAV_RIGHT | 114.1 | 23 | 0 | B.Cu 114 |
| GAIN_A | 113.8 | 17 | 1 | B.Cu 84, F.Cu 30 |
| NAV_UP | 112.4 | 22 | 1 | B.Cu 97, F.Cu 15 |
| VBUS_FUSED | 111.9 | 30 | 2 | B.Cu 9, F.Cu 103 |
| NAV_LEFT | 107.8 | 25 | 1 | B.Cu 106, F.Cu 2 |
| REC_LED | 107.2 | 22 | 1 | B.Cu 104, F.Cu 3 |
| HP_ENABLE | 101.8 | 15 | 3 | B.Cu 78, F.Cu 23 |
| BRU_CPRE | 96.3 | 18 | 1 | B.Cu 77, F.Cu 20 |
| LINE_JACK_L | 96.2 | 16 | 2 | B.Cu 6, F.Cu 90 |

Crosstalk audit (tools/audio_audit2.py on the final board): 0 broadside pairs (clock over analog on facing layers), 12 same-layer parallel clock/analog runs totalling 45.9 mm; worst ADC_TDM_IC beside BRU_ADC 9.9 mm at 0.15 mm on B.Cu near (83, 64), then ADC_MCLK_IC beside BLD_ADC 8.1 mm at 0.30 mm. The victims are the 10 nF-terminated _ADC nodes. Bench item.

## 15. DRC and ERC, every severity

ERC: 0 errors, 0 warnings (CD4053 switch pins are typed passive in the embedded symbol so the bidirectional-to-power warnings do not fire).

DRC with `--severity-all --all-track-errors --schematic-parity` on the final board:

| Rule | Count | Severity | What it is |
|---|---:|---|---|
| footprint_symbol_field_mismatch | 199 | warning | schematic symbols carry an AltMPN field the footprints do not; informational |
| net_conflict | 199 | warning | the generated schematic uses root-sheet local labels, which KiCad names '/NET' while the board says 'NET'; connectivity is identical (parity 0 at error level) |
| silk_overlap | 105 | warning | reference designator text overlapping other silk text; cosmetic, the assembly PDFs are the readable copy |
| silk_over_copper | 98 | warning | reference text crossing a pad; the Gerber export subtracts the solder mask so nothing prints on copper |
| silk_edge_clearance | 17 | warning | connector outlines (J2, J4, D4, D5) drawn past the board edge because the parts overhang the wall |

Errors: 0. Unconnected: 0. The all-severity run after the 2026-09-15 re-route also listed 4 hole_to_hole warnings (GND stitching vias dropped into the J10, SW2 and U8 GND pad holes by the stitching pass); those vias were removed before the counts above were taken. The In1/In2 layer types are power, TP1/TP2 are excluded from the BOM, and the U11/U13 exposed-pad thermal vias are in place, all re-applied after the re-route.
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

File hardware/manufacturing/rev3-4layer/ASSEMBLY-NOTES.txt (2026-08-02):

QuadPreRecorder Rev 3 - Assembly Notes
======================================

BOARD
  4-layer FR-4, 138.15 x 114.15 mm, 1.6 mm, 1 oz outer + 1 oz inner
  Stackup top -> bottom:
     L1  F_Cu    signal
     L2  In1_Cu  SOLID GROUND PLANE
     L3  In2_Cu  signal + ground pour
     L4  B_Cu    signal

ASSEMBLY
  Two-sided SMT.  180 placements total: 113 top, 67 bottom.
  74 BOM lines: 61 SMD lines, 13 through-hole lines.

  Fine-pitch parts needing care:
     U7   PCM1864DBT   TSSOP-30, 0.5 mm pitch
     U10  TPA6132A2    WQFN-16 with exposed thermal pad, 0.5 mm pitch
     U1   TPS62160DGK  VSSOP-8, 0.65 mm pitch
     U4,U5,U6,U9       TSSOP, 0.65 mm pitch

  Through-hole parts (13): J1 J2 J3 J4 J5 J6 J7 RV1 SW1 SW2 SW3 SW4 U8

  U8 is a socket for a Teensy 4.1 module. Please confirm whether the
  Teensy 4.1 module itself is included in your quote or supplied by me.

SUBSTITUTION POLICY  (see the Substitution column in the BOM)
  This is an audio product. The BOM marks every line either:

    "EXACT PART - do not substitute"   (27 lines)
        All ICs, connectors, switches, diodes, the inductor and the
        volume pot. Use the exact manufacturer part number given.

    "EQUIVALENT OK - must meet spec"   (47 lines)
        Generic passives. Any manufacturer is fine PROVIDED the part
        meets the full spec in the Description column - value,
        tolerance, dielectric, voltage rating and package.

  Two things that are NOT negotiable within the "equivalent OK" group:
    - The 0.1 % thin-film resistors (R18-R37, 68k/33k/10k/90.9k).
      These set the preamp gain. 1 % parts are NOT acceptable.
    - C0G/NP0 dielectric where the BOM says C0G/NP0. Do not swap to
      X7R or X5R - these are in the audio and clock paths.
    - C1 and C66 electrolytics must be LOW-ESR types (switching
      regulator input/output).

  ONE known stock issue: SW3, the master gain encoder, MPN
  EC11E15244G1, was showing zero stock at Mouser. Any EC11E-family
  rotary encoder with the same footprint and shaft is acceptable.

FILES
  Gerbers + drill ....... QuadPreRecorder-Rev3-4L-GERBERS-ONLY.zip
  BOM ................... QuadPreRecorder-Rev3-4L-BOM-PCBWay.csv
  Centroid .............. QuadPreRecorder-Rev3-4L-CPL-PCBWay.csv
                          (origin = board bottom-left, all coords positive,
                           rotation in degrees CCW)

  DRC status: 0 unconnected, 0 errors, schematic parity clean.

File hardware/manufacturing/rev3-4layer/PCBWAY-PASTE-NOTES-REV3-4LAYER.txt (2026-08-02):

=============================================================
PCBWAY ORDER - PASTE-READY NOTES
=============================================================

Upload file:
  hardware\manufacturing\QuadPreRecorder-Rev3-4Layer-PCBWay.zip

Use the ORANGE "Quick Order  (Upload files & checkout)" button on
the PCB Instant Quote page. Uploading the zip auto-detects
4 layers, 138 x 114 mm, and 5/5 mil track/spacing correctly.

-------------------------------------------------------------
AFTER UPLOAD, ONLY THESE NEED CHANGING FROM THE DEFAULTS
-------------------------------------------------------------
  Quantity ................ 5   (or whatever you want)
  Surface finish .......... HASL lead free      (defaults to leaded)
  Assembly Service ........ tick the checkbox
     - Turnkey (PCBWay supply parts)   <- already the default
     - Board type: Single pieces       <- already the default
     - Assembly side(s): BOTH SIDES    <- defaults to Top only!
     - Quantity: 5
     - "Accept alternatives/substitutes made in China?" -> leave NO

Everything else (FR-4, 1.6 mm, 1 oz outer + 1 oz inner, 0.3 mm
min hole, tenting vias, green mask, white silkscreen) is already
correct by default or auto-detected.

-------------------------------------------------------------
LAYER ORDER POPUP (appears when 4 layers is detected)
-------------------------------------------------------------
  L1:  F_Cu (top)
  L2:  In1_Cu (solid GND plane)
  L3:  In2_Cu (signal + GND pour)
  L4:  B_Cu (bottom)

-------------------------------------------------------------
PASTE INTO "Detailed information of assembly"
-------------------------------------------------------------
Two-sided SMT assembly: 180 placements (113 top, 67 bottom). BOM and centroid files are inside the uploaded zip: QuadPreRecorder-Rev3-4L-BOM.csv and QuadPreRecorder-Rev3-4L-CPL.csv.

SUBSTITUTIONS: This is an audio product - please do NOT substitute any part without checking with me first. ONE exception: the gain encoder EC11E15244G1 was showing zero stock at Mouser, so any EC11E-family rotary encoder with the same footprint and shaft is acceptable. All op-amps, the PCM1864 ADC and audio-path passives must be the exact parts specified.

STACKUP: 4-layer. L1 = F_Cu, L2 = In1_Cu (solid ground plane), L3 = In2_Cu (signal + ground pour), L4 = B_Cu.

-------------------------------------------------------------
PRICE SEEN DURING THE QUOTE (2026-08-01)
-------------------------------------------------------------
  Bare PCB, 5 pcs, 4-5 day build ....... $89.50
  DHL shipping to USA .................. $25.71
  ------------------------------------------------
  PCB subtotal ......................... $115.21

  Faster build options were offered at:
     72 hours  $137.36 | 48 hours  $174.92 | 24 hours  $405.75

  ASSEMBLY IS NOT IN THAT NUMBER. Turnkey assembly + parts is
  quoted manually by PCBWay after their engineers review the BOM.
  Expect that to be the larger line item.

-------------------------------------------------------------
NOTE ON THE SITE
-------------------------------------------------------------
The PCBWay quote page froze twice (renderer stopped responding)
on "Calculate" and on "Save to Cart". The uploaded files were
fine - it parsed them and rendered the board preview correctly.
If it hangs, reload and redo; nothing gets ordered until you
actually check out.

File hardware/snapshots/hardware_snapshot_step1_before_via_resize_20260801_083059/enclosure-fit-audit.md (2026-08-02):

# Enclosure and panel-fit audit

Status: PCB mechanically reworked for Hammond 1590F and rerouted. KiCad DRC/ERC
passes, but the physical enclosure stackup still must be checked with the real
box, lid, standoffs, connector shells, knobs/buttons, and TFT module before
ordering.

Checked: 2026-07-24

## Selected enclosure

Target metal enclosure: Hammond 1590F.

- Official outside size: 188 x 188 x 67 mm.
- Official maximum PCB envelope: 174.91 x 174.91 mm.
- Rev A PCB outline: 174.0 x 174.0 mm.
- Reason: the prior compact board could fit electrically but did not put J1,
  J4, and J5 on real panel edges. The 1590F gives enough PCB envelope for the
  DE-9 mic input, two DB-25 debug connectors, 9 V barrel input, 6.35 mm line
  output, 3.5 mm headphone output, headphone volume shaft, top controls, and
  TFT mounting pattern to coexist.

Reference:

- https://www.hammfg.com/part/1590F

## Selected TFT

Target capacitive TFT module: LCDWiki MSP2834 / 2.8inch IPS SPI Module ILI9341
with capacitive touch.

- Display: 2.8 inch, 240 x 320, ILI9341V over 4-wire SPI.
- Touch: capacitive, FT6336G over I2C.
- Module: 50.0 x 86.0 x 14.28 mm with touch, including header.
- Connector: 14-pin, 2.54 mm header plus optional FPC.
- PCB mounting pattern: 78 x 42 mm nominal at H5-H8.

Reference:

- https://www.lcdwiki.com/2.8inch_IPS_SPI_Module_ILI9341

## Current PCB panel-fit findings

Board outline: X=0.0 to 174.0 mm, Y=0.0 to 174.0 mm.

| Ref | Current routed placement | Status before physical stackup check |
|---|---|---|
| J2, DE-9 ambisonic mic input | X=5.20, Y=60.00, protrudes past left PCB edge | Directionally correct for left wall. Verify connector shell and mating plug clearance. |
| J1, 9 V barrel DC input | X=8.20, Y=96.00, body protrudes past left PCB edge while pads retain DRC edge clearance | Directionally corrected for left wall. Verify barrel opening against wall thickness/cutout. |
| J5, 3.5 mm headphone out | X=4.50, Y=124.00, protrudes past left PCB edge | Directionally correct for left wall. Verify jack nose and plug clearance. |
| RV1, headphone volume | X=6.50, Y=155.00, shaft/body protrudes past left PCB edge | Directionally correct for side-wall knob. Verify shaft length and knob clearance. |
| J4, 6.35 mm binaural line out | X=125.00, Y=171.00 on bottom side, protrudes past bottom PCB edge | Directionally correct for bottom wall. Verify bottom-side assembly and enclosure clearance. |
| J6, analog debug DB-25 | X=167.70, Y=26.00, protrudes past right PCB edge | Directionally correct for right wall. Verify DB-25 hardware/cable clearance. |
| J7, digital debug DB-25 | X=167.70, Y=116.00, protrudes past right PCB edge | Directionally correct for right wall. Verify DB-25 hardware/cable clearance. |
| SW1, pad enable slide switch | X=140.00, Y=78.00, top-mounted | Lid cutout required; verify actuator height. |
| SW2, record pushbutton | X=44.00, Y=10.00, top-mounted | Verify Omron B3F-4050 body/cap/plunger height against lid standoffs. |
| SW3, master gain encoder | X=68.00, Y=10.00, top-mounted | Verify shaft length, nut/washer stack, and knob clearance. |
| TFT | H5-H8 at 48/126 x 24/66 mm; J3 at X=87.00, Y=76.00 | Verify purchased MSP2834 mechanical drawing or physical sample before drilling. |

## KiCad validation after rework

- ERC: clean.
- DRC: 0 violations.
- Unconnected pads: 0.
- Schematic parity issues: 0.

## Remaining physical checks before manufacture

1. Import `QuadPreRecorder-RevA.step` into a mechanical CAD model of the Hammond
   1590F or test with a printed 1:1 drill template and bare PCB.
2. Confirm wall cutout centers and dimensions for J1, J2, J4, J5, J6, J7, and
   RV1 using the real connector bodies.
3. Confirm lid standoff height so SW1, SW2, SW3, and the TFT reach through the
   top panel without being crushed.
4. Confirm the purchased MSP2834 module revision uses the expected 14-pin order
   and the 78 x 42 mm mounting pattern.
5. Only then treat the PCBWay handoff ZIP as an order candidate.

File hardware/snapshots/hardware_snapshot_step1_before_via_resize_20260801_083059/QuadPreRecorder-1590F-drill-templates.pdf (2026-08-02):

# Page 1 LEFT wall (mic / pad / phones / volume)

Viewed from OUTSIDE the left wall. Left end of template = corner shared with the BLANK (north) wall. Board top at 15 mm below rim. Rev 2: centers from routed-board geometry. QuadPreRecorder Rev A / Hammond 1590F PRINT AT 100% SCALE (no 'fit to page')

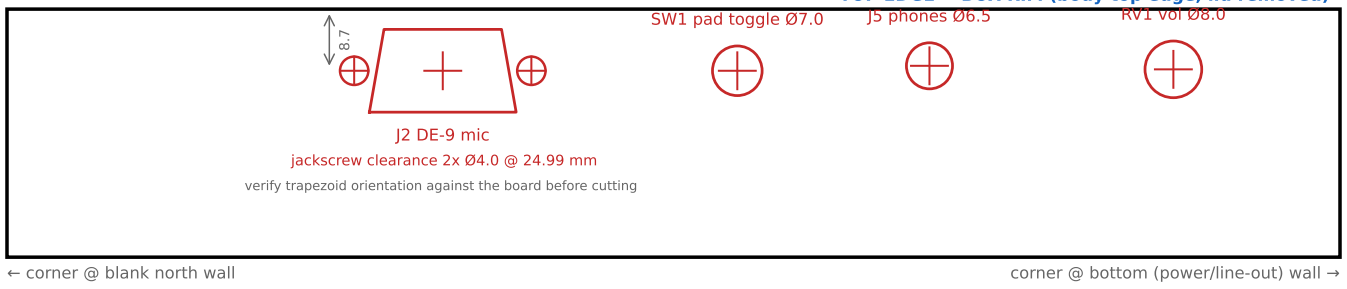
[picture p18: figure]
corner @ blank north wall; corner @ bottom (power/line-out) wall; J2 DE-9 mic; jackscrew clearance 2x Ø4.0 @ 24.99 mm; SW1 pad toggle Ø7.0; J5 phones Ø6.5; RV1 vol Ø8.0

calibration bar = exactly 100.0 mm

Verify the bar with a ruler before using this template.

188.0 mm outer width | align template ends with box corners
| TOP EDGE = BOX RIM (body top edge, lid removed)

verify trapezoid orientation against the board before cutting ⁸.7

Feature centers from LEFT end of template: J2 = 61.46 SW1 = 103.00 J5 = 130.10 RV1 = 164.50 mm Centerline depths below rim: J2 = 8.7 (7.8 if EU-style DE-9 is fitted) SW1 = 8.65 J5 = 8.0 RV1 = 8.5 mm. REV 2 NOTE: J2 moved from 67.0 (was centered on pin 1, not the shell) and RV1 from 162.0 (was the pin-1 anchor, not the shaft). If you drilled from Rev 1 of this template, re-check those two before mounting.
If you change the board depth from 15 mm, shift ALL depths on every wall by the same amount.

SW1 is the E-Switch 100SP 1/4-40 wall toggle: Ø7.0 clearance, no keyway, 8.9 mm bushing
through a ~5.5 mm wall | nut + lockwasher outside. WARNING: wall thickens toward the floor.
D-sub mating shells project 6.17 mm | the J2 shell should end ~flush with the outer face.

# Page 2 RIGHT wall (DB-25 debug connectors)

Viewed from OUTSIDE the right wall (mirrored): RIGHT end of template = corner shared with the BLANK (north) wall. Rev 2: centers from routed-board geometry.

188.0 mm outer width | align template ends with box corners
| TOP EDGE = BOX RIM (body top edge, lid removed)

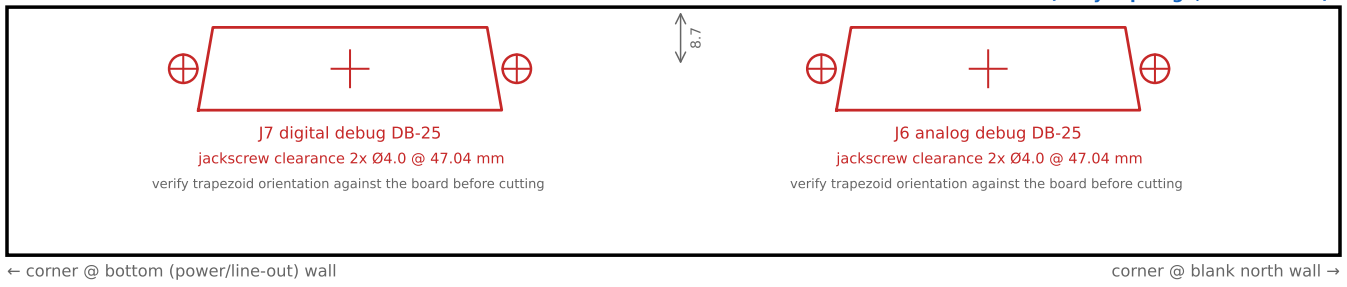
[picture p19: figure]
corner @ bottom (power/line-out) wall; corner @ blank north wall; J6 analog debug DB-25; jackscrew clearance 2x Ø4.0 @ 47.04 mm; J7 digital debug DB-25

verify trapezoid orientation against the board before cutting

verify trapezoid orientation against the board before cutting

Feature centers from LEFT end of template: J7 = 48.38 J6 = 138.38 mm; both centerlines 8.7 mm below rim. Cutout 42.8 x 11.68 mm, 10° sloped sides, R2.4 corners (standard front-mount DB-25 punch).
REV 2 NOTE: Rev 1 placed these cutouts on the connectors' pin-1 anchor 16.6 mm off. These centers are the true shell midpoints measured from the routed board. Do not use Rev 1 for this wall.

Centerline assumes 6.3 mm US-style right-angle DB-25s (matches the LD09-family BOM parts). Confirm the purchased part's centerline height before cutting.

# Page 3 BOTTOM wall (9 V power + 1/4-inch line out)

Viewed from OUTSIDE the bottom wall: LEFT end of template = corner shared with the RIGHT (debug) wall, RIGHT end = corner shared with the LEFT (mic) wall. J4 is mounted on the board's UNDERSIDE, so it sits deeper.

188.0 mm outer width | align template ends with box corners
| TOP EDGE = BOX RIM (body top edge, lid removed)

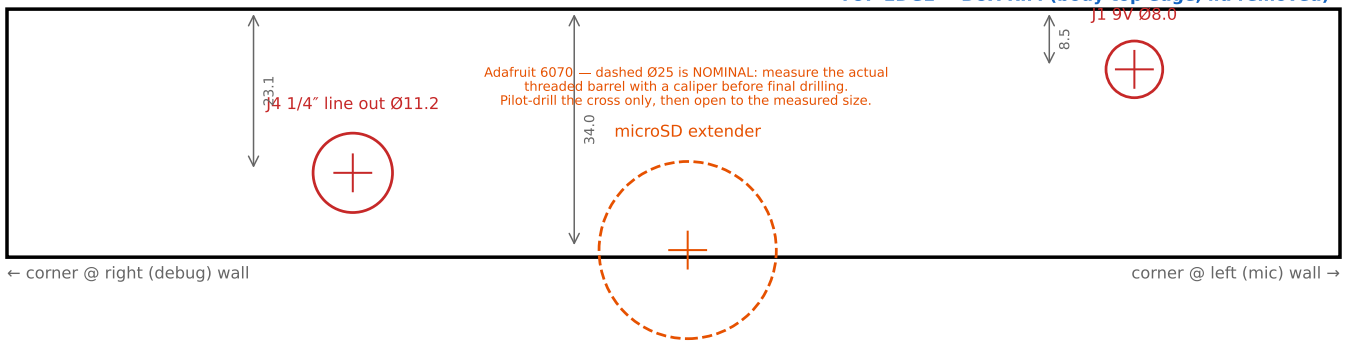
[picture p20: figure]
corner @ right (debug) wall; corner @ left (mic) wall; line out Ø11.2; microSD extender

Adafruit 6070 | dashed Ø25 is NOMINAL: measure the actual
threaded barrel with a caliper before final drilling. Pilot-drill the cross only, then open to the measured size.

Feature centers from LEFT end of template: J4 = 48.77 microSD = 96.00 J1 = 159.00 mm. Depths below rim: J4 = 23.1 (bottom-side mount) microSD = 34.0 (below the board) J1 = 8.5 mm. REV 2 NOTES: this wall now carries J1 (moved off the left wall) and this view is drawn correctly mirrored (Rev 1 was flipped left-for-right AND used J4's pad column, 7.2 mm from the true bushing axis). Do not use Rev 1 for this wall.
REV 4: microSD extender added. Wall is ~7.8 mm thick at 34 mm depth within the 6070's 16 mm panel rating. Its 18 cm flex plugs into the Teensy 4.1's own card slot (bottom side, SW corner).
Neutrik NRJ6HF bushing is 8.9 mm long; wall is ~6.9 mm thick at that depth, leaving ~2 mm of thread. If the nut will not seat, spot-face the outside ~1 mm, or run without the nut (the jack is PCB-anchored).

Page 4 | LID Rev 3 (TFT window + control row below it), 188 x 188
Viewed from OUTSIDE the closed lid. LEFT edge = left (mic) wall side; TOP edge = blank north wall side. Rev 3: REC/GAIN moved below the display and the SW4 5-way nav added | discard earlier lid prints.

dotted Ø4 = existing lid screw holes (do not drill)

SW2 record Ø9.0

B3F-5150 tall plunger (on the BOM)
pokes ~1 mm into this hole | add a keycap
SW3 gain Ø8.0 | SW4 nav Ø8.0

ALPS SKQUCAA010 stem tops out 6.5 mm below the lid
fit a ~6.5 mm glued/printed extension cap on the 3.2 mm stem. Stem rotation center can sit up to 1.3 mm off this point verify with the extension fitted before final drilling.

TFT window ~64 x 47 (VERIFY against the real
MSP2834 before cutting | glass is 69.2 x 50)
Ø3.2 module screws at 76.08 x 44.0 | the TRUE MSP2834 pattern, which the PCB's
H5-H8 match. Still verify against the purchased module.

Control-row centers from the lid's top-left corner (left = mic wall, top = blank wall):
SW2 record (63.25, 95.5) SW3 gain (82.5, 95.5) SW4 5-way nav (114.0, 95.5) TFT pattern center (94.0, 52.0) REV 3 NOTES: these are measured actuator centers, not footprint anchors Rev 2's lid page drew REC/GAIN on their anchors (~6-7 mm off) AND at the old north-edge location. Discard all earlier lid prints.
The pad switch is SW1, a toggle on the LEFT WALL (page 1) there is no lid slot.

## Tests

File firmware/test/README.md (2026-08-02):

# Host tests — running the firmware without the firmware

**Illicit Apothecary — QuadPreRecorder Rev A**

You asked whether the *firmware* could be simulated, not just the ambisonic
maths. Partly, yes — and the part that can be is the part where bugs hide.

```
cd test/host
python3 run_tests.py
```

One command, no `make` required — it finds your C++ compiler (g++, clang++ or
MSVC's `cl`), builds, and runs everything. Works on Windows, macOS and Linux.

That compiles the **real firmware source files** — `qpr_dsp.cpp`,
`qpr_recorder.cpp`, `qpr_coeffs.cpp`, unmodified — for your desktop, against a
small shim that stands in for the Arduino and SdFat headers. Then it runs
them and checks what they actually do.

Nothing in `shim/` reimplements firmware logic. If a test passes, it passed
against the same code the Teensy executes.

---

## What it proves

### 1. The monitor DSP is the same filter you tuned by ear

`compare_firmware_to_model.py` builds a three-second four-channel test signal,
quantises it to 24 bits exactly as the ADC would, and pushes it through both:

- `build/test_dsp`, which links the real `MonitorDsp`
- `sim/simulate_binaural.py`'s model

then compares them sample for sample. Two cases: linear, and driven 12 dB into
the limiter so its state machine gets exercised.

```
worst difference   4.502e-07
correlation (L)    1.000000000
PASS
```

This is the test that makes `sim/simulate_binaural.py` meaningful. Without it,
"the desktop simulator runs the same maths" is a claim. With it, it is a
measurement.

It has already earned its keep: it caught the limiter's release coefficient
losing precision. `1.0f - expf(-1/(0.12*48000))` cancels away most of its
significant digits in float32, putting the release time constant out by
1.6e-4. Now computed with `expm1f`, which is 10× more accurate. Inaudible at
120 ms — but the error grows with the release time, and there was no reason to
be wrong.

### 2. The recorder survives a microSD stall without silently ruining the take

`test_recorder.cpp` drives the real `Recorder` the way `main.cpp` does —
`pushFrames()` from the "capture interrupt", `service()` from the "main loop" —
with the capture side clocked by a **virtual clock**, not by loop iterations.
That distinction is the whole test: when a write blocks for 400 ms, the ADC
does not wait, and 300 blocks of audio become due the instant the write
returns.

Every sample carries its own frame number and channel tag, so a desynchronised
channel is proven, not guessed at.

| Case | Result |
|---|---|
| healthy card | 384000 frames in, 384000 out, buffer peak 33% |
| 100 ms stall | absorbed, buffer peak 78%, nothing lost |
| 400 ms stall | 52480 frames lost = 273 ms, which is exactly 400 − 128 |

The 400 ms case is the important one. It checks that the loss is
**collective**: all four files the same length, same gaps, sample-aligned end
to end. A per-channel drop would leave four individually-valid files that are
time-shifted against each other — which decodes to a smeared, rotated sound
field and is completely inaudible as a fault. That is the bug two independent
reviewers flagged, and this test is what keeps it fixed.

It also caught a second, smaller one: `lastTakeOnCard()` was stale after
`stop()`, so the display offered an already-used take number as "next".

### 3. The WAV files are real files

The suite runs `ffprobe` over everything the recorder wrote. All of it comes
back `pcm_s24le, 192000 Hz, mono`, with the overrun take correctly 1.727 s
instead of 2.000 s on all four channels.

---

## What it cannot prove

Everything electrical, which is most of the risk:

- SAI register configuration, MCLK/BCLK/LRCLK generation
- eDMA descriptors, the FIFO-combined two-data-line capture
- I2C to the PCM1864, and whether GPIO0 really becomes DOUT2
- Real interrupt preemption and real timing
- The display, the touch controller, the analog path

A cycle-accurate i.MX RT model would cover some of that and still tell you
nothing about a cold solder joint on R69. The bring-up tests in `bringup/` are
the answer to those, on the board. See [docs/BRINGUP.md](../docs/BRINGUP.md).

---

## Layout

```
test/host/
  run_tests.py                  build + run everything, one command
  shim/Arduino.h                virtual clock, memory attributes, Serial
  shim/SdFat.h, .cpp            stdio-backed SD with injectable write stalls
  test_dsp.cpp                  runs the real MonitorDsp on a raw file
  test_recorder.cpp             runs the real Recorder against stalls
  compare_firmware_to_model.py  firmware vs Python, sample for sample
```

Needs a C++ compiler and `python3` with `numpy`. `ffmpeg` is optional and only
used for the last check.

**Getting a compiler on Windows:** the simplest route is MSYS2 —
install it, then `pacman -S mingw-w64-x86_64-gcc`, and run `run_tests.py` from
the MinGW64 shell. Alternatively install "Build Tools for Visual Studio" and
run from a Developer Command Prompt; `run_tests.py` detects `cl` and uses it.

## Adding a case

The stall injector is the useful knob:

```cpp
hostsd::setWriteCost(300);              // a healthy card, microseconds
hostsd::injectStall(93, 400000);        // write #93 takes 400 ms
```

`checkTake()` already asserts alignment, accounting and equal length, so a new
scenario is usually three lines.

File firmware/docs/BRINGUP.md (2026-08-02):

# Bring-up runbook

**Illicit Apothecary — QuadPreRecorder Rev A**

This is the order to do things in the first time you power a board. Each step
proves one thing. Do not skip ahead: the whole point is that when something is
wrong, you find out while only one subsystem is in play.

Budget an evening. Most of it is step 4 running unattended.

---

## Before power

Do these with a multimeter, board unpowered and unpopulated of the Teensy if
you can:

- [ ] Continuity from the barrel jack ring to GND, tip to F1.
- [ ] No short between +9V and GND, +5V and GND, +3V3_D and GND, +3V3_A and GND.
- [ ] The Teensy socket is not fitted backwards.
- [ ] **Cut the VIN–VUSB pad on the underside of the Teensy 4.1** if you will
      ever have the barrel jack and USB connected at the same time. D3 stops
      USB back-feeding the board, but it does not stop ~4.6 V from the board
      reaching the USB VBUS pin and thence your computer.

Then apply 9 V with **no Teensy fitted** and check the rails at the regulators:
+5 V from the TPS62160, +3V3_A from the TPS7A20. If either is wrong, stop here.

---

## Step 1 — `t01_power`

**Proves:** the Teensy boots, USB serial works, the record LED works, and every
control input idles where the schematic says it should.

```
pio run -e t01_power -t upload
pio device monitor
```

The red RECORD LED blinks once a second. Serial prints a report every two
seconds; every line should say `ok`.

Then press the record button and turn the encoder while watching. The report
should change.

**If nothing appears on serial at all**, the Teensy is not running. Work back:
9 V present → F1 → D1/D2 → TPS62160 +5 V → D3 → Teensy VIN.

**If a control input reads LOW when it should be HIGH**, that input is shorted
to ground or its 10 kΩ pull-up is missing (R50 record, R51/R52 encoder A/B,
R53 encoder push).

**If HP_ENABLE or DAC_MUTE report HIGH**, stop. Something is driving them and
the outputs are not silent at power-up. Do not put on headphones.

---

## Step 2 — `t02_i2c`

**Proves:** the I2C bus, and that the PCM1864 is alive and configurable —
including the one register write (`GPIO0_FUNC = DOUT2`) that the entire
192 kHz four-channel scheme depends on.

You should see `0x4A` (the ADC) and, if the display is plugged in, `0x38`
(touch). Then a list of register tests, all `ok`.

**The clock status at the end will report errors. That is correct.** Nothing
is generating audio clocks yet; the part sits in its clock-waiting state until
step 6.

**If nothing is found**, check R44/R45 (4.7 kΩ pull-ups to +3V3_D) and that
3.3 V is actually at U7 pins 13 and 14.

**If `0x4A` is missing but `0x38` is present**, the ADC has a power or solder
problem. Check AVDD (pin 8), DVDD (13), IOVDD (14), and that pins 25 (MS/AD)
and 26 (MD0) are both grounded — those two are what put the part in I2C mode
at address 0x4A.

**If readbacks mismatch**, the bus is marginal. Drop `Wire.setClock` to 100000
in the test and try again; if that fixes it, look at bus capacitance.

---

## Step 3 — `t03_controls`

**Proves:** the switches and the encoder, including direction.

Follow the prompts. The test prints PASS for each control once you have
exercised it enough.

**The one to watch:** turning the encoder *clockwise* must report `+1`. If it
reports `-1`, A and B are swapped — either swap the wires or swap `GAIN_A` and
`GAIN_B` in `lib/qpr_board/qpr_board.h`.

**One physical detent must produce exactly one count.** If you get four counts
per detent, the encoder is not a 4-edge-per-detent type; change the divisor in
`Controls::poll()`.

---

## Step 4 — `t04_sdbench`

**This is the most important test in the set. Do not shorten it.**

Everything else on this board either works or obviously does not. A marginal
microSD card fails silently, mid-take, months from now.

Put in the card you actually intend to record on. Flash. Let it run for
**longer than your longest intended recording**. Ten minutes tells you almost
nothing. An hour tells you something. If you plan to record onto a half-full
card, test on a half-full card — they get slower as they fill.

The test writes four files at exactly the rate the recorder does, and reports:

- **sustained MB/s** — must exceed 2.304 MB/s with margin. Necessary, not
  sufficient.
- **worst single write** — this is the number that matters. The firmware has
  128 ms of buffer per channel. A card that averages 20 MB/s but pauses for
  300 ms doing internal garbage collection will drop samples.

| Verdict | What to do |
|---|---|
| PASS | Good. Note the worst-case figure so you can spot it degrading later. |
| MARGINAL | It fits, but a long take is a gamble. Get a better card, or raise `kRingChunksPerChannel` in `qpr_config.h` and rebuild — RAM2 has about 145 KiB spare, enough for one more chunk per channel. |
| FAIL | Do not record on this card. |

Press `q` to stop; it deletes its temporary files.

Cards that generally do well at this: the "high endurance" and V30/A2 dashcam
and surveillance grades. Cards that generally do badly: anything bundled free
with something else, and anything whose sustained-write figure the maker does
not publish.

---

## Step 5 — `t05_display`

**Proves:** the ILI9341 panel, its orientation, and the FT6336G touch
controller.

Three stages: colour bars, five touch targets, then free-draw.

**A note on Teensy pin 5.** It is `TOUCH_RST`, not a chip select. Some older
notes in this project called it "TOUCH_CS", left over from an earlier resistive
XPT2046 design. The Rev A part is an FT6336G, which is I2C with reset and
interrupt lines and no chip select. Firmware that drives pin 5 as a chip select
holds the controller in reset and it never answers.

**If the backlight is on but the screen is black**, check J3 pins 3/5/6/7/9 and
the reset on Teensy pin 7.

**If the backlight is off entirely**, check R56 (100 Ω from +5V to J3 pin 8).
The backlight is hardwired on; there is no software dimming.

**If touch never answers**, confirm the module you bought actually has
capacitive touch. Some MSP2834 revisions ship with resistive XPT2046 touch,
which will never appear at I2C address 0x38. The recorder works fine without
it — the button and encoder do everything.

**If the touch axes are swapped or mirrored**, fix the rotation mapping in
`TouchFt6336::read()`.

---

## Step 6 — `t06_audio`

**Proves:** the whole audio chain.

Plug the microphone in. Leave the headphone volume pot down and headphones off
your ears to start — this test can make sound, but only when you ask it to.

### 6a. Does the ADC lock?

On boot the test starts the clocks and waits for the PCM1864 to reach its RUN
state. It should say `ADC is RUNNING`, and the clock report should read:

```
generated MCLK   24576000 Hz  (128 x fs)
generated BCLK   12288000 Hz  (64 x fs)
generated LRCLK    192000 Hz
ADC sees SCK     128 fs
ADC sees BCK     64 fs
ADC state        RUN
```

If the ADC does not reach RUN, the Teensy is generating clocks the ADC is not
receiving. Check R46 (MCLK), R48 (BCLK), R47 (LRCLK) — all 33 Ω — and the SCKI
trace to U7 pin 15. The "ADC sees" lines tell you which clock is missing.

### 6b. Which capsule is which?

This is the step people skip and regret.

Scratch each capsule in turn with a fingertip and watch which of the four
meters moves. Write it down. You are confirming that:

```
FLU  front-left-up      PCM1864 VINL1  ADC1 L  DOUT  left slot   Teensy pin 8
FRD  front-right-down   PCM1864 VINR1  ADC1 R  DOUT  right slot  Teensy pin 8
BLD  back-left-down     PCM1864 VINL2  ADC2 L  DOUT2 left slot   Teensy pin 6
BRU  back-right-up      PCM1864 VINR2  ADC2 R  DOUT2 right slot  Teensy pin 6
```

If BLD and BRU show nothing at all while FLU and FRD work, DOUT2 is not
arriving: check R69 (33 Ω) and the trace from U7 pin 22 to Teensy pin 6. That
is the single most likely failure on this board, because DOUT2 is the one
signal doing something unusual.

**If the mapping is wrong, do not fix it by rewiring the microphone.** Fix it
by reordering the capsule directions in `sim/qpr_ambisonics.py`
(`CAPSULE_DIRECTIONS`), regenerating the coefficients, and rebuilding. Then the
recorded files still carry honest capsule identities and the decode follows.

### 6c. Does anything come out?

Press `t` for a 440 Hz test tone. It goes to the line output immediately.
Then press `h` to enable the headphone amplifier and bring the volume pot up
slowly.

Press `l` for a live monitor — the raw omni sum of all four capsules straight
to the DAC, **no binaural processing**. This is a diagnostic, not what the
product does: the real firmware always sends the full binaural render. All you
are proving here is that the analogue → digital → analogue chain passes audio.

Both the line jack and the headphone jack should carry whatever you play. They
come from the same DAC and split after R62/R63, so if one works and the other
does not, the fault is in the branch, not in the firmware: check RV1, C57/C58
and the TPA6132A2 for a dead headphone side, or J4 and C67/C68 for a dead line
side.

---

## Step 7 — the real firmware

```
pio run -e app -t upload
```

Watch the boot output. It tells you what it found and what it could not.

First take: record thirty seconds of something with obvious direction — walk
around the microphone talking. Then check on a computer:

- Four files, `FLU001.WAV` through `BRU001.WAV`, all exactly the same length.
- All four open as 192 kHz, 24-bit, mono.
- The channel with the most energy changes as you walked around.

Then render them through the simulator and listen:

```
cd sim
python3 simulate_binaural.py --input FLU001.WAV FRD001.WAV BLD001.WAV BRU001.WAV --out take001.wav
```

If the binaural render puts you back in the room, the whole system works. If
the directions are rotated or mirrored, the capsule mapping from step 6b is
wrong — go fix `CAPSULE_DIRECTIONS`, not the microphone.

Then read [CALIBRATION.md](CALIBRATION.md) for how to make it sound right
rather than merely correct.

---

## When something goes wrong later

The firmware reports its own health. Press `s` on the serial console:

| Reading | Meaning |
|---|---|
| `buffers: peak N%` | How full the SD rings got. Under 50% is comfortable. Sustained above 80% means the card is marginal. |
| `longest write` | The worst SD stall this session. Compare against the 128 ms budget. |
| `overruns` non-zero | Samples were lost. **All four files share the same gaps** — the writer drops a block from all four channels or none, so the take stays sample-aligned. The status line reports how many milliseconds went missing. |
| `starved` climbing | The DSP is not being fed. Usually means the capture stream stopped. |
| `DSP hit its CPU budget` | The monitor is over-configured. Lower `cfg::kHrtfTaps` and regenerate coefficients. |
| `capture ISR max` | Should be well under the 1333 µs block period. |
| `outputs` | Reminds you which control moves what, and prints the real line-jack voltage for 0 dBFS. |

Press `o` for a 1 kHz reference tone at a known level, to set gain staging on
whatever the line output feeds. It is on the headphones too — turn RV1 down.

The record LED blinks fast during a take if an overrun has occurred.

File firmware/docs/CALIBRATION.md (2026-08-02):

# Calibration

**Illicit Apothecary — QuadPreRecorder Rev A**

Getting the recorder *correct* is bring-up. Getting it to *sound right* is
this. Everything here is a number you can change without touching the PCB,
because the recorded files are raw capsule signals and every decode decision
happens downstream.

Work in the simulator. It runs the identical maths in half a second instead of
a reflash.

---

## The one command

```
cd sim
python3 build_hrtf.py --taps 128 --radius 0.015
pio run -e app -t upload
```

`build_hrtf.py` writes `lib/qpr_dsp/qpr_coeffs.h` and `.cpp`. The firmware
compiles them in. It also runs the maths self-test first and refuses to
generate anything if that fails.

To hear a change before flashing it, pass the same options to the simulator:

```
python3 simulate_binaural.py --radius 0.021 --scene orbit --out test.wav
```

---

## 1. Capsule geometry — do this first

Everything else is fine tuning; this one is either right or the image is
wrong.

### Which capsule is which

Confirmed in bring-up step 6b: scratch each capsule and see which meter moves.
The firmware's fixed order is `FLU, FRD, BLD, BRU`, and that order is welded to
the PCM1864 input wiring. If your physical microphone does not match, **do not
rewire it** — change the direction vectors in `sim/qpr_ambisonics.py`:

```python
CAPSULE_DIRECTIONS = np.array([
    [+_S, +_S, +_S],  # FLU  front left  up
    [+_S, -_S, -_S],  # FRD  front right down
    [-_S, +_S, -_S],  # BLD  back  left  down
    [-_S, -_S, +_S],  # BRU  back  right up
])
```

Coordinates: **x forward, y left, z up**. Azimuth counter-clockwise from front,
so +90° is the listener's left.

The A-to-B matrix is *derived* from this array, not hard-coded, so changing it
propagates correctly. Rerun `python3 qpr_ambisonics.py` — the self-test
verifies the round trip.

### Capsule radius

```
--radius 0.015          # metres, default 15 mm
```

Measure from the array centre to a capsule diaphragm. This sets the transition
frequency of the A-format correction, `f_t = c / (2πr)` — about 3.6 kHz at
15 mm. Getting it wrong tilts the whole balance between the omni component and
the directional components, which sounds like the image being either
claustrophobically narrow (radius too small) or vague and boomy (too large).

It is the single number that most affects how the monitor sounds. Measure it
properly.

---

## 2. A-format correction

A tetrahedral array cannot resolve a pressure gradient at low frequency,
because the capsules are too close together relative to the wavelength. The
X/Y/Z components are therefore under-represented below `f_t`, and the textbook
correction is a +6 dB/octave boost — which, left unbounded, is +∞ at DC.

Two parameters bound it, in `a_format_correction()`:

```python
lf_shelf_hz  = 80.0     # below this the boost stops rising
max_boost_db = 18.0     # and it never exceeds this
```

Raise `lf_shelf_hz` if the monitor rumbles. Lower `max_boost_db` if wind or
handling noise dominates. To hear what the correction is doing at all, render
with and without:

```
python3 simulate_binaural.py --scene corners --out with.wav
python3 simulate_binaural.py --scene corners --no-correction --out without.wav
```

**This is a model, not a measurement.** Real capsules have their own response,
the enclosure diffracts, and no array is perfectly symmetric. If you can get
the microphone in front of a measurement rig, replace this function's output
with the measured correction and everything downstream follows.

---

## 3. Gain

The chain is: capsule → OPA1654 fixed +20.1 dB → optional −9.7 dB pad →
PCM1864 PGA, −12 dB to +32 dB in 0.5 dB steps.

| Pad | Total range |
|---|---|
| out | +8.1 dB to +52.1 dB |
| in | −1.6 dB to +42.4 dB |

All four PGAs are moved by a single register write using the PCM1864's `LINK`
bit, so the four channels change together on one internal ramp. Four separate
writes would start their ramps microseconds apart, and channel-to-channel gain
mismatch is exactly what destroys an ambisonic array.

Automatic clipping suppression (`AGC_EN`) is **off and must stay off** — it
would act per channel and break the matching.

Aim for peaks around −12 dBFS on the loudest capsule. 24 bits gives you room;
clipping gives you nothing back.

To go above +32 dB, raise `kPgaMaxDb` in `qpr_config.h`. The part goes to
+40 dB but makes up the last 8 dB digitally, which costs noise floor. It is
there if you need it.

---

## 4. The HRTF

### The built-in one

An analytic spherical-head model: Woodworth ITD, Brown & Duda head shadow, a
pinna reflection whose delay tracks elevation and frontness, a pinna
high-frequency shelf that dims sources from behind, and a torso reflection at
about 1 ms.

Measured behaviour of the default set, through the full chain:

| Source | ILD | ITD | 5–15 kHz level |
|---|---|---|---|
| front | 0.0 dB | 0 µs | reference |
| hard left | +7.4 dB | −354 µs | −0.7 dB |
| hard right | −7.4 dB | +354 µs | −0.7 dB |
| behind | 0.0 dB | 0 µs | −1.4 dB |
| above | 0.0 dB | 0 µs | −1.2 dB |

Left/right is strong and unambiguous. Front/back and up/down are weak — 1–1.4 dB
of high-frequency shading and nothing else. That is honest: first-order
ambisonics plus a generic head has very little to work with there, and front/back
confusion in FOA binaural is a real, well-known limitation rather than a bug.

The 354 µs ITD is smaller than a real hard-left ITD (~650 µs) because the
max-rE decoder deliberately trades localisation sharpness for image stability.
Pass `--basic` if you want the sharper, less stable version.

### Using a measured set

```
pip install sofar
python3 build_hrtf.py --sofa MIT_KEMAR.sofa --taps 128 --bin HRTF.BIN
```

Copy `HRTF.BIN` to the root of the microSD card. The firmware loads it at boot
and says so; the display footer shows `hrtf meas` instead of `hrtf model`.

The file is validated against the firmware's tap count and monitor rate and
rejected with an explanation rather than loaded blind. If it says the tap count
is wrong, regenerate with `--taps` matching `cfg::kHrtfTaps`.

An individually-measured set will beat any model. A generic measured set
(KEMAR and similar) beats the analytic model mostly in externalisation and
elevation.

### Filter length

`--taps 128` is the default and costs about 25% of one core. 256 taps sounds
better with measured data and roughly doubles that. Check the real figure on
hardware — press `s` on the serial console and read `DSP N% CPU` — before
raising it. If the firmware reports `DSP hit its CPU budget`, it is too high;
the DSP will yield and glitch the monitor rather than starve the SD writer.

To change it, regenerate the coefficients *and* update `cfg::kHrtfTaps`; a
static assert catches the mismatch at compile time.

---

## 5. Decoder

```
--basic         plain projection decoder
(default)       max-rE weighting, g1 = 0.775
```

max-rE trades a little localisation sharpness for a much more stable image,
which is the right default for headphone monitoring. Basic is sharper and
more fragile. Try both on `--scene orbit`.

---

## 6. Line output level

Both jacks carry the same binaural render — the signal splits after R62/R63,
one copy to the 1/4 inch jack and one through the RV1 knob into the headphone
amplifier. So setting the line level is about matching whatever you plug into,
not about choosing what the line output "is".

Press `o` on the serial console. You get 1 kHz at −20 dBFS, which bypasses the
output trim and the limiter so the level at the jack is exact:

```
REFERENCE TONE ON: 1000 Hz at -20 dBFS
  at the 1/4in line jack (J4): 0.192 Vrms  =  -12.1 dBu
  for reference, 0 dBFS would be 1.92 Vrms = +7.9 dBu
```

Set the receiving device so its meters read −20 dBFS on that tone. Then digital
full scale here lines up with digital full scale there, and the limiter ceiling
at −1 dBFS gives you a hard, known maximum.

**Turn RV1 down first.** The tone is on the headphones too.

If the receiving device's input is too hot even at the bottom of its range,
lower `kOutputTrimDb` in `qpr_config.h` (or press `[` a few times). That trim
is digital and upstream of the DAC, so it moves the headphones with it — which
is fine, you have a knob for those.

### If you are driving something low-impedance

The table in [ARCHITECTURE.md](ARCHITECTURE.md#levels) has the numbers. Short
version: a 10 kΩ or higher input costs you 0.8 dB, a 600 Ω input costs 5.3 dB,
and the 600 Ω case takes the headphones down with it because the split is
before the volume pot. If that matters for your use, the fix is a buffer on
the line output in Rev B, not firmware.

## 7. Monitor limiter

In `qpr_config.h`:

```cpp
kLimiterThresholdDbfs = -1.0f;
kLimiterAttackMs      =  1.0f;
kLimiterReleaseMs     = 120.0f;
```

One gain envelope is applied to both ears together, so limiting can never move
the stereo image sideways. This affects the monitor only — the recorded files
never see it.

---

## Checking your work

The maths self-test runs automatically inside `build_hrtf.py`, but you can run
it alone:

```
cd sim && python3 qpr_ambisonics.py
```

It verifies that the capsule directions are a valid tetrahedron, that the
A-to-B matrix recovers the correct SN3D encoding from every test direction,
that the virtual speaker layout is a spherical 2-design, that encode-then-
decode preserves both pressure and velocity, that the HRIR has the right ear
leading for a right-hand source, and that the decimator's stopband is deep
enough where aliasing would be audible.

For a visual check:

```
python3 simulate_binaural.py --report plots.png
```

(needs matplotlib) — impulse responses and magnitude curves for all eight
binaural filters and the decimator, with the fold-back frequency marked.

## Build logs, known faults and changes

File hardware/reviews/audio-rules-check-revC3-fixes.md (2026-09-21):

# Rev C3: the audio-rule fix pass

Date: 2026-09-12
Board: `hardware/QuadPreRecorder.kicad_pcb` (Rev C3, routed, DRC 0 / 0 unconnected / 0 parity, ERC 0)
Backup of this exact board: `hardware/QuadPreRecorder.kicad_pcb.revc3-routed-clean-20260912`
Follows: `audio-rules-check-revC2.md` (the audit that found all of this)
Audit re-run outputs: `review_outputs/audio_audit_c3.txt`, `audio_audit2_c3.txt`, `audio_audit3_c3.txt`

## What was asked

Remove J6 and J7, fix every FAIL from the Rev C2 audit, put the converters'
digital rail on a second TPS7A2033, see whether film coupling caps fit now
that the headers are gone, and catch anything the four checks missed.

## Scorecard

| # | Rev C2 finding | Rev C3 |
|---|---|---|
| 1 | AGND/DGND: pass, but U10's exposed pad had **0** vias | 3x3 array of 0.30 mm vias on a 0.9 mm pitch in the pad; U10.13 tied straight into the pad. **Pass, no defect.** |
| 2 | Clock-to-analog: **366** parallel pairs, ~2100 mm broadside In2/B + ~230 mm same-layer, BRU_PRE 223 mm, analog copper over the whole board | **14** pairs, **0 mm broadside**, 64.6 mm same-layer. Analog copper 1654 mm total and confined to x 2..86 / y 41..108. BRU_PRE 82.7 mm. **Pass** (residual discussed below). |
| 3 | Decouplers 2.4..11.7 mm from their pins, 10 uF closer than 100 nF, no bead/LDO on the converter digital rail | Every 100 nF is 1.34..1.60 mm from its pin with its own via; 10 uF sit behind the 100 nF; DVDD/IOVDD come from U14 (+3V3_DC). **Pass.** |
| 4 | Coupling caps unspecified/X7R | C17-C20, C25-C28: Rubycon PMLCAP 4.7 uF 35 V (1812). C57/C58/C86/C87: PMLCAP 2.2 uF 25 V (1210). **Pass.** |
| + | Stackup: In2.Cu had no reference plane (1.07 mm across the core) and faced B.Cu at 0.21 mm | In2.Cu is a solid GND plane. Stackup is SIG / GND / GND / SIG and is now written into the board file. |

## What changed, in the order it was done

### J6 / J7 are gone
Both 2x13 test headers, their 41 net stubs, R68 (the 1 k PAD_DBG protector),
the schematic note and every doc mention. Nothing replaced them: with the
headers gone every stage node still has an 0603 / 1812 pad on the top side of
the channel rows, and the clocks are reachable at the 33 R terminators. The
generator edits are in `tools/generate_schematic.py` and
`tools/generate_pcb.py`; docs updated: README, AGENTS, `connector-pinout.md`,
`requirements.md`, `mechanical.md`, `enclosure-fit-audit.md`, the PCBWay
order notes and manufacturing README.

### In2.Cu became a plane
`generate_pcb.py::add_ground_planes` now puts the wire-keepout rule area on
In1 **and** In2; `tools/patch_dsn_plane.py` marks both as Specctra
`(type power)`. Freerouting therefore routed on F.Cu and B.Cu only. It
fitted: 8.72 m of track (F 4.67 m, B 4.05 m) against 12.0 m over three
layers in Rev C2, because the two headers were eating 1.9 m of analog
routing plus everything digital that had to follow them to the rear edge.
Every track now has a plane 0.21 mm away and no two signal layers face each
other, which is why the broadside number is exactly zero.

`tools/set_stackup.py` (new, end of pipeline) writes the explicit stackup:
35 um copper, 0.21 mm prepreg / 1.065 mm core / 0.21 mm prepreg, the same
build the fab was silently applying before. PCBWay's standard 1.6 mm
4-layer matches it; no impedance control is needed.

### U14: the converters' own 3.3 V
Second TPS7A2033 (SOT-23-5) off +5V, output net `+3V3_DC`, input C95 1 uF,
output C96 4.7 uF, placed on the bottom directly under U2 so both LDOs share
the +5V feed. It feeds only U7.13/14 (PCM1864 DVDD / IOVDD) and U9.20
(PCM5102A DVDD). `+3V3_D`, the Teensy's own regulator output, now carries
only pull-ups (I2C, buttons, encoder, charger status). C63, the second
+3V3_D 100 nF, was dropped. Cost: about $1.20 for the LDO and $0.10 for the
caps.

### Decoupling under the pins
The audit's target was a 100 nF within 1.5 mm of the pin with its own via.
On a 0.5 / 0.65 mm pitch TSSOP a 0.6 mm via cannot sit in the pin row (the
annulus would violate clearance to the neighbouring pins), so the legal
spot is just inside the IC body past the pad's inner end. The caps now sit
on the **bottom** with their pad 1 exactly under that spot:

```
U7  PCM1864   vias at x=82.0   C40 VREF 100n (47.7)  C41 AVDD 100n (49.3)
                                C43 LDO 100n (50.9)   C44 DVDD 100n (52.5)
              bulk column x=87.1: C42 AVDD 10u, C62 LDO 10u, C45 DVDD 10u
              C39 VREF 1u (83.0,45.9)  C38 MICBIAS 1u (80.2,46.5)
U9  PCM5102A  vias at x=98.5 (pins 1/8 AVDD -> C54, C64, caps point west)
              vias at x=101.5 (pin 20 DVDD -> C56, pin 18 LDOO -> C53 1u 0603)
              C55 AVDD 10u bulk south of the IC (99.9,55.0)
              C51 / C52 charge-pump 2.2u moved from 6 mm away to (94.7, 48.4 / 51.9)
U10 TPA6130A2 C59 flying cap straight above pins 17/18 (112.75,52.2)
              C61 CPVDD (110.3,51.75)  C60 CPVSS (116.25,54.6)  C65 VDD (116.25,56.2)
```

`tools/fanout_decouple.py` (new, runs before `fanout_gnd.py`) places those
vias and their 0.6 mm stubs on the pristine board so Freerouting inherits
them as protected wiring; it also lays the U10 exposed-pad array, the U10.13
ground stub, the U10.12 -> C65 track that Freerouting has never managed on
its own, and the U11.4 / U11.5 escape vias (see "the two stragglers").
Measured pin-to-cap-pad distances now:

```
U7.8  AVDD  1.40   U7.13/14 DVDD 1.47/1.39   U7.11 LDO 1.39   U7.6 VREF 1.60
U9.1  AVDD  1.34   U9.8 AVDD 1.34   U9.20 DVDD 1.34   U9.18 LDOO 1.34
U10.12 VDD 1.54    U10.20 CPVDD 1.67   U10.15 CPVSS 1.56   U10.18 CPP 1.84
U9.2 CAPP 2.45 / U9.5 VNEG 2.75  (were 6 mm)      U14 in/out 5.3 / 3.3 (LDO caps, fine)
```

The audit missed two of these: the PCM1864 **VREF** cap pair (C39/C40) and
its MICBIAS cap were 25 mm away on the far side of the Teensy socket, and
the PCM5102A charge-pump caps were 6 mm out. All fixed in the same move.

### Film coupling caps: they fit without moving anything
The blocker in Rev C2 was the 4 mm column pitch of the channel rows, not
the headers. Rubycon's PMLCAP (metallised acrylic film, the SMD film part
made for exactly this job) comes in 1812 at 4.7 uF: 4.5 x 3.2 x 1.6 mm,
which is 4.0 mm wide in the rotated orientation the rows already use.
So C17-C20 and C25-C28 changed footprint in place. The 1812 courtyard is
6.1 mm tall rotated, so the row pitch went from 6.0 to 6.3 mm (rows at y
85.5 / 91.8 / 98.1 / 104.4); nothing else moved and no wall part is
affected. The headphone caps went to 1210 (2.2 uF) and moved from 16 mm
past U10 in the right-wall strip to between the DAC filter and U10's input
pins (x 100.4 / 105.2, y 55.7 / 59.1); the filter (R62/R63/C67/C68) slid
2 mm west to make room.

Parts and prices (LCSC, in stock 2026-09-12):

| Ref | Part | Size | LCSC | Price | Stock |
|---|---|---|---|---|---|
| C17-C20, C25-C28 | Rubycon 35MU475KC44532, 4.7 uF 35 V PMLCAP | 1812 | C3778321 | ~$1.05 | 8269 |
| C57, C58, C86, C87 | Rubycon 25MU225MB23225, 2.2 uF 25 V PMLCAP | 1210 (3225) | C3778570 | ~$0.75 | 429 |

DigiKey and Mouser carry only the 16 V siblings (16MU475MC14532,
16MU225MB23225) at $7-11 each in ones, so the alternates are listed in the
BOM but the order should come from LCSC or PCBWay's own sourcing. Total
for the twelve: about $11.40. PPS (Panasonic ECH-U) tops out at 0.1 uF and
does not exist at these values in any SMD size; PMLCAP is the film option
that actually exists.

C86/C87 were kept as matched film rather than downgraded to X7R: TI wants
INP and INM balanced, and a DC-biased X7R next to a film part would not be.

## Check 2 residual, and why it is acceptable

The fourteen remaining parallel pairs are all same-layer, and the list is
now made of low-impedance nodes:

```
par_mm  gap_mm  aggressor    victim
11.3    0.171   ADC_BCLK     BRU_ADC
 9.5    0.899   ADC_BCLK     HP_INP_L
 6.1    0.522   ADC_BCLK     FLU_ADC
 5.6    0.241   DAC_BCLK     BRU_ADC
```

The `_ADC` nodes are the PCM1864 inputs behind the anti-alias network with
a 10 nF C0G to ground (C29-C32), which is about 1.3 ohms at 12 MHz; a few
picofarads of edge coupling into that is nothing. `HP_INP_L` is the
headphone amp's AC-grounded reference input through 2.2 uF. The
high-impedance nodes the audit was worried about (`_AC` at ~64 k, `_RAW`
behind the electret bias) do not appear in the list at all any more. The
ADC_LRCLK run under U7's input pads is on B.Cu with two solid planes above
it, so it is shielded in fact rather than in name.

## The two stragglers (and what a future rebuild has to know)

Freerouting left three items unrouted on the first two-layer pass and could
not finish them in a locked finishing pass either:

* **U10.12 (VDD)**: it had wrapped HP_OUT_L around the front of the pin.
  Fixed by hand: HP_OUT_L now runs through the 0.65 mm gap between C60's
  and C65's pads, the +5V feed that threaded through C60 was cut and
  re-joined to the B.Cu +5V through a via at (117.0, 53.64), and pin 12
  gets a 1.5 mm stub to C65. `fanout_decouple.py` now pre-places that stub.
* **U11.4 (BOOST_EN) and U11.5 (BOOST_SS)**: with In2 gone, the TPS61175's
  two control pins were fenced in on F.Cu by VBOOST_IN and on B.Cu by the
  CHASSIS run that walls off the whole left strip. C79 (the soft-start
  cap) moved to the bottom right under pin 5, which makes BOOST_SS a 5 mm
  net. BOOST_EN got escape vias, a run down the left edge on B.Cu at
  x=1.6, and two via hops over CHASSIS and +9V at y 62.5 / 63.0. All of it
  was placed by `tools/poly_route.py` with every segment and via checked
  against the geometry rules first, then confirmed by DRC.

If the board is ever regenerated and re-routed from scratch, expect the
same three to come back. `fanout_decouple.py` pre-places the U10.12 stub
and the U11 escape vias, and `tools/route_c3_stragglers.ps1` / `poly_route.py`
hold the hand routes; `rev_c3_status` in project memory has the sequence.

## Pipeline changes

```
generate_pcb -> preflight_pads -> fanout_decouple (NEW) -> fanout_gnd --allow-existing
-> protect_fanout -> patch_dsn_plane (In1+In2) -> freerouting -> import -> cleanup
-> fix_jumper_pads -> stitching -> finishing pass -> set_stackup (NEW) -> gnd_cluster_check -> DRC
```

Freerouting took 19 minutes on two layers (was ~4 on three). The locked
finishing pass hangs when a pin is physically fenced in, so kill it after
15 minutes and use the straggler tools instead.

## Still open / not done here

* U14's caps are 3.3 / 5.3 mm from the LDO. TPS7A20 is stable with that;
  tightening it is cosmetic.
* Series terminators (R46-R49/R69 for the ADC clocks, R57-R59 for the DAC)
  sit mid-run, not at the drivers. The clocks are 44-73 mm now; leave it
  unless the bench shows ringing.
* BRU_PRE / FRD_PRE are still ~80 mm because the preamp (U6, x=52) and the
  channel rows (y 85-104) are where they are. It is an op-amp output, so
  low impedance; not a crosstalk victim.
* No test points were added. If you want a probe hook on the clocks, a
  1.5 mm pad next to R46-R49 costs nothing; say so and it goes in the
  generator.
* The 3D fit viewer still predates Rev C2; no wall part moved in Rev C3.

## Addendum: the test-point rebuild (later on 2026-09-12)

Twelve 1.5 mm probe pads were added on the bottom (TP3-TP14: five ADC
clock/data lines, three DAC lines, +3V3_DC, three grounds; table in
`../connector-pinout.md`), which forced a full regenerate-and-reroute. Three
placement changes rode along:

* **U11 (TPS61175) rotated 180 deg.** At rot 0 the switch node had to wrap
  around the IC's north and east sides to reach L2, fencing pins 8-10
  (COMP/FB/FREQ) into a 0.86 mm corridor and pins 4/5 against the board edge.
  Freerouting could not finish BOOST_FB. Now SW/VBOOST_IN/EN/SS face L2 and
  the board; the left-edge BOOST_EN hand route and the escape vias are gone.
  C79 (soft start) sits on the bottom under L2, 2 mm from pin 5.
* **U13 (BQ24074) pins 6 and 8** (GND, either side of PGOOD_N) are tied into
  the exposed pad by stubs instead of getting their own fanout vias, which
  had boxed pin 7 in.
* **C38 deleted, U7.5 (MICBIAS) left open.** The capsules are biased from
  +9V_MIC, TI's PCM186x datasheet (9.3.2.1) says the pin can be left
  unconnected if unused, and on a 0.5 mm pitch between pins 4 and 6 it was
  unroutable. Firmware should power the bias down (page 3, reg 0x15, PDZ=0).

Result: ERC 0, DRC 0 / 0 unconnected / 0 parity, GND 174 pads in one
cluster, 8.83 m of track on two layers, 496 vias, fab package rebuilt (235
placements). Check 3 unchanged (all decouplers 1.34-1.60 mm). Check 2: still
zero broadside, but this route drew 22 same-layer pairs / 165 mm against
14 / 65 mm on the earlier board, the worst being ADC_DOUT2 beside BRU_ADC for
26 mm at 0.152 mm. Every victim is again an `_ADC` node (10 nF C0G to ground,
about 1.3 ohms at 12 MHz) or LINE_L (DAC output); 1.5 pF into 1.3 ohms is
about 0.5 mV of 12.288 MHz, which the modulator samples as DC. The number
moves from route to route because BRU_ADC and the clocks must both thread the
Teensy socket gaps to reach U7. If it matters later, a re-route is a coin
flip on this metric; a placement change (U7 rotated so its inputs face U6)
is the deterministic fix and is out of scope here.

## Addendum 2: mic modes and balanced inputs (later still on 2026-09-12)

Jason asked for the mic bias to be selectable from the touchscreen (off,
5 V or 9 V, one setting for all four channels) and, when it is off, for the
RJ45 pairs to behave as balanced inputs for dynamic microphones. Both went
into the same regenerate-and-route.

### Global bias switch

Q6 (AO3401A, +9V) and Q8 (AO3401A, +5V) are high-side switches into the
existing R67 / C66 bias filter, each driven by a 2N7002 level shifter (Q7,
Q9; 100R gate series, 100k pull-down) from Teensy pins 1 (MIC9_CTRL) and 0
(MIC5_CTRL). Both FETs are off until the firmware says otherwise. D24
(BAT54) sits between the 5 V leg and the filter so the 9 V setting can never
back-feed the +5V rail; the 5 V setting therefore delivers about 4.7 V,
which every electret capsule in the BOM is happy with. R104 (100k) bleeds
C66 down in about a second when the bias is switched off.

### Cold legs and the differential stage

J2 pins 2 / 6 / 5 / 8 were GND; they are now FLU/FRD/BLD/BRU_RAWC and carry
the same 100R / 100 pF C0G / PESD12VL1BA treatment as the hot legs (R110-113,
C97-100, D20-23). After the RF filter each cold leg (MICC) reaches a CD4053
section whose select pin is COLD_SEL: U4 and U5 had a spare C section each
(pins 3/4/9; pin 9 was grounded), U15 is a new CD4053 for the other two.
COLD_SEL is pulled to +9V by R106 (10k) so the power-up state is "cold leg
grounded" = electret mode; Q5 (2N7002, R107 100R, R108 100k) pulls it low
from Teensy pin 41 (COLD_CTRL) to release the cold legs.

The released cold leg goes through a 4u7 PMLCAP (C101-104) and 1M to VREF
(R114-117) into a new OPA1654 (U16, C109 100n), one unit per channel,
configured as the first amplifier of a two-op-amp instrumentation stage:
Ra = 10k 0.1 % (R118-121, CFB to CPRE), Rb = 90.9k 0.1 % (R122-125, CFB to
VREF), 22 pF across (C105-108). The second amplifier is the existing U6 unit;
its 10k (R26-29) now returns to the cold amplifier's output instead of VREF.
Net result Vout = (1 + 90.9k/10k) x (hot - cold), the same +20.1 dB the
single-ended stage had, so nothing downstream changes.

Numbers (hand calculation; superseded by the SPICE results in Addendum 3,
which found two things this ignored): worst-case CMRR with 0.1 % resistors
is 20 log(2 x 10.09 / 0.004) = 68 dB (the OPA1654's own CMRR is 120 dB); input-referred
noise with two 4.7 nV/sqrt(Hz) amplifiers and the 10k / 90.9k network is about
17.6 nV/sqrt(Hz), an EIN of about -110 dBu over 20 kHz, which is 3 dB worse
than the single-ended stage on the electret capsules (they sit 20 dB above
that anyway) and fine for a dynamic mic after +20 dB of PCM1864 PGA. The pad
(R18-R25 through U4/U5) stays on the hot leg only: engaging it in balanced
mode would unbalance the pair by 9.7 dB, so the firmware locks it out there.

### Layout changes forced by the route

* U10 (TPA6130A2) pin 3 (GND, between the two INM pins) is tied into the
  exposed pad by a stub instead of getting a fanout via 0.7 mm west of the
  pin row, which had fenced HP_INP_L/R in.
* C86 / C87 (the 2.2 uF INM caps) are rotated 180 deg so their signal pad
  faces U10, and C57 / C58 (the 2.2 uF input coupling caps) moved 1.2 mm
  east and apart (y 54.6 / 60.2): the gap between their U10-side pads is
  2.9 mm now, and both HP_INP_L and HP_INP_R fit through it. The old 0.7 mm
  gap took one track and left HP_INP_R unroutable.
* U11 (TPS61175) pins 6 and 7 (both GND) share one fanout via north-west of
  pin 7, and VBOOST_IN (pin 3 to L2 pad to C1), BOOST_SS (pin 5 via at
  13.6/30.9, B.Cu to C79) and BOOST_EN (pin 4 via at 14.25/31.5) are laid by
  hand in `fanout_decouple.py`. The router kept spending the 1.4 x 1.6 mm
  pocket east of the pin row on a VBOOST_IN detour plus a 0.8 mm via and
  left U11.5 unrouted.

New parts on the board: U15, U16, Q5-Q9, D20-D24, R98-R125, C97-C110. The
cold-leg parts sit on the bottom in columns at x 32..63 under the channel
rows; U16 is at (52, 61.5) next to U6, the bias switch block at x 26..41,
y 64..83 on the bottom.

### Result

ERC 0 / 0 / 0 (the CD4053's switch terminals are embedded as passive pins
now, so grounding a spare terminal no longer trips the bidirectional-vs-
power warning). DRC 0 violations / 0 unconnected / 0 parity. GND: 187 pads
in one cluster. 10.6 m of track on two layers, 531 vias (185 x 0.6/0.3,
346 x 0.8/0.4). Fab package rebuilt: BOM 97 lines, 287 placements (178
top, 109 bottom). Freerouting needed 5.5 minutes for the main pass this
time and the locked finishing pass ran (3.7 s) instead of hanging; the
hand-finished stragglers were BOOST_COMP/BOOST_FB (U11's west column, a
lane at x=2.4 and a via pair) and one VREF row-to-row link (an 18 mm F.Cu
run at x=57.2 east of the ATT/AC verticals, via at the BRU row).

Audits: check 3 unchanged (every decoupler 1.39-1.47 mm from its pin).
Check 2: still zero broadside pairs; 10 parallel same-layer pairs totalling
42 mm (previous board: 22 / 165 mm). The two worth knowing about are
ADC_LRCLK beside FRD_ADC for 11.8 mm at 0.16 mm on B.Cu near U7 (the
low-impedance 10 nF node again, and LRCLK is 192 kHz, so anything that
couples lands at DC after the modulator) and I2C_SCL/SDA beside FLU_PAD for
10.8 / 9.2 mm at 0.5 / 0.86 mm on F.Cu west of U4. I2C only toggles when a
setting changes (volume, mode), so the worst case is a faint tick on FLU
during a volume change; if the bench shows it, the deterministic fix is to
move the I2C pair to B.Cu past U4 (the bus runs from the Teensy socket to
J3/U7/U10 and has no reason to be on the top side there).

## Addendum 3: SPICE check of the balanced stage, and what it changed (2026-09-12, later)

The two-op-amp INA was simulated in ngspice 42 (`tools/spice/ina_sim.py`:
behavioural op-amps, 120 dB open loop, 18 MHz GBW, 4.5 nV/rtHz, infinite
CMRR so only the passive network is measured; 300 ohm dynamic mic, 150 ohm
per leg; 16 corners of +/-0.1 % on Ra/Rb/Rf/Rg). The hand-calculated "68 dB
worst case" in Addendum 2 was wrong for two reasons the calculation had
ignored.

**Finding 1, input impedance imbalance.** The 68k + 33k pad divider hangs on
the hot leg only, so the hot leg sees 1M || 101k = 92k while the cold leg
sees 1M. With any real source impedance that converts common mode to
differential ahead of the amplifier, and the 4.7 uF coupling caps then give
the two legs different high-pass corners (0.37 Hz vs 0.034 Hz) which adds a
phase mismatch at low frequency. Simulated CMRR as drawn: 35 dB at 20 Hz,
43 dB at 50 Hz, 50 dB at 1 kHz, regardless of resistor matching.
Fix: **R126-R129, 100k 1 % from each cold leg (ACC) to VREF**, which
balances the loading (90.9k vs 91.7k). Result: 67 dB worst case from 20 Hz
to 1 kHz with nominal caps; with the film caps at their +/-10 % limits the
low end drops to 48 dB at 20 Hz, 56 dB at 50 Hz, 61 dB at 100 Hz (the
corner mismatch again; a tighter cap tolerance or larger caps would buy it
back if the bench ever asks for it).

**Finding 2, high-frequency roll-off mismatch.** A2's 22 pF across Rf rolls
the hot path off at 80 kHz, but the non-inverting "+1" term of that stage
does not roll off, and with A1's 22 pF across Ra the cold path did not track
either: CMRR fell to 37 dB at 10 kHz and 31 dB at 20 kHz. The cold path
needs A1 = 1 + Rg(1/Rf + sCf), i.e. a zero, not a pole. Fix: **C105-C108
moved from across Ra (CPRE-CFB) to across Rb (CFB-VREF)**, same value.
Result: 62 dB at 10 kHz, 58 dB at 20 kHz worst case.

Unchanged by either fix: differential gain 20.06 dB, -3 dB at 71 kHz,
electret-mode (cold leg grounded) gain 20.05 dB, input-referred noise
18.8 nV/rtHz, 2.65 uV rms 20 Hz-20 kHz, EIN -109.3 dBu with 150 ohm per leg.

Both changes are in `generate_schematic.py` / `generate_pcb.py` (R126-R129
sit at x=50 in the bottom cold-leg columns) and the board was regenerated
and rerouted.

**Test points.** The audit after that route showed ADC_BCLK running 21 mm
beside FRD_ADC at minimum spacing: the five ADC clock/data probe pads at
x=124 were pulling those nets 40 mm east past the DAC and the headphone
caps. TP3-TP8 now sit in the empty bottom strip between U7 and its
terminators (y=36.5, x 81-98.5), so the probe stubs are a few millimetres
instead of forty, and the board was rerouted once more. Final numbers are in
the section below.

### Final state (board `revc3mic3`, 2026-09-12 11:15)

ERC 0 / 0 / 0. DRC 0 violations / 0 unconnected / 0 parity. GND 187 pads
in one cluster. 320 footprints, 291 placements (178 top, 113 bottom), BOM
97 lines. 10.6 m of track on two layers, 521 vias (182 x 0.6/0.3, 339 x
0.8/0.4). Fab package rebuilt.

Audits: check 3 unchanged (decouplers 1.34-1.60 mm). Check 2: zero
broadside pairs; 11 parallel same-layer pairs totalling 42.7 mm (the route
before the test-point move had drawn 21 pairs / 104 mm, with ADC_BCLK 21 mm
beside FRD_ADC). Worst now is ADC_LRCLK beside BLD_ADC for 8.6 mm at
0.15 mm on B.Cu near U7, then DAC_BCLK_IC beside BLD_ADC for 5.6 mm; all
victims are the 10 nF-terminated _ADC nodes as before. Segment pairs within
2 mm: 163 (was 410). The five ADC clock nets are 62-80 mm long (were
81-101 mm) now that their probe pads sit beside U7.

Sourcing was checked the same day against Mouser, DigiKey and LCSC:
`../manufacturing/BOM-SOURCING-CHECK-20260912.md`. One scarce part (U12
TPS7A4701RGWR, LCSC only), about twenty obsolete commodity MPNs with
substitutes listed, nothing blocking.

## Addendum 4: the scarce-part pass (2026-09-12, afternoon)

Jason asked for a non-scarce replacement for the 9 V analog LDO and for
any other thin part, plus the best price on everything. Three things
changed on the board, one in the parts list only.

### U12: TPS7A4701RGWR out, ADP7142AUJZ-R7 in

The TPS7A4701 (VQFN-20, 1 A, 4 uVrms) was the one part with no depth
anywhere: Mouser 0, DigiKey reel-only, LCSC a few dozen at $12. The +9V
rail it feeds carries roughly 25-40 mA (the four OPA1654 quads, the
TLE2426 splitter, the CD4053s and the mic bias), so a 1 A regulator was
never the point; the noise and PSRR were. The Analog Devices ADP7142
(TSOT-23-5, 200 mA, 11 uVrms, PSRR 88 dB at 10 kHz, 40 V input) is the
same class of part in a package every distributor stocks by the thousand
(Mouser 11k, LCSC 4.7k, about $3 either way).

Circuit: VIN and EN tied to +10V5, VOUT = 1.2 V x (1 + R130/R131) with
R130 = 130k, R131 = 20k -> 9.0 V; C83 2.2 uF X7R on the input, the
existing 10 uF on the output. No soft-start pin, so nothing else changed.
Placement: U12 at (9.5, 50.5) top, C83 at (5.5, 50.5), R130/R131 at
x=13.3 rotated 90 (rot 0 overlapped the TSOT courtyard). Thermal: 1.5 V
drop x 40 mA = 60 mW, 170 C/W -> about 10 C rise, fine.

### Q8/Q9 rotated 180

The first route with the new U12 fenced Q9's gate (MIC5_CTRL) on both
layers. Turning the 5 V bias pair (Q8 AO3401A, Q9 2N7002) 180 degrees
put the gate pad on the open side and the route closed.

### Two hand-routed stragglers

The route finished with two unconnected items, both fixed by hand
(`tools/fix_c3mic4_stragglers*.ps1`, every piece checked by
`poly_route.py` against the 0.16 mm rule before saving):

- **+3V3_A, C41.1 to C42.1 under U7.** The U7.26 GND fanout via sat in
  the only lane. U7.26 now ties to U7.25 with a 0.5 mm stub on F.Cu
  (U7.25 has its own via), and +3V3_A runs on B.Cu at y = 48.5 between
  the two GND pads. U7 keeps four ground pins, worst pad-to-via 1.26 mm.
- **CHASSIS, the BRU row (C16.2 / C100.2 / D23.2).** The island was
  boxed in on both layers by the BLD row's hot/cold pair (BLD_MIC on
  F.Cu, BLD_MICC + BLD_RAWC on B.Cu) to the north and the BRU pair
  (BRU_AC on F.Cu, BRU_MICC on B.Cu) to the east, with the 1812 film-cap
  pads (3.4 mm wide) closing the gaps. Fix: BLD_MICC's C99.1 -> C103.1
  run lifted from y = 98.56 to y = 98.1 (between C99's two pads), which
  opens a via slot at (41.0, 98.85); CHASSIS now goes C15.2 -> F.Cu along
  y = 97.325 between the C19 pads -> via -> B.Cu down x = 41.0 -> D23.2.
  BRU_MICC's feeder, which used to fence that lane at y = 101.745 and
  x = 40.541, hops over BRU_RAWC on F.Cu instead (vias at (34.5, 102.3)
  and (39.0, 105.3)). The island's own via moved from (38.409, 102.594)
  to (39.0, 103.35). Net topology is unchanged; the cold-leg pairs still
  run side by side.

### Parts-list refresh (no board change)

`passive_catalog.py` primaries were re-picked from a live Mouser + LCSC
sweep of every BOM line (`tools`-side script in the cloud session; results
in `../manufacturing/QuadPreRecorder-best-source-20260912.csv`). Dead
Murata "D"/"L" suffix MLCC numbers gave way to the in-stock Samsung /
Yageo / TDK / Taiyo Yuden parts that were already the alternates, and the
discrete MPNs that Mouser no longer lists (2N7002,215, BAT54,215,
SS14-13-F, 1206L200/12WR, the no-name LEDs) were replaced by
2N7002NXAKR, BAT54-7-F, onsemi SS14, 1206L200PR and Kingbright
WP7113QBC/D / WP7113ID. The schematic was regenerated so the BOM carries
the new numbers; ERC 0 / 0 / 0 and DRC parity 0 afterwards.

### Final state (board `revc3mic4`, 2026-09-12 15:00)

ERC 0 / 0 / 0. DRC 0 violations / 0 unconnected / 0 parity. GND 184 pads
in one cluster (three fewer than revc3mic3: the VQFN LDO's ground pins
and pad are gone). 322 footprints, 293 placements (180 top, 113 bottom),
BOM 97 lines. 10.3 m of track on two layers, 513 vias (182 x 0.6/0.3,
331 x 0.8/0.4). Fab package rebuilt (`QuadPreRecorder-RevC-PCBWay-handoff.zip`).

Audits: check 3 unchanged (decouplers 1.34-1.60 mm; U14's 3.3/5.3 mm
still the known exception). Check 2: zero broadside pairs; 12 parallel
same-layer pairs totalling 45.9 mm (was 11 / 42.7 mm). Worst is now
ADC_TDM_IC beside BRU_ADC for 9.9 mm at 0.15 mm on B.Cu near (83, 64),
then ADC_MCLK_IC beside BLD_ADC 8.1 mm at 0.30 mm; the victims are the
10 nF-terminated _ADC nodes as before, so this stays on the bench list
rather than forcing another route. Segment pairs within 2 mm: 270.

Backups: `hardware/QuadPreRecorder.kicad_pcb.revc3mic4-routed-clean-20260912`
and `.kicad_sch.revc3mic4-20260912`; the pre-hand-fix board is
`.revc3mic4-prefix-20260912`.

## Addendum 5: final pre-order check (2026-09-13)

Independent pass with the kicad-happy analyzers (schematic, PCB with
per-track detail, cross-domain, EMC pre-compliance with ngspice PDN
models, thermal, SPICE of 102 detected subcircuits, Gerber/drill) plus a
DRC run at every severity, not just errors, and a hand cross-check of the
BOM against the placement file. Verdict: **ready to upload**, after the
fixes below.

### Found and fixed

1. **The Gerber set had no inner layers.** `build_manufacturing.py` still
   exported the Rev C2 two-layer list (F.Cu, B.Cu, mask, paste, silk,
   edge), so every "4-layer" package since the 2026-09-08 stackup change
   carried a job file that said four layers and copper for two. PCBWay
   would have quoted a 2-layer board or bounced it. In1.Cu / In2.Cu are
   now exported; the job file lists Copper L1-L4 and the analyzer reads
   the planes back as one region each with 632 clearance flashes.
2. **Two stitching vias were drilled inside through-hole pads.** The
   stitching pass had dropped 0.4 mm GND vias on top of SW3's pad S2
   (76.0, 71.0 vs 76.0, 70.5) and beside SW2's pad 2 (0.04 mm hole-to-hole)
   - warnings only, so the error-level DRC gate never showed them. A drill
   inside a drill breaks out and can tear the barrel. Both removed; the
   SW pads are themselves GND so nothing is lost.
3. **U13 (BQ24074, 0.74 A charger) had no thermal vias** under its exposed
   pad, and U11 (TPS61175) had one. At 5 V in / 3.6 V battery the charger
   dissipates about 1 W in a 3 x 3 mm QFN; without vias to the planes it
   would sit in thermal fold-back and charge slowly. Two 0.3 mm vias now
   sit in U13's pad (the other three candidate spots landed on the
   VBUS_FUSED trace underneath and were rejected by DRC) and four more in
   U11's, all requested bottom-tented in the order notes.
4. **+3V3_A and CHASSIS hand routes re-seated.** The hand-routed segments
   from Addendum 4 ended 0.025 mm inside a pad edge and 0.0004 mm off a
   track end. KiCad counted them connected; the independent connectivity
   check did not. Both now land on pad centre / exact track end.
5. **Housekeeping:** In1/In2 typed as power layers in the board file (they
   were "signal", which the stackup checker took literally), a 6 um
   HP_OUT_L sliver deleted, TP1/TP2 (the two USB wire pads) taken out of
   the BOM on both schematic and board so PCBWay is not asked to source a
   pad.

### Checked and accepted (no change)

- **Buck input loop.** U1 (TPS62160, 2.25 MHz) has its 100 nF 6 mm and
  its 10 uF 10.5 mm from the VIN pins, pad to pad; the EMC pass sizes the
  hot loop at roughly 30-50 mm2 against a 25 mm2 target. It is the
  digital 5 V rail, 45 mm from the nearest preamp, inside a metal box.
  Rev D should pull C2/C3 against the pins; not worth a re-route now.
- **Op-amp decoupling.** U6/U16 (OPA1654) have their nearest 100 nF
  8.5-8.7 mm from pin 4 and the 10 uF bulk 8 mm away, on a 9 V LDO rail
  with two solid planes. Fine for 18 MHz audio op-amps; Rev D note.
- **Via-in-pad on the U7 decoupling caps** (8 x 0.3 mm vias in 0603 pads):
  accepted, tented on the far side; the notes tell PCBWay.
- **EMC pre-compliance score 0/100** is the tool's arithmetic on 18
  error-class findings, most of which do not apply: three "adjacent
  signal layer" errors from the layer typing (fixed), "harmonics" for U14
  which is an LDO, PDN anti-resonance at 250-320 MHz on audio rails, USB
  diff pair layer change on a 12 Mbit full-speed link that goes through a
  wire anyway, and "no filtering on J5" (headphone jack; TPA6130A2 output,
  no ferrites, the usual hobby-grade choice). Real items it raised: the
  U1 loop above, and the eleven clock nets on outer layers, which is
  inherent to a SIG/GND/GND/SIG stack.
- **Thermal 484 C on U12** is the analyzer assuming 4.5 V out at 0.3 A;
  the rail is 9 V at 25-40 mA, 60 mW, about +10 C.
- **Schematic analyzer**: 6 "errors" are all expected topology (diode-fed
  rails, the PCM1864 internal LDO pin, 3.3 V logic into 5 V-supplied I2C
  and enable pins that the TPA6130A2 datasheet allows); SPICE: 90 pass, 0
  fail, 12 skipped (VREF bulk cap, not a filter).
- **DRC warnings that remain:** 105 silkscreen overlaps and 98 silk-over-
  copper (reference text over pads; the export subtracts the mask so
  nothing prints on copper), 17 silk clipped at the edge (connector
  outlines over the wall), 199 "/NET vs NET" parity name warnings from
  the generated flat labels, 199 missing AltMPN footprint fields. All
  cosmetic.

### Package as uploaded

Board `revc3final` (backup `hardware/QuadPreRecorder.kicad_pcb.revc3final-20260913`).
ERC 0/0/0; DRC 0 violations / 0 unconnected / 0 parity at error level.
322 footprints, 293 placements (180 top, 113 bottom), BOM 95 lines, all
with MPNs, 5 DNP (R5, R38-R41). 517 vias: 188 x 0.6/0.3, 329 x 0.8/0.4.
Gerbers: 4 copper + mask/paste/silk both sides + edge, PTH/NPTH Excellon,
IPC-D-356 netlist, job file. BOM and CPL designators cross-check 1:1.

## Addendum 6 (2026-09-15): the Teensy 4.1 socket footprint was wrong; board re-routed

The in-depth review dossier (`hardware/reviews/QuadPreRecorder-RevC3-review-dossier.md`)
cross-checked every IC pinout against its datasheet and, last, the custom
`Teensy41_Socket` footprint against PJRC's Teensy 4.1 dimension drawing, the
PJRC pinout card and the XenGi `Teensy4.1` symbol (pins 1-48 numbered around
the module). The footprint, unchanged since Rev B and never built, had two
errors:

1. **Row spacing.** The two 1x24 socket rows were drawn 17.78 mm apart. The
   module's pin rows are 15.24 mm (0.6 in) apart on a 17.78 mm wide body
   (pins 1.27 mm in from each long edge). A real Teensy could not have been
   plugged in at all.
2. **Right-row order.** From the USB end the right row was drawn VIN, GND,
   23, 22 ... 13, 41 ... 33, GND, 3V3. The module is VIN, GND, **3.3V**,
   23 ... 13, **GND**, 41 ... 33. Twenty-two of the twenty-four right-row
   pads were therefore one position off: ADC_MCLK would have sat on the
   Teensy's 3.3 V pin, every right-side signal on its neighbour's pin, the
   NAV_PUSH pull-up on a GND pin, and the +3V3_D rail on I/O 33.

The left row (GND, 0 to 12, 3.3V, 24 to 32, square pad = GND next to pin 0)
was correct, so the schematic, netlist and BOM were unaffected. The
2026-09-13 PCBWay package is void.

### What changed

- `tools/generate_footprints.py`: rows 15.24 mm apart, right row
  VIN GND2 3V3B 23..13 GND3 41..33, outline 17.78 x 60.96 mm.
- `tools/generate_schematic.py`: the second 3.3 V pin (3V3B) is now a
  no-connect. Both 3.3 V pins are the same regulator output inside the
  module; the corrected position (USB end of the right row) has no +3V3_D
  copper within 25 mm, and one pin carries the rail's few milliamps of
  pull-ups easily. ERC 0/0/0 after the change.
- First attempt, abandoned: `tools/teensy_fix_stageA.py` patched the routed
  board in place and `tools/astar_route.py` (a grid router that checks every
  step with `stitch_pass3`'s geometry rules) closed the short escapes, but
  moving the right pin row 2.54 mm inward had swallowed the slot between the
  analog bus and the row that six long control lines (NAV_LEFT, NAV_ENC_A,
  REC_LED, GAIN_SW, LINE_MUTE, NAV_DOWN) used to reach the module. Neither
  the grid router nor two Freerouting passes with everything else exported
  `(type protect)` (`tools/finish_teensy*.ps1`, `tools/protect_except.py`,
  `tools/import_ses_into_current.py`) could close them without moving
  preamp routing. Those intermediate boards are kept as
  `QuadPreRecorder.kicad_pcb.teensyfix-*-20260915`.
- Done instead: a full re-route through the Rev C3 pipeline
  (`tools/launch_full_route.ps1` -> `full_route_body.ps1`: pristine board
  from `generate_pcb.py` with the corrected footprint library, pre-flight,
  decoupling and GND fanout, Freerouting 1.9 single-threaded, import, GND
  pours, stitching). Freerouting finished in under 3 minutes with nothing
  left over (the finishing-pass Freerouting instance then sat idle because
  it had no work; it was killed and the first route kept). Post passes as
  in Addendum 5 (`tools/post_teensy_reroute.ps1`, `post_teensy_reroute2.ps1`):
  U11/U13 exposed-pad thermal vias, In1/In2 typed power, TP1/TP2 out of the
  BOM, stitch pass 3 (nothing to rescue), four stitching vias that landed in
  the J10 / SW2 / U8 GND pad holes removed.

### Result

Board `revc3teensy-final` (backup
`hardware/QuadPreRecorder.kicad_pcb.revc3teensy-final-20260915`, raw route
`.revc3teensy-routed-raw-20260915`, pre-fix board
`.revc3final-preteensyfix-20260915`, schematic
`.kicad_sch.revc3final-preteensyfix-20260915`). ERC 0/0/0; DRC 0 violations,
0 unconnected, 0 parity at error level; at every severity the same 220
cosmetic warnings as before (105 silk_overlap, 98 silk_over_copper, 17
silk_edge_clearance) plus the 199 + 199 AltMPN / "/NET" name notes. GND: 184
pads, one cluster. 3050 segments, 523 vias (185 x 0.6/0.3, 338 x 0.8/0.4),
10.55 m of track. 322 footprints, 293 placements, BOM 95 lines.

Audits on the new route: check 1 unchanged (placement); check 2 zero
broadside pairs, 15 same-layer parallel clock/analog pairs totalling
34.9 mm (was 12 / 45.9 mm), worst I2C_SCL beside FRD_AC 7.4 mm at 0.48 mm
(an idle I2C line; bench item as before); check 3 analog copper 1766 mm
confined to x 1..86 / y 41..107, BRU_PRE 82.1 mm (was 82.7). Fab package
`QuadPreRecorder-RevC-PCBWay-handoff.zip` rebuilt 2026-09-15 with all four
copper layers; the 2026-09-13 zip is void.

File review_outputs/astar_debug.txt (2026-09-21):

layer F origin 60.000 9.922  x from 60.00 step 0.381
  9.92 ####.................................#######....######...................................................
 10.30 #########################################################################################################
 10.68 #########################################################################################################
 11.06 ####.................................#######...............##########.......................###..........
 11.45 ####.................................#######.............############.......................###..........
 11.83 ####.................................#######.............###................................###..........
 12.21 ####.................................#######..............#..............................................
 12.59 #########################################################################################################
 12.97 #########################################################################################################
 13.35 #########################################################################################################
 13.73 ####.................................#######.............................................................
 14.11 ####.................................#######.............................................................
 14.49 ####.................................#######.............................................................
 14.87 ####.................................#######.............................................................
 15.26 #############################################################################################............
 15.64 #############################################################################################............
 16.02 ####......................................................###.............................##.............
 16.40 ####.....................................................####............................................
 16.78 ####...................................................###...............................................
 17.16 ####..................................................#####..............................................
 17.54 ####...............................................#..##.################################................
 17.92 #####################################################....#################################...............
 18.30 #####################################################....##..............................##..............
 18.68 ####.................................#######..##........###...............................##.............
 19.07 ####.................................#######..###......###.................##..............###...........
 19.45 ####.................................#######..################################..............###..........
 19.83 ####.................................#######...###############################..............###..........
 20.21 #########################################################################################################
 20.59 #########################################################################################################
 20.97 #########################################################################################################
 21.35 ####.................................#############.......................................................
 21.73 ####.................................#######.######......................................................
 22.11 ####.................................#######################.............................................
 22.49 ####.................................#######################.............................................
 22.88 #########################################################################################################
 23.26 #########################################################################################################
 23.64 ####.................................###############.###.................................................
 24.02 #####................................###################.............##..................................
 24.40 ######...............................#######.......#####............####.................................
 24.78 ####.##..............................#######........####################.................................
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
layer B origin 60.000 9.922  x from 60.00 step 0.381
  9.92 ####.................................#######.............########..............##........................
 10.30 ##################################################################..............##.......................
 10.68 ####################################################################.............##......................
 11.06 ####.................................#######..............###########.............##........###..........
 11.45 ####.................................#######.............############..............##.......###..........
 11.83 ####.................................#######.............###########................##......###..........
 12.21 ####.................................##############.......###########................##..................
 12.59 ####.................................###############.......###########................##.................
 12.97 .........############################################.......###########................##................
 13.35 ####....##############################################.......###########................##...............
 13.73 ####...###...........................#######......#####.......###########................##..............
 14.11 ####..###............................#######.......#####.......###########................##.............
 14.49 ####.###.............................#######........#####.......###########................##............
 14.87 #######..............................#######.........#####.......###########................##...........
 15.26 ######................................######..........#####.......###########............#########.....##
 15.64 #####......................................###########.#####.......###########...........####.####.....##
 16.02 ####.......................................##.......###.#####.......###########...........########.....##
 16.40 ####.......................................##........###.####........###########............######....###
 16.78 ####.......................................##.........###.##..........############...........############
 17.16 ####.......................................##.........#######..........##################################
 17.54 ####.......................................##......#..########..........#################################
 17.92 ###.........................................##....###..#####.##..........#########.......................
 18.30 ###...................................#####.##....###...###...##..........#########......................
 18.68 ####.................................#######.###..##....####...##..........###########################...
 19.07 ####.................................#######..######...######...##.........############################..
 19.45 ####.................................#######..##.##.....##.###...##........#########........######....###
 19.83 ####.................................#######....###.....##..###...##.......##########.......######.....##
 20.21 ####.................................#######....##......##...###...##.......##########........####.....##
 20.59 ...##......................................##..###......##....###...##........###########################
 20.97 ######...............................############.......##.....###...##........##########################
 21.35 ####.##..............................############.......##......###...##........########.................
 21.73 ####..##.............................#######.####.......##.......###...##........########................
 22.11 ####...##............................#######..####......####......###...##........########...............
 22.49 ####....##...........................#######.#####......####.......###...##........########..............
 22.88 ###......##..........................#######.####.......####........###...##........########.............
 23.26 ###......##.........................#############.......####.........###...##........########............
 23.64 ####.....##.........................#############....#######..........###...##........########...........
 24.02 ####.....##.........................#############....#######.........#####...##........##################
 24.40 ####.....##.........................########.####....#######........#######...##........#####............
 24.78 ####.....##.........................########.####.......####.........###.###...##........################
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

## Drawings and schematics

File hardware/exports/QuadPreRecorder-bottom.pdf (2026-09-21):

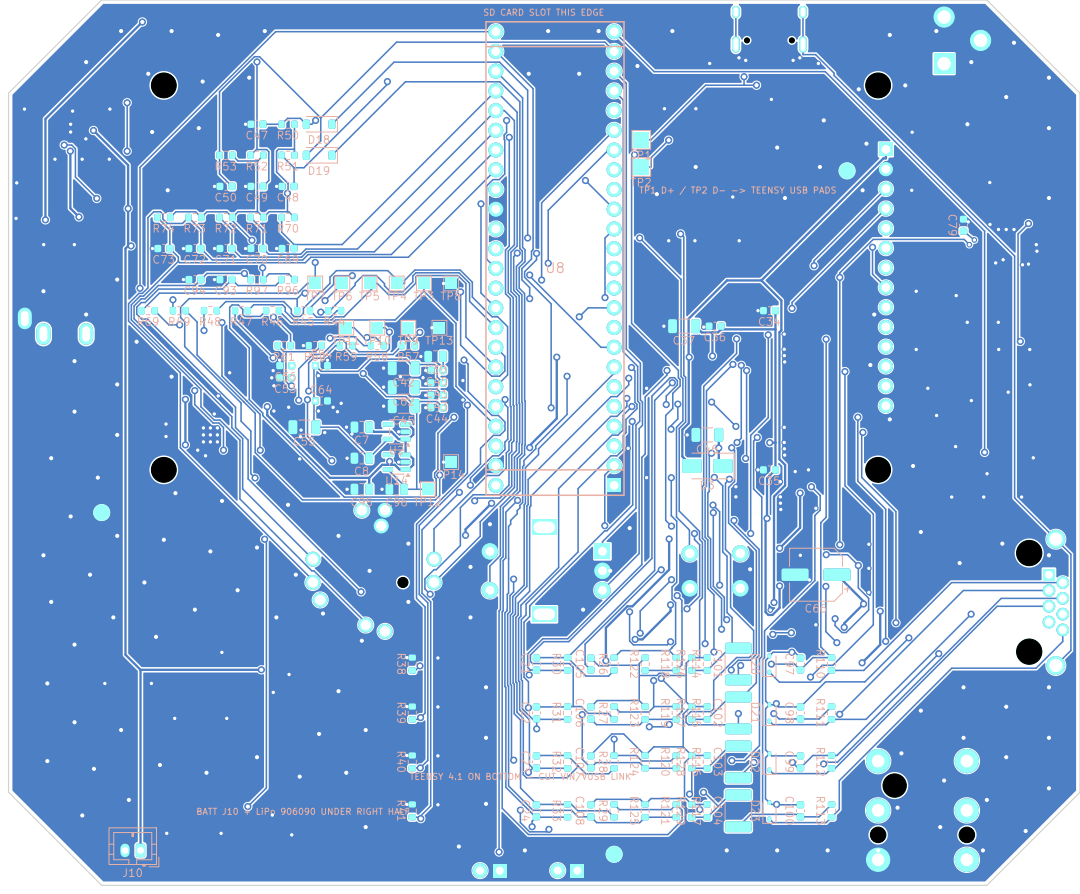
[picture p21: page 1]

SD CARD SLOT THIS EDGE

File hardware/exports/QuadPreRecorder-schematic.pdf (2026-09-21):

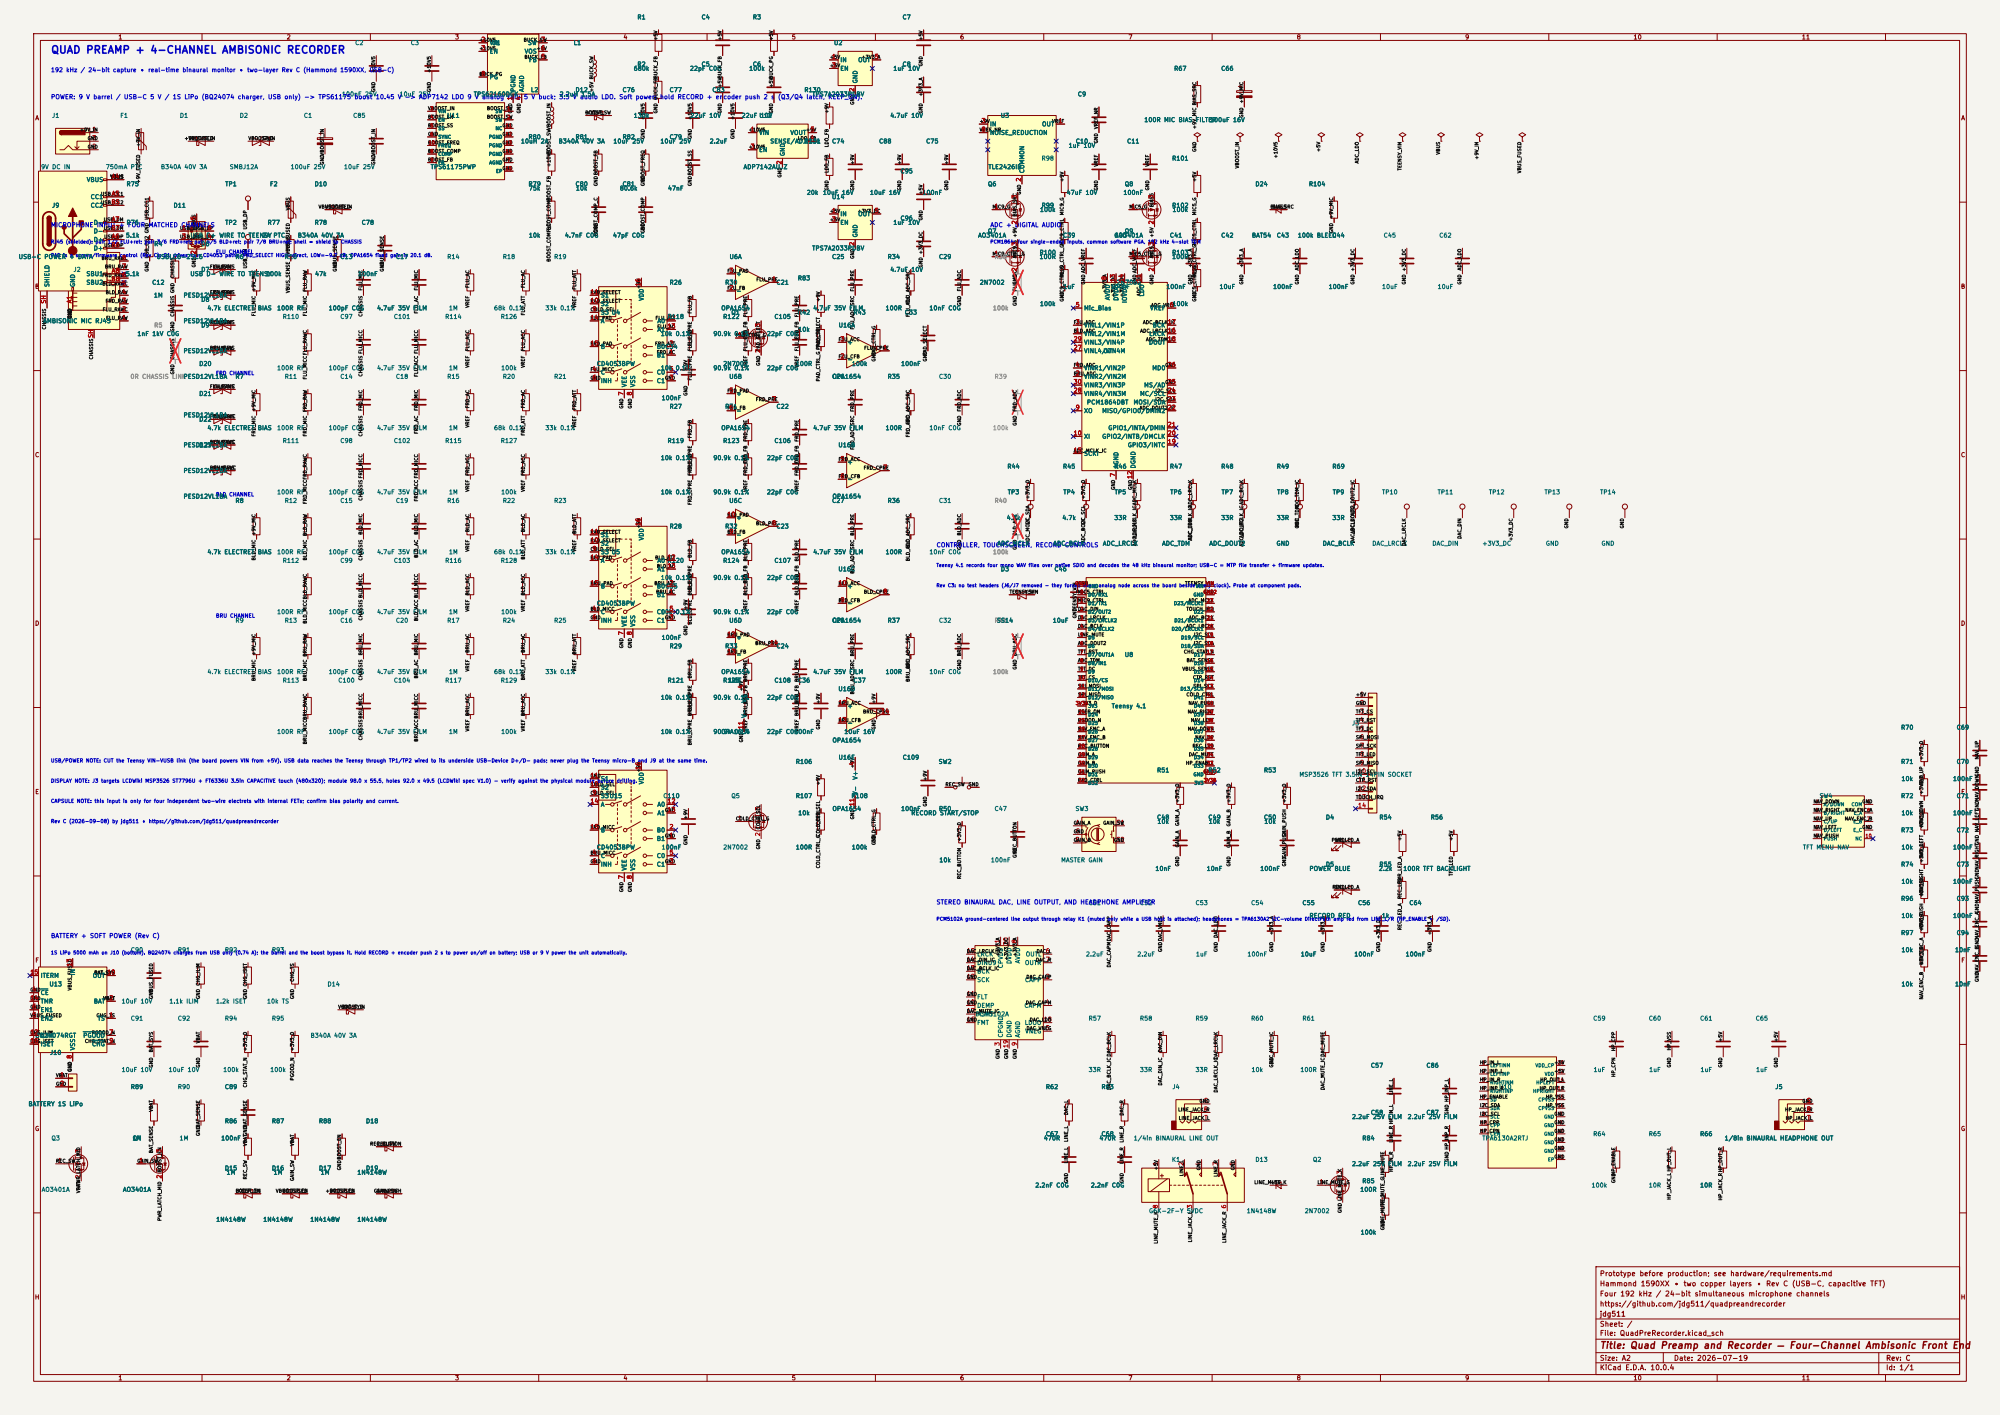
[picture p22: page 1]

QUAD PREAMP + 4-CHANNEL AMBISONIC RECORDER

LRCK 16 BCK 17 DOUT 18 GPIO3/INTC 19 GPIO2/INTB/DMCLK 20 GPIO1/INTA/DMIN 21 MISO/GPIO0/DMIN2 22 MOSI/SDA 23 MC/SCL 24 C9

192 kHz / 24-bit capture • real-time binaural monitor • two-layer Rev C (Hammond 1590XX, USB-C)

LRCK 16 BCK 17 DOUT 18 GPIO3/INTC 19 GPIO2/INTB/DMCLK 20 GPIO1/INTA/DMIN 21 MISO/GPIO0/DMIN2 22 MOSI/SDA 23 MC/SCL 24 U7 PCM1864DBT
VINL2/VIN1M 1
VINL3/VIN4P 29
VINL4/VIN4M 27

CONTROLLER, TOUCHSCREEN, RECORD CONTROLS

Teensy 4.1 records four mono WAV files over native SDIO and decodes the 48 kHz binaural monitor; USB-C = MTP file transfer + firmware updates. BRU CHANNEL

J3 MSP3526 TFT 3.5IN 14PIN SOCKET D4 POWER BLUE D5 RECORD RED

CAPSULE NOTE: this input is only for four independent two-wire electrets with internal FETs; confirm bias polarity and current.

Rev C (2026-09-08) by jdg511 • https://github.com/jdg511/quadpreandrecorder 1S LiPo 5000 mAh on J10 (bottom). BQ24074 charges from USB only (0.74 A); the barrel and the boost bypass it. Hold RECORD + encoder push 2 s to power on/off on battery; USB or 9 V power the unit automatically.

2.2k D4 POWER BLUE D5 RECORD RED

STEREO BINAURAL DAC, LINE OUTPUT, AND HEADPHONE AMPLIFIER

BATTERY + SOFT POWER (Rev C)

Prototype before production; see hardware/requirements.md
Hammond 1590XX • two copper layers • Rev C (USB-C, capacitive TFT)
Four 192 kHz / 24-bit simultaneous microphone channels
https://github.com/jdg511/quadpreandrecorder
jdg511
Sheet: /
File: QuadPreRecorder.kicad_sch
Title: Quad Preamp and Recorder — Four-Channel Ambisonic Front End

Size: A2 | Rev: C
KiCad E.D.A. 10.0.4 | Id: 1/1

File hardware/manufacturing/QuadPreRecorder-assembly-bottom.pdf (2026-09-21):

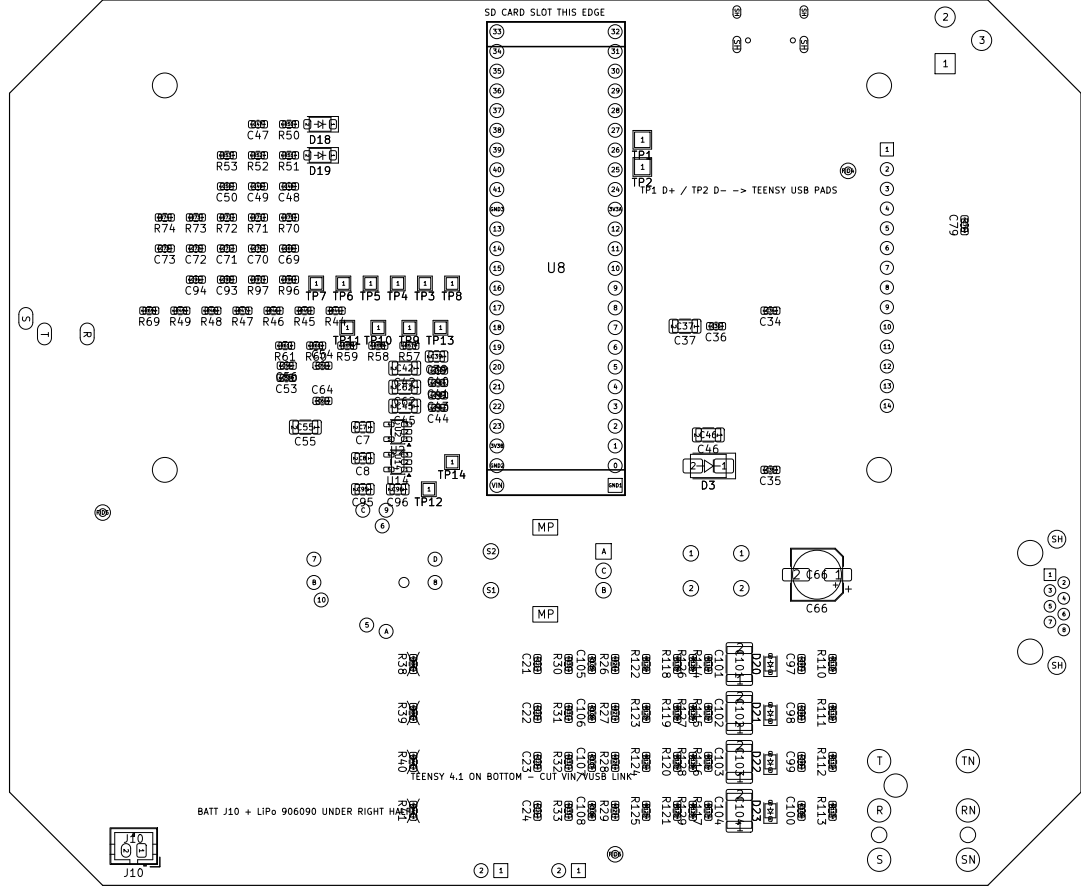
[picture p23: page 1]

SD CARD SLOT THIS EDGE

TEENSY 4.1 ON BOTTOM - CUT VIN/VUSB LINK

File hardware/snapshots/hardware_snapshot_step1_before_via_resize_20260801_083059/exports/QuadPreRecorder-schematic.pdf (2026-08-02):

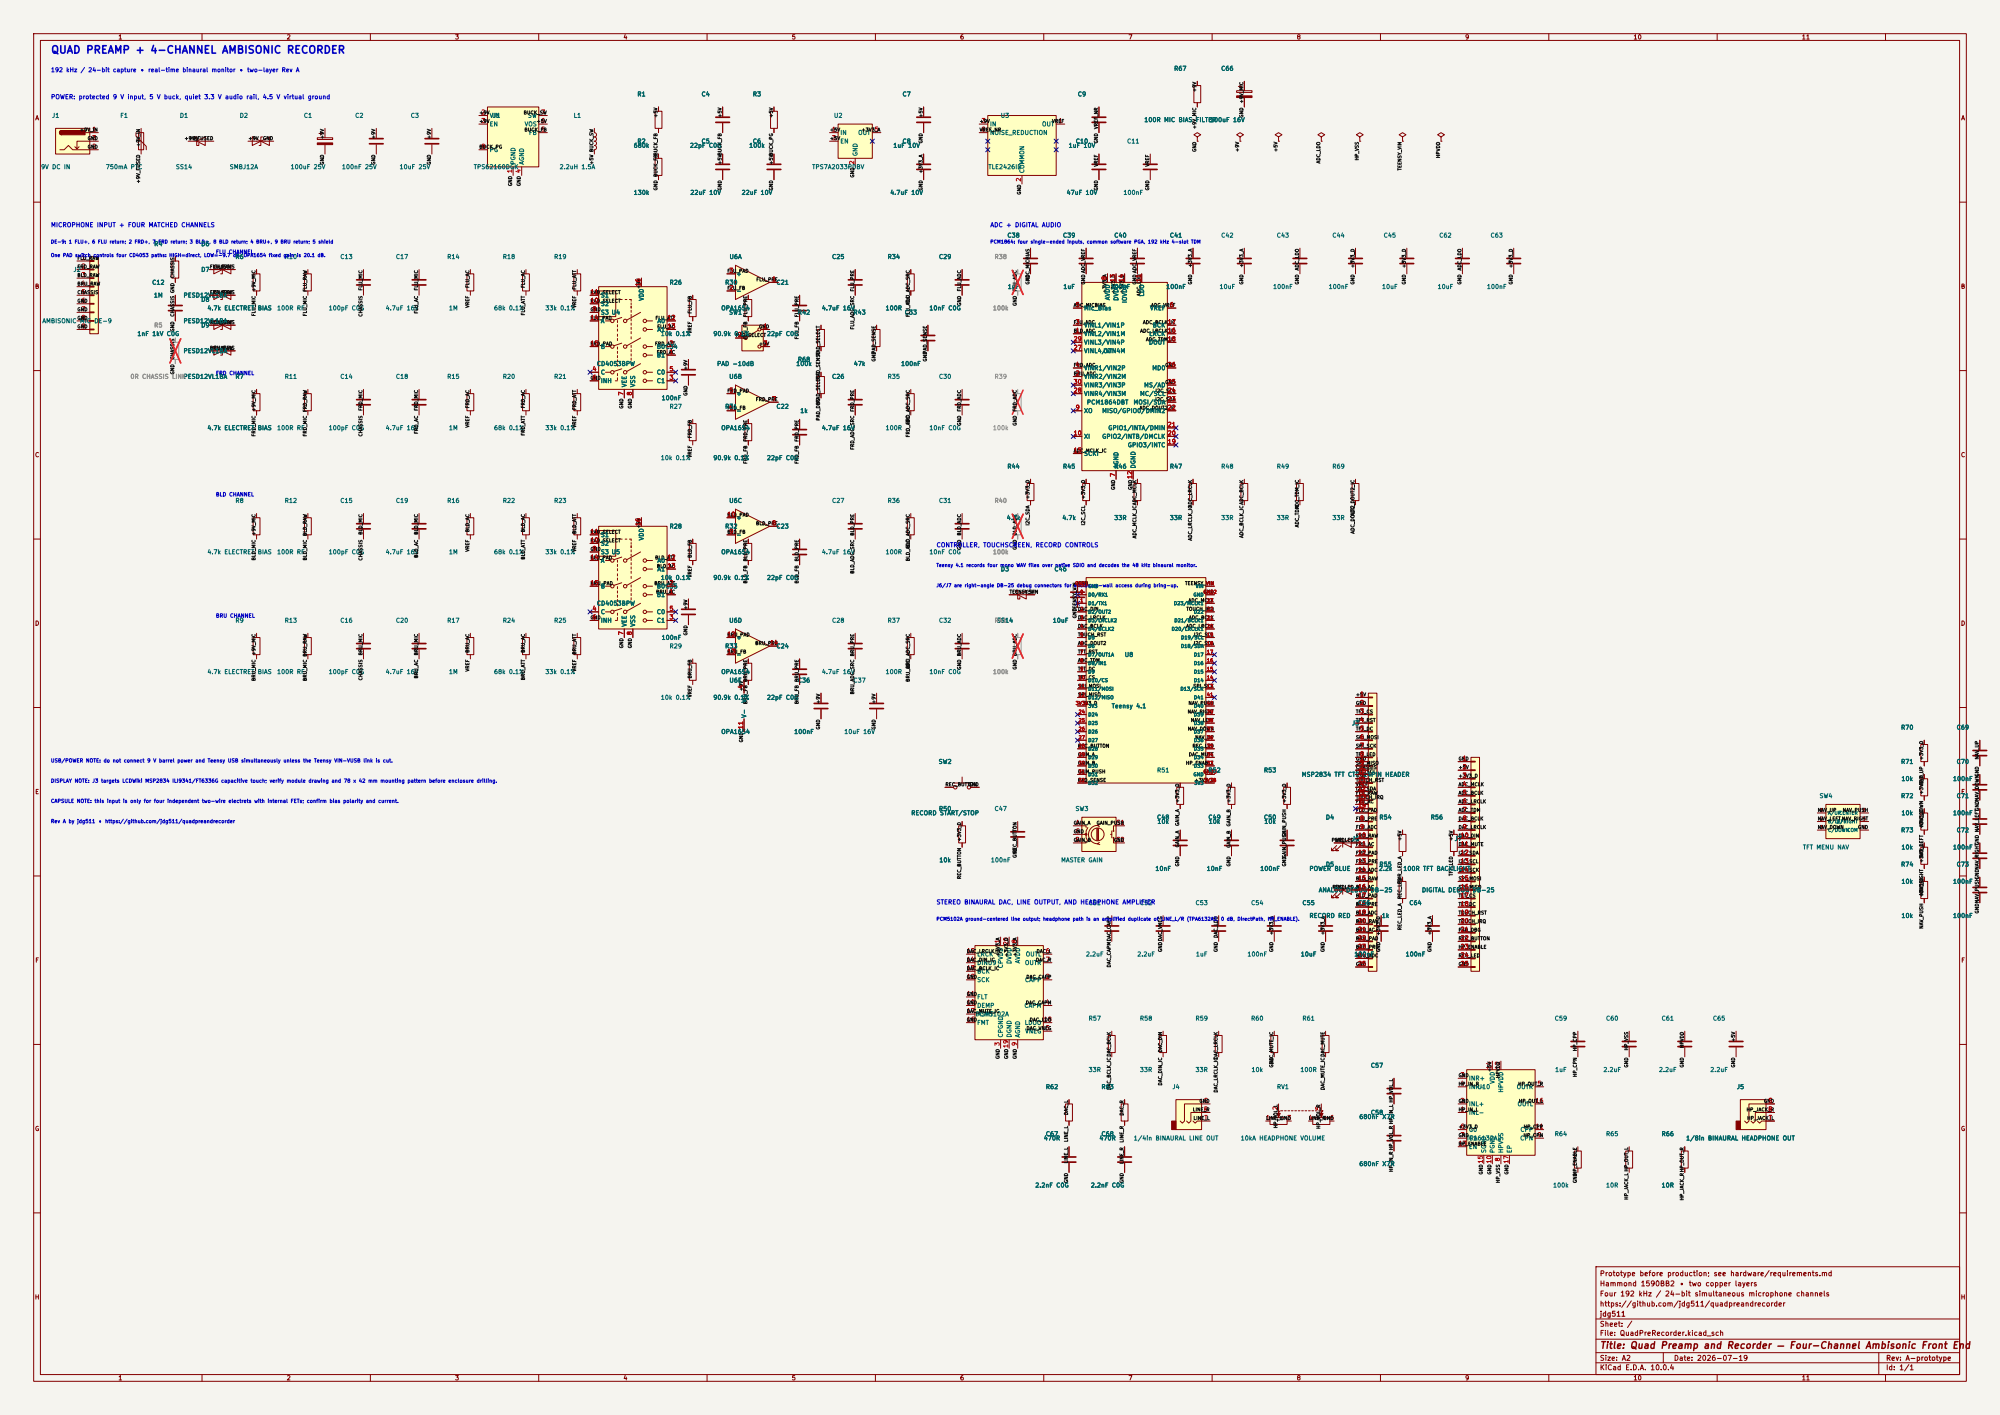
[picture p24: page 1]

192 kHz / 24-bit capture • real-time binaural monitor • two-layer Rev A QUAD PREAMP + 4-CHANNEL AMBISONIC RECORDER

DE-9: 1 FLU+, 6 FLU return; 2 FRD+, 7 FRD return; 3 BLD+, 8 BLD return; 4 BRU+, 9 BRU return; 5 shield POWER: protected 9 V input, 5 V buck, quiet 3.3 V audio rail, 4.5 V virtual ground

FLU CHANNEL FRD CHANNEL BLD CHANNEL

PCM1864: four single-ended inputs, common software PGA, 192 kHz 4-slot TDM

LRCK 16 BCK 17 DOUT 18 GPIO3/INTC 19 GPIO2/INTB/DMCLK 20 GPIO1/INTA/DMIN 21 MISO/GPIO0/DMIN2 22 MOSI/SDA 23 MC/SCL 24 R46

Teensy 4.1 records four mono WAV files over native SDIO and decodes the 48 kHz binaural monitor. J6/J7 are right-angle DB-25 debug connectors for enclosure-wall access during bring-up. BRU CHANNEL

Rev A by jdg511 • https://github.com/jdg511/quadpreandrecorder CAPSULE NOTE: this input is only for four independent two-wire electrets with internal FETs; confirm bias polarity and current. DISPLAY NOTE: J3 targets LCDWiki MSP2834 ILI9341/FT6336G capacitive touch; verify module drawing and 78 x 42 mm mounting pattern before enclosure drilling. USB/POWER NOTE: do not connect 9 V barrel power and Teensy USB simultaneously unless the Teensy VIN-VUSB link is cut.

STEREO BINAURAL DAC, LINE OUTPUT, AND HEADPHONE AMPLIFIER

Prototype before production; see hardware/requirements.md
Hammond 1590BB2 • two copper layers
Four 192 kHz / 24-bit simultaneous microphone channels
https://github.com/jdg511/quadpreandrecorder
jdg511
Sheet: /
File: QuadPreRecorder.kicad_sch
Title: Quad Preamp and Recorder — Four-Channel Ambisonic Front End

Size: A2 | Rev: A-prototype
KiCad E.D.A. 10.0.4 | Id: 1/1

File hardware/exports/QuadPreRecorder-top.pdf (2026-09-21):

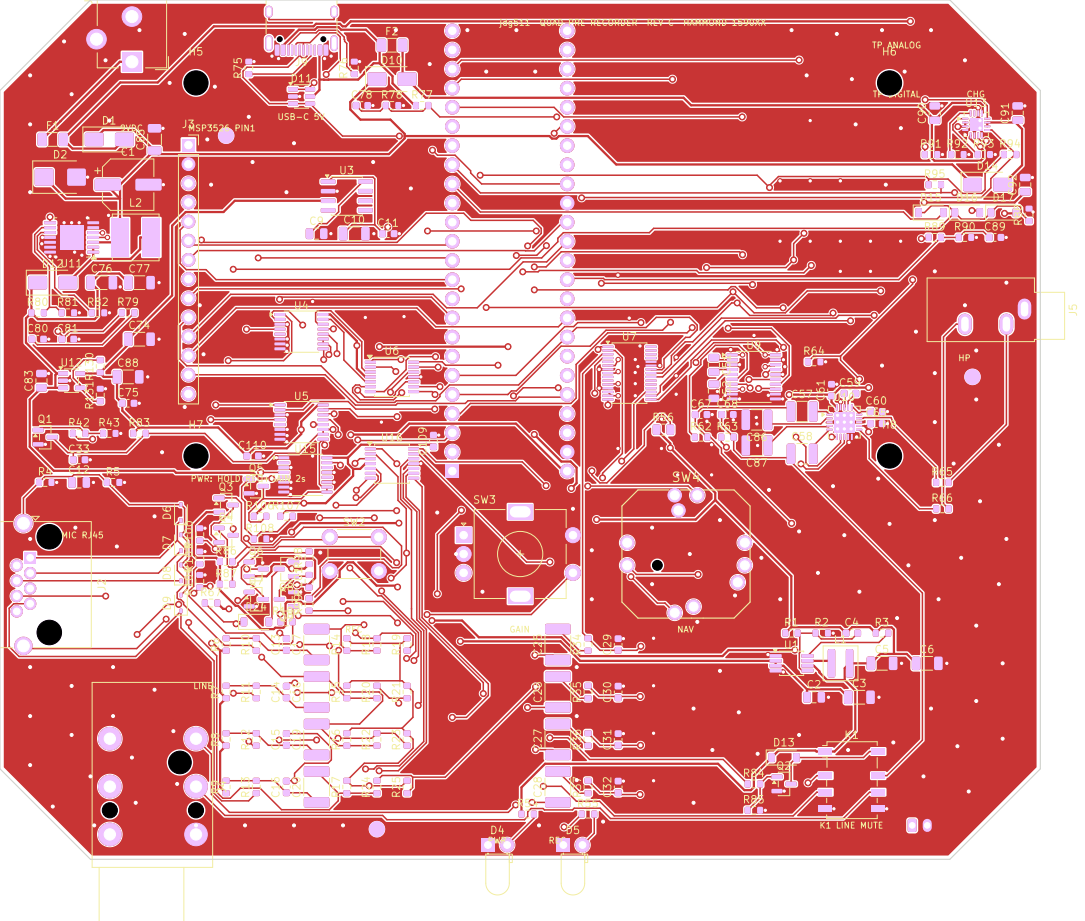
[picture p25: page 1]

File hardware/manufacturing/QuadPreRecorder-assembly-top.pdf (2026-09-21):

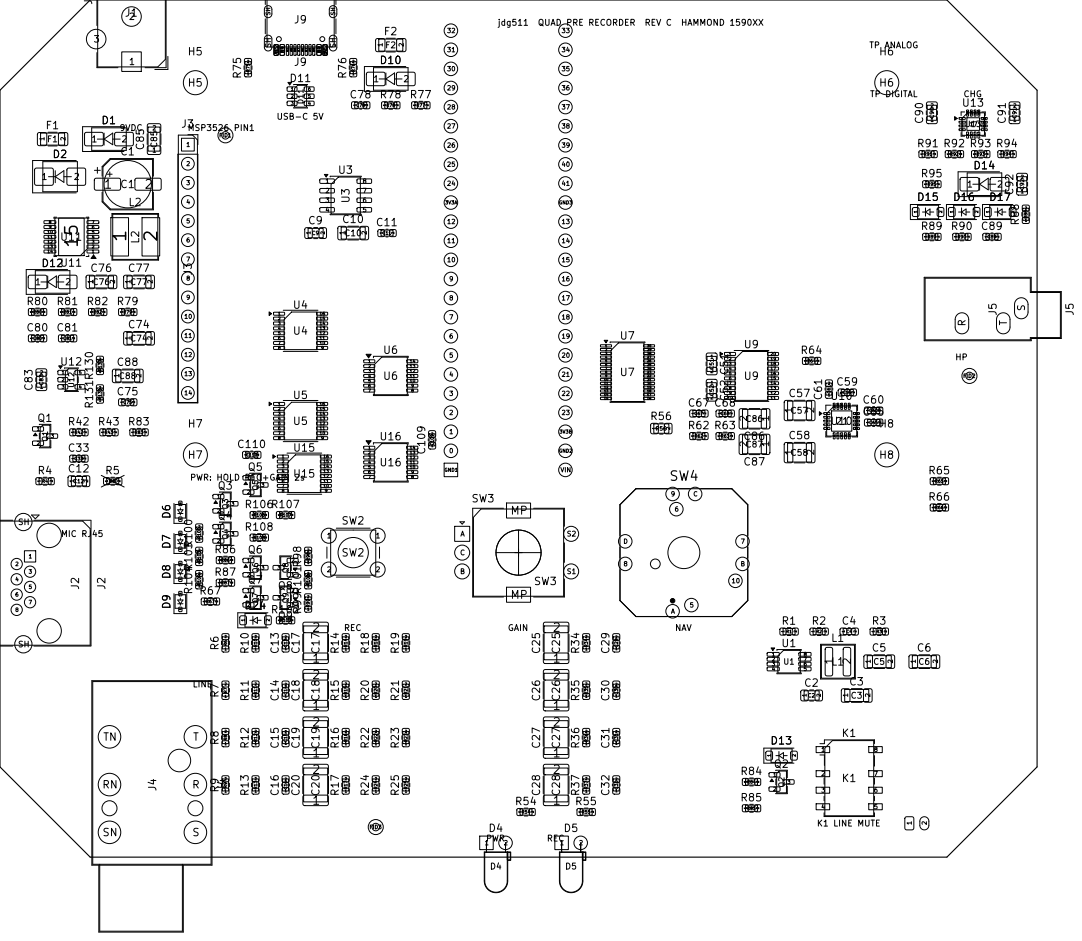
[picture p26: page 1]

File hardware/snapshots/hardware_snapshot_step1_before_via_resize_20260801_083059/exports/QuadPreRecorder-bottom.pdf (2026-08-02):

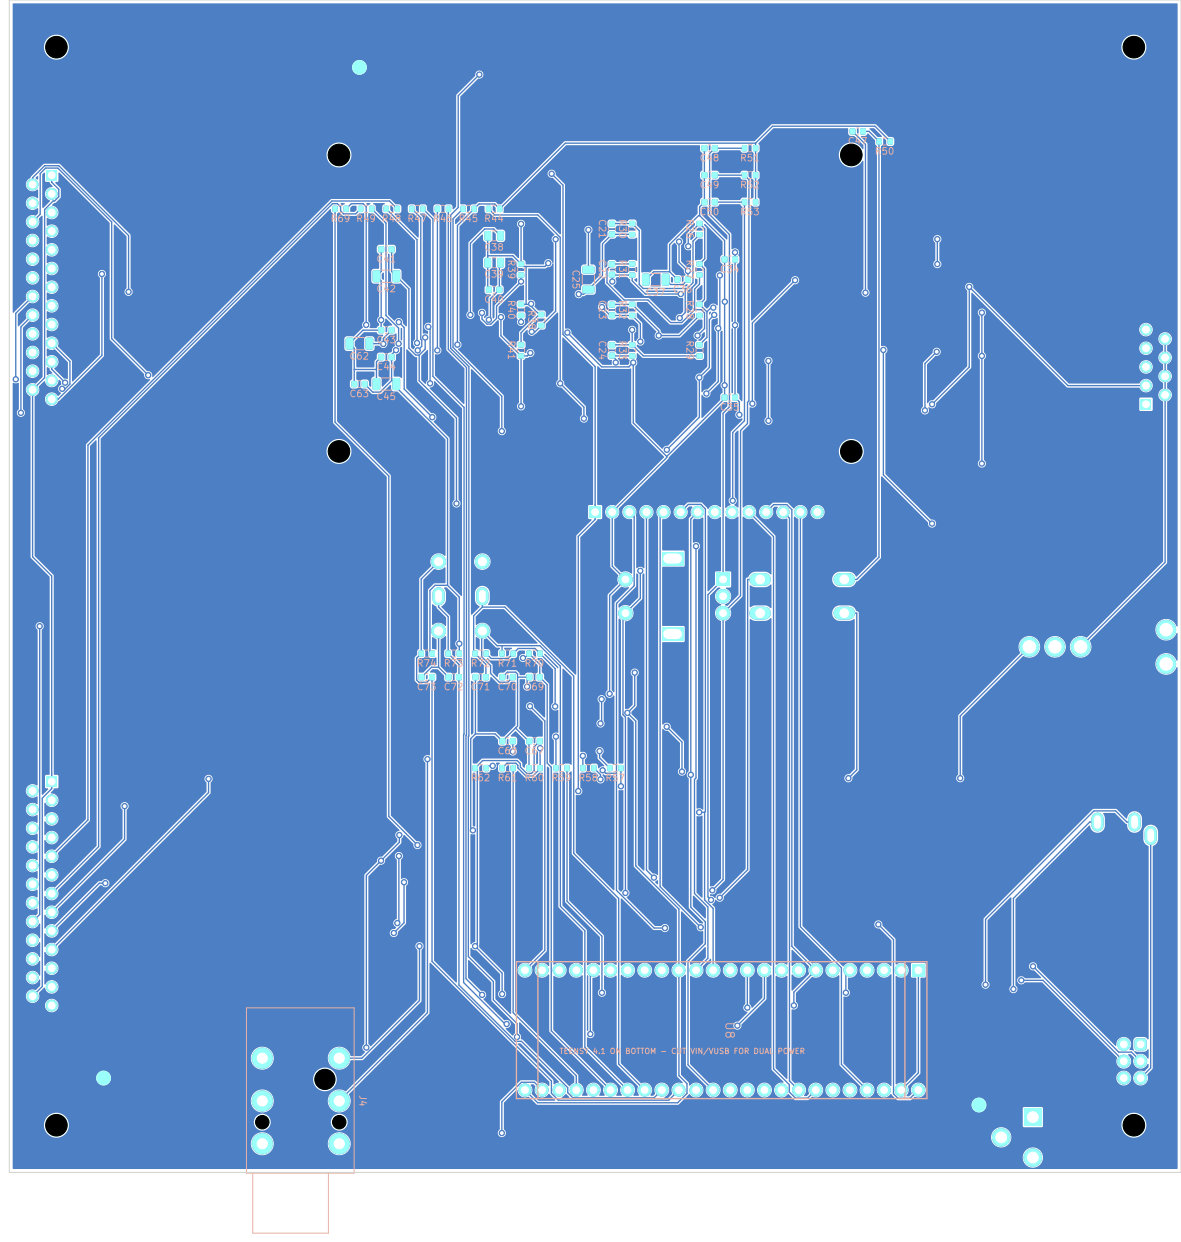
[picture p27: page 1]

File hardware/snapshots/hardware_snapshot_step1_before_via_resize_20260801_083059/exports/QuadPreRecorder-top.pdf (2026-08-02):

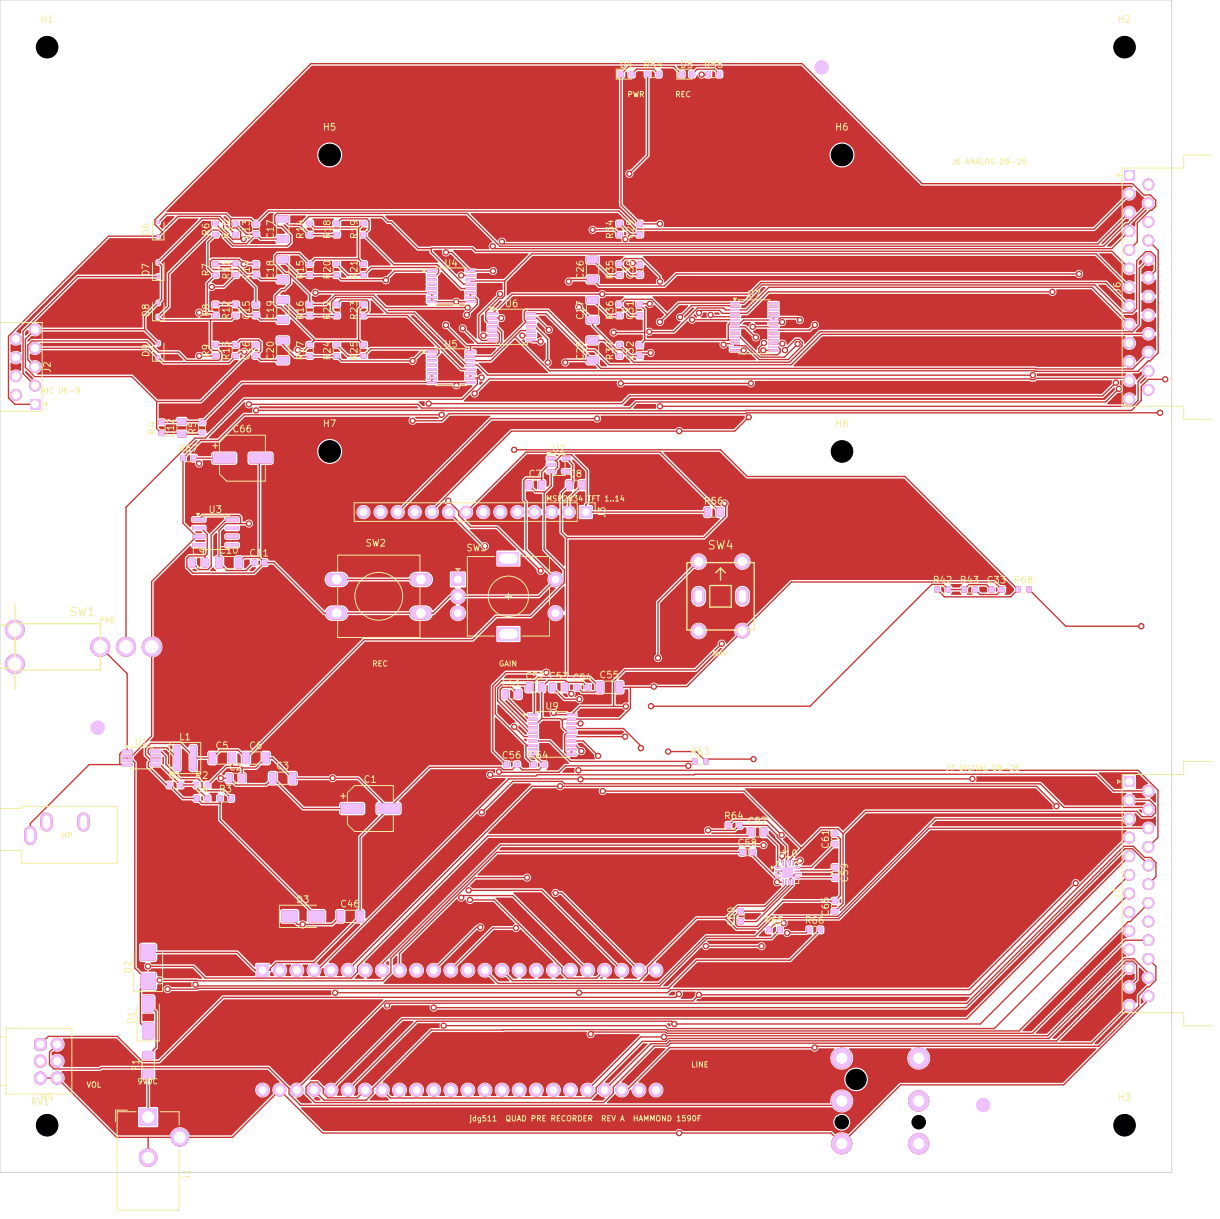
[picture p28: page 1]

jdg511 QUAD PRE RECORDER REV A HAMMOND 1590F

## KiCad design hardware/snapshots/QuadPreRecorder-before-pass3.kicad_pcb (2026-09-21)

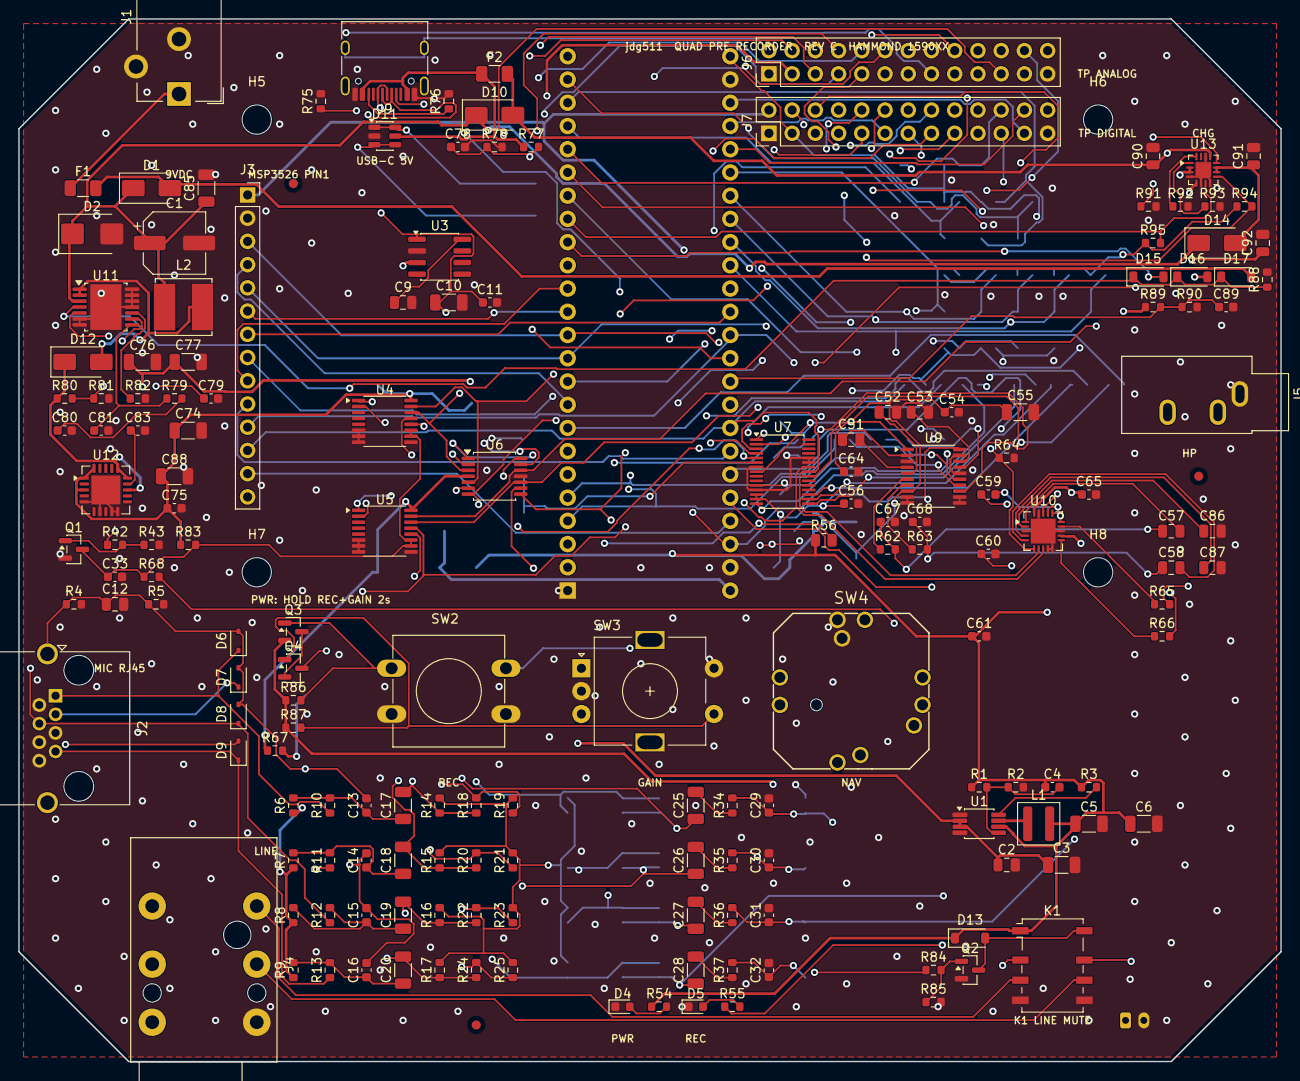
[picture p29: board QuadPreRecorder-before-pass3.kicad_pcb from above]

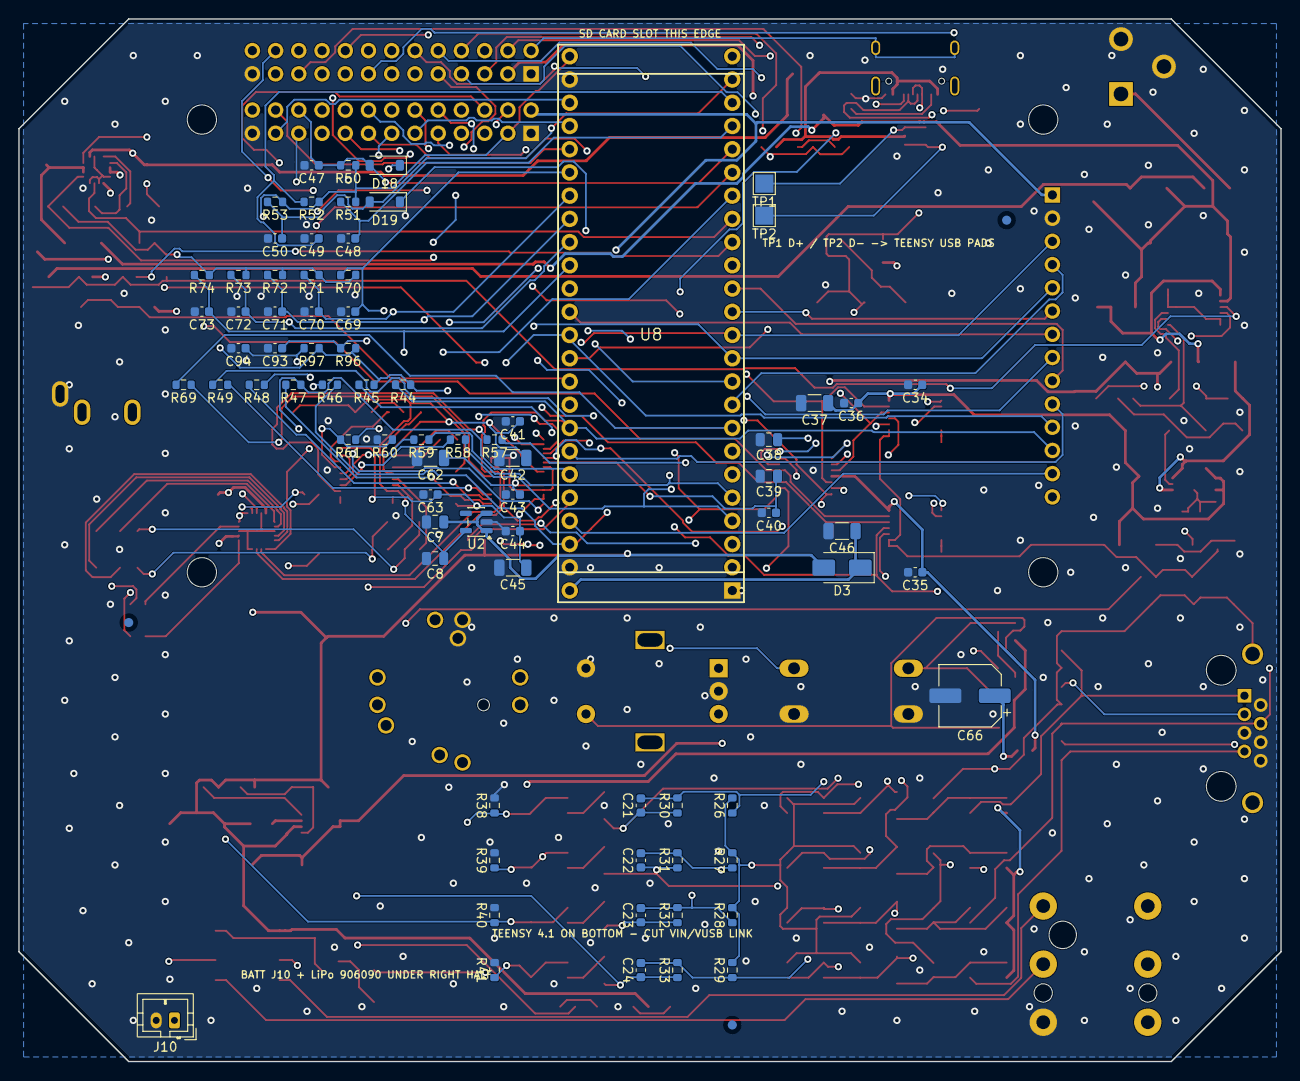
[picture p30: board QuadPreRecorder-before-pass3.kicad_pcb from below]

Board: 4 copper layers, 138.0 x 114.0 mm, 254 parts (79 on the bottom side), 155 nets.

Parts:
C1: 100uF 25V; CP_Elec_6.3x5.8
C2: 100nF 25V; C_0805_2012Metric
C3, C76, C77, C85: 10uF 25V; C_1206_3216Metric
C4, C21, C22, C23, C24: 22pF C0G; C_0603_1608Metric
C5, C6: 22uF 10V; C_1206_3216Metric
C7, C9: 1uF 10V; C_0805_2012Metric
C8: 4.7uF 10V; C_0805_2012Metric
C10: 47uF 10V; C_1206_3216Metric
C11, C33, C34, C35, C36, C40, C41, C43, C44, C47, C50, C54, C56, C63, C64, C69, C70, C71, C72, C73, C75, C78, C89: 100nF; C_0603_1608Metric
C12: 1nF 1kV C0G; C_0805_2012Metric
C13, C14, C15, C16: 100pF C0G; C_0603_1608Metric
C17, C18, C19, C20, C25, C26, C27, C28: 4.7uF 16V; C_1206_3216Metric
C29, C30, C31, C32: 10nF C0G; C_0603_1608Metric
C37, C74, C88: 10uF 16V; C_1206_3216Metric
C38, C39, C53: 1uF; C_0805_2012Metric
C42, C45, C46, C55, C62: 10uF; C_1206_3216Metric
C48, C49, C93, C94: 10nF; C_0603_1608Metric
C51, C52: 2.2uF; C_0805_2012Metric
C57, C58, C86, C87: 2.2uF X7R; C_0805_2012Metric
C59, C60, C61, C65: 1uF; C_0603_1608Metric
C66: 100uF 16V; CP_Elec_6.3x5.8
C67, C68: 2.2nF C0G; C_0603_1608Metric
C79: 47nF; C_0603_1608Metric
C80: 4.7nF C0G; C_0603_1608Metric
C81: 47pF C0G; C_0603_1608Metric
C83: 1uF 16V; C_0603_1608Metric
C90, C91, C92: 10uF 10V; C_0805_2012Metric
D1, D10, D12, D14: B340A 40V 3A; D_SMA
D2: SMBJ12A; D_SMB
D3: SS14; D_SMA
D4: POWER BLUE; LED_0603_1608Metric
D5: RECORD RED; LED_0603_1608Metric
D6, D7, D8, D9: PESD12VL1BA; D_SOD-323
D11: USBLC6-2SC6; SOT-23-6
D13, D15, D16, D17, D18, D19: 1N4148W; D_SOD-123
F1: 750mA PTC; Fuse_1206_3216Metric
F2: 2A PTC; Fuse_1206_3216Metric
FID1, FID2, FID3, FID4, FID5, FID6: Fiducial 1mm; Fiducial_1mm_Mask2mm
H5, H6, H7, H8: M3 TFT MSP3526 92x49.5 VERIFY; MountingHole_3.2mm_M3
J1: 9V DC IN; BarrelJack_CUI_PJ-102AH_Horizontal
J2: AMBISONIC MIC RJ45; RJ45_Amphenol_RJHSE5380
J3: MSP3526 TFT 3.5IN 14PIN SOCKET; PinSocket_1x14_P2.54mm_Vertical
J4: 1/4in BINAURAL LINE OUT; Jack_6.35mm_Neutrik_NRJ6HF_Horizontal
J5: 1/8in BINAURAL HEADPHONE OUT; Jack_3.5mm_CUI_SJ1-3533NG_Horizontal
J6: ANALOG TEST HEADER 2x13; PinHeader_2x13_P2.54mm_Vertical
J7: DIGITAL TEST HEADER 2x13; PinHeader_2x13_P2.54mm_Vertical
J9: USB-C POWER + DATA; USB_C_Receptacle_HRO_TYPE-C-31-M-12
J10: BATTERY 1S LiPo; JST_PH_B2B-PH-K_1x02_P2.00mm_Vertical
K1: G6K-2F-Y 5VDC; Relay_DPDT_Omron_G6K-2F-Y
L1: 2.2uH 1.5A; L_Abracon_ASPIAIG-F4020
L2: 10uH 2A; L_Bourns_SRN6045TA
Q1, Q2: 2N7002; SOT-23
Q3, Q4: AO3401A; SOT-23
R1: 680k; R_0603_1608Metric
R2: 130k; R_0603_1608Metric
R3, R38, R39, R40, R41, R43, R64, R77, R85, R94, R95: 100k; R_0603_1608Metric
R4, R14, R15, R16, R17, R86, R87, R88, R89, R90: 1M; R_0603_1608Metric
R5: 0R CHASSIS LINK; R_0603_1608Metric
R6, R7, R8, R9: 4.7k ELECTRET BIAS; R_0603_1608Metric
R10, R11, R12, R13: 100R RF; R_0603_1608Metric
R18, R20, R22, R24: 68k 0.1%; R_0603_1608Metric
R19, R21, R23, R25: 33k 0.1%; R_0603_1608Metric
R26, R27, R28, R29: 10k 0.1%; R_0603_1608Metric
R30, R31, R32, R33: 90.9k 0.1%; R_0603_1608Metric
R34, R35, R36, R37, R42, R61, R84: 100R; R_0603_1608Metric
R44, R45: 4.7k; R_0603_1608Metric
R46, R47, R48, R49, R57, R58, R59, R69: 33R; R_0603_1608Metric
R50, R51, R52, R53, R60, R70, R71, R72, R73, R74, R79, R81, R83, R96, R97: 10k; R_0603_1608Metric
R54: 2.2k; R_0603_1608Metric
R55, R68: 1k; R_0603_1608Metric
R56: 100R TFT BACKLIGHT; R_0805_2012Metric
R62, R63: 470R; R_0603_1608Metric
R65, R66: 10R; R_0603_1608Metric
R67: 100R MIC BIAS FILTER; R_0603_1608Metric
R75, R76: 5.1k; R_0603_1608Metric
R78: 47k; R_0603_1608Metric
R80: 75k; R_0603_1608Metric
R82: 80.6k; R_0603_1608Metric
R91: 1.1k ILIM; R_0603_1608Metric
R92: 1.2k ISET; R_0603_1608Metric
R93: 10k TS; R_0603_1608Metric
SW2: RECORD START/STOP; SW_PUSH-12mm
SW3: MASTER GAIN; RotaryEncoder_Alps_EC11E-Switch_Vertical_H20mm
SW4: TFT MENU NAV; SW_Nav5_ALPS_RKJXT1F42001
TP1: USB D+ WIRE TO TEENSY; TestPoint_Pad_2.0x2.0mm
TP2: USB D- WIRE TO TEENSY; TestPoint_Pad_2.0x2.0mm
U1: TPS62160DGK; VSSOP-8_3x3mm_P0.65mm
U2: TPS7A2033PDBV; SOT-23-5
U3: TLE2426ID; SOIC-8_3.9x4.9mm_P1.27mm
U4, U5: CD4053BPW; TSSOP-16_4.4x5mm_P0.65mm
U6: OPA1654; TSSOP-14_4.4x5mm_P0.65mm
U7: PCM1864DBT; TSSOP-30_4.4x7.8mm_P0.5mm
U8: Teensy 4.1; Teensy41_Socket
U9: PCM5102A; TSSOP-20_4.4x6.5mm_P0.65mm
U10: TPA6130A2RTJ; WQFN-20-1EP_4x4mm_P0.5mm_EP2.7x2.7mm
U11: TPS61175PWP; Texas_HTSSOP-14-1EP_4.4x5mm_P0.65mm_EP3.4x5mm_Mask3.155x3.2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
U12: TPS7A4701RGW; Texas_RGW0020A_VQFN-20-1EP_5x5mm_P0.65mm_EP3.15x3.15mm
U13: BQ24074RGT; VQFN-16-1EP_3x3mm_P0.5mm_EP1.68x1.68mm

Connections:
+3V3_A: C8.1, C41.1, C42.1, C54.1, C55.1, C64.1, U2.5, U7.8, U9.1, U9.8
+3V3_D: C44.1, C45.1, C56.1, C63.1, J7.3, R44.1, R45.1, R50.1, R51.1, R52.1, R53.1, R70.1, R71.1, R72.1, R73.1, R74.1, R94.1, R95.1, R96.1, R97.1, U7.13, U7.14, U8.3V3A, U8.3V3B, U9.20
+5V: C4.1, C5.1, C6.1, C7.1, C61.1, C65.1, D3.2, D13.1, J3.1, J7.2, K1.1, L1.2, R1.1, R3.1, R54.1, R56.1, U1.6, U2.1, U2.3, U10.12, U10.20
+9V: C34.1, C35.1, C36.1, C37.1, C74.1, C75.1, C88.1, J6.3, R67.1, R83.1, U3.3, U4.16, U5.16, U6.4, U12.1, U12.3, U12.20
+9V_FUSED: D1.2, D17.2, F1.2
+9V_IN: F1.1, J1.1
+9V_MIC: C66.1, R6.1, R7.1, R8.1, R9.1, R67.2
+10V5: C2.1, C3.1, C76.1, C77.1, D12.1, R80.1, U1.2, U1.3, U12.13, U12.15, U12.16
ADC_BCLK: J7.5, R48.1, U8.21
ADC_BCLK_IC: R48.2, U7.17
ADC_DOUT2: R69.2, U8.6
ADC_DOUT2_IC: R69.1, U7.22
ADC_LDO: C43.1, C62.1, U7.11
ADC_LRCLK: J7.6, R47.1, U8.20
ADC_LRCLK_IC: R47.2, U7.16
ADC_MCLK: J7.4, R46.1, U8.23
ADC_MCLK_IC: R46.2, U7.15
ADC_MICBIAS: C38.1, U7.5
ADC_TDM: J7.7, R49.2, U8.8
ADC_TDM_IC: R49.1, U7.18
ADC_VREF: C39.1, C40.1, U7.6
BAT_SENSE: C89.1, R89.2, R90.1, U8.16
BAT_SYS: C91.1, D14.2, U13.10, U13.11
BLD_AC: C19.2, J6.16, R16.1, R22.1, U5.13
BLD_ADC: C31.1, J6.19, R36.2, R40.1, U7.1
BLD_ADC_SRC: C27.2, R36.1
BLD_ATT: R22.2, R23.1, U5.12
BLD_FB: C23.2, R28.1, R32.2, U6.9
BLD_MIC: C15.1, C19.1, R8.2, R12.2
BLD_PAD: J6.17, U5.14, U6.10
BLD_PRE: C23.1, C27.1, J6.18, R32.1, U6.8
BLD_RAW: D8.1, J2.4, J6.15, R12.1
BOOST_COMP: C81.1, R79.1, U11.8
BOOST_COMP_C: C80.1, R79.2
BOOST_EN: D15.1, D16.1, D17.1, Q4.3, R88.1, U11.4
BOOST_FB: R80.2, R81.1, U11.9
BOOST_FREQ: R82.1, U11.10
BOOST_SS: C79.1, U11.5
BOOST_SW: D12.2, L2.2, U11.1, U11.2
BRU_AC: C20.2, J6.21, R17.1, R24.1, U5.1
BRU_ADC: C32.1, J6.24, R37.2, R41.1, U7.2
BRU_ADC_SRC: C28.2, R37.1
BRU_ATT: R24.2, R25.1, U5.2
BRU_FB: C24.2, R29.1, R33.2, U6.13
BRU_MIC: C16.1, C20.1, R9.2, R13.2
BRU_PAD: J6.22, U5.15, U6.12
BRU_PRE: C24.1, C28.1, J6.23, R33.1, U6.14
BRU_RAW: D9.1, J2.7, J6.20, R13.1
BUCK_FB: C4.2, R1.2, R2.1, U1.5
BUCK_PG: R3.2, U1.8
BUCK_SW: L1.1, U1.7
CHASSIS: C12.1, C13.2, C14.2, C15.2, C16.2, D6.2, D7.2, D8.2, D9.2, J2.SH, J6.2, J9.SH, R4.1, R5.1
CHG_ILIM: R91.1, U13.12
CHG_ISET: R92.1, U13.16
CHG_STAT_N: R94.2, U8.17, U13.9
CHG_TS: R93.1, U13.1
CTP_RST: J3.11, J7.19, U8.14
DAC_BCLK: J7.8, R57.1, U8.4
DAC_BCLK_IC: R57.2, U9.13
DAC_CAPM: C51.2, U9.4
DAC_CAPP: C51.1, U9.2
DAC_DIN: J7.10, R58.1, U8.2
DAC_DIN_IC: R58.2, U9.14
DAC_L: R62.1, U9.6
DAC_LDO: C53.1, U9.18
DAC_LRCLK: J7.9, R59.1, U8.3
DAC_LRCLK_IC: R59.2, U9.15
DAC_MUTE: J7.11, R61.1, U8.34
DAC_MUTE_IC: R60.1, R61.2, U9.17
DAC_R: R63.1, U9.7
DAC_VNEG: C52.1, U9.5
FLU_AC: C17.2, J6.6, R14.1, R18.1, U4.13
FLU_ADC: C29.1, J6.9, R34.2, R38.1, U7.3
FLU_ADC_SRC: C25.2, R34.1
FLU_ATT: R18.2, R19.1, U4.12
FLU_FB: C21.2, R26.1, R30.2, U6.2
FLU_MIC: C13.1, C17.1, R6.2, R10.2
FLU_PAD: J6.7, U4.14, U6.3
FLU_PRE: C21.1, C25.1, J6.8, R30.1, U6.1
FLU_RAW: D6.1, J2.1, J6.5, R10.1
FRD_AC: C18.2, J6.11, R15.1, R20.1, U4.1
FRD_ADC: C30.1, J6.14, R35.2, R39.1, U7.4
FRD_ADC_SRC: C26.2, R35.1
FRD_ATT: R20.2, R21.1, U4.2
FRD_FB: C22.2, R27.1, R31.2, U6.6
FRD_MIC: C14.1, C18.1, R7.2, R11.2
FRD_PAD: J6.12, U4.15, U6.5
FRD_PRE: C22.1, C26.1, J6.13, R31.1, U6.7
FRD_RAW: D7.1, J2.3, J6.10, R11.1
GAIN_A: C48.1, R51.2, SW3.A, U8.29
GAIN_B: C49.1, R52.2, SW3.B, U8.30
GAIN_PUSH: C50.1, D19.2, R53.2, U8.31
GAIN_SW: D19.1, Q4.1, R87.2, SW3.S1
GND: C1.2, C2.2, C3.2, C5.2, C6.2, C7.2, C8.2, C9.2, C10.2, C11.2, C12.2, C29.2, C30.2, C31.2, C32.2, C33.2, C34.2, C35.2, C36.2, C37.2, C38.2, C39.2, C40.2, C41.2, C42.2, C43.2, C44.2, C45.2, C46.2, C47.2, C48.2, C49.2, C50.2, C52.2, C53.2, C54.2, C55.2, C56.2, C60.2, C61.2, C62.2, C63.2, C64.2, C65.2, C66.2, C67.2, C68.2, C69.2, C70.2, C71.2, C72.2, C73.2, C74.2, C75.2, C76.2, C77.2, C78.2, C79.2, C80.2, C81.2, C83.2, C85.2, C86.2, C87.2, C88.2, C89.2, C90.2, C91.2, C92.2, C93.2, C94.2, D2.2, D4.1, D5.1, D11.2, J1.2, J1.3, J2.2, J2.5, J2.6, J2.8, J3.2, J4.S, J5.S, J6.1, J6.25, J7.1, J7.25, J9.A1, J9.A12, J9.B1, J9.B12, J10.2, K1.4, K1.5, Q1.2, Q2.2, R2.2, R4.2, R5.2, R38.2, R39.2, R40.2, R41.2, R43.2, R60.2, R64.2, R75.2, R76.2, R78.2, R81.2, R82.2, R85.2, R88.2, R90.2, R91.2, R92.2, R93.2, SW2.2, SW3.C, SW3.S2, SW4.6, SW4.9, U1.1, U1.4, U2.2, U3.2, U4.6, U4.7, U4.8, U4.9, U5.6, U5.7, U5.8, U5.9, U6.11, U7.7, U7.12, U7.25, U7.26, U8.GND1, U8.GND2, U8.GND3, U9.3, U9.9, U9.10, U9.11, U9.12, U9.16, U9.19, U10.3, U10.9, U10.10, U10.13, U10.19, U10.21, U11.6, U11.7, U11.11, U11.12, U11.13, U11.14, U11.15, U12.5, U12.7, U12.9, U12.10, U12.21, U13.4, U13.6, U13.8, U13.14, U13.17
HP_CPN: C59.2, U10.17
HP_CPP: C59.1, U10.18
HP_ENABLE: J7.23, R64.1, U8.33, U10.6
HP_INP_L: C86.1, U10.2
HP_INP_R: C87.1, U10.4
HP_IN_L: C57.2, U10.1
HP_IN_R: C58.2, U10.5
HP_JACK_L: J5.T, R65.2
HP_JACK_R: J5.R, R66.2
HP_OUT_L: R65.1, U10.14
HP_OUT_R: R66.1, U10.11
HP_VSS: C60.1, U10.15, U10.16
I2C_SCL: J3.10, J7.13, R45.2, U7.24, U8.19, U10.8
I2C_SDA: J3.12, J7.12, R44.2, U7.23, U8.18, U10.7
KEEP_ON: D15.2, U8.24
LDO_NR: C83.1, U12.14
LINE_JACK_L: J4.T, K1.3
LINE_JACK_R: J4.R, K1.6
LINE_L: C57.1, C67.1, K1.2, R62.2
LINE_MUTE: R84.1, U8.5
LINE_MUTE_G: Q2.1, R84.2, R85.1
LINE_MUTE_K: D13.2, K1.8, Q2.3
LINE_R: C58.1, C68.1, K1.7, R63.2
NAV_DOWN: C70.1, R71.2, SW4.A, U8.37
NAV_ENC_A: C93.1, R96.2, SW4.8, U8.26
NAV_ENC_B: C94.1, R97.2, SW4.7, U8.27
NAV_LEFT: C71.1, R72.2, SW4.D, U8.38
NAV_PUSH: C73.1, R74.2, SW4.5, U8.40
NAV_RIGHT: C72.1, R73.2, SW4.B, U8.39
NAV_UP: C69.1, R70.2, SW4.C, U8.36
PAD_CTRL: R42.1, U8.32
PAD_CTRL_G: Q1.1, R42.2, R43.1
PAD_DBG: J7.21, R68.2
PAD_SELECT: C33.1, Q1.3, R68.1, R83.2, U4.10, U4.11, U5.10, U5.11
PGOOD_N: R95.2, U8.25, U13.7
PWR_LATCH_MID: Q3.3, Q4.2
PWR_LED_A: D4.2, R54.2
REC_BUTTON: C47.1, D18.2, J7.22, R50.2, U8.28
REC_LED: J7.24, R55.1, U8.35
REC_LED_A: D5.2, R55.2
REC_SW: D18.1, Q3.1, R86.2, SW2.1
SPI_MISO: J3.9, J7.16, U8.12
SPI_MOSI: J3.6, J7.15, U8.11
SPI_SCK: J3.7, J7.14, U8.13
TEENSY_VIN: C46.1, D3.1, U8.VIN
TFT_CS: J3.3, J7.17, U8.10
TFT_DC: J3.5, J7.18, U8.9
TFT_LED: J3.8, R56.2
TFT_RST: J3.4, U8.7
TOUCH_IRQ: J3.13, J7.20, U8.22
USB_CC1: J9.A5, R75.1
USB_CC2: J9.B5, R76.1
USB_DM: D11.3, D11.4, J9.A7, J9.B7, TP2.1
USB_DP: D11.1, D11.6, J9.A6, J9.B6, TP1.1
VBAT: C92.1, J10.1, Q3.2, R86.1, R87.1, R89.1, U13.2, U13.3
VBOOST_IN: C1.1, C85.1, D1.1, D2.1, D10.1, D14.1, L2.1, U11.3
VBUS: D11.5, F2.1, J9.A4, J9.A9, J9.B4, J9.B9, R77.1
VBUS_FUSED: C90.1, D10.2, D16.2, F2.2, U13.5, U13.13
VBUS_SENSE: C78.1, R77.2, R78.1, U8.15
VREF: C10.1, C11.1, J6.4, R14.2, R15.2, R16.2, R17.2, R19.2, R21.2, R23.2, R25.2, R26.2, R27.2, R28.2, R29.2, U3.1
VREF_NR: C9.1, U3.8

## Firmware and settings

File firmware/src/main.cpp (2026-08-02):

// main.cpp — QuadPreRecorder application firmware
//
// Vendor: Illicit Apothecary
// Target: Teensy 4.1 on the QuadPreRecorder Rev A board
//
// Four-channel ambisonic electret recorder with a real-time binaural monitor.
//
// WHAT RUNS WHERE (this is the part that keeps the audio clean):
//
//   priority 96   SAI1 RX DMA interrupt, every 1.33 ms
//                   deinterleave 256 frames -> pack into the recorder rings
//                   -> copy to the DSP FIFO -> update the meters
//                 Nothing here allocates, blocks, or touches the SD card.
//
//   priority 112  SAI2 TX DMA interrupt, every 1.33 ms
//                   pull one rendered monitor block into the DAC buffer
//
//   priority 208  software interrupt: the monitor DSP
//                   decimate -> A-to-B -> 8 binaural FIRs -> limiter
//                 Preempted by both audio interrupts, so a slow DSP block can
//                 glitch the monitor but can never drop a recorded sample.
//
//   thread level  loop(): SD writes, controls, display, serial console
//
// FIRST TIME ON A NEW BOARD: flash the bringup/ tests first, in order. See
// docs/BRINGUP.md. This firmware assumes the hardware already works.

#include <Arduino.h>
#include <Wire.h>
#include <stdarg.h>

#include "qpr_config.h"
#include "qpr_board.h"
#include "qpr_pcm1864.h"
#include "qpr_sai.h"
#include "qpr_recorder.h"
#include "qpr_dsp.h"
#include "qpr_controls.h"
#include "qpr_display.h"
#include "qpr_touch.h"

using namespace qpr;

// ---------------------------------------------------------------------------
// Subsystems
// ---------------------------------------------------------------------------
static Pcm1864       g_adc;
static SaiCapture    g_capture;
static SaiMonitorOut g_monitor_out;
static Recorder      g_recorder;
static MonitorDsp    g_dsp;
static Meters        g_meters;
static Controls      g_controls;
static Display       g_display;
static TouchFt6336   g_touch;

static char  g_status[48] = "";
static float g_gain_db = cfg::kPgaDefaultDb;
static bool  g_hp_enabled = false;
static bool  g_stream_ok = false;
static uint32_t g_boot_ms = 0;

static void setStatus(const char* fmt, ...) {
  va_list ap;
  va_start(ap, fmt);
  vsnprintf(g_status, sizeof(g_status), fmt, ap);
  va_end(ap);
  Serial.println(g_status);
}

// ---------------------------------------------------------------------------
// Capture interrupt. Order matters: the recorder first, because dropping a
// recorded sample is the only unrecoverable failure here.
// ---------------------------------------------------------------------------
static void onCaptureBlock(const Frame4* frames, uint32_t count) {
  g_recorder.pushFrames(frames, count);
  g_dsp.pushCaptureBlock(frames, count);
  g_meters.accumulate(frames, count);
}

static void onMonitorBlock(float* left, float* right, uint32_t count) {
  g_dsp.render(left, right, count);
}

// ---------------------------------------------------------------------------
// Gain
// ---------------------------------------------------------------------------
static void applyGain(float db) {
  if (db < cfg::kPgaMinDb) db = cfg::kPgaMinDb;
  if (db > cfg::kPgaMaxDb) db = cfg::kPgaMaxDb;
  g_gain_db = g_adc.setGainDb(db);
}

// Total gain from capsule to ADC full scale, for the serial console.
static float totalGainDb() {
  return board::FIXED_PREAMP_GAIN_DB + g_gain_db +
         (g_controls.padEngaged() ? board::PAD_ATTENUATION_DB : 0.0f);
}

// ---------------------------------------------------------------------------
// Transport
// ---------------------------------------------------------------------------
static void startRecording() {
  if (g_recorder.recording()) return;
  if (!g_recorder.cardMounted() && !g_recorder.begin()) {
    setStatus("no SD card");
    return;
  }
  if (!g_recorder.start()) {
    setStatus("start failed: %s", Recorder::errorName(g_recorder.lastError()));
    return;
  }
  board::setRecordLed(true);
  setStatus("recording take %03lu", (unsigned long)g_recorder.takeNumber());
}

static void stopRecording() {
  if (!g_recorder.recording()) return;
  const uint32_t take = g_recorder.takeNumber();
  const float secs = g_recorder.elapsedSeconds();
  const float peak = g_recorder.peakBufferUse();
  const uint32_t over = g_recorder.overrunCount();
  const uint64_t lost = g_recorder.framesDropped();
  g_recorder.stop();
  board::setRecordLed(false);
  if (over) {
    setStatus("take %03lu: %lu gaps, %.0f ms LOST", (unsigned long)take,
              (unsigned long)over,
              (double)(1000.0 * lost / cfg::kSampleRateHz));
  } else {
    setStatus("take %03lu: %.1f s, buffer peak %.0f%%", (unsigned long)take,
              (double)secs, (double)(peak * 100.0f));
  }
}

static void setHeadphones(bool on) {
  g_hp_enabled = on;
  board::setHeadphoneAmp(on);
}

// ---------------------------------------------------------------------------
// Line-level calibration tone.
//
// Both jacks carry the same signal, so this tone appears on the line output
// and the headphones together. Turn the headphone amplifier OFF, or the RV1
// knob down, before using it for any length of time.
// ---------------------------------------------------------------------------
static void toggleReferenceTone() {
  const bool on = !g_dsp.referenceToneActive();
  g_dsp.setReferenceTone(on);
  if (on) {
    const float dbfs = g_dsp.referenceToneDbfs();
    Serial.println();
    Serial.printf("REFERENCE TONE ON: %.0f Hz at %.0f dBFS\n",
                  (double)cfg::kRefToneHz, (double)dbfs);
    Serial.printf("  at the 1/4in line jack (J4): %.3f Vrms  =  %+.1f dBu\n",
                  (double)MonitorDsp::dbfsToLineVrms(dbfs),
                  (double)MonitorDsp::dbfsToLineDbu(dbfs));
    Serial.printf("  for reference, 0 dBFS would be %.2f Vrms = %+.1f dBu\n",
                  (double)MonitorDsp::dbfsToLineVrms(0.0f),
                  (double)MonitorDsp::dbfsToLineDbu(0.0f));
    Serial.printf("  (assumes a %.0f kohm line input; RV1 loads the node too)\n",
                  (double)(cfg::kLineAssumedExternalOhms / 1000.0f));
    Serial.printf("  into 600 ohms instead you would lose %.1f dB -- and so "
                  "would\n  the headphones, because the split is before RV1\n",
                  (double)(MonitorDsp::lineLoadLossDb(cfg::kLineAssumedExternalOhms) -
                           MonitorDsp::lineLoadLossDb(600.0f)));
    Serial.println(F("  Set the receiving device so this reads -20 dBFS on its"));
    Serial.println(F("  meters. The tone bypasses the trim and the limiter, so"));
    Serial.println(F("  the level is exact. Press 'o' again to stop."));
    Serial.println(F("  NOTE: this is also on the headphones. Turn RV1 down."));
    setStatus("REF TONE %.0f dBFS = %+.1f dBu", (double)dbfs,
              (double)MonitorDsp::dbfsToLineDbu(dbfs));
  } else {
    setStatus("reference tone off");
  }
}

// ---------------------------------------------------------------------------
// Serial console. Everything the front panel can do, plus the diagnostics
// that do not fit on a 2.8-inch screen.
// ---------------------------------------------------------------------------
static void printHelp() {
  Serial.println();
  Serial.println(F("QuadPreRecorder - Illicit Apothecary"));
  Serial.println(F("  r        start/stop recording"));
  Serial.println(F("  + / -    gain up / down 1 dB"));
  Serial.println(F("  [ / ]    output trim down / up 1 dB (BOTH jacks)"));
  Serial.println(F("  o        1 kHz reference tone for setting line level"));
  Serial.println(F("  h        toggle the headphone amplifier"));
  Serial.println(F("  m        toggle the DAC mute"));
  Serial.println(F("  s        status"));
  Serial.println(F("  c        ADC clock status"));
  Serial.println(F("  ?        this help"));
}

static void printStatus() {
  Meters::Reading mr;
  g_meters.read(&mr);

  Serial.println();
  Serial.printf("state        : %s\n",
                g_recorder.recording() ? "RECORDING" : "idle");
  Serial.printf("uptime       : %.1f s\n", (millis() - g_boot_ms) / 1000.0);
  Serial.printf("capture      : %lu Hz, %lu blocks, %lu overruns, ISR max %lu us\n",
                (unsigned long)cfg::kSampleRateHz,
                (unsigned long)g_capture.blocksCaptured(),
                (unsigned long)g_recorder.overrunCount(),
                (unsigned long)g_capture.maxIsrMicros());
  Serial.printf("clocks       : MCLK %lu Hz, BCLK %lu Hz, LRCLK %lu Hz\n",
                (unsigned long)SaiCapture::mclkHz(),
                (unsigned long)SaiCapture::bclkHz(),
                (unsigned long)SaiCapture::lrclkHz());
  Serial.printf("gain         : PGA %+.1f dB, pad %s, total %+.1f dB\n",
                (double)g_gain_db, g_controls.padEngaged() ? "IN" : "out",
                (double)totalGainDb());
  Serial.printf("output trim  : %+.1f dB, DSP %.1f%% CPU, %s HRTF, "
                "%lu dropped, %lu starved, %lu underruns\n",
                (double)g_dsp.outputTrimDb(), (double)g_dsp.cpuPercent(),
                g_dsp.usingMeasuredHrtf() ? "measured" : "modelled",
                (unsigned long)g_dsp.dropped(), (unsigned long)g_dsp.starved(),
                (unsigned long)g_monitor_out.underruns());
  if (g_monitor_out.dspOverBudget()) {
    Serial.printf("               ! DSP hit its CPU budget %lu times -- the "
                  "monitor is over-configured. Lower cfg::kHrtfTaps.\n",
                  (unsigned long)g_monitor_out.dspOverBudget());
  }
  Serial.printf("outputs      : one binaural render -> DAC -> splits after "
                "R62/R63\n");
  Serial.printf("               J4 line out (fixed) | RV1 knob -> TPA6132A2 "
                "-> J5 headphones\n");
  Serial.printf("               0 dBFS at J4 = %.2f Vrms = %+.1f dBu; limiter "
                "ceiling %.0f dBFS = %+.1f dBu\n",
                (double)MonitorDsp::dbfsToLineVrms(0.0f),
                (double)MonitorDsp::dbfsToLineDbu(0.0f),
                (double)cfg::kLimiterThresholdDbfs,
                (double)MonitorDsp::dbfsToLineDbu(cfg::kLimiterThresholdDbfs));
  Serial.printf("headphones   : amp %s, DAC %s%s\n",
                g_hp_enabled ? "ON" : "off",
                digitalReadFast(pins::DAC_MUTE) ? "unmuted" : "MUTED",
                g_dsp.referenceToneActive() ? ", REFERENCE TONE ON" : "");
  if (g_recorder.cardMounted()) {
    Serial.printf("card         : take %03lu next, %.1f GB free, %.0f min left\n",
                  (unsigned long)(g_recorder.lastTakeOnCard() + 1),
                  g_recorder.freeSpaceBytes() / 1e9,
                  (double)(g_recorder.remainingSeconds() / 60.0f));
    Serial.printf("buffers      : peak %.0f%%, longest write %lu us\n",
                  (double)(g_recorder.peakBufferUse() * 100.0f),
                  (unsigned long)g_recorder.maxWriteMicros());
    if (g_recorder.framesDropped()) {
      Serial.printf("               ! %.1f ms of audio lost to overruns -- "
                    "all four files share the same gaps\n",
                    (double)(1000.0 * g_recorder.framesDropped() /
                             cfg::kSampleRateHz));
    }
  } else {
    Serial.println(F("card         : not mounted"));
  }
  Serial.print(F("levels       :"));
  for (uint8_t c = 0; c < cfg::kChannels; c++) {
    Serial.printf("  %s %+6.1f/%+6.1f%s", cfg::kChannelNames[c],
                  (double)mr.peak_dbfs[c], (double)mr.rms_dbfs[c],
                  mr.clipped[c] ? " CLIP" : "");
  }
  Serial.println(F("   (peak/rms dBFS)"));
}

static void printClockStatus() {
  Pcm1864::ClockStatus cs{};
  if (g_adc.readClockStatus(&cs) != Pcm1864::Status::Ok) {
    Serial.println(F("PCM1864 did not answer on I2C"));
    return;
  }
  Serial.printf("PCM1864 state: %s\n", Pcm1864::stateName(cs.state));
  Serial.printf("  SCK ratio  : %s\n", Pcm1864::sckRatioName(cs.sck_ratio_code));
  Serial.printf("  BCK ratio  : %s\n", Pcm1864::bckRatioName(cs.bck_ratio_code));
  Serial.printf("  errors     : SCK %d BCK %d LRCK %d\n",
                cs.sck_error, cs.bck_error, cs.lrck_error);
  Serial.printf("  halts      : SCK %d BCK %d LRCK %d\n",
                cs.sck_halt, cs.bck_halt, cs.lrck_halt);
}

static void serviceSerial() {
  while (Serial.available()) {
    switch (Serial.read()) {
      case 'r':
        g_recorder.recording() ? stopRecording() : startRecording();
        break;
      case '+': case '=':
        applyGain(g_gain_db + 1.0f);
        setStatus("gain %+.1f dB", (double)g_gain_db);
        break;
      case '-': case '_':
        applyGain(g_gain_db - 1.0f);
        setStatus("gain %+.1f dB", (double)g_gain_db);
        break;
      case ']':
        g_dsp.setOutputTrimDb(g_dsp.outputTrimDb() + 1.0f);
        setStatus("output %+.0f dB (line + HP)", (double)g_dsp.outputTrimDb());
        break;
      case '[':
        g_dsp.setOutputTrimDb(g_dsp.outputTrimDb() - 1.0f);
        setStatus("output %+.0f dB (line + HP)", (double)g_dsp.outputTrimDb());
        break;
      case 'o': toggleReferenceTone(); break;
      case 'h': setHeadphones(!g_hp_enabled); break;
      case 'm': board::setDacMuted(digitalReadFast(pins::DAC_MUTE) != 0); break;
      case 's': printStatus(); break;
      case 'c': printClockStatus(); break;
      case '?': printHelp(); break;
      default: break;
    }
  }
}

// ---------------------------------------------------------------------------
// Boot
// ---------------------------------------------------------------------------
void setup() {
  g_boot_ms = millis();
  ARM_DEMCR |= ARM_DEMCR_TRCENA;      // cycle counter, used for CPU timing
  ARM_DWT_CTRL |= ARM_DWT_CTRL_CYCCNTENA;

  board::configureControlPins();      // HP amp off, DAC muted, LED off
  Serial.begin(115200);

  Wire.begin();
  Wire.setClock(400000);

  g_display.begin();
  g_display.splash("booting", "");

  // --- ADC ----------------------------------------------------------------
  Pcm1864::Status st = g_adc.begin(
#if QPR_CAPTURE_MODE == QPR_MODE_DUAL_I2S_192K
      Pcm1864::Format::DualI2S
#else
      Pcm1864::Format::Tdm4Ch
#endif
  );
  if (st != Pcm1864::Status::Ok) {
    char msg[180];
    snprintf(msg, sizeof(msg),
             "The PCM1864 ADC did not configure: %s. Run the t02_i2c bring-up "
             "test. Check the 3V3 rails, R44/R45 pull-ups, and that U7 pins 25 "
             "and 26 are grounded.", Pcm1864::statusName(st));
    Serial.println(msg);
    g_display.fatal("ADC NOT FOUND", msg);
    // Keep running: the console still works, and the display shows why.
  }

  // --- DSP and coefficient tables -----------------------------------------
  g_dsp.begin();
  g_meters.reset();
  g_controls.begin();

  // --- SD card -------------------------------------------------------------
  if (g_recorder.begin()) {
    char reason[80];
    g_dsp.loadHrtfFromSd(g_recorder.volume(), reason, sizeof(reason));
    Serial.println(reason);
  } else {
    Serial.println(F("no SD card: recording is unavailable, monitoring still works"));
  }

  // --- touch ---------------------------------------------------------------
  if (!g_touch.begin(cfg::kTftRotation)) {
    Serial.println(F("touch controller did not answer; front-panel controls "
                     "still work"));
  }

  // --- audio clocks --------------------------------------------------------
  // Start capture first so the ADC sees its clocks, then check that it locked
  // before allowing any sound out of the DAC.
  g_capture.begin(onCaptureBlock);
  delay(20);

  if (st == Pcm1864::Status::Ok) {
    st = g_adc.waitUntilRunning(300);
    if (st != Pcm1864::Status::Ok) {
      Pcm1864::ClockStatus cs{};
      g_adc.readClockStatus(&cs);
      char msg[200];
      snprintf(msg, sizeof(msg),
               "The ADC has clocks but will not run: %s. It reports state '%s', "
               "SCK %s, BCK %s. Check R46/R48/R47 and the SCKI trace.",
               Pcm1864::statusName(st), Pcm1864::stateName(cs.state),
               Pcm1864::sckRatioName(cs.sck_ratio_code),
               Pcm1864::bckRatioName(cs.bck_ratio_code));
      Serial.println(msg);
      g_display.fatal("ADC CLOCK ERROR", msg);
    } else {
      g_stream_ok = true;
    }
  }

  applyGain(cfg::kPgaDefaultDb);
  g_monitor_out.begin(onMonitorBlock);

  // Only now is it safe to let audio out. The PCM5102A powers up muted through
  // R60's pull-down; this is the first time anything raises DAC_MUTE.
  delay(50);
  if (g_stream_ok) {
    board::setDacMuted(false);
  } else {
    Serial.println(F("DAC left muted because the capture stream is not healthy"));
  }

  Serial.printf("\nQuadPreRecorder ready - Illicit Apothecary\n");
  Serial.printf("capture %lu Hz / 24-bit / 4 ch, monitor %lu Hz\n",
                (unsigned long)cfg::kSampleRateHz,
                (unsigned long)cfg::kMonitorRateHz);
  printHelp();

  g_display.forceRedraw();
  if (g_stream_ok) setStatus("ready");
}

// ---------------------------------------------------------------------------
// Main loop. The SD writer gets the most attention; everything else is rate
// limited so it cannot starve it.
// ---------------------------------------------------------------------------
void loop() {
  // 1. SD writing, as often as possible.
  g_recorder.service();

  const uint32_t now = millis();

  // 2. Controls.
  static uint32_t last_ctrl_ms = 0;
  if (now != last_ctrl_ms) {
    last_ctrl_ms = now;
    g_controls.poll();

    if (g_controls.takeRecordPress()) {
      g_recorder.recording() ? stopRecording() : startRecording();
    }
    if (g_controls.takeRecordLongPress() && !g_recorder.recording()) {
      g_meters.reset();
      setStatus("meters cleared");
    }
    const int32_t detents = g_controls.takeEncoderDelta();
    if (detents != 0) {
      applyGain(g_gain_db + detents * cfg::kGainDbPerDetent);
      setStatus("gain %+.1f dB (total %+.1f dB)",
                (double)g_gain_db, (double)totalGainDb());
    }
    if (g_controls.takeEncoderPress()) {
      setHeadphones(!g_hp_enabled);
      setStatus("headphones %s", g_hp_enabled ? "on" : "off");
    }
    if (g_controls.padChanged()) {
      setStatus("pad %s (total %+.1f dB)",
                g_controls.padEngaged() ? "IN" : "out", (double)totalGainDb());
    }
  }

  // 3. Touch, only when the controller says something is happening.
  static uint32_t last_touch_ms = 0;
  static bool touch_was_down = false;
  if (now - last_touch_ms >= 30) {
    last_touch_ms = now;
    if (g_touch.present() && g_touch.interruptAsserted()) {
      const TouchFt6336::Point p = g_touch.read();
      if (p.pressed && !touch_was_down) {
        touch_was_down = true;
        switch (g_display.hitTest(p.x, p.y)) {
          case UiHit::RecordStop:
            g_recorder.recording() ? stopRecording() : startRecording();
            break;
          case UiHit::HeadphoneToggle:
            setHeadphones(!g_hp_enabled);
            break;
          case UiHit::MonitorUp:
            g_dsp.setOutputTrimDb(g_dsp.outputTrimDb() + 1.0f);
            setStatus("output %+.0f dB (line + HP)",
                      (double)g_dsp.outputTrimDb());
            break;
          case UiHit::MonitorDown:
            g_dsp.setOutputTrimDb(g_dsp.outputTrimDb() - 1.0f);
            setStatus("output %+.0f dB (line + HP)",
                      (double)g_dsp.outputTrimDb());
            break;
          case UiHit::MeterReset:
            g_meters.reset();
            break;
          default: break;
        }
      }
    } else {
      touch_was_down = false;
    }
  }

  // 4. Display, at the configured rate.
  static uint32_t last_ui_ms = 0;
  if (now - last_ui_ms >= 1000 / cfg::kMeterUpdateHz) {
    last_ui_ms = now;
    UiState s;
    s.recording   = g_recorder.recording();
    s.card_ok     = g_recorder.cardMounted();
    s.take        = g_recorder.recording() ? g_recorder.takeNumber()
                                           : g_recorder.lastTakeOnCard();
    s.elapsed_s   = g_recorder.elapsedSeconds();
    s.remaining_s = g_recorder.remainingSeconds();
    s.buffer_use  = g_recorder.peakBufferUse();
    s.overruns    = g_recorder.overrunCount();
    s.lost_ms     = (uint32_t)(1000ull * g_recorder.framesDropped() /
                               cfg::kSampleRateHz);
    s.gain_db     = g_gain_db;
    s.pad_engaged = g_controls.padEngaged();
    s.hp_enabled  = g_hp_enabled;
    s.output_trim_db = g_dsp.outputTrimDb();
    s.ref_tone = g_dsp.referenceToneActive();
    s.dsp_cpu_pct = g_dsp.cpuPercent();
    s.measured_hrtf = g_dsp.usingMeasuredHrtf();
    s.status_line = g_status;
    g_meters.read(&s.meters);
    g_display.update(s);
  }

  // 5. Console.
  serviceSerial();

  // 6. Watch for the one failure that silently ruins a take.
  static uint32_t last_overrun_seen = 0;
  if (g_recorder.overrunCount() != last_overrun_seen) {
    last_overrun_seen = g_recorder.overrunCount();
    setStatus("BUFFER OVERRUN x%lu - card too slow",
              (unsigned long)last_overrun_seen);
  }
  if (last_overrun_seen && g_recorder.recording()) {
    board::setRecordLed((now / 100) & 1);   // fast blink = trouble
  }
}

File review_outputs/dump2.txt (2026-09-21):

===== all items x 81..87 y 46.5..50.5 =====
--- pads ---
  U7       21                 (86.362,50.500) 1.48x0.30 F.Cu
  U7       22  ADC_DOUT2_IC   (86.362,50.000) 1.48x0.30 F.Cu
  U7       23  I2C_SDA        (86.362,49.500) 1.48x0.30 F.Cu
  U7       24  I2C_SCL        (86.362,49.000) 1.48x0.30 F.Cu
  U7       25  GND            (86.362,48.500) 1.48x0.30 F.Cu
  U7       26  GND            (86.362,48.000) 1.48x0.30 F.Cu
  U7       27                 (86.362,47.500) 1.48x0.30 F.Cu
  U7       28                 (86.362,47.000) 1.48x0.30 F.Cu
  U7       29                 (86.362,46.500) 1.48x0.30 F.Cu
  C41      1   +3V3_A         (82.025,49.300) 0.90x0.95 B.Cu
  C41      2   GND            (83.575,49.300) 0.90x0.95 B.Cu
  C62      1   ADC_LDO        (85.625,49.850) 1.15x1.80 B.Cu
  C40      1   ADC_VREF       (82.025,47.700) 0.90x0.95 B.Cu
  C40      2   GND            (83.575,47.700) 0.90x0.95 B.Cu
  C42      1   +3V3_A         (85.625,47.400) 1.15x1.80 B.Cu
--- tracks ---
  F.Cu  GND            (86.362,48.000)-(84.617,48.635) w0.30
  F.Cu  GND            (86.362,48.500)-(87.520,48.500) w0.30
  VIA  GND            (84.617,48.635) d0.60
  VIA  GND            (84.270,47.700) d0.60
  VIA  GND            (84.259,49.421) d0.60
  B.Cu  GND            (83.575,47.700)-(84.270,47.700) w0.30
  B.Cu  GND            (83.575,49.300)-(84.259,49.421) w0.30
  F.Cu  I2C_SDA        (84.026,50.024)-(84.686,50.024) w0.20
  F.Cu  I2C_SDA        (86.362,49.500)-(88.380,49.500) w0.20
  F.Cu  I2C_SDA        (85.211,49.500)-(86.362,49.500) w0.20
  F.Cu  I2C_SDA        (84.686,50.024)-(85.211,49.500) w0.20
  F.Cu  I2C_SDA        (83.561,49.559)-(84.026,50.024) w0.20
  F.Cu  I2C_SDA        (83.561,44.539)-(83.561,49.559) w0.20
  F.Cu  I2C_SCL        (87.723,49.093)-(86.456,49.093) w0.20
  F.Cu  I2C_SCL        (86.456,49.093)-(86.362,49.000) w0.20
  F.Cu  FLU_ADC        (82.554,47.422)-(82.554,53.560) w0.20
  F.Cu  FLU_ADC        (80.638,47.000)-(82.132,47.000) w0.20
  F.Cu  FLU_ADC        (82.132,47.000)-(82.554,47.422) w0.20
  F.Cu  BRU_ADC        (83.046,52.083)-(83.046,47.417) w0.20
  F.Cu  BRU_ADC        (83.046,47.417)-(82.129,46.500) w0.20
  F.Cu  BRU_ADC        (82.129,46.500)-(80.638,46.500) w0.20
  B.Cu  BLD_ADC        (81.295,53.325)-(81.295,45.209) w0.20
  F.Cu  ADC_VREF       (80.638,48.500)-(81.600,48.500) w0.20
  F.Cu  ADC_VREF       (81.600,48.500)-(82.000,47.700) w0.20
  VIA  ADC_VREF       (82.000,47.700) d0.60
  B.Cu  ADC_VREF       (82.000,47.700)-(82.025,47.700) w0.20
  B.Cu  ADC_VREF       (82.050,45.900)-(82.050,47.675) w0.20
  B.Cu  ADC_VREF       (82.050,47.675)-(82.025,47.700) w0.20
  F.Cu  +3V3_A         (81.600,49.500)-(82.000,49.300) w0.20
  F.Cu  +3V3_A         (80.638,49.500)-(81.600,49.500) w0.20
  VIA  +3V3_A         (82.000,49.300) d0.60
  B.Cu  +3V3_A         (85.625,47.400)-(87.396,49.171) w0.20
  B.Cu  +3V3_A         (82.000,49.300)-(82.025,49.300) w0.20
  B.Cu  ADC_LDO        (82.825,50.100)-(82.025,50.900) w0.20
  B.Cu  ADC_LDO        (85.625,49.850)-(85.375,50.100) w0.20
  B.Cu  ADC_LDO        (85.375,50.100)-(82.825,50.100) w0.20
  F.Cu  ADC_DOUT2_IC   (86.362,50.000)-(88.377,50.000) w0.20
DONE

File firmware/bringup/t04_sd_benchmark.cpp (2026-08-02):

// t04_sd_benchmark.cpp — bring-up test 4: can this microSD card keep up?
//
// Vendor: Illicit Apothecary
//
// THIS IS THE MOST IMPORTANT TEST IN THE SET. Everything else either works or
// obviously does not. A marginal SD card fails silently, in the middle of a
// take, months later.
//
// WHAT IT PROVES
//   The card sustains four simultaneous 192 kHz / 24-bit streams -- 2.304 MB/s
//   of file payload -- for as long as you let it run, WITHOUT a single write
//   stall longer than the firmware's buffer can absorb.
//
//   Average speed is not the number that matters. A card that averages
//   20 MB/s but pauses for 300 ms while it does internal garbage collection
//   will drop samples on a recorder with 128 ms of buffering. This test
//   reports the WORST single write it ever saw, and compares it to the real
//   buffer depth the firmware is built with.
//
// WHAT TO DO
//   Put the card you actually intend to record on into the slot. Flash this.
//   Let it run for LONGER THAN YOUR LONGEST INTENDED RECORDING. Ten minutes
//   tells you very little; an hour tells you something real. Cards get slower
//   as they fill, so run it on a card that is at least half full if that is
//   how you will use it.
//
// WHAT IT WRITES
//   Four files named BENCH0.TMP .. BENCH3.TMP, written exactly the way the
//   recorder writes: preallocated, 24576-byte block-aligned chunks, round
//   robin. It deletes them when you stop it with the 'q' key.
//
// HOW TO READ THE RESULT
//   PASS      worst write comfortably inside the buffer window
//   MARGINAL  worst write above half the buffer window -- it will probably
//             work, but a long take is a gamble. Use a better card, or raise
//             kRingChunksPerChannel in qpr_config.h and rebuild.
//   FAIL      worst write exceeded the buffer window. This card WILL drop
//             samples. Do not record on it.

#include <Arduino.h>
#include <SdFat.h>
#include "qpr_board.h"
#include "qpr_config.h"

using namespace qpr;

static SdFs sd;
static FsFile files[cfg::kChannels];
static DMAMEM __attribute__((aligned(32))) uint8_t buf[cfg::kSdWriteChunkBytes];

// Real numbers from the firmware's configuration, not guesses.
static constexpr uint32_t kBytesPerSecPerChannel = cfg::kSampleRateHz * 3u;
static constexpr float kBufferWindowMs =
    1000.0f * (float)cfg::kRingBytesPerChannel / (float)kBytesPerSecPerChannel;

static uint64_t total_bytes = 0;
static uint32_t writes = 0;
static uint32_t worst_us = 0;
static uint32_t worst_at_ms = 0;
static uint32_t hist[8] = { 0 };   // <1, <2, <5, <10, <20, <50, <100, >=100 ms
static uint32_t start_ms = 0;
static bool running = false;

static void bucket(uint32_t us) {
  const uint32_t ms = us / 1000;
  if (ms < 1)        hist[0]++;
  else if (ms < 2)   hist[1]++;
  else if (ms < 5)   hist[2]++;
  else if (ms < 10)  hist[3]++;
  else if (ms < 20)  hist[4]++;
  else if (ms < 50)  hist[5]++;
  else if (ms < 100) hist[6]++;
  else               hist[7]++;
}

static void cleanup() {
  for (uint8_t c = 0; c < cfg::kChannels; c++) {
    if (files[c].isOpen()) { files[c].close(); }
    char name[16];
    snprintf(name, sizeof(name), "BENCH%u.TMP", c);
    sd.remove(name);
  }
  Serial.println(F("\nTemporary files removed."));
}

static void report() {
  const float secs = (millis() - start_ms) / 1000.0f;
  const float mbps = (float)total_bytes / 1e6f / secs;
  const float need = (float)kBytesPerSecPerChannel * cfg::kChannels / 1e6f;

  Serial.println();
  Serial.printf("elapsed        %.0f s   (%.1f min)\n", (double)secs,
                (double)(secs / 60.0f));
  Serial.printf("written        %.2f GB in %lu chunks\n",
                (double)(total_bytes / 1e9), (unsigned long)writes);
  Serial.printf("sustained      %.2f MB/s   (need %.2f MB/s)   %s\n",
                (double)mbps, (double)need,
                mbps >= need * 1.05f ? "ok" : "TOO SLOW ON AVERAGE");
  Serial.printf("worst write    %.1f ms at t=%.0f s\n",
                (double)(worst_us / 1000.0f), (double)(worst_at_ms / 1000.0f));
  Serial.printf("buffer window  %.0f ms  (%lu KiB per channel)\n",
                (double)kBufferWindowMs,
                (unsigned long)(cfg::kRingBytesPerChannel / 1024));

  const char* labels[8] = { "<1ms", "1-2ms", "2-5ms", "5-10ms",
                            "10-20ms", "20-50ms", "50-100ms", ">100ms" };
  Serial.print(F("distribution  "));
  for (uint8_t i = 0; i < 8; i++) {
    if (hist[i]) Serial.printf(" %s:%lu", labels[i], (unsigned long)hist[i]);
  }
  Serial.println();

  const float worst_ms = worst_us / 1000.0f;
  Serial.print(F("VERDICT        "));
  if (mbps < need * 1.05f || worst_ms >= kBufferWindowMs) {
    Serial.println(F("FAIL -- this card will drop samples. Use a different card."));
  } else if (worst_ms >= kBufferWindowMs * 0.5f) {
    Serial.println(F("MARGINAL -- it fits, but with little room. Consider a"));
    Serial.println(F("               better card, or raise kRingChunksPerChannel."));
  } else {
    Serial.println(F("PASS -- comfortable margin."));
  }
  Serial.println(F("Press 'q' to stop and delete the temporary files."));
  Serial.println();
}
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

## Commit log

2026-07-19 Add PCBWay-ready QuadPreRecorder Rev A hardware
    [QuadPreRecorder-BOM.csv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]
2026-08-01 Add Rev3 BOM and CPL regenerated from current schematic/board (RJ45 Cat6 J2, SW4, MSP3520)
    [QuadPreRecorder-Rev3-BOM.csv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]
2026-08-01 Rev3: convert to 4-layer, route all 18 nets, DRC/ERC clean
    Stackup F.Cu / In1.Cu (solid GND plane) / In2.Cu (signal + GND pour) / B.Cu.
    Placement, outline, 1590F fit and Cat6 jack J2 unchanged.
    - 0 unconnected, 0 DRC errors, 0 ERC violations, schematic parity clean
    - ADC_TDM 109mm/10 vias -> 29.2mm/0 vias; ADC_MCLK 110 -> 45mm; ADC_LDO 126 -> 23.8mm
    - 8 segments cut to free two stranded pin escapes (U7.11, U10.11), cut nets rerouted
    - 3 GND stitching vias tie U7 ground to the In1 plane
    - removed pre-existing fab hazard: 0.3mm via drilled inside J7.23's 1.0mm hole
    - adds tools/autoroute (clearance-aware N-layer router + exact validator)
    [QuadPreRecorder-Rev3-4L-BOM.csv, QuadPreRecorder-Rev3-BOM.csv, QuadPreRecorder_rev3_4layer.kicad_pcb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]
2026-08-02 Rev3 4-layer updates, firmware source, and hardware review artifacts
    [B3F-4050.step, EC11E15244G1.step, NRJ6HF.stp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]
2026-09-21 Rev B through Rev C3: 1590XX enclosure, CAT6 mic input, mic-mode rebuild, fab package, 3D enclosure models
    - Rev B 2-layer, then Rev C/C2/C3 on Hammond 1590XX: USB-C power/data, capacitive MSP3526, TPA6130A2 headphone amp, LiPo + BQ24074, SW4 5-way encoder
    - Mic-mode rebuild: per-channel bias off/5V/9V, cold-leg grounding, balanced inputs, SPICE CMRR fixes
    - Enclosure fit recheck applied (J4/J5/J9 moves, SW2 replacement, front-wall LEDs); ADC test points; ADP7142 LDO swap
    - PCBWay Rev C3 handoff package with 4-layer gerbers, BOM/CPL, best-source pricing
    - Interactive labeled 3D enclosure models (1590XX as-built with logo + 1590F concept), labeled-views PDF, blog embed notes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
    [BOM-current.csv, Hammond-1590XX.step, PCBWay_bom.csv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]
